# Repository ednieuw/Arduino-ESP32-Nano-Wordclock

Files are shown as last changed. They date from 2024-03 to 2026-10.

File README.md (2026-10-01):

# Arduino-ESP32-Nano-Word clock



Build your own word clock with WS2812 RGB or SK6812 RGBW LEDs, showing one or [four languages](https://github.com/ednieuw/FourLanguageClock), on an Arduino ESP32 Nano.<br>
The sketch also works on other ESP32 boards, with different pin numbering.<br>

[Compare other word clock software/hardware designs on the selector page.](https://github.com/ednieuw/WordclockSelector)<br>

The clock can be controlled with a:
- [BLE web page](https://github.com/ednieuw/HTML-BLEserial)
- [BLE terminal in a browser](https://arach.nl/BLESerial/BLE_UART_Terminal.html)
- [BLE serial terminal app](https://arach.nl/BLESerial/IOSappMain.html)
- Serial cable connected to your PC
- Rotary encoder
- IR-remote controller
- (Membrane) keypad
- MQTT, e.g. via Home Assistant
- [Time sender app (iOS) or web page (Windows/Android)](https://github.com/ednieuw/HTML-TimeSender) —> [open Time sender HTML](https://ednieuw.com/Woordklok/TimeSender/TimeSender.html)
<br>

## Architecture & related projects

Since V230, the word clock sketch has been combined with the [Fibonacci clock sketch](https://github.com/ednieuw/Fibonacci-Nano-ESP32-clock) to simplify maintenance. There is also a third option; NOCLOCK.

The three architectues are easy to split apart via `#define`'s in a few places, and the clock functions can be stripped out entirely with `#define NOCLOCK`. Functionality can be toggled on/off from the menu.

Coding for an [HC-12 timesender](https://github.com/ednieuw/ESP32-HC12) was also added — it sends NTP time over HC-12 to another MCU equiped with a HC-12 module to receive the transmission up to 1000 meters away. 

When no WiFi is available, time can instead be sent to the clock via a timesender iOS app or a timesender web page, using Bluetooth on your phone or tablet.

## Screens

<br>In several browsers the TAB can be split to see the menu and the Serial monitor response in one TAB. <br><br>

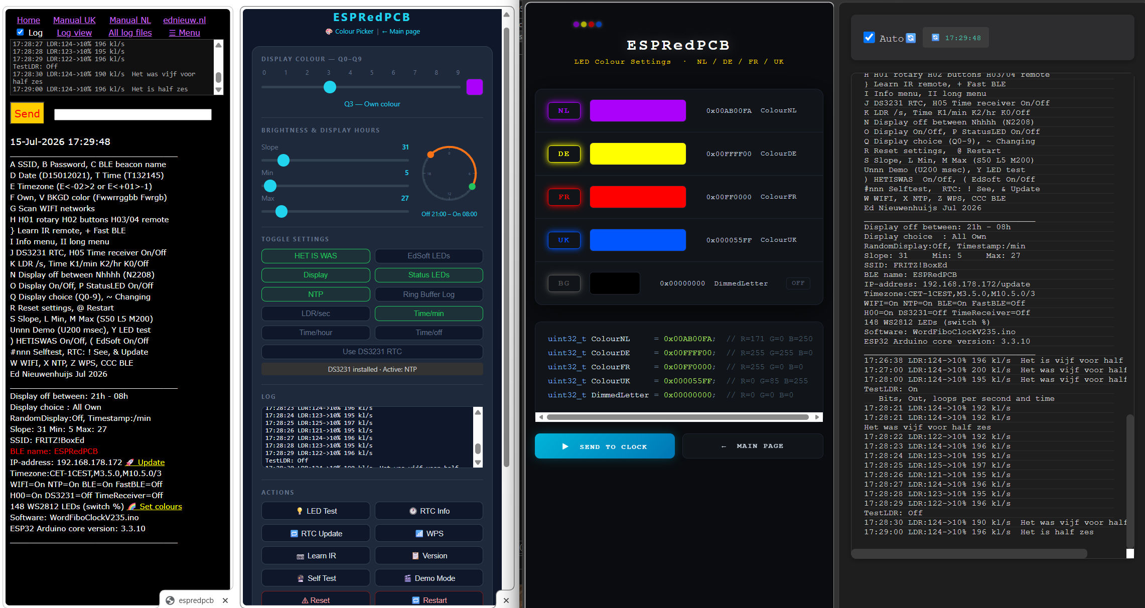
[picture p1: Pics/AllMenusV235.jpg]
<br>
All menus in a browser since version V235.

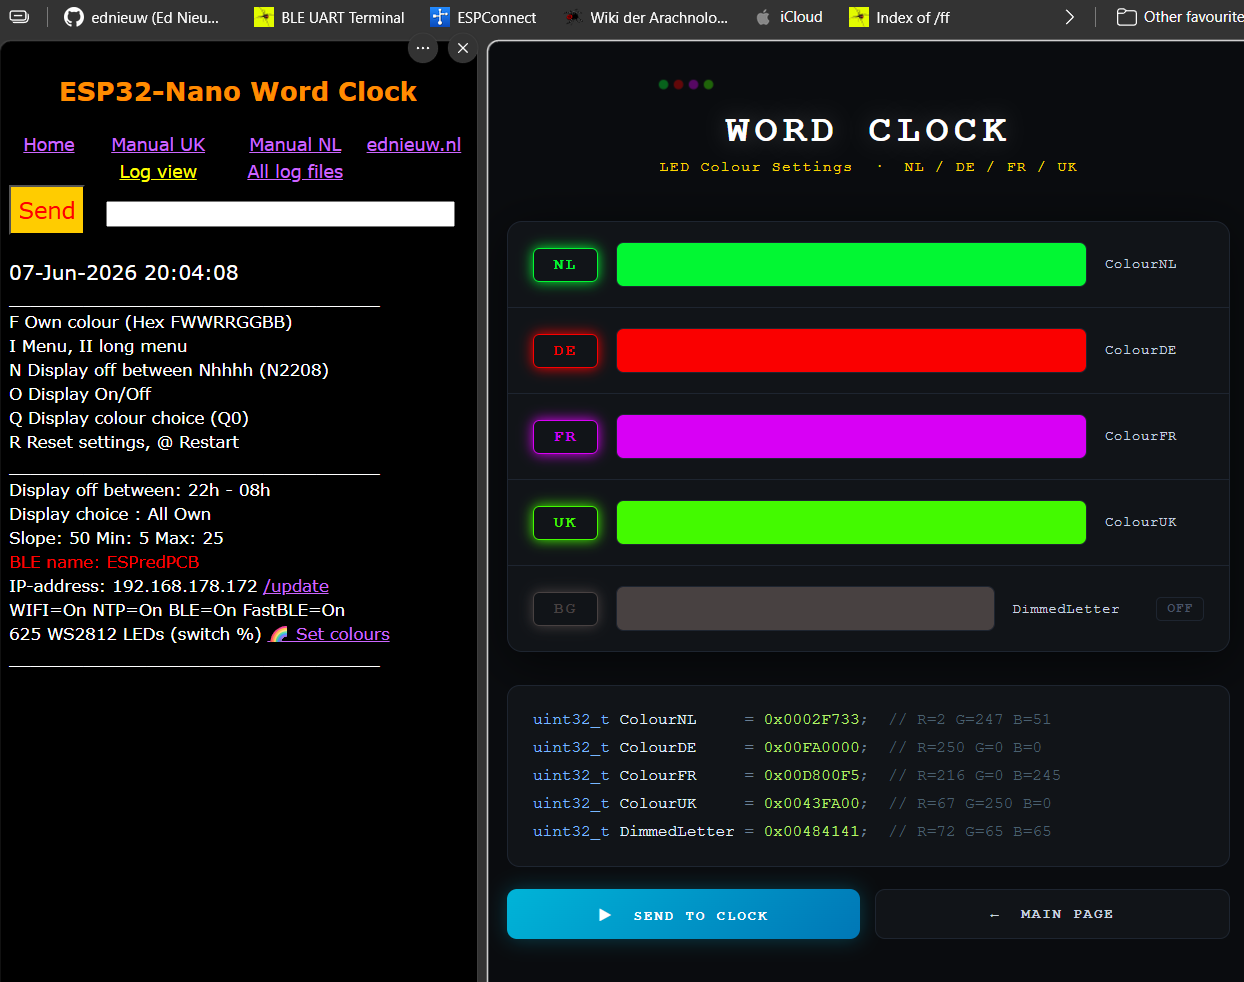
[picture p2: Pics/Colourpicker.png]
<br>

To connect the clock to WIFI the SSID and password of the router can be entered by the BLE serial terminal app or the WPS function can be used.<br>

Software updates can be uploaded with OTA (Over the Air).<br>

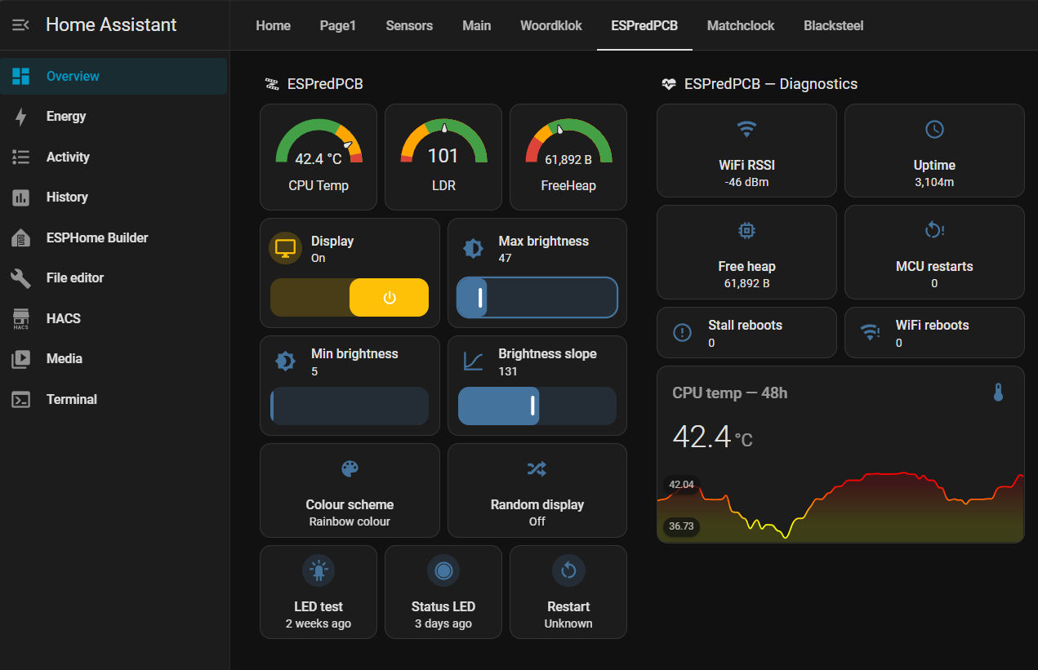
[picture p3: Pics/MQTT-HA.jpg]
<br>
With MQTT in Home Assistant.

| | |
|---|---|
| <br><strong>Full menu</strong> | The clock will keep its time correct within the second using the internet Network Time Protocol (NTP) with daylight-saving corrections when a timezone is entered.<br><br>If no internet is available a DS3231 RTC-module can be attached to the PCB to get an accurate time.<br>With a rotary, membrane pad, time sender app or almost any IR-remote controller time can be set.<br><br>An LDR (light-dependent resistor) is used to give the LEDs an optimal brightness.<br><br>The ESP32 has an Espressif BLE/WIFI module. Bluetooth LE does not use the TI CC2541 chip but a Nordic nRF52 chip.<br>That means you have to use a different BLE service for the serial communication — not characteristic FFE0 but 6e400001-b5a3-... etc. in your serial terminal app that communicates with the clock’s settings.<br><br>See here: <a href="https://github.com/ednieuw/nRF-ESP32">Use BLE on mobile to control the ESP32</a><br><br>An user manual in Dutch and English can be found in this repository: <a href="https://github.com/ednieuw/Arduino-ESP32-Nano-Wordclock/tree/main/Manual-Instructions">here</a> |<br><br><br><br>


Clock with Corten steel face

# Hardware
For my projects printed circuit boards (PCB) were designed with [Fritzing software](https://fritzing.org/).

This Fritzing program is easy to use and it can export Gerber files that can be send to companies that print PCB's. <br>
PCB's made in Europe can be ordered with the Fritzing app itself.<br>

[PCBWay](https://www.pcbway.com/) print 10 PCBs for $5. With +/-$25 shipping and custom charges this is very cheap. The PCBs were received within a week after ordering and the quality was excellent. Just upload the Gerber files in the ZIP-file and pay the charges.<br>  

The [PCB design .FZZ-file and Gerber files](PCB) can be found in the folder PCB in this repository or here:  [ESP32 PCB](https://github.com/ednieuw/NanoESP32PCB)

The PCB can connect a
- rotary encoder  
- three button membrane switch 
- DS3231 RTC module or other I2C device 
- DCF77-receiver module or other device that receives pulses and 
- LDR to measure light intensity to control the brightness of the LED-strip.
- IR-remote receiver
- reset button 

The SK6812 RGBW or WS2812 RGB LED-strip operates at 5V. But the data signal from the Nano ESP32 is 3.3V.<br> 

I tried to use optocouplers to amplify the data signal from 3.3V to 5V, but that failed. See here: 
https://ednieuw.com/ElecProj/OptoSK6812/OptocouplerSK6812.html<br>

For level switching the 74HCT125 level shifter IC is used. It has four ports. The design of the PCB can use the other three ports on the IC for other uses. <br>

A SK6812 RGBW strip, with 14 LEDs, also happily worked when the data line was connected directly to the 3.3V data line of the Nano ESP32 without using the 74HCT125 level shifter IC. I have not tested strips with more than 14 LEDs in the strip.<br>

The lesson of this story is that you can connect the SK6812 RGBW strip with a 470 ohm resistor in the data line and a 200 - 1000 uF capacitor over the 5V and GND directly to the strip without the use of a level shifter. <br>But success is not guaranteed.
 
Nano-ESP32-V04

An alternative universal PCB to drive RGB(W) LEDs and white 2835 LED strips using shift registers can be found here: [Nano  ESP32 RGBW BW PCB](https://github.com/ednieuw/NanoESP32-BW-RGBW-clock) <br>
This PCB, with one Arduino source code, will support the colour LED clocks and the white LED clocks to run with a Arduino Nano ESP32. 

V01SmallNanoESP32-3D
The design of a [minimum PCB for small spaces](/PCB-small) can also be found in the folder PCB-small in this repository.

Power for the LED-strip can be drawn from the VBUS-pin (5V USB) on the Nano if powered with a USB-C cable.  
VBUS provides 5V whenever powered via USB. 

It is possible to feed the LED-strip via this connection but keep in mind the power travels through the PCB and USB-C power supplies are able to supply over 20 A. This will probably melt the small copper lines on the PCB.

If powered via the VIN pin, VBUS is disabled. This means that while powering the board through the VIN pin, you can't get 5V power from the board. 

The PCB can use different power connection options.
A 5V, >1A power supply can be attached at the 5V power connection on the top left of the PCB.

If the red line shortcut (see picture below) is closed then the LED-strip is powered via the Power 6-21V (VIN) connection with 5V.<br> 
This will also power the Nano ESP32. You can connect the Vin on the ESP32 Nano with a 5V USB power supply although the minimum voltage is noted as 6V. The 1N5817 diode even lowers the voltage by 0.5V to 4.5V.

BUT KEEP IN MIND. This 5V connection is fed to the LED-strip directly. If a higher voltage power supply is connected the LEDs will be destroyed but Nano will turn on happily.<br>

If the Nano ESP32 is connected via the USB-C port then the yellow connection must be shortcut. The LEDs will be powered by this power source. This is fine with 20 LEDs but probably not for longer strips.

5VConnections

After connections are made the PCB and hardware looks like this:


NanoESP32-V04-3D



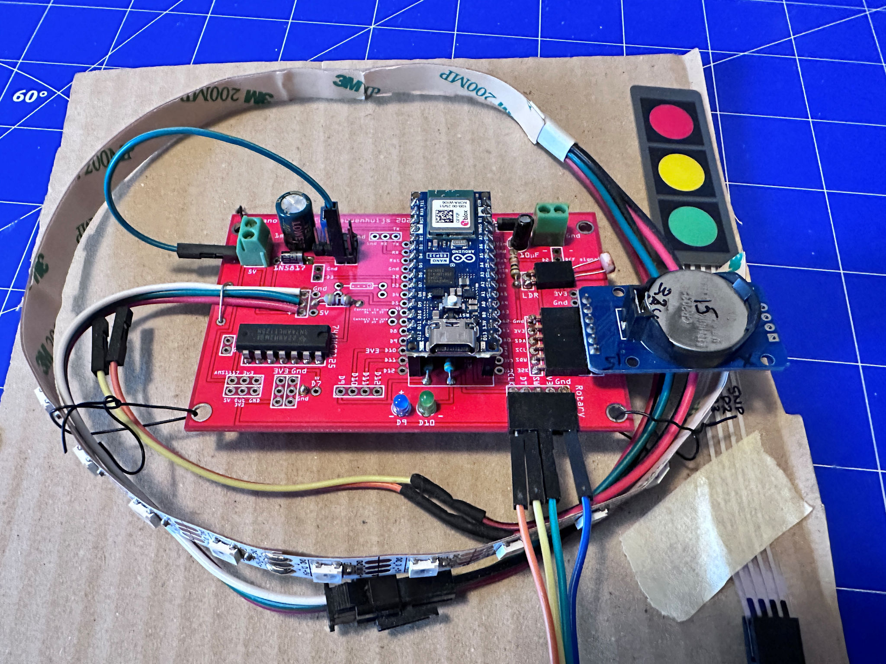
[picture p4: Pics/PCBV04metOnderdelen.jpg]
PCB V04
<br>
All parts on PCB V04 incliding Membrane keypad.

# PCB Connections

The large PCB has connections to: (from top right clock wise)
- 6-21V power input to Vin on Nano ESP32
- DCF to pin D2, 3V3 and GND
- LDR to pin A2 and 3V3
- RTC-clock to pin  GND, 3V3, A4 and A5
- Rotary encoder or 3-button switch to pin D8, D3, D4 3V3 and GND
- Reset button on D6 and GND (or D7)
- IR-remote D4 3V3 and GND
- LEDs to pin D10 and D9
- Connector to pin D12, D11, D10 and D9
- D7 with 5V via 3V3 -> 5V level switcher
- Connector with GND and 3V3
- Connector for AMS1117 5V -> 3V3 1A voltage regulator.
- D6 with 5V via 3V3 -> 5V level switcher
- Connector for LED-strip SK6812/WS2812 to 5V, D5 and GND
- D3 with 3V3 to D3 and GND
- 5V power input to 5V-USB or Vin on ESP32 and to LED-strip  
- 5V and GND connector and connector to Vin and 5V-USB on Arduino Nano ESP32
- Connector to GND, RX and TX 

The small PCB has connections to: (from top left clock wise)

- LDR to pin A2 and 3V3
- 5V power input to to 5V-USB on ESP32 and to LED-strip
- Connector for LED-strip SK6812/WS2812 to 5V, D5 and GND
- Rotary encoder or 3-button switch to pin D2, D3, D4 3V3 and GND
- Reset button on D6 and GND (or D7)
- IR-remote D4 3V3 and GND
- RTC-clock to pin  GND, 3V3, A4 and A5

 

# The LED ground plate



The distance between the LEDs on the strip is suitable for making a clock of 25 x 25 cm (60 LEDs/m) or 50 x 50 cm (30 LEDs/m).<br> 
You can choose to stick the 144 LEDs of the clock in 12 rows of 12 LEDs or only behind the letter that should light up.<br>
The advantage of the latter is that fewer LEDs are needed and that you have to drill fewer holes in the spacer plate.<br>
But there are many more soldering points, each of which can cause malfunctions.<br>  
My experience is that imperfect soldering on the strip may loosens over time, causing malfunctions. 

The software has a digital time display option you use 144 (12 x 12) LEDs.<br>

You can choose to cut out the words like IT, WAS, FIVE and so on in a 1 cm thick MDF board with a jigsaw.<br>
Be sure to paint the insides bright white, otherwise the white light will become dingy.<br> 
It is better to use foamed PVC white 10 MM RAL 9003. It cuts easily, is white and does not discolour. (Often white paint discolours)
 
Stick/glue the strips starting from left to right on the odd lines and from right to left on the even lines. <br>

### Follow the arrows on the strip.<br> 
(You have to turn the strip upside down every second row!)<br>
This avoids long data lines going from the right end of the strip to the left end on the next row of a LED strip.<br>
And the software does not have to be corrected for the new positions.



I find it useful to use tinned copper wire.<br> 
For example, you solder all 5V connections to the left side of the strip and all GND to the right side of the strip.
To do this, drill a small hole through the plate next to all 5V connections on the left side of the strip and to the GND on the right side

Bend a 90 degree angle, put the wire through the hole and solder the wire to the LED strip.





Place the spacer plate over the LEDs, then a sheet of white paper and finally the word plate.

# Software

The ESP32Arduino_WordClockVxxx.ino turns the Nano ESP32 and SK6812 or WS2812 LED strips into a Word clock with connection to a WIFI router and receives the time from a NTP server or a Timesender app.

An **user manual** in Dutch and English can be found in this repository [here](https://github.com/ednieuw/Arduino-ESP32-Nano-Wordclock/tree/main/Manual-Instructions)

The software can be controlled with Bluetooth on your PC, Android or iPhone/iPad/iMac using a BLE terminal app or with [this HTML BLE terminal web page](https://ednieuw.com/BLESerial/BLE_UART_Terminal.html).

Several designs can be selected before compiling.  (If you have a word clockface plate, of course.)<br>
Use a word clockface plate design [from this repository](WordPlateFrontCovers)  or use your own and adapt the position of the LEDs in the software.<br>

ClockDefines

Select one of the word clock designs
```
#define NL144CLOCK              // Dutch display for 12 x 12 Front
//#define FOURLANGUAGECLOCK       // Four-language clock with 625 LEDs 
//#define NL92CLOCK               // Dutch display for one LED behind every word
//#define UK144CLOCK              // English display for 12 x 12 Front.
//#define FR144CLOCK              // French display for 12 x 12 Front.
//#define DE144CLOCK              // German display for 12 x 12 Front.
...
```

- #define NL144CLOCK -> a 144 LED single language clock. Default language is Dutch. For French, German and English copy the coding from the four-language clock between the NL144CLOCK defines.<br>
 [Build instruction for the clock in Dutch and English](https://ednieuw.com/Woordklok/Bouwpakket/WoordklokSK6812.htm)
or [here in this repository](Manual-Instructions)

- #define NLM1M2M3M4L??? -> a ??? LED single language clock with 4 extra LEDs for the minutes and a slightly different design. Many lay-outs are defined.

- #define FOURLANGUAGECLOCK-> a 4-language clock with 625 LEDs in a 25 x 25 grid.<br>
[Build instruction of 4-language word clock with SK6812 LEDs in UK, NL, DE, FR with Nano Every.](https://github.com/ednieuw/FourLanguageClock). 

In the libraries.zip are the libraries to compile the software.<br>
Unpack them in your libraries folder.(libraries folder in the folder where your sketches are saved by default)<br>
Download the program folder and compile for Arduino Nano ESP32 using the Espressif core 3.<br>
Libraries update constantly, which may result in incompatibility with this source code over time. Therefore, these libraries are included.

An alternative is to compile the ArduinoOTA sketch that can be found in the Examples of the Arduino IDE.<br>
Upload the OTA-updater in the Nano ESP32 and note the IP-address that is printed in the Serial monitor of the Arduino IDE.
Type this IP-address URL in a browser and enter admin/admin as user and password.<br>
Then upload the .bin file made by the Arduino IDE with Sketch->Export compiled binary.<br>
<br>
Or use this one: [Uploads .bin files in the ESP32 by using wifimanager](https://github.com/ednieuw/OTA-webupdater).<br>
<br>
# How to compile: 
At the moment of writing (June 2026) the Espressif ESP32 board core V3.3.9 with the Arduino Nano ESP32 selected does compile to a working program when ESP32WordclockV220.ino of a higher version is used.
Select the Nano ESP32 board from Arduino in the Arduino IDE. 
The Arduino ESP32 board with core version 2.0.17/2.0.18, also compiles without errors when using the Adafuit Neopixel library.



There are two compiler pin numbering methods: One method uses the GPIO pin numbering of the ESP32-S3 and the other by Arduino pin numbering.<br>
This code works fine with GPIO pin numbering selected.<br>
The Neopixel library generates an error when this is not selected. 
The EdSoftLED library can use both pin numberings and only compiles with Espessif core 3.3.n because it used the RMT functionality to drive the LEDs.

Nano-ESP32 Pinout

Install Arduino Nano ESP32 board<br>
```
Board: Arduino Nano ESP32
Partition Scheme: With FAT
Pin Numbering: By GPIO number (legacy)  !! use this when using Neopixel 
```
<br>

SerialOutputs

# Before starting

The clock receives time from the internet when connected to a router.

When a DS3231 time module is attached to the circuit board an internet connection is not required. Select in the menu that the DS3231 is used instead of the NTP time. (J Toggle use DS3231 RTC module)
Be aware that DS3231 time is being used also when there is a internet connection. 

To connect to the internet the name of the WIFI station and its password must be entered in the clock software to be able to connect to a WIFI router or use the personal hotspot in you mobile.

### Connect to WIFI
The name of the WIFI-station and password has to be entered once. These credentials will be stored in memory of the microprocessor.

If the clock software is started without a SSID router name it will start a WIFI station you can connect to. 
- Open in your phone, tablet or PC the WIFI connections. In the list of WIFI stations there will be one named: StartWordClock. 
- Connect to it and enter the password: 12345678
- Enter the SSID and password of your WIFI router. You can find these credentials often at the bottom of your router.
- When Submit is pressed the clock will restart and connect to the internet.

### Connect via Bluetooth
To make life easy it is preferred to use a phone or tablet and a Bluetooth communication app to enter the WIFI credentials into the clock.<br>

With some browser you can also use [this web based BLE HTML from my site](https://ednieuw.com/BLESerial/BLE_UART_Terminal.html)

| | |
|:---:|:---:|
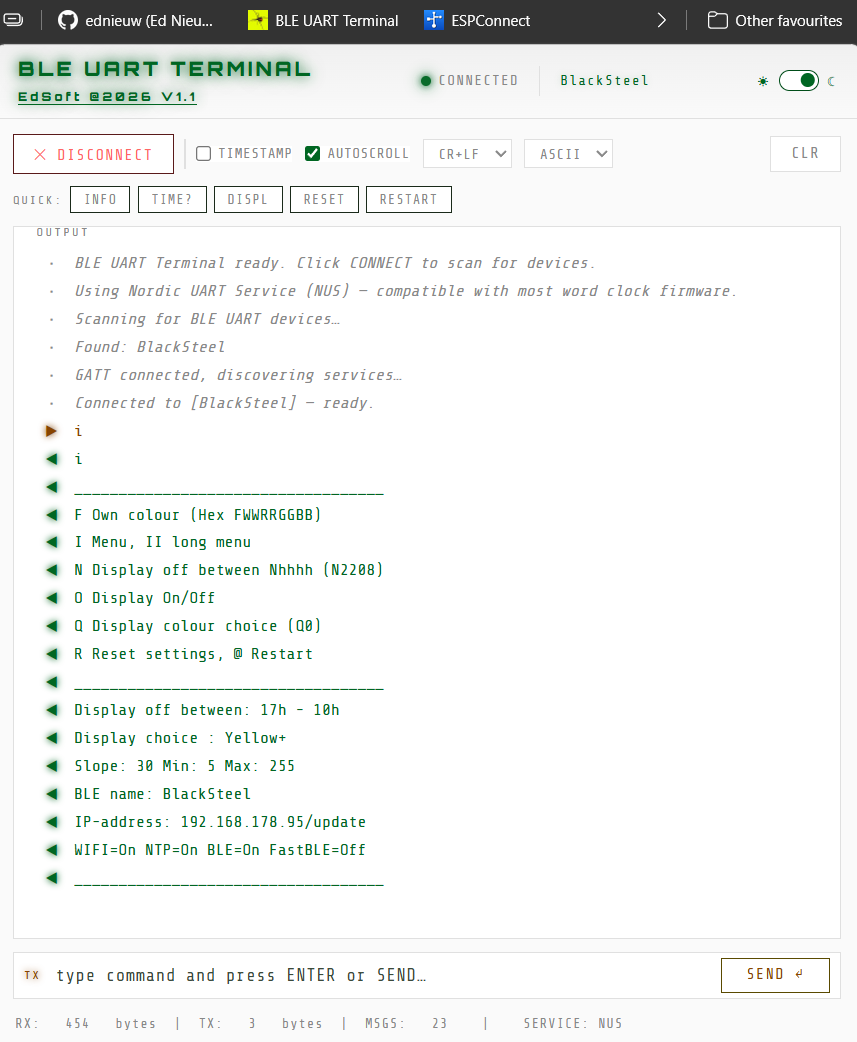
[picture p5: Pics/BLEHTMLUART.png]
BLE UART terminal
|  |  |
| [BLE UART HTML from my site](https://ednieuw.com/BLESerial/BLE_UART_Terminal.html) | Bluetooth UART serial terminal app | 

BLESerial nRF	BLE Serial Pro	Serial Bluetooth Terminal
- Download a Bluetooth UART serial terminal app on your phone, PC, or tablet.<br>

- For IOS iPhone or iPad (Buy this one to support me): [BLE Serial Pro](https://apps.apple.com/nl/app/ble-serial-pro/id1632245655?l=en). <br>
Or the free, less sophisticated app: [BLE serial nRF](https://apps.apple.com/nl/app/bleserial-nrf/id1632235163?l).<br>
Tip: Turn on Fast BLE with option + in the menu for a faster transmission.

- For Android use: [Serial Bluetooth terminal](https://play.google.com/store/apps/details?id=de.kai_morich.serial_bluetooth_terminal). <br>
Do not turn on Fast BLE in the menu. (Off = default)

Enter the SSID name and password of your router prefixed with A for the SSID and with an B for the password.
- aSSIDname and press Send
- bPassword and press send
Optionally
- cClockname and press send. 
Clockname is the name of the clock displayed in the WIFI-router in the list of bluetooth devices in the BLE serial terminal app

# Control of the clock
If the clock is connected to the internet it will seek contact with a time server. (NTP connection can be turned off in the menu).

The time zone is set to UTC+1 Amsterdam but can be changed in the menu. <br>
To connect to a WIFI network a SSID and password must be entered.

If equipped with a reset button, holding it for two seconds restores the clock to its factory settings. <br>
Bluetooth and WIFI will be turned on.
 
There are a few methods: <br>
1. Connect the MCU with a serial cable to a PC and use a serial terminal.

I use the Arduino IDE as serial terminal. 

Sending the character 'I' for information will display the menu followed with the actual settings of several preferences. 

<table style="width: 90%"><tr>
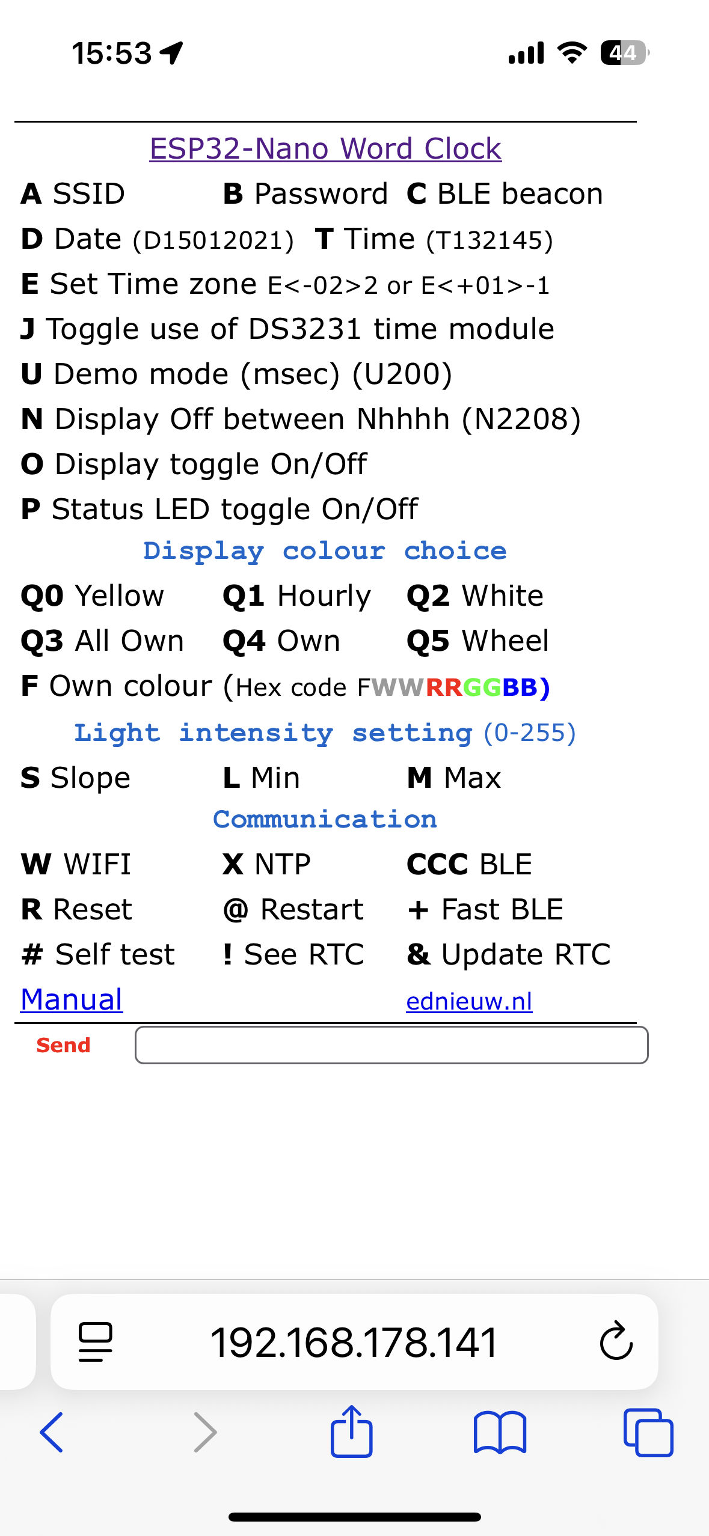
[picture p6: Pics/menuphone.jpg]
Menu on iPhone
<td style="width: 342px"></td>
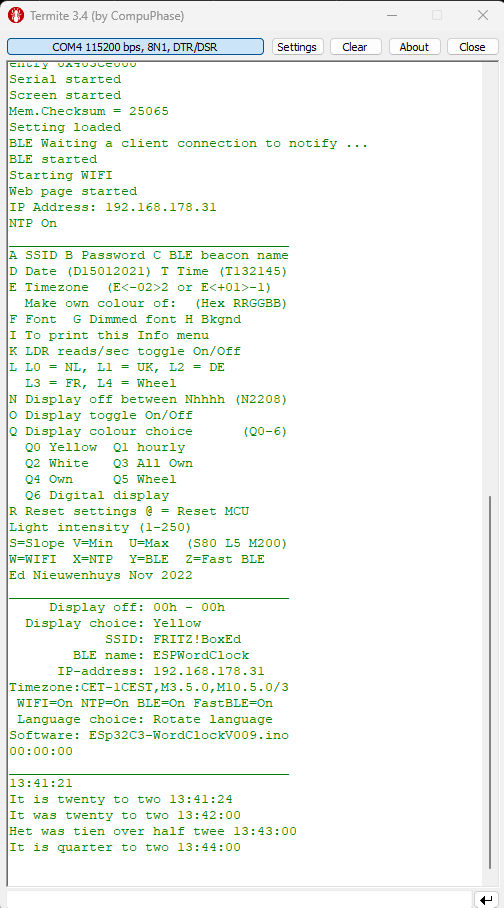
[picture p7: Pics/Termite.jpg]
Termite terminal
<td style="width: 415px"></td>
</tr>

<tr>
<td style="width: 342px">HTML page on iPhone.</td>
<td style="width: 415px">Termite terminal on a PC. </td>
</tr>
</table>
<br>

2. USE the BLE nRF connection with an UART serial terminal app to control it with your mobile phone or tablet. 

Use the IOS app for iPhone or iPad: <a href="https://apps.apple.com/nl/app/ble-serial-pro/id1632245655?l=en">BLE Serial Pro</a>. <br>
or the free app BLEserial nRF: https://apps.apple.com/nl/app/bleserial-nrf/id1632235163?l=en-GB
Turn on Fast BLE with option Z in the menu. 

For Android use:<a href="https://play.google.com/store/apps/details?id=de.kai_morich.serial_bluetooth_terminal">Serial Bluetooth terminal</a>. <br>
Turn off (default) Fast BLE in the menu. 

Start the app and find the MCU in the list of devices and connect to it. You can change it's beacon name in the menu with option C. 

In both cases send the character I of Information and the menu shows up.<br>
Enter the first character of the setting you want to change followed with a code. <br>
Some entries just toggle On and Off. Like the W to set WIFI Off or On. 
  
<p> To change the SSID and password: <br>
Amy-ssid and send this command. Eg AFRITZ!Box01 or aFRITZ!Box01. 
Starting with an upper or lower case character is an identical instruction in the command string <br>
Then Bmy-passwordand send the password.(for example: bSecret<br>
 
Cbroadcastname will change to name displayed in the Bluetooth connection list. <br>
If the length of the SSID and/or password is less then 5 characters the WIFI will be turned off automatically. This will speed up startup time if no internet connection is available <br>
Use a length of minimal 8 characters for the password and 3 characters for the SSID. <br>
Check in the menu (third row from the bottom) if WIFI and NTP are on. <br>
If WIFI is connected the LED on the MCU will pulse green. <br>
<br> Enter @ to reset the MCU. It will restart and connections will be made.<br>
<br>
To set a time zone, send the time zone string between the quotes prefixed with the character E or e. <br>
See the time zones at the bottom of this page. <br>
For example, if you live in Australia/Sydney send the string: eAEST-10AEDT,M10.1.0,M4.1.0/3 

<pre>
___________________________________
___________________________________
A SSID, B Password, C BLE beacon name
D Date (D15012021), T Time (T132145)
E Timezone (E<-02>2 or E<+01>-1)
F Own, V BKGD color (Fwwrrggbb Fwrgb)
G Scan WIFI networks
H H01 rotary H02 buttons H03/04 remote
} Learn IR remote, + Fast BLE
I Info menu, II long menu
J DS3231 RTC, H05 Time receiver On/Off
K LDR /s, Time K1/min K2/hr K0/Off
N Display off between Nhhhh (N2208)
O Display On/Off, P StatusLED On/Off
Q Display choice (Q0-9), ~ Changing
R Reset settings,  @ Restart
S Slope, L Min, M Max (S50 L5 M200)
Unnn Demo (U200 msec), Y LED test
) HETISWAS  On/Off, ( EdSoft On/Off
#nnn Selftest,  RTC: ! See, & Update
W WIFI, X NTP, Z WPS, CCC BLE
Ed Nieuwenhuijs Jun 2026
___________________________________
Display off between: 22h - 08h
Display choice  : All Own
RandomDisplay:Off, Timestamp: Off
Slope: 50     Min: 5     Max: 25 
SSID: FRITZ!BoxEd
BLE name: ESPredPCB
IP-address: 192.168.178.172/update
Timezone:CET-1CEST,M3.5.0,M10.5.0/3
WIFI=On NTP=On BLE=On FastBLE=On
H00=On DS3231=Off TimeReceiver=Off
625 WS2812 LEDs (switch %) 
Software: ESP32_WordClockV223.ino
ESP32 Arduino core version: 3.3.8
__________________________________
</pre>
#### Menu shown in serial output.

As mentioned before the clock can be controlled with the WIFI webpage or BLE UART terminal app. <br>
When the clock is connected to WIFI the IP-address is displayed in the menu<br>

Enter this IP-address numbers and dots (for example: 192.168.178.31) in the browser of your mobile or PC where you type 
your internet addresses (URL). 

If the name of your BLE beacon is wordclock (see in the wordclock menu -> BLE name: wordclock)

Enter 'wordclock.local' as URL in the browser. 
 if this does not work install host software:
  - For Linux, install Avahi (http://avahi.org/).
  - For Windows, install Bonjour (http://www.apple.com/support/bonjour/).
  - For Mac OSX and iOS support is built in through Bonjour already.

  - Point your browser to http://wordclock.local, you should see a response.

The menu, left in the picture below will appear. With these menus almost all functionality of the clock can be set, changed, and many more.

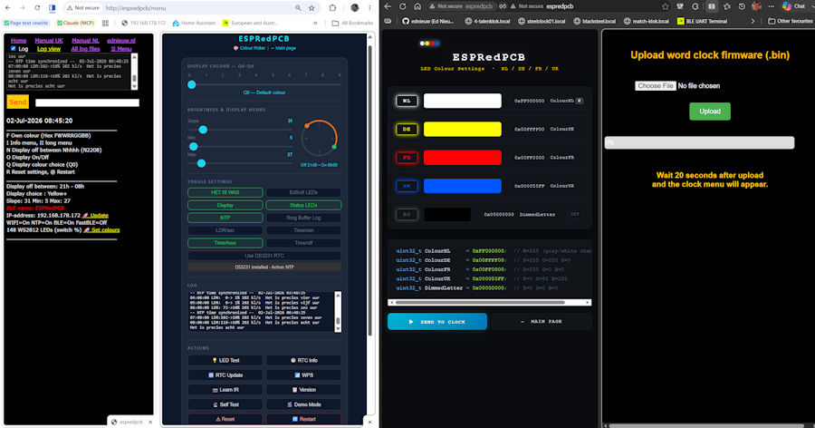
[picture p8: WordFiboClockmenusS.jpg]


Or open the BLE terminal app. (in some apps you have to press a CONNECT-button).<br>
Look for the WordClock to connect to and connect.

For Apple IOS devices BLE connection can be made with my app <a href="https://ednieuw.com/BLESerial/BLESerialPRO.html"> BLE Serial pro </a> in the <a href="https://apps.apple.com/nl/app/ble-serial-pro/id1632245655?l=en">app store</a> .<br>

For Android <a href="https://play.google.com/store/apps/details?id=com.nordicsemi.nrfUARTv2&amp;hl=en&amp;gl=US"> 
nRF UART terminal program </a>and <a href="https://play.google.com/store/apps/details?id=de.kai_morich.serial_bluetooth_terminal">
Serial Bluetooth terminal</a>. <br>
<br>
If you see a garbled menu and have FASTBLE turned on then send the character '+' to toggle the FASTBLE off the slower transmission mode. 
 
Settings are set by entering the first character of a command following by parameters if necessary.<br>
For example to set the colours of the characters in the display to white enter: Q2 <br>
<br>
 Set time by entering T130245. (130245 will also work) <br>
<br>
 Turn off WIFI by sending a W. 
<p >Reset the MCU with the character @.<br>
Reset to default setting by send R.<br><br>
 In the BLE connection the SSID and password will be shown.  <br>
	
<table cellspacing="6" style="width: auto">
<tr>
<td style="width: 280px">
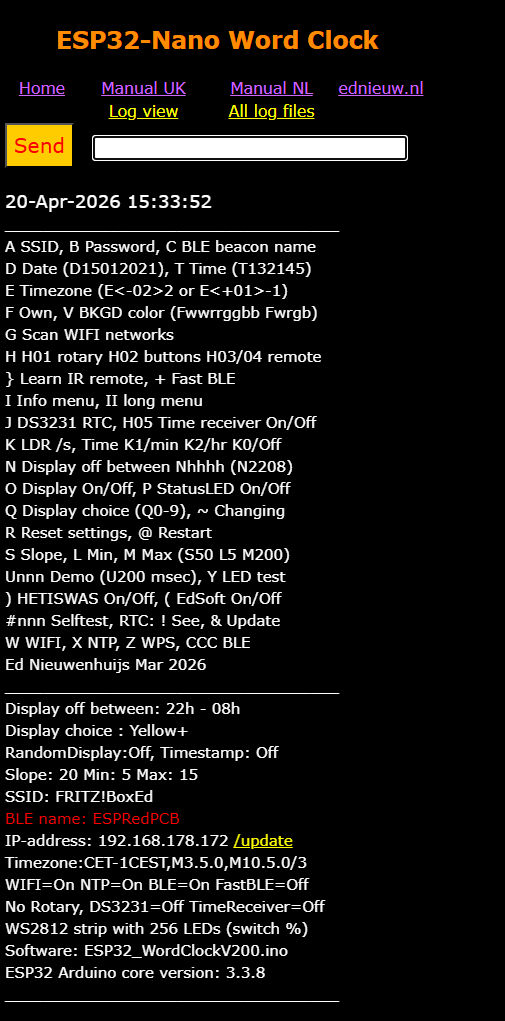
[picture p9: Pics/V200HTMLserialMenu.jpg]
Phone
</td>
<td>
WIFI-BLE</td>
</tr>
<tr>
<td style="width: 280px" >HTML page</td>
<td >BLEserial iPhone menu</td>
</tr>
</table>

## Detailed description

With the menu many preferences can be set. <br>
These preferences are permanently stored in the Arduino Nano ESP32 storage space. 

Enter the first character in the menu of the item to be changed followed with the parameter. <br>
For most entries upper and lower case are identical. 
With the HTML menu pages many of these entries can be selected with button, sliders or colour palettes.

### Update software<br>
Software can be updated with a .bin file. A bin files is made in the Arduino IDE from the menu Sketch -> Export compiled binary. In the folder where the sketch was saved several files are placed in the folder "build". The WordFiboBlockVxxx.ino.bin of approx. 1.5 Mb is the file to upload.  

### A SSID B Password C BLE beacon name<br>
Change the name of the SSID of the router to be connected to.<br>
aFRITZ!Box or AFRITZ!Box<br>
Then enter the password. For example: BSecret_pass <br>
and cMywordclock as a name of the BLE beacon that will be shown in your phone. (default after a reset:  wordclock )
Restart the MCU by sending @.

### CCC<br>
Entering CCC or ccc will toggle BLE on or off. Be careful turning it off. When BLE is off the clock can only be controlled with WIFI or the USB serial port.

### D Set Date and T Set Time <br>
If not connected to WIFI time and a RTC DS3231 is attached date must be set by hand.<br>
For example enter: D06112022 to set the date to 6 November 2022.  <br>
Enter for example T132145 (or 132145 , or t132145) to set time to 45 seconds and 21 minutes past one o'clock.

### E Set Timezone E&lt;-02&gt;2 or E&lt;+01&gt;-1<br>
At the bottom of this page you can find the time zones used in 2022. <br>
For Central Europe the string is: CET-1CEST,M3.5.0,M10.5.0/3  <br>
It is a rather complicated string and it is therefore wise to copy it. <br>
Let's pick one if you happen to live here: Antarctica/Troll,"&lt;+00&gt;0&lt;+02&gt;-2,M3.5.0/1,M10.5.0/3" <br>
Copy the string between the " " 's and send it starting with an 'E' or 'e' in front. <br>
E&lt;+00&gt;0&lt;+02&gt;-2,M3.5.0/1,M10.5.0/3 

Entering RRR will reset the timezone to Amsterdam CET. 
You will loose your credentials too with this reset! and have to reenter your SSID and password.

### Own colour (FWWRRGGBB or Fwrgb) <br>
With option Q3 and Q4 from the menu you can set your own colours for the clock to display.

Or press in the HTML menu page de link "🌈 Set colours".<br> Here the colour of the display can be selected with a colour palalette. When selected the display choice; "Q3 uses you own defined colours" automatically selected. 

The format to be entered is hexadecimal, 0123456789ABCDEF or decimal, 0123456789. <br>
The decimal range is made for users that are not familiar with hexadecimal arithmetic.<br>
The hexadecimal command is 2 characters for white followed with two characters for Red followed with two characters for Green and ending with two digits for Blue.<br>
The hexadecimal range is 00-FF, or 0-256 decimal and the decimal range is limited to 0-9.
To colour the characters intense red enter FF0000 prefixed with the character F. <br>
To set intense blue enter: F000000FF or FFF.<br>
To set the dimmed character to dark gray enter for example: F00191919. <br>
You get gray if red, green and blue have the same intensity.
With SK6812 LEDs the extra white LED can be used besides the three RGB LEDs in the same housing.
For example: F8800FF00 is 50% white with 100% green.

### G Scan WIFI networks
Scan available Wi‑Fi networks (prints SSIDs found).
This option does not work from the menu web page.

### H H01 rotary encoder, H02 buttons H03/04 remote, H05 Time sender app.
Turning on will also Turn off NTP and on use of DS3231. Check DS3231 and NTP setting when turning off (H00)
The options are:
H01 Rotary encoder<br>
H02 Keypad<br>
H03 Large IR-remote with nummeric UP DOWN LEFT RIGHT ON/OFF and POWER<br>
H04 Tiny IR-remote with six buttons<br>
H05 Turn On/Off the BLE time receiver. <br>
When enabled, the device listens for time sent by a BLE time sender app running on a nearby phone or PC and uses that to set its clock. <br>
Compatible senders:
- HTML BLE time sender (Chrome/Edge): [HTML-BLEserial](https://github.com/ednieuw/HTML-BLEserial)
- iOS BLE time sender app: [BLEtimeSender](https://ednieuw.com/BLESerial/BLEtimeSender.html)
The H05 option can be used when the clock has no WIFI. 

### } Learn IR remote
Start learning the keys of a new infrared remote.
  
### I short menu, II long menu
Print the menu. 
`i` prints the short info menu.
`ii` prints the extended menu (long help).

### J DS3231 RTC module On/Off
When DS3231 is enabled, NTP may be turned off. Use option `X` to toggle NTP if needed.<>r>
The flashing orange status LED on the board will turn off when the DS3231 time is used.

### K LDR reads/sec toggle On/Off<br>
Prints the LDR-readings and the calculated intensity output.
K1 Turn On and Off the display of time every minute.
K2 Turn On and Off the display of time every hour.
In the long menu the K1 or K2 status is shown. 
If time is printed every minute or hour the log buffer fills up very fast.
If time is not printed more revelant info remains in the logging.

### N Display off between Nhhhh (N2208)<br>
With N2208 the display will be turned off between 22:00 and 08:00. 

### O Display toggle On/Off<br>
Toggles the display off and on.

### P Display toggle On/Off<br>
Toggle status LEDs on the board On/Off.

###  Q Display choice (Q0-9)<br>
Q0 will show the time with yellow words., HETISWAS changing. <br>
HET will change from green to red via yellow in an hour and IS/WAS with change from green to red in a minute.<br>
Q1 will show every hour another colour. <br>
Q2 shows all the texts white. <br>
Q3 uses you own defined colours. 
Q4 uses you own defined colours with HETISWAS changing. <br>
Q5 will follow rainbow colours every hour. <br>
Q6 is the digital clock if you have used 12x12 = 144 LEDs in the clock. <br>
Q7= Hourly colour, HETISWAS changing.
Q8= Rainbow colour changing in a minute.
Send an 'I' to display the latest's settings in the menu. 

### R Reset settings <br>
R will set all preferences to default settings. The SSID and password, timezone, the LED-strip type and rotary/IR usage will be kept.<br>
RRR will clear SSID, password, set Time zone to Amsterdam (CET-1) and turn WIFI, NTP and BLE on.<br>
RRRRR is a total reset. A combination of R and RRR.<br> 
A total reset can also be achieved with a reset button connected to D6 or D7. If no rotary encoder is used, the rotary encoder pins D2, D3, and D4 can also serve this purpose.

### Unnn Demo (U200 msec)
Enter U followed with the duration of a second in milli seconds. 
M200 (200 millisecond) will speed up the clock 5*60 times.  
Sending an U will turn off the demo mode or if not in demo mode start demo mode with 800 ms/min.

### V Backgroung colour (VWWRRGGBB or Vwrgb) <br>

With this option you can set the colour and intensity of the LEDs that are normally not turned on.
This option is usefull when there is light leakage between the characters or to highlight the characters turned off.<br>
When this option is used the minimal light intensity is set to 50 bits to avoid that the background light with get off during the evening.<br>
50 bits is 20% of the max intensity. When you enter a background of say hexadecimal 10 (=16 decimal) the 20% of 16  = 3 bits and that is almost off.<br>
<br>
The format to be entered is hexadecimal, 0123456789ABCDEF or decimal, 0123456789. <br>
The decimal range is made for users that are not familiar with hexadecimal arithmetic.
The hexadecimal command is 2 characters for white followed with two characters for Red followed with two characters for Green and ending with two digits for Blue.<br>
The hexadecimal range is 00-FF, that is a decimal range of 0-255 and the decimal range is limited to 0-9.
To colour the characters weak red enter V00110000 or decimal V0100. <br>
To set weak blue enter: V00000011 or V0001 decimal.<br>
With the command V the background light is turned off and minimal light intensity to 10

### Y Play lights
To test the functionality of the LEDs.

### S Slope, L Min, M Max (S50 L5 M200)

<table style="width: 100%">
<tr>
<td> To control the light intensity three parameters can be set. <br>
The values ranges between 0 and 255. <br>
The minimal light intensity is to avoid that the display turns completely off when it is dark. <br>
It also prevents flickering when the input value is very low, like 2 and 3 bits. <br>
Values ranging between 5 and 20 are suggested. When no LDR is attached, the Min value can be set to 255.<br>
The maximum light intensity is 255 bits for 100% intensity.  <br>
The Slope (sensitivity) controls the speed at with the maximum value is reached. <br>
It multiplies the reading as a percentage. So, entering 100 is a multiplication by one. <br>
The placement and sensitivity of your LDR can be adjusted with this parameter Slope. </td>
<td> 
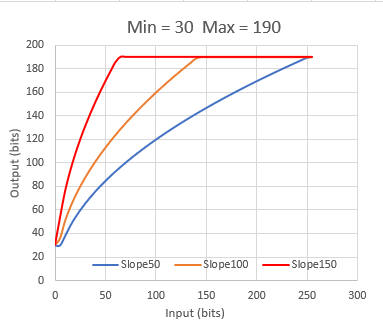
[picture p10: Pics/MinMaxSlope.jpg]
Min Max Slope
<br>
The effect of the value of the slope on the light intensity of the LEDs 
or display. </td>
</tr>
</table>

<table style="width: 100%">
<tr>
<td> 

<br>
### W=WIFI, X=NTP, Y=BLE<br>
Toggle WIFI, NTP and BLE on and off.<br>
Sending the character will toggle it on or off. <br>
At the bottom of the long menu (ii) the state is printed.<br>
 </td>
<td>
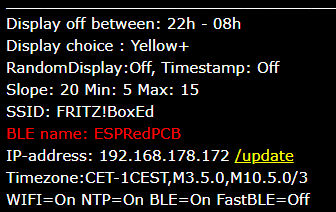
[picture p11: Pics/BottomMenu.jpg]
Bottom menu
</td>
</tr>
</table>

### + Fast BLE

The BLE UART protocol sends default packets of 20 bytes. Between every packet there is a delay of 50 msec.<br>
The IOS BLEserial app, and maybe others too, is able to receive packets of 80 bytes or more before characters are missed.<br>With most apps you will see these will truncate the long strings of the menu.<br>
Then turn off Fast BLE. <br>
Option Z toggles between the long and short packages. 

### ~ = change display mode per minute or hour
~ will start the changing display mode option. ~ or ~1 will change the dislay mode every minute and ~2 every hour. ~ or ~0 turns the option off. 
It is convenient for testing and demonstrations.

### ! = Show NTP, RTC and DS3231 time
!  will display the NTP, RTC and DS3231 time as they are stored in the clock  in the clock. The DS3231 time module must be installed and in use to show a realistic time.
Same as & option but this option will not update from the internet NTP server but only shows the time.

### #= Self test
Sending a # will start the clock self test. This is convenient to check if all the words in the display are functioning.<br> 
The time of a minute is reduced to 0.9 seconds (900 milli seconds).<br>
#nnnn were nnnn is the delay between minutes in milliseconds.

### % = Switch between SK6812 and WS2812 LED strip
With this option the used LED strip can be changed. The clock is equipped with on of these to types of LED strips. 
A Reset of all settings by sending a R in the menu will not change this LED strip selection.

### $ = Fire display
Shows a fire on the display in some clocks with a 12 x12 LED-matrix design installed

### ( = Turns additional optional LEDs On/Off
The clock can optionally be equipped with an extra logo text. 

### ) = Turns HET/IS/WAS On/Off
IT/IS/ WAS is always off

### @ = Restart MCU
@ will restart the MCU. This is handy when the SSID, et cetera are changed and the program must be restarted. Settings will not be deleted.

### & = Get and stores NTP time in RTC and DS3231 time
&  will get the NTP time immediately from the internet and stores it in the RTC clocks. This option is convenient to force the clock to get the proper NTP time. 
In other cases the program will check the time running in the clock and on the NTP server so now and then and update the RTC clocks.
The DS3231 time module must be installed and being used to show a realistic time.

### = = Display a permanent memory values in Mem
=  will print the values stored in the permanent memory of the Arduino.

### 123456 Set time in RTC module
Enter the time as 152300 hhmmss. Same as T152300
Changing date and time only works when a DS3231 RTC module is attached.

# Compilation and uploading

The settings of the Arduino Nano ESP32 board is as follows.<br>
Remember to install the ESP32 boards as explained above.<br>

Board settings
<p>

<p># Program explanation
 The program uses the following standard libraries.   
<br>
<pre>
//------------------------------------------------------------------------------              //
// ESP32 Includes defines and initialisations
//-------------------------------------------
                      #if ESP_ARDUINO_VERSION >= ESP_ARDUINO_VERSION_VAL (5, 2, 0)            // Use EdSoftLED with ESP32 compiler.
#define USEEDSOFTLED  // Use EdsoftLED >= V1.7.0 for SK6812. Saves 200-500 bytes compared with NeoPixel. NeoPixel is OK
                      #endif
                      #ifdef USEEDSOFTLED
#include <EdSoftLED.h>         // https://github.com/ednieuw/EdSoftLED for LED strip WS2812 or SK6812 
                      #else
#include <Adafruit_NeoPixel.h> // https://github.com/adafruit/Adafruit_NeoPixel  *** USE GPIO NUMBERING and compile By GPIO number (legacy) 
                      #endif
#include <Preferences.h>
#include <NimBLEDevice.h>      // For BLE communication. !!!Use NimBLE version 2.x.x  https://github.com/h2zero/NimBLE-Arduino
#include <WiFi.h>              // Used for web page 
#include <esp_sntp.h>          // for NTP
#include <esp_wps.h>           // For WPS
#include <ESPAsyncWebServer.h> // Used for webpage  https://github.com/ESP32Async 
#include <Update.h>            // For Over-the-Air (OTA)
#include <ESPmDNS.h>           // To show BLEname in router
#include <DNSServer.h>         // For the web page to enter SSID and password of the WIFI router 
#include <Wire.h>              //  
#include <RTClib.h>            // Used for connected DS3231 RTC // Reference https://adafruit.github.io/RTClib/html/class_r_t_c___d_s3231.html
#include <Encoder.h>           // For rotary encoder
#include <Keypad.h>            // For 3x1 membrane keypad instead of rotary encoder by Mark Stanley & Alexander Brevig 
#include <IRremote.hpp>        // IR remote control

</pre>

Webpage.h is included in the program as a TAB in the IDE. It contains the web page to display in the browser.<br>

I made the web page in the free 'Microsoft Expression Web 4'. It is not maintained anymore but has more than enough functionalities for our purposes.<br>
Notepad++ or an AI are also good alternatives<br>
<br>
To copy the code from the MS-Expression: <br>
At the bottom line of the window of MS-Expression click 'Split'.<br>
In the upper half the raw HTML Code is displayed and in the bottom half the 
Design window.<br>
Copy in the Code window all the HTML code <br>
Go to the Arduino IDE and paste it in the webpage.h TAB between: <br>
R"rawliteral(   ... and ...
 )rawliteral";<br>
<br>
  Or copy the the code from the webpage.h into 
MSexpression Code area and redesign the page as you like 

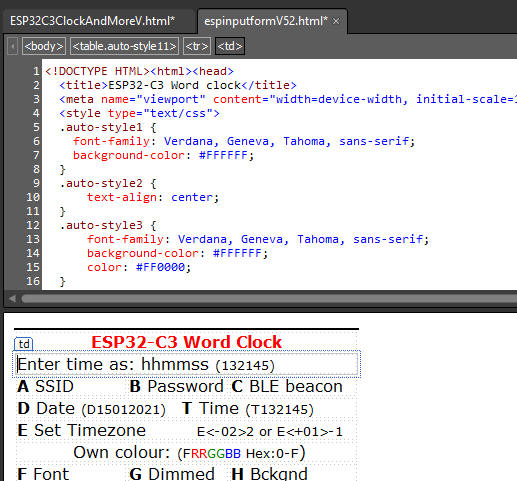
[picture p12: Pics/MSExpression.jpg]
MS expression
<br>

A long list if definitions and initialisations follows. <br>
I am not a fan of passing all the variables to and from functions and like to keep them global in one program list.<br>
If you write a program with other people, it is good practice not to use too many globals, but this program is in one large listing, for the same reason to keep it simple.<br>
I grouped all the variables per application to keep track where they are used.<br>
With a simple find it is easy in this one great listing to find the back.<br>
<br>
To print the time as text and colour with the proper LEDs or characters, the words and its position in a string of LEDs or text are defined. <br>
The defines executes the function ColorLeds with its proper parameters.<br>
Further in the program in the function void Dutch(void), void English(void) et cetera it becomes clear why these defines are so useful and handy.  
The definitions are placed in the TAB "ClockFaces.h"
<pre> ...   
#define PRECIES ColorLeds("precies", 16, 22, LetterColor);
#define MTIEN   ColorLeds("tien", 25, 28, LetterColor); 
#define KWART   ColorLeds("kwart", 32, 36, LetterColor); 
#define VOOR    ColorLeds("voor", 38, 41, LetterColor); 
... 
</pre>
This is the initialisation of the storage area to store the struct EEPROMstorage.<br>
The Struct with all its settings is saved in one command to permanent memory or SD <br>
Preferences FLASHSTOR; <br>
<br>
<pre> ...  
struct EEPROMstorage { // Data storage in EEPROM to maintain them after power loss 
byte DisplayChoice = 0; 
... <br>
char BLEbroadcastName[30]; // Name of the BLE beacon 
char Timezone[50];
int Checksum = 0;
} Mem;
... 
</pre>
<br>
The variables are addressed with a short name Mem.<br> 
For example Mem.DisplayChoice = 3; <br>
<br>
The Struct EEPROMstorage is stored with the function StoreStructInFlashMemory and retrieved with the function GetStructFromFlashMemory <br>
<br>

The menu displayed in the serial monitor and BLE app is defined here.<br>

```cpp
// Menu 
//0        1         2         3         4 
//1234567890123456789012345678901234567890  
const char *menu[] = { 
"A SSID B Password C BLE beacon name", 
"D Date (D15012021) T Time (T132145)", 
... 
"W=WIFI, X=NTP, Y=BLE, Z=Fast BLE",  
"Apr 2026" };
```
 The Setup happens here: 
```cpp
//-------------------------------------------- 
// ARDUINO Setup
//-------------------------------------------- 
void setup()  
{
Serial.begin(115200); Tekstprintln("Serial started"); // Setup the serial port to 115200 baud // 
...
... 
msTick = millis();  
}
```

The loop is kept almost empty and the program starts in Every SecondCheck.<br>
There is nothing in this program that should be executes every millisecond or less
 
```cpp
//-------------------------------------------- 
// ARDUINO Loop
//-------------------------------------------- 
void loop() 
{
 Loopcounter++;
 if (Demo)            Demomode();  
 else if(FireDisplay) FireMode(); 
 else                 EverySecondCheck();  
 CheckDevices();
}
```

The following routines check if something must happen every second, minute, hour and day.<br>
This flow handling of the program keeps the processor for 99% free for other uses.<br>
In this program that is almost nothing but for other purposes this can be needed.<br>
In the serial monitor the number of loops per second is printed. This can be handy to check if the program spends too much time elsewhere in the program. At the moment (V056) of writing it is around 200,000 l/s.
<br>

```cpp
//--------------------------------------------                //
// COMMON Check connected input devices
//--------------------------------------------
void CheckDevices(void)
{
 CheckBLE();
 SerialCheck();
 CheckWIFIcommand();
 if (Mem.TimeReceiver) CheckTimeReceiverClient();
 if (Mem.UseRotary==1) RotaryEncoderCheck();
 if (Mem.UseRotary==2) Keypad3x1Check();
 if (Mem.UseRotary==3 || Mem.UseRotary==4) IrReceiverDecode();
 if (ntpJustSynced) CheckandPrintNTPsynced();
                                  #ifdef ONEWIREKEYPAD3x4   
 OnewireKeypad3x4Check(); 
                                  #endif  //ONEWIREKEYPAD3x4
                                  #ifdef ONEWIREKEYPAD3x1   
 OnewireKeypad3x1Check(); 
                                  #endif  //ONEWIREKEYPAD3x1
}
//-------------------------------------------- 
// CLOCK Update routine done every second 
//-------------------------------------------- 
void EverySecondCheck(void) 
{
 static int Toggle = 0;
 uint32_t msLeap = millis() - msTick; 
 if (msLeap >999)                                              // Every second enter the loop
 {  
...  
if (timeinfo.tm_min != lastminute) EveryMinuteUpdate();        // Enter the every minute routine after one minute 
... 
}
//-------------------------------------------- 
// CLOCK Update routine done every minute 
//--------------------------------------------  
void EveryMinuteUpdate(void) 
{
... 
if(timeinfo.tm_hour != lasthour) EveryHourUpdate(); 
}
//-------------------------------------------- 
// CLOCK Update routine done every hour 
//-------------------------------------------- 
void EveryHourUpdate(void) 
{
... 
if (timeinfo.tm_mday != lastday) EveryDayUpdate();  
}

//-------------------------------------------- 
// CLOCK Update routine done every day 
//-------------------------------------------- 
void EveryDayUpdate(void) 
{
... 
}
```
<br>

```cpp
//--------------------------------------------                                                //
// COMMON Update routine for the status LEDs
//-------------------------------------------- 
void UpdateStatusLEDs(int Toggle)
{
 if(Mem.StatusLEDOn)   
   {
    SetStatusLED((Toggle && WiFi.localIP()[0]==0) * 20, 
                 (Toggle && WiFi.localIP()[0]!=0) * 20 , 
                 (Toggle &&      deviceConnected) * 20);
    SetPCBLED09( Toggle * 10);                                                                // Left LED
    SetPCBLED10((!Toggle) * 10);                                                             // Right LED
    SetNanoLED13((!Toggle) * (!Mem.UseDS3231 * 50));                                         // LED on ESP32 board. IF DS3231 in use then it is off
   }
   else
   {
    SetStatusLED(0, 0, 0); 
    SetPCBLED09(0);                                                                           //
    SetPCBLED10(0);                                                                           //
    SetNanoLED13(0);      
   }
}
```
Update the LEDs on the Nano ESP32 and the PCB. 
On the Nano analogWrite(LED_RED,   512); is OFF and analogWrite(LED_RED, 0); is ON<br>
When compiling with Espressif ESP32 core 3.x.x the resolution of the of the RMT channel is raised from 8 -> 10 bits. <br>
This prevents that the LED does not turn off completely when compiling with core 3. ( 8191 = 10^2)

```cpp
analogWrite(LED_RED,   Red   == 0 ? 8191 : (512 - Red)); 
```

```cpp
//--------------------------------------------
// COMMON Control the RGB LEDs on the Nano ESP32
//--------------------------------------------
void SetStatusLED(int Red, int Green, int Blue) 
{
 analogWrite(LED_RED,   Red   == 0 ? 8191 : (512 - Red));
 analogWrite(LED_GREEN, Green == 0 ? 8191 : (512 - Green));
 analogWrite(LED_BLUE,  Blue  == 0 ? 8191 : (512 - Blue));
}
```

```cpp
//--------------------------------------------
// COMMON Control orange LED D13 on the Arduino 
//--------------------------------------------
void SetNanoLED13(int intensity) {analogWrite(secondsPin, intensity);}
```

```cpp
//--------------------------------------------
// COMMON Control the RGB LED on the PCB
//--------------------------------------------
void SetPCBLED09(int intensity) {analogWrite(PCB_LED_D09, intensity);}
void SetPCBLED10(int intensity) {analogWrite(PCB_LED_D10, intensity);}

```
Control the color and intensity of the LED on the boards in one command <br>
```cpp
//
--------------------------------------------
// CLOCK Control the LEDs on the ESP32 
// 0 Low is LED off. Therefore the value is inversed with the ! Not 
//-------------------------------------------- 
void SetStatusLED(bool Red, bool Green, bool Blue) 
{
```

Check for serial input from the serial monitor and pass the command to ReworkInputString()&nbsp;  
```cpp
//-------------------------------------------- 
// Common check for serial input 
//-------------------------------------------- 
void SerialCheck(void) 
{
... 
ReworkInputString(SerialString); // Processes the inputstring in the menu 
... 
}
```

Restore all the default values. 
```cpp
//-------------------------------------
// Common Reset to default settings 
//--------------------------------------
void Reset(void)
{
 Mem.Checksum         = 25065;
 Mem.DisplayChoice    = DEFAULTCOLOUR; 
 Mem.OwnColour        = green; 
 Mem.DimmedLetter     = black;
 Mem.BackGround       = black; 
...
 StoreStructInFlashMemory();   
 GetTijd(false); 
 SWversion();
 Displaytime();Tekstprintln("");
}

 }
 ```

Common print routines.<br>

To keep all the print commands in one places it is easy to change these routines for other boards with a different 'slang'. <br>
```cpp
//-------------------------------------------- 
// Common common print routines 
//-------------------------------------------- 
void Tekstprint(char const *tekst)    { if(Serial) Serial.print(tekst); SendMessageTimeReceiver(tekst); SendMessageBLE(tekst); AddLog(tekst);}  
void Tekstprintln(char const *tekst)  { snprintf(sptext, sizeof(sptext),"%s\n",tekst); Tekstprint(sptext); }
void Tekstprintf(const char* fmt, ...) 
{ va_list args; va_start(args, fmt); vsnprintf(sptext, sizeof(sptext), fmt, args); va_end(args); Tekstprint(sptext);}

void Tekstprintlnf(const char* fmt, ...) 
{ va_list args; va_start(args, fmt); vsnprintf(sptext, sizeof(sptext), fmt, args); va_end(args);  Tekstprintln(sptext);}

```

The setup of storage space and control of the validity of the settings.<br>
In the checksum is invalid a reset() will restore the default settings 

```cpp
//-------------------------------------------- 
// Common Init and check contents of EEPROM 
//-------------------------------------------- 
void InitStorage(void) 
```

Store and retrieve the settings from SPIFFS or SD or EEPROM.
The several possibilities are stored here. EEPROM becomes outdated but still works. 

```cpp
-------------------------------------------- 
// COMMON Store mem.struct in FlashStorage or SD 
//-------------------------------------------- 
void StoreStructInFlashMemory(void) 
{
}
//-------------------------------------------- 
// COMMON Get data from FlashStorage Preferences.h 
//-------------------------------------------- 
void GetStructFromFlashMemory(void) 
{
}
```

SWversion() prints the menu and the settings of several preferences.<br>

PrintLine() prints the horizontal lines in the menu.<br>

```cpp
//-------------------------------------------- 
// COMMON Version info
//-------------------------------------------- 
void SWversion(void)  
{  
#define FILENAAM (strrchr(__FILE__, '\\') ? strrchr(__FILE__, '\\') + 1 : __FILE__) 
PrintLine(35); 
for (uint8_t i = 0; i &lt; sizeof(menu) / sizeof(menu[0]); Tekstprintln(menu[i++])); 
... 
PrintLine(35); 
}

void PrintLine(byte Lengte) 
{... } 
```

Get the commands from the strings entered in the serial monitor, Bluetooth or the webpage and perform the command in an action.<br>
The menu letters are almost used but it possible to distinguish between lower and uppercase when more commands are needed.<br>
(That is why there is no conversion to UpperCase or LowerCase). 

```cpp
/-------------------------------------------- 
//  COMMON Input from Bluetooth or Serial
//--------------------------------------------
void ReworkInputString(String InputString) 
{
....  
  int len = InputString.length();
  switch(toupper(InputString[0])) 
   {
    case 'A':
      if(len > 4 && len < 30)
.... 
```

Read the LDR and divide it with 16 to get the values from 0 - 4096 between 0 and 255.<br>
Not all boards has a 12 bit AD converter like.  

```cpp
//-------------------------------------------- 
// LDR reading are between 0 and 255.  
// ESP32 analogue read is between 0 - 4096 --   is: 4096 / 8 
//-------------------------------------------- 
int ReadLDR(void) {  return analogRead(PhotoCellPin)/16;} 
```

Here we print and colour the characters in the display or light up to proper LEDs in a String of RGB(W) LEDs.<br>
The #define executes this functions with the proper parameters for every language and prints the texts in the serial connections.<br>
#define QUARTER ColorLeds("quarter", 32, 38, LetterColor);

```cpp
//--------------------------------------------    / 
 / LED Set color for LED. 
//--------------------------------------------   
void ColorLeds(char const *Texkst, int FirstLed, int LastLed, uint32_t RGBColor)  
{  } 
```

Every display or strip uses other commands to regulate the brightness. Therefore for all LED/Display commands a function.
```cpp
//----------------------------------------------
// LED Set brightness of backlight 
//------------------------------------------------
void SetBrightnessLeds(byte Bright) 
{ 
 SetBackLight(Bright);                        // Set brightness of LEDs 
} 
```

A place to turn off all LEDs or clear the display<br>
```cpp
/-------------------------------------------- 
// LED Clear the character string 
//-------------------------------------------- 
void LedsOff(void)  
```

Here the colours are set for the characters.<br>
It is also used to change the colours of HET IS WAS used in some display choices

```cpp
//--------------------------------------------  <br>
// LED Set second color <br>
//-------------------------------------------- <br>
void SetSecondColour(void) <br>
{ 
...
 MINColor = FuncCRGBW(15 + timeinfo.tm_min * 4, 255 - timeinfo.tm_min * 4, 0, 0); 
 SECColor = FuncCRGBW(15 + timeinfo.tm_sec * 4, 255 - timeinfo.tm_sec * 4, 0, 0 );   
                                                                                              // Light up  IS or WAS with the proper colour  
switch (Mem.DisplayChoice) 
  {
    case DEFAULTCOLOUR: LetterColor = C_YELLOW;  
<br>
... 
```

Subroutine for the Self test of the clock. Default there is a 900 ms delay.
```cpp
//------------------------------------
// CLOCK Self test sequence
//--------------------------------------
void Selftest(void){Selftest(900);}
void Selftest(int Delayms)
{ 
 GetTijd(true);                                                                                  // Prints time in Serial monitor
 LedsOff(); 
...
}
```

Displaytime() prints the time to the serial monitor as text and control which language is printed.<br>
It also sends the appropriate sequence of colour and intensities to a RGB(W) LED strip. 
```cpp
//--------------------------------------------  
// CLOCK Say the time and load the LEDs 
// with the proper colour and intensity
//--------------------------------------------
void Displaytime(void) 
{  
LedsOff();   
 if( Mem.DisplayChoice == DIGITAL ) { TimePlaceDigit(timeinfo.tm_hour,timeinfo.tm_min); }
 else
   {
                     #ifdef NL144CLOCK
    Dutch();  
                     #endif  //NL144CLOCK
...
                     #ifdef FOURLANGUAGECLOCK
    SetColours();                                                                            // Set the colours for the chosen palette   
    Dutch();
    English();
    German();
    French();
                     #endif  //FOURLANGUAGECLOCK       
   }  
 ShowLeds();                                                                                  // And turn on the LEDs
}
```

DimLeds() reads the analog port and calculates an output intensity to a display or LED-strip.<br>
The readings are squared to get a hyperbolic curve that resembles you eye correction for dark and light better than a linear range.<br>
It works wonderfully well.<br>

```cpp
//--------------------------------------------  
// LED Dim the LEDs measured by the LDR and print values  
// LDR reading are between 0 and 255. The Brightness send to the LEDs is between 0 and 255  
//--------------------------------------------  
void DimLeds(bool print) { ... } 
```

A list of subroutine follows used for several LED operations follows including the initialisations of the WS2812 or SK6812 LED-strip
The SK6812 LED-strip also has a white LED whicht intensity is controlled with the highest bytes (WW) in the 32-bit integer (0XWWRRGGBB)

```cpp
//--------------------------------------------                                                //
//  LED Start LEDs
//--------------------------------------------
void StartLeds(void) 
{
 switch (Mem.LEDstrip)
    {
      case 0: LEDstrip = LED6812strip; 
              white  = 0xFF000000; 
              lgray  = 0x66000000;  
              gray   = 0x33000000; 
              dgray  = 0x22000000;
              wgray  = 0xAA000000; 

      break;
      case 1: LEDstrip = LED2812strip; 
              white  = 0xFFFFFF;
              lgray  = 0x666666; // R, G and B on together gives white light
...
}

```

A series of functions to get and store time.<br>
The NTP time server puts the retrieved time in the standard C time structures.<br>

```cpp
/--------------------------- Time functions -------------------------- 

void GetTijd(byte printit) 
void Print_RTC_tijd(void) 
void PrintNTP_tijd(void) 
void PrintUTCtijd(void) 
void Print_tijd(void) 
void SetRTCTime(void) 

```

Convert a HEX string to a unsigned 32-bits integer<br>

```cpp
//--------------------------------------------
// CLOCK Convert Hex to uint32 
//-------------------------------------------- 
uint32_t HexToDec(String hexString) 
```

<h2>Functions to let the clocks speak the time in four languages</h2>
There is also a lot of slang in languages. <br>
'Half nine' sometimes means 8:30 but can also be 9:30. (-:<br>
<br>

These definitions are in clockfaces.h 
```cpp
//--------------------------------------------
//  CLOCK Dutch clock display
//--------------------------------------------
                      #if defined(NL) || defined(NL144CLOCK)  
void Dutch(void)
{
HET;                                                                                          // HET  is always on
 if (timeinfo.tm_hour == 12 && timeinfo.tm_min == 0 && random(2)==0) { IS; NOEN; return; }
 if (timeinfo.tm_hour == 00 && timeinfo.tm_min == 0 && random(2)==0) { IS; MIDDER; NACHT; return; } 
switch (timeinfo.tm_min)
 {
  case  0: IS;  PRECIES; break;
  case  1: IS;  break;
  case  2: 
  case  3: WAS; break;
  case  4: 
  case  5: 
  case  6: IS;  MVIJF; OVER; break;
  case  7: 
  case  8: WAS; MVIJF; OVER; break;
  case  9: 
  case 10: 
  case 11: IS;  MTIEN; OVER; break;
  case 12: 
  case 13: WAS; MTIEN; OVER; break;
  case 14: 
  case 15: 
...

```

<br>

The Bluetooth Low Energy Nordic nRF.. functions.<br>
They are different from the Texas instrument CC2540/CC2541 that is used in other 
chipsets like the HM-10, HM16, JDY-08 et cetera.<br>
<a href="https://www.instructables.com/Communicate-Using-CC254x-or-NRF-BLE-With-Arduino-a/">More here on Instructables</a><br>
<br>

```cpp
/----------------------------- 
// BLE SendMessage by BLE Slow in packets of 20 chars 
//------------------------------ 
void SendMessageBLE(std::string Message) 

/----------------------------- 
// BLE Start BLE Classes 
//------------------------------ 
class MyServerCallbacks: public BLEServerCallbacks  

/----------------------------- 
// BLE Start BLE Service 
//------------------------------ 
void StartBLEService(void) 

/----------------------------- 
// BLE CheckBLE 
//------------------------------ 
void CheckBLE(void) 
```

<br>
Functions to start a WIFI connection and use the webpage<br>
<br>

```cpp
/-------------------------------------------- 
// WIFI WEBPAGE  
//-------------------------------------------- 
void StartWIFI_NTP(void) 

/-------------------------------------------- 
// WIFI WEBPAGE  
//-------------------------------------------- 
void WebPage(void)  

/-------------------------------------------- 
// WIFI WEBPAGE Not found message 
//-------------------------------------------- 
void notFound(AsyncWebServerRequest *request) 
```
<br>

#Time zones
 
<br>
 Copy the text between the quotes and paste them after the character E 

<pre> 
 Africa/Abidjan,"GMT0" 
 Africa/Accra,"GMT0" 
 Africa/Addis_Ababa,"EAT-3" 
 Africa/Algiers,"CET-1" 
 Africa/Asmara,"EAT-3" 
 Africa/Bamako,"GMT0" 
 Africa/Bangui,"WAT-1" 
 Africa/Banjul,"GMT0" 
 Africa/Bissau,"GMT0" 
 Africa/Blantyre,"CAT-2" 
 Africa/Brazzaville,"WAT-1" 
 Africa/Bujumbura,"CAT-2" 
 Africa/Cairo,"EET-2" 
 Africa/Casablanca,"&lt;+01&gt;-1" 
 Africa/Ceuta,"CET-1CEST,M3.5.0,M10.5.0/3" 
 Africa/Conakry,"GMT0" 
 Africa/Dakar,"GMT0" 
 Africa/Dar_es_Salaam,"EAT-3" 
 Africa/Djibouti,"EAT-3" 
 Africa/Douala,"WAT-1" 
 Africa/El_Aaiun,"&lt;+01&gt;-1" 
 Africa/Freetown,"GMT0" 
 Africa/Gaborone,"CAT-2" 
 Africa/Harare,"CAT-2" 
 Africa/Johannesburg,"SAST-2" 
 Africa/Juba,"CAT-2" 
 Africa/Kampala,"EAT-3" 
 Africa/Khartoum,"CAT-2" 
 Africa/Kigali,"CAT-2" 
 Africa/Kinshasa,"WAT-1" 
 Africa/Lagos,"WAT-1" 
 Africa/Libreville,"WAT-1" 
 Africa/Lome,"GMT0" 
 Africa/Luanda,"WAT-1" 
 Africa/Lubumbashi,"CAT-2" 
 Africa/Lusaka,"CAT-2" 
 Africa/Malabo,"WAT-1" 
 Africa/Maputo,"CAT-2" 
 Africa/Maseru,"SAST-2" 
 Africa/Mbabane,"SAST-2" 
 Africa/Mogadishu,"EAT-3" 
 Africa/Monrovia,"GMT0" 
 Africa/Nairobi,"EAT-3" 
 Africa/Ndjamena,"WAT-1" 
 Africa/Niamey,"WAT-1" 
 Africa/Nouakchott,"GMT0" 
 Africa/Ouagadougou,"GMT0" 
 Africa/Porto-Novo,"WAT-1" 
 Africa/Sao_Tome,"GMT0" 
 Africa/Tripoli,"EET-2" 
 Africa/Tunis,"CET-1" 
 Africa/Windhoek,"CAT-2" 
 America/Adak,"HST10HDT,M3.2.0,M11.1.0" 
 America/Anchorage,"AKST9AKDT,M3.2.0,M11.1.0" 
 America/Anguilla,"AST4" 
 America/Antigua,"AST4" 
 America/Araguaina,"&lt;-03&gt;3" 
 America/Argentina/Buenos_Aires,"&lt;-03&gt;3" 
 America/Argentina/Catamarca,"&lt;-03&gt;3" 
 America/Argentina/Cordoba,"&lt;-03&gt;3" 
 America/Argentina/Jujuy,"&lt;-03&gt;3" 
 America/Argentina/La_Rioja,"&lt;-03&gt;3" 
 America/Argentina/Mendoza,"&lt;-03&gt;3" 
 America/Argentina/Rio_Gallegos,"&lt;-03&gt;3" 
 America/Argentina/Salta,"&lt;-03&gt;3" 
 America/Argentina/San_Juan,"&lt;-03&gt;3" 
 America/Argentina/San_Luis,"&lt;-03&gt;3" 
 America/Argentina/Tucuman,"&lt;-03&gt;3" 
 America/Argentina/Ushuaia,"&lt;-03&gt;3" 
 America/Aruba,"AST4" 
 America/Asuncion,"&lt;-04&gt;4&lt;-03&gt;,M10.1.0/0,M3.4.0/0" 
 America/Atikokan,"EST5" 
 America/Bahia,"&lt;-03&gt;3" 
 America/Bahia_Banderas,"CST6CDT,M4.1.0,M10.5.0" 
 America/Barbados,"AST4" 
 America/Belem,"&lt;-03&gt;3" 
 America/Belize,"CST6" 
 America/Blanc-Sablon,"AST4" 
 America/Boa_Vista,"&lt;-04&gt;4" 
 America/Bogota,"&lt;-05&gt;5" 
 America/Boise,"MST7MDT,M3.2.0,M11.1.0" 
 America/Cambridge_Bay,"MST7MDT,M3.2.0,M11.1.0" 
 America/Campo_Grande,"&lt;-04&gt;4" 
 America/Cancun,"EST5" 
 America/Caracas,"&lt;-04&gt;4" 
 America/Cayenne,"&lt;-03&gt;3" 
 America/Cayman,"EST5" 
 America/Chicago,"CST6CDT,M3.2.0,M11.1.0" 
 America/Chihuahua,"MST7MDT,M4.1.0,M10.5.0" 
 America/Costa_Rica,"CST6" 
 America/Creston,"MST7" 
 America/Cuiaba,"&lt;-04&gt;4" 
 America/Curacao,"AST4" 
 America/Danmarkshavn,"GMT0" 
 America/Dawson,"MST7" 
 America/Dawson_Creek,"MST7" 
 America/Denver,"MST7MDT,M3.2.0,M11.1.0" 
 America/Detroit,"EST5EDT,M3.2.0,M11.1.0" 
 America/Dominica,"AST4" 
 America/Edmonton,"MST7MDT,M3.2.0,M11.1.0" 
 America/Eirunepe,"&lt;-05&gt;5" 
 America/El_Salvador,"CST6" 
 America/Fortaleza,"&lt;-03&gt;3" 
 America/Fort_Nelson,"MST7" 
 America/Glace_Bay,"AST4ADT,M3.2.0,M11.1.0" 
 America/Godthab,"&lt;-03&gt;3&lt;-02&gt;,M3.5.0/-2,M10.5.0/-1" 
 America/Goose_Bay,"AST4ADT,M3.2.0,M11.1.0" 
 America/Grand_Turk,"EST5EDT,M3.2.0,M11.1.0" 
 America/Grenada,"AST4" 
 America/Guadeloupe,"AST4" 
 America/Guatemala,"CST6" 
 America/Guayaquil,"&lt;-05&gt;5" 
 America/Guyana,"&lt;-04&gt;4" 
 America/Halifax,"AST4ADT,M3.2.0,M11.1.0" 
 America/Havana,"CST5CDT,M3.2.0/0,M11.1.0/1" 
 America/Hermosillo,"MST7" 
 America/Indiana/Indianapolis,"EST5EDT,M3.2.0,M11.1.0" 
 America/Indiana/Knox,"CST6CDT,M3.2.0,M11.1.0" 
 America/Indiana/Marengo,"EST5EDT,M3.2.0,M11.1.0" 
 America/Indiana/Petersburg,"EST5EDT,M3.2.0,M11.1.0" 
 America/Indiana/Tell_City,"CST6CDT,M3.2.0,M11.1.0" 
 America/Indiana/Vevay,"EST5EDT,M3.2.0,M11.1.0" 
 America/Indiana/Vincennes,"EST5EDT,M3.2.0,M11.1.0" 
 America/Indiana/Winamac,"EST5EDT,M3.2.0,M11.1.0" 
 America/Inuvik,"MST7MDT,M3.2.0,M11.1.0" 
 America/Iqaluit,"EST5EDT,M3.2.0,M11.1.0" 
 America/Jamaica,"EST5" 
 America/Juneau,"AKST9AKDT,M3.2.0,M11.1.0" 
 America/Kentucky/Louisville,"EST5EDT,M3.2.0,M11.1.0" 
 America/Kentucky/Monticello,"EST5EDT,M3.2.0,M11.1.0" 
 America/Kralendijk,"AST4" 
 America/La_Paz,"&lt;-04&gt;4" 
 America/Lima,"&lt;-05&gt;5" 
 America/Los_Angeles,"PST8PDT,M3.2.0,M11.1.0" 
 America/Lower_Princes,"AST4" 
 America/Maceio,"&lt;-03&gt;3" 
 America/Managua,"CST6" 
 America/Manaus,"&lt;-04&gt;4" 
 America/Marigot,"AST4" 
 America/Martinique,"AST4" 
 America/Matamoros,"CST6CDT,M3.2.0,M11.1.0" 
 America/Mazatlan,"MST7MDT,M4.1.0,M10.5.0" 
 America/Menominee,"CST6CDT,M3.2.0,M11.1.0" 
 America/Merida,"CST6CDT,M4.1.0,M10.5.0" 
 America/Metlakatla,"AKST9AKDT,M3.2.0,M11.1.0" 
 America/Mexico_City,"CST6CDT,M4.1.0,M10.5.0" 
 America/Miquelon,"&lt;-03&gt;3&lt;-02&gt;,M3.2.0,M11.1.0" 
 America/Moncton,"AST4ADT,M3.2.0,M11.1.0" 
 America/Monterrey,"CST6CDT,M4.1.0,M10.5.0" 
 America/Montevideo,"&lt;-03&gt;3" 
 America/Montreal,"EST5EDT,M3.2.0,M11.1.0" 
 America/Montserrat,"AST4" 
 America/Nassau,"EST5EDT,M3.2.0,M11.1.0" 
 America/New_York,"EST5EDT,M3.2.0,M11.1.0" 
 America/Nipigon,"EST5EDT,M3.2.0,M11.1.0" 
 America/Nome,"AKST9AKDT,M3.2.0,M11.1.0" 
 America/Noronha,"&lt;-02&gt;2" 
 America/North_Dakota/Beulah,"CST6CDT,M3.2.0,M11.1.0" 
 America/North_Dakota/Center,"CST6CDT,M3.2.0,M11.1.0" 
 America/North_Dakota/New_Salem,"CST6CDT,M3.2.0,M11.1.0" 
 America/Nuuk,"&lt;-03&gt;3&lt;-02&gt;,M3.5.0/-2,M10.5.0/-1" 
 America/Ojinaga,"MST7MDT,M3.2.0,M11.1.0" 
 America/Panama,"EST5" 
 America/Pangnirtung,"EST5EDT,M3.2.0,M11.1.0" 
 America/Paramaribo,"&lt;-03&gt;3" 
 America/Phoenix,"MST7" 
 America/Port-au-Prince,"EST5EDT,M3.2.0,M11.1.0" 
 America/Port_of_Spain,"AST4" 
 America/Porto_Velho,"&lt;-04&gt;4" 
 America/Puerto_Rico,"AST4" 
 America/Punta_Arenas,"&lt;-03&gt;3" 
 America/Rainy_River,"CST6CDT,M3.2.0,M11.1.0" 
 America/Rankin_Inlet,"CST6CDT,M3.2.0,M11.1.0" 
 America/Recife,"&lt;-03&gt;3" 
 America/Regina,"CST6" 
 America/Resolute,"CST6CDT,M3.2.0,M11.1.0" 
 America/Rio_Branco,"&lt;-05&gt;5" 
 America/Santarem,"&lt;-03&gt;3" 
 America/Santiago,"&lt;-04&gt;4&lt;-03&gt;,M9.1.6/24,M4.1.6/24" 
 America/Santo_Domingo,"AST4" 
 America/Sao_Paulo,"&lt;-03&gt;3" 
 America/Scoresbysund,"&lt;-01&gt;1&lt;+00&gt;,M3.5.0/0,M10.5.0/1" 
 America/Sitka,"AKST9AKDT,M3.2.0,M11.1.0" 
 America/St_Barthelemy,"AST4" 
 America/St_Johns,"NST3:30NDT,M3.2.0,M11.1.0" 
 America/St_Kitts,"AST4" 
 America/St_Lucia,"AST4" 
 America/St_Thomas,"AST4" 
 America/St_Vincent,"AST4" 
 America/Swift_Current,"CST6" 
 America/Tegucigalpa,"CST6" 
 America/Thule,"AST4ADT,M3.2.0,M11.1.0" 
 America/Thunder_Bay,"EST5EDT,M3.2.0,M11.1.0" 
 America/Tijuana,"PST8PDT,M3.2.0,M11.1.0" 
 America/Toronto,"EST5EDT,M3.2.0,M11.1.0" 
 America/Tortola,"AST4" 
 America/Vancouver,"PST8PDT,M3.2.0,M11.1.0" 
 America/Whitehorse,"MST7" 
 America/Winnipeg,"CST6CDT,M3.2.0,M11.1.0" 
 America/Yakutat,"AKST9AKDT,M3.2.0,M11.1.0" 
 America/Yellowknife,"MST7MDT,M3.2.0,M11.1.0" 
 Antarctica/Casey,"&lt;+11&gt;-11" 
 Antarctica/Davis,"&lt;+07&gt;-7" 
 Antarctica/DumontDUrville,"&lt;+10&gt;-10" 
 Antarctica/Macquarie,"AEST-10AEDT,M10.1.0,M4.1.0/3" 
 Antarctica/Mawson,"&lt;+05&gt;-5" 
 Antarctica/McMurdo,"NZST-12NZDT,M9.5.0,M4.1.0/3" 
 Antarctica/Palmer,"&lt;-03&gt;3" 
 Antarctica/Rothera,"&lt;-03&gt;3" 
 Antarctica/Syowa,"&lt;+03&gt;-3" 
 Antarctica/Troll,"&lt;+00&gt;0&lt;+02&gt;-2,M3.5.0/1,M10.5.0/3" 
 Antarctica/Vostok,"&lt;+06&gt;-6" 
 Arctic/Longyearbyen,"CET-1CEST,M3.5.0,M10.5.0/3" 
 Asia/Aden,"&lt;+03&gt;-3" 
 Asia/Almaty,"&lt;+06&gt;-6" 
 Asia/Amman,"EET-2EEST,M2.5.4/24,M10.5.5/1" 
 Asia/Anadyr,"&lt;+12&gt;-12" 
 Asia/Aqtau,"&lt;+05&gt;-5" 
 Asia/Aqtobe,"&lt;+05&gt;-5" 
 Asia/Ashgabat,"&lt;+05&gt;-5" 
 Asia/Atyrau,"&lt;+05&gt;-5" 
 Asia/Baghdad,"&lt;+03&gt;-3" 
 Asia/Bahrain,"&lt;+03&gt;-3" 
 Asia/Baku,"&lt;+04&gt;-4" 
 Asia/Bangkok,"&lt;+07&gt;-7" 
 Asia/Barnaul,"&lt;+07&gt;-7" 
 Asia/Beirut,"EET-2EEST,M3.5.0/0,M10.5.0/0" 
 Asia/Bishkek,"&lt;+06&gt;-6" 
 Asia/Brunei,"&lt;+08&gt;-8" 
 Asia/Chita,"&lt;+09&gt;-9" 
 Asia/Choibalsan,"&lt;+08&gt;-8" 
 Asia/Colombo,"&lt;+0530&gt;-5:30" 
 Asia/Damascus,"EET-2EEST,M3.5.5/0,M10.5.5/0" 
 Asia/Dhaka,"&lt;+06&gt;-6" 
 Asia/Dili,"&lt;+09&gt;-9" 
 Asia/Dubai,"&lt;+04&gt;-4" 
 Asia/Dushanbe,"&lt;+05&gt;-5" 
 Asia/Famagusta,"EET-2EEST,M3.5.0/3,M10.5.0/4" 
 Asia/Gaza,"EET-2EEST,M3.4.4/48,M10.5.5/1" 
 Asia/Hebron,"EET-2EEST,M3.4.4/48,M10.5.5/1" 
 Asia/Ho_Chi_Minh,"&lt;+07&gt;-7" 
 Asia/Hong_Kong,"HKT-8" 
 Asia/Hovd,"&lt;+07&gt;-7" 
 Asia/Irkutsk,"&lt;+08&gt;-8" 
 Asia/Jakarta,"WIB-7" 
 Asia/Jayapura,"WIT-9" 
 Asia/Jerusalem,"IST-2IDT,M3.4.4/26,M10.5.0" 
 Asia/Kabul,"&lt;+0430&gt;-4:30" 
 Asia/Kamchatka,"&lt;+12&gt;-12" 
 Asia/Karachi,"PKT-5" 
 Asia/Kathmandu,"&lt;+0545&gt;-5:45" 
 Asia/Khandyga,"&lt;+09&gt;-9" 
 Asia/Kolkata,"IST-5:30" 
 Asia/Krasnoyarsk,"&lt;+07&gt;-7" 
 Asia/Kuala_Lumpur,"&lt;+08&gt;-8" 
 Asia/Kuching,"&lt;+08&gt;-8" 
 Asia/Kuwait,"&lt;+03&gt;-3" 
 Asia/Macau,"CST-8" 
 Asia/Magadan,"&lt;+11&gt;-11" 
 Asia/Makassar,"WITA-8" 
 Asia/Manila,"PST-8" 
 Asia/Muscat,"&lt;+04&gt;-4" 
 Asia/Nicosia,"EET-2EEST,M3.5.0/3,M10.5.0/4" 
 Asia/Novokuznetsk,"&lt;+07&gt;-7" 
 Asia/Novosibirsk,"&lt;+07&gt;-7" 
 Asia/Omsk,"&lt;+06&gt;-6" 
 Asia/Oral,"&lt;+05&gt;-5" 
 Asia/Phnom_Penh,"&lt;+07&gt;-7" 
 Asia/Pontianak,"WIB-7" 
 Asia/Pyongyang,"KST-9" 
 Asia/Qatar,"&lt;+03&gt;-3" 
 Asia/Qyzylorda,"&lt;+05&gt;-5" 
 Asia/Riyadh,"&lt;+03&gt;-3" 
 Asia/Sakhalin,"&lt;+11&gt;-11" 
 Asia/Samarkand,"&lt;+05&gt;-5" 
 Asia/Seoul,"KST-9" 
 Asia/Shanghai,"CST-8" 
 Asia/Singapore,"&lt;+08&gt;-8" 
 Asia/Srednekolymsk,"&lt;+11&gt;-11" 
 Asia/Taipei,"CST-8" 
 Asia/Tashkent,"&lt;+05&gt;-5" 
 Asia/Tbilisi,"&lt;+04&gt;-4" 
 Asia/Tehran,"&lt;+0330&gt;-3:30&lt;+0430&gt;,J79/24,J263/24" 
 Asia/Thimphu,"&lt;+06&gt;-6" 
 Asia/Tokyo,"JST-9" 
 Asia/Tomsk,"&lt;+07&gt;-7" 
 Asia/Ulaanbaatar,"&lt;+08&gt;-8" 
 Asia/Urumqi,"&lt;+06&gt;-6" 
 Asia/Ust-Nera,"&lt;+10&gt;-10" 
 Asia/Vientiane,"&lt;+07&gt;-7" 
 Asia/Vladivostok,"&lt;+10&gt;-10" 
 Asia/Yakutsk,"&lt;+09&gt;-9" 
 Asia/Yangon,"&lt;+0630&gt;-6:30" 
 Asia/Yekaterinburg,"&lt;+05&gt;-5" 
 Asia/Yerevan,"&lt;+04&gt;-4" 
 Atlantic/Azores,"&lt;-01&gt;1&lt;+00&gt;,M3.5.0/0,M10.5.0/1" 
 Atlantic/Bermuda,"AST4ADT,M3.2.0,M11.1.0" 
 Atlantic/Canary,"WET0WEST,M3.5.0/1,M10.5.0" 
 Atlantic/Cape_Verde,"&lt;-01&gt;1" 
 Atlantic/Faroe,"WET0WEST,M3.5.0/1,M10.5.0" 
 Atlantic/Madeira,"WET0WEST,M3.5.0/1,M10.5.0" 
 Atlantic/Reykjavik,"GMT0" 
 Atlantic/South_Georgia,"&lt;-02&gt;2" 
 Atlantic/Stanley,"&lt;-03&gt;3" 
 Atlantic/St_Helena,"GMT0" 
 Australia/Adelaide,"ACST-9:30ACDT,M10.1.0,M4.1.0/3" 
 Australia/Brisbane,"AEST-10" 
 Australia/Broken_Hill,"ACST-9:30ACDT,M10.1.0,M4.1.0/3" 
 Australia/Currie,"AEST-10AEDT,M10.1.0,M4.1.0/3" 
 Australia/Darwin,"ACST-9:30" 
 Australia/Eucla,"&lt;+0845&gt;-8:45" 
 Australia/Hobart,"AEST-10AEDT,M10.1.0,M4.1.0/3" 
 Australia/Lindeman,"AEST-10" 
 Australia/Lord_Howe,"&lt;+1030&gt;-10:30&lt;+11&gt;-11,M10.1.0,M4.1.0" 
 Australia/Melbourne,"AEST-10AEDT,M10.1.0,M4.1.0/3" 
 Australia/Perth,"AWST-8" 
 Australia/Sydney,"AEST-10AEDT,M10.1.0,M4.1.0/3" 
 Europe/Amsterdam,"CET-1CEST,M3.5.0,M10.5.0/3" 
 Europe/Andorra,"CET-1CEST,M3.5.0,M10.5.0/3" 
 Europe/Astrakhan,"&lt;+04&gt;-4" 
 Europe/Athens,"EET-2EEST,M3.5.0/3,M10.5.0/4" 
 Europe/Belgrade,"CET-1CEST,M3.5.0,M10.5.0/3" 
 Europe/Berlin,"CET-1CEST,M3.5.0,M10.5.0/3" 
 Europe/Bratislava,"CET-1CEST,M3.5.0,M10.5.0/3" 
 Europe/Brussels,"CET-1CEST,M3.5.0,M10.5.0/3" 
 Europe/Bucharest,"EET-2EEST,M3.5.0/3,M10.5.0/4" 
 Europe/Budapest,"CET-1CEST,M3.5.0,M10.5.0/3" 
 Europe/Busingen,"CET-1CEST,M3.5.0,M10.5.0/3" 
 Europe/Chisinau,"EET-2EEST,M3.5.0,M10.5.0/3" 
 Europe/Copenhagen,"CET-1CEST,M3.5.0,M10.5.0/3" 
 Europe/Dublin,"IST-1GMT0,M10.5.0,M3.5.0/1" 
 Europe/Gibraltar,"CET-1CEST,M3.5.0,M10.5.0/3" 
 Europe/Guernsey,"GMT0BST,M3.5.0/1,M10.5.0" 
 Europe/Helsinki,"EET-2EEST,M3.5.0/3,M10.5.0/4" 
 Europe/Isle_of_Man,"GMT0BST,M3.5.0/1,M10.5.0" 
 Europe/Istanbul,"&lt;+03&gt;-3" 
 Europe/Jersey,"GMT0BST,M3.5.0/1,M10.5.0" 
 Europe/Kaliningrad,"EET-2" 
 Europe/Kiev,"EET-2EEST,M3.5.0/3,M10.5.0/4" 
 Europe/Kirov,"&lt;+03&gt;-3" 
 Europe/Lisbon,"WET0WEST,M3.5.0/1,M10.5.0" 
 Europe/Ljubljana,"CET-1CEST,M3.5.0,M10.5.0/3" 
 Europe/London,"GMT0BST,M3.5.0/1,M10.5.0" 
 Europe/Luxembourg,"CET-1CEST,M3.5.0,M10.5.0/3" 
 Europe/Madrid,"CET-1CEST,M3.5.0,M10.5.0/3" 
 Europe/Malta,"CET-1CEST,M3.5.0,M10.5.0/3" 
 Europe/Mariehamn,"EET-2EEST,M3.5.0/3,M10.5.0/4" 
 Europe/Minsk,"&lt;+03&gt;-3" 
 Europe/Monaco,"CET-1CEST,M3.5.0,M10.5.0/3" 
 Europe/Moscow,"MSK-3" 
 Europe/Oslo,"CET-1CEST,M3.5.0,M10.5.0/3" 
 Europe/Paris,"CET-1CEST,M3.5.0,M10.5.0/3" 
 Europe/Podgorica,"CET-1CEST,M3.5.0,M10.5.0/3" 
 Europe/Prague,"CET-1CEST,M3.5.0,M10.5.0/3" 
 Europe/Riga,"EET-2EEST,M3.5.0/3,M10.5.0/4" 
 Europe/Rome,"CET-1CEST,M3.5.0,M10.5.0/3" 
 Europe/Samara,"&lt;+04&gt;-4" 
 Europe/San_Marino,"CET-1CEST,M3.5.0,M10.5.0/3" 
 Europe/Sarajevo,"CET-1CEST,M3.5.0,M10.5.0/3" 
 Europe/Saratov,"&lt;+04&gt;-4" 
 Europe/Simferopol,"MSK-3" 
 Europe/Skopje,"CET-1CEST,M3.5.0,M10.5.0/3" 
 Europe/Sofia,"EET-2EEST,M3.5.0/3,M10.5.0/4" 
 Europe/Stockholm,"CET-1CEST,M3.5.0,M10.5.0/3" 
 Europe/Tallinn,"EET-2EEST,M3.5.0/3,M10.5.0/4" 
 Europe/Tirane,"CET-1CEST,M3.5.0,M10.5.0/3" 
 Europe/Ulyanovsk,"&lt;+04&gt;-4" 
 Europe/Uzhgorod,"EET-2EEST,M3.5.0/3,M10.5.0/4" 
 Europe/Vaduz,"CET-1CEST,M3.5.0,M10.5.0/3" 
 Europe/Vatican,"CET-1CEST,M3.5.0,M10.5.0/3" 
 Europe/Vienna,"CET-1CEST,M3.5.0,M10.5.0/3" 
 Europe/Vilnius,"EET-2EEST,M3.5.0/3,M10.5.0/4" 
 Europe/Volgograd,"&lt;+03&gt;-3" 
 Europe/Warsaw,"CET-1CEST,M3.5.0,M10.5.0/3" 
 Europe/Zagreb,"CET-1CEST,M3.5.0,M10.5.0/3" 
 Europe/Zaporozhye,"EET-2EEST,M3.5.0/3,M10.5.0/4" 
 Europe/Zurich,"CET-1CEST,M3.5.0,M10.5.0/3" 
 Indian/Antananarivo,"EAT-3" 
 Indian/Chagos,"&lt;+06&gt;-6" 
 Indian/Christmas,"&lt;+07&gt;-7" 
 Indian/Cocos,"&lt;+0630&gt;-6:30" 
 Indian/Comoro,"EAT-3" 
 Indian/Kerguelen,"&lt;+05&gt;-5" 
 Indian/Mahe,"&lt;+04&gt;-4" 
 Indian/Maldives,"&lt;+05&gt;-5" 
 Indian/Mauritius,"&lt;+04&gt;-4" 
 Indian/Mayotte,"EAT-3" 
 Indian/Reunion,"&lt;+04&gt;-4" 
 Pacific/Apia,"&lt;+13&gt;-13" 
 Pacific/Auckland,"NZST-12NZDT,M9.5.0,M4.1.0/3" 
 Pacific/Bougainville,"&lt;+11&gt;-11" 
 Pacific/Chatham,"&lt;+1245&gt;-12:45&lt;+1345&gt;,M9.5.0/2:45,M4.1.0/3:45" 
 Pacific/Chuuk,"&lt;+10&gt;-10" 
 Pacific/Easter,"&lt;-06&gt;6&lt;-05&gt;,M9.1.6/22,M4.1.6/22" 
 Pacific/Efate,"&lt;+11&gt;-11" 
 Pacific/Enderbury,"&lt;+13&gt;-13" 
 Pacific/Fakaofo,"&lt;+13&gt;-13" 
 Pacific/Fiji,"&lt;+12&gt;-12&lt;+13&gt;,M11.2.0,M1.2.3/99" 
 Pacific/Funafuti,"&lt;+12&gt;-12" 
 Pacific/Galapagos,"&lt;-06&gt;6" 
 Pacific/Gambier,"&lt;-09&gt;9" 
 Pacific/Guadalcanal,"&lt;+11&gt;-11" 
 Pacific/Guam,"ChST-10" 
 Pacific/Honolulu,"HST10" 
 Pacific/Kiritimati,"&lt;+14&gt;-14" 
 Pacific/Kosrae,"&lt;+11&gt;-11" 
 Pacific/Kwajalein,"&lt;+12&gt;-12" 
 Pacific/Majuro,"&lt;+12&gt;-12" 
 Pacific/Marquesas,"&lt;-0930&gt;9:30" 
 Pacific/Midway,"SST11" 
 Pacific/Nauru,"&lt;+12&gt;-12" 
 Pacific/Niue,"&lt;-11&gt;11" 
 Pacific/Norfolk,"&lt;+11&gt;-11&lt;+12&gt;,M10.1.0,M4.1.0/3" 
 Pacific/Noumea,"&lt;+11&gt;-11" 
 Pacific/Pago_Pago,"SST11" 
 Pacific/Palau,"&lt;+09&gt;-9" 
 Pacific/Pitcairn,"&lt;-08&gt;8" 
 Pacific/Pohnpei,"&lt;+11&gt;-11" 
 Pacific/Port_Moresby,"&lt;+10&gt;-10" 
 Pacific/Rarotonga,"&lt;-10&gt;10" 
 Pacific/Saipan,"ChST-10" 
 Pacific/Tahiti,"&lt;-10&gt;10" 
 Pacific/Tarawa,"&lt;+12&gt;-12" 
 Pacific/Tongatapu,"&lt;+13&gt;-13" 
 Pacific/Wake,"&lt;+12&gt;-12" 
 Pacific/Wallis,"&lt;+12&gt;-12" 
 Etc/GMT,"GMT0" 
 Etc/GMT-0,"GMT0" 
 Etc/GMT-1,"&lt;+01&gt;-1" 
 Etc/GMT-2,"&lt;+02&gt;-2" 
 Etc/GMT-3,"&lt;+03&gt;-3" 
 Etc/GMT-4,"&lt;+04&gt;-4" 
 Etc/GMT-5,"&lt;+05&gt;-5" 
 Etc/GMT-6,"&lt;+06&gt;-6" 
 Etc/GMT-7,"&lt;+07&gt;-7" 
 Etc/GMT-8,"&lt;+08&gt;-8" 
 Etc/GMT-9,"&lt;+09&gt;-9" 
 Etc/GMT-10,"&lt;+10&gt;-10" 
 Etc/GMT-11,"&lt;+11&gt;-11" 
 Etc/GMT-12,"&lt;+12&gt;-12" 
 Etc/GMT-13,"&lt;+13&gt;-13" 
 Etc/GMT-14,"&lt;+14&gt;-14" 
 Etc/GMT0,"GMT0" 
 Etc/GMT+0,"GMT0" 
 Etc/GMT+1,"&lt;-01&gt;1" 
 Etc/GMT+2,"&lt;-02&gt;2" 
 Etc/GMT+3,"&lt;-03&gt;3" 
 Etc/GMT+4,"&lt;-04&gt;4" 
 Etc/GMT+5,"&lt;-05&gt;5" 
 Etc/GMT+6,"&lt;-06&gt;6" 
 Etc/GMT+7,"&lt;-07&gt;7" 
 Etc/GMT+8,"&lt;-08&gt;8" 
 Etc/GMT+9,"&lt;-09&gt;9" 
 Etc/GMT+10,"&lt;-10&gt;10" 
 Etc/GMT+11,"&lt;-11&gt;11" 
 Etc/GMT+12,"&lt;-12&gt;12" 
 Etc/UCT,"UTC0" 
 Etc/UTC,"UTC0" 
 Etc/Greenwich,"GMT0" 
 Etc/Universal,"UTC0" 
 Etc/Zulu,"UTC0" </pre>

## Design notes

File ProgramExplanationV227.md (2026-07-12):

# Program explanation

The program uses the following standard libraries.

```cpp
//------------------------------------------------------------------------------              //
// ESP32 Includes defines and initialisations
//-------------------------------------------
                      #if ESP_ARDUINO_VERSION >= ESP_ARDUINO_VERSION_VAL (5, 2, 0)
#define USEEDSOFTLED  // EdsoftLED >= V1.7.0 for SK6812. Saves 200-500 bytes vs NeoPixel
                      #endif
                      #ifdef USEEDSOFTLED
#include <EdSoftLED.h>         // https://github.com/ednieuw/EdSoftLED for WS2812 or SK6812
                      #else
#include <Adafruit_NeoPixel.h> // https://github.com/adafruit/Adafruit_NeoPixel (legacy, GPIO numbering)
                      #endif
#include <Preferences.h>       // Permanent storage of the Mem struct
#include <NimBLEDevice.h>      // BLE communication. Use NimBLE 2.x.x  https://github.com/h2zero/NimBLE-Arduino
#include <WiFi.h>              // Web page
#include <esp_sntp.h>          // NTP
#include <esp_wps.h>           // WPS
#include <ESPAsyncWebServer.h> // Web page  https://github.com/ESP32Async
#include <Update.h>            // Over-the-Air (OTA)
#include <ESPmDNS.h>           // Show BLE name in router
#include <DNSServer.h>         // Captive portal for entering SSID/password
#include <Wire.h>              // I2C
#include <RTClib.h>            // DS3231 RTC  https://adafruit.github.io/RTClib/html/class_r_t_c___d_s3231.html
#include <Encoder.h>           // Rotary encoder
#include <Keypad.h>            // 3x1 membrane keypad (Mark Stanley & Alexander Brevig)
#include <IRremote.hpp>        // IR remote control
```

The HTML pages and clock logic are split over separate TABs in the IDE and included as headers:

```cpp
#include "Webpage.h"    // Main clock web page (with live log window + menu link)
#include "SoftAP.h"     // Access-Point page to enter SSID and password
#include "OTAhtml.h"    // OTA firmware update page (/update)
#include "LogViewer.h"  // Full log viewer page (/log)
#include "ColourPick.h" // Colour picker page (/colourpick)
#include "MenuPage.h"   // Touch-friendly menu page (/menu)
#include "ClockLogic.h" // Clock display logic and language functions
```

`Webpage.h`, `MenuPage.h` etc. are included as TABs in the IDE. They contain the web pages shown in the browser. I made the original page in the free *Microsoft Expression Web 4* — no longer maintained but more than enough for this purpose; Notepad++ or an AI assistant are good alternatives. To copy code out of MS-Expression: click **Split** at the bottom of the window — the upper half shows the raw HTML, the lower half the design view. Copy the HTML and paste it in the relevant `.h` TAB between `R"rawliteral(` … `)rawliteral";`.

A long list of definitions and initialisations follows. I am not a fan of passing all variables to and from functions and prefer to keep them global in one program listing. When writing with other people it is good practice to avoid too many globals, but this program is one large listing, kept simple on purpose. I grouped the variables per application so a simple *find* locates them quickly. To print the time as coloured text/LEDs, each word and its position in the LED string is defined as a macro that calls `ColorLeds` with the right parameters. The functions `Dutch()`, `English()` etc. show why these macros are so handy. They live in the TAB **`ClockFaces.h`**.

```cpp
#define PRECIES ColorLeds("precies", 16, 22, LetterColor);
#define MTIEN   ColorLeds("tien", 25, 28, LetterColor);
#define KWART   ColorLeds("kwart", 32, 36, LetterColor);
#define VOOR    ColorLeds("voor", 38, 41, LetterColor);
```

This is the storage area for the `EEPROMstorage` struct. The whole struct is saved in one command to permanent memory via `Preferences FLASHSTOR;`

```cpp
struct EEPROMstorage {           // Kept after power loss
  byte DisplayChoice = 0;
  ...
  char BLEbroadcastName[30];     // Name of the BLE beacon
  char Timezone[50];
  int  Checksum = 0;
} Mem;
```

Variables are addressed with the short name `Mem`, e.g. `Mem.DisplayChoice = 3;`. The struct is stored with `StoreStructInFlashMemory()` and retrieved with `GetStructFromFlashMemory()`.

The menu shown in the serial monitor, BLE app and web page is defined here. On the web page the line with **II long menu** also carries a hyperlink to `/menu`.

```cpp
// Menu
//0        1         2         3         4
//1234567890123456789012345678901234567890
const char *menu[] = {
 "A SSID, B Password, C BLE beacon name",
 "D Date (D15012021), T Time (T132145)",
 ...
 "I Info menu, II long menu <a href=/menu>&#9776; Menu page</a>",
 ...
 "Ed Nieuwenhuijs Jun 2026" };
```

The Setup happens here:

```cpp
//--------------------------------------------
// ARDUINO Setup
//--------------------------------------------
void setup()
{
 Serial.begin(115200); Tekstprintln("Serial started");
 ...
 InitLogBuffer();   // Allocate the circular log buffer (PSRAM if available)
 ...
 msTick = millis();
}
```

The loop is kept almost empty; the program runs from `EverySecondCheck`. Nothing here needs to run every millisecond.

```cpp
//--------------------------------------------
// ARDUINO Loop
//--------------------------------------------
void loop()
{
 Loopcounter++;
 if (Demo)            Demomode();
 else if(FireDisplay) FireMode();
 else                 EverySecondCheck();   // Let the second LED tick and run the clock
 CheckDevices();
}
```

The following routines check what must happen every second, minute, hour and day. This keeps the processor ~99% free. The loops-per-second figure is printed in the serial monitor (with `TestLDR` on) and is handy to spot if the program is spending too much time somewhere — currently around 200,000 l/s.

```cpp
//--------------------------------------------                                                //
// COMMON Check connected input devices
//--------------------------------------------
void CheckDevices(void)
{
 CheckBLE();                                  // BLE input?
 SerialCheck();                               // Serial input?
 CheckWIFIcommand();                          // Command from the web page?
 if (Mem.TimeInput==1) RotaryEncoderCheck();
 if (Mem.TimeInput==2) Keypad3x1Check();
 if (Mem.TimeInput==3 || Mem.TimeInput==4) IrReceiverDecode();
 if (ntpJustSynced) CheckandPrintNTPsynced();
                                  #ifdef ONEWIREKEYPAD3x4
 OnewireKeypad3x4Check();
                                  #endif
                                  #ifdef ONEWIREKEYPAD3x1
 OnewireKeypad3x1Check();
                                  #endif
}
```

`EverySecondCheck()` also services the Time Receiver client, the LDR dimming and the OTA reboot, and calls `EveryMinuteUpdate()` → `EveryHourUpdate()` → `EveryDayUpdate()` in cascade.

```cpp
void EverySecondCheck(void)
{
 static bool Toggle = 0;
 uint32_t msLeap = millis() - msTick;
 if (msLeap > 999)                                       // Every second
  {
   ...
   if (Mem.TimeReceiver) CheckTimeReceiverClient();
   DimLeds(TestLDR);
   if (shouldReboot) { delay(2000); ESP.restart(); }     // After OTA update
   if (timeinfo.tm_min != lastminute) EveryMinuteUpdate();
   Loopcounter=0;
  }
}
```

## Status LEDs

```cpp
//--------------------------------------------                                                //
// COMMON Update routine for the status LEDs
//--------------------------------------------
void UpdateStatusLEDs(bool Toggle)
{
 if(Mem.StatusLEDOn)
   {
    SetStatusLED((Toggle && WiFi.localIP()[0]==0) * 20,
                 (Toggle && WiFi.localIP()[0]!=0) * 20,
                 (Toggle &&      deviceConnected) * 20);
    SetPCBLED09( Toggle * 10);                    // Left LED
    SetPCBLED10((!Toggle) * 10);                  // Right LED
    SetNanoLED13((!Toggle) * (!Mem.UseDS3231 * 50));
   }
 else { SetStatusLED(0,0,0); SetPCBLED09(0); SetPCBLED10(0); SetNanoLED13(0); }
}
```

On the Nano ESP32 `analogWrite(LED_RED, 512)` is OFF and `analogWrite(LED_RED, 0)` is ON. With Espressif ESP32 core 3.x the RMT resolution rose from 8→10 bits, so the off value is `8191` to make sure the LED turns off completely:

```cpp
analogWrite(LED_RED, Red == 0 ? 8191 : (512 - Red));
```

## Common print routines

All output passes through one place, so it is easy to retarget for other boards. Note that `Tekstprint` now also feeds the **ring-buffer log** via `AddLog`:

```cpp
void Tekstprint(char const *tekst)   { if(Serial) Serial.print(tekst); SendMessageTimeReceiver(tekst); SendMessageBLE(tekst); AddLog(tekst); }
void Tekstprintln(char const *tekst) { snprintf(sptext, sizeof(sptext),"%s\n",tekst); Tekstprint(sptext); }
void Tekstprintf(const char* fmt, ...)   { va_list a; va_start(a,fmt); vsnprintf(sptext,sizeof(sptext),fmt,a); va_end(a); Tekstprint(sptext); }
void Tekstprintlnf(const char* fmt, ...) { va_list a; va_start(a,fmt); vsnprintf(sptext,sizeof(sptext),fmt,a); va_end(a); Tekstprintln(sptext); }
```

For the web page there is a parallel set, `WTekstprint` / `WTekstprintln`, that builds the HTML info block. They take an optional prefix/suffix so a line can carry web-only HTML (e.g. the `/update` link) without cluttering the serial/BLE output.

## Serial input

Check for serial input from the serial monitor and pass the command to `ReworkInputString()`.

```cpp
//--------------------------------------------
// COMMON Check for serial input
//--------------------------------------------
void SerialCheck(void)
{
 ...
 ReworkInputString(SerialString);   // Process the input string in the menu
 ...
}
```

## Reset to defaults

Restore all default values. Triggered by the `R` command or when the stored checksum is invalid.

```cpp
//--------------------------------------------
// COMMON Reset to default settings
//--------------------------------------------
void Reset(void)
{
 Mem.Checksum      = 25065;
 Mem.DisplayChoice = DEFAULTCOLOUR;
 Mem.OwnColour     = green;
 Mem.DimmedLetter  = black;
 Mem.BackGround    = black;
 ...
 StoreStructInFlashMemory();
 GetTijd(false);
 SWversion();
 Displaytime(); Tekstprintln("");
}
```

## Storage

`InitStorage()` sets up the storage space and checks the validity of the settings; an invalid checksum triggers a `Reset()` to the defaults. The whole `Mem` struct is then saved or loaded in one command via `Preferences`.

```cpp
//--------------------------------------------
// COMMON Init and check contents of storage
//--------------------------------------------
void InitStorage(void) { ... }

//--------------------------------------------
// COMMON Store Mem struct in flash storage
//--------------------------------------------
void StoreStructInFlashMemory(void) { ... }

//--------------------------------------------
// COMMON Get data from flash storage (Preferences.h)
//--------------------------------------------
void GetStructFromFlashMemory(void) { ... }
```

## Version info and menu

`SWversion()` prints the menu and the current settings; `PrintLine()` draws the horizontal divider lines. `SWversion(bool Small)` selects the short or long menu, and the print loop adds the web-only `/menu` hyperlink to the matching line.

```cpp
//--------------------------------------------
// COMMON Version info
//--------------------------------------------
void SWversion(void)        { SWversion(false); }   // Long menu by default
void SWversion(bool Small)
{
 #define FILENAAM (strrchr(__FILE__, '\\') ? strrchr(__FILE__, '\\') + 1 : __FILE__)
 PrintLine(35);
 if(Small) for (uint8_t i = 0; i < sizeof(menusmall)/sizeof(menusmall[0]); i++) ...
 else      for (uint8_t i = 0; i < sizeof(menu)/sizeof(menu[0]); i++) ...
 ...
 PrintLine(35);
}

void PrintLine(byte Lengte) { ... }
```

## Ring-buffer logging and the log viewer  *(new in V227)*

All text sent through `Tekstprint` is also appended to a **circular log buffer** in PSRAM (falling back to internal RAM). This lets the clock keep a rolling history that survives reconnects and can be viewed in the browser.

```cpp
void InitLogBuffer(void)                 // Allocate the buffer at startup
void AddLog(const char* msg)             // Append to the circular buffer (wraps at the end)
void HandleTekstPrint(...)               // Serve the last ~500 lines  -> /tekstprint
void HandleTekstDownload(...)            // Stream the full buffer      -> /tekstdownload
```

## Get the commands

Input from serial, BLE or the web page is processed in `ReworkInputString()`. The menu letters are case-insensitive (upper/lower conversion) so upper- and lowercase can carry the same commands.

```cpp
//--------------------------------------------
// COMMON Input from Bluetooth, Serial or web
//--------------------------------------------
void ReworkInputString(String InputString)
{
  int len = InputString.length();
  switch(toupper(InputString[0]))
   {
    case 'A':
      if(len > 4 && len < 30) ...
```

## LDR reading

The LDR (analog 0–4096 on the ESP32) is scaled to 0–255:

```cpp
int ReadLDR(void) { return analogRead(PhotoCellPin)/16; }
```

`DimLeds()` reads the LDR and **squares** the value to get a hyperbolic curve that matches the eye's response to dark/light far better than a linear range — it works wonderfully well.

## LED helpers and the interruptible LED test 

A series of LED helpers (`ColorLeds`, `ColorLed`, `LedsOff`, `ShowLeds`, `SetBrightnessLeds`, `Stripfill`, `StartLeds`, …) wrap every strip-specific command so the rest of the code stays generic. The SK6812 strip also has a white LED, controlled by the highest byte of the 32-bit colour value (`0xWWRRGGBB`).

```cpp
//--------------------------------------------
// LED Set color for a range of LEDs and print label
//--------------------------------------------
void ColorLeds(char const *Tekst, int FirstLed, int LastLed, uint32_t RGBWColor) { ... }
```

Every display/strip uses different commands to set brightness, so each LED operation has its own wrapper function:

```cpp
//--------------------------------------------
// LED Set brightness of LED strip
//--------------------------------------------
void SetBrightnessLeds(byte Bright) { LEDstrip.setBrightness(Bright); ShowLeds(); }
```

A place to turn off all LEDs or clear the display:

```cpp
//--------------------------------------------
// LED Clear the LED display
//--------------------------------------------
void LedsOff(void) { LedsOff(false); }
void LedsOff(bool ClearOff) { ... }
```

## Colours of the words

`SetSecondColour()` sets the colours of the characters and is also used to recolour `HET IS WAS` in some display choices (`ClockLogic.h`).

```cpp
//--------------------------------------------
// LED Set second color
//--------------------------------------------
void SetSecondColour(void)
{
 ...
 MINColor = FuncCRGBW(15 + timeinfo.tm_min * 4, 255 - timeinfo.tm_min * 4, 0, 0);
 SECColor = FuncCRGBW(15 + timeinfo.tm_sec * 4, 255 - timeinfo.tm_sec * 4, 0, 0);
 switch (Mem.DisplayChoice)
   {
    case DEFAULTCOLOUR: LetterColor = C_YELLOW;
    ...
   }
}
```

## Self test

Self-test sequence of the clock; default delay is 900 ms per word (`ClockLogic.h`).

```cpp
//--------------------------------------------
// CLOCK Self test sequence
//--------------------------------------------
void Selftest(void) { Selftest(900); }
void Selftest(int Delayms)
{
 GetTijd(true);     // Print time in the serial monitor
 LedsOff();
 ...
}
```

## Display the time

`Displaytime()` prints the time as text to the serial monitor, selects which language is shown, and sends the right colour/intensity sequence to the RGB(W) LED strip (`ClockLogic.h`).

```cpp
//--------------------------------------------
// CLOCK Say the time and load the LEDs
//--------------------------------------------
void Displaytime(void)
{
 LedsOff();
 if( Mem.DisplayChoice == DIGITAL ) { TimePlaceDigit(timeinfo.tm_hour,timeinfo.tm_min); }
 else
   {
                     #ifdef NL144CLOCK
    Dutch();
                     #endif
                     ...
                     #ifdef FOURLANGUAGECLOCK
    SetColours();          // Set the colours for the chosen palette
    Dutch(); English(); German(); French();
                     #endif
   }
 ShowLeds();               // Turn on the LEDs
}
```

## LED strip start-up

A list of LED helper functions follows, including initialisation of the WS2812 or SK6812 strip. The SK6812 also has a white LED whose intensity sits in the highest byte (`WW`) of the 32-bit value `0xWWRRGGBB`.

```cpp
//--------------------------------------------                                                //
// LED Start LEDs
//--------------------------------------------
void StartLeds(void)
{
 switch (Mem.LEDstrip)
   {
    case 0: LEDstrip = LED6812strip;          // SK6812 with white
            white = 0xFF000000; lgray = 0x66000000; gray = 0x33000000; ...
            break;
    case 1: LEDstrip = LED2812strip;          // WS2812 RGB
            white = 0xFFFFFF;   lgray = 0x666666; ...
            break;
   }
}
```

## Time functions

A series of functions get and store time. The NTP server places the retrieved time in the standard C time structures.

```cpp
//--------------------------- Time functions --------------------------
time_t      GetTijd(bool printit)         // Get time from the best available source
DateTime    GetLocalDateTime(void)        // Local time as an RTClib DateTime
bool        GetNTPtime(bool printit)      // Fetch NTP time for the configured timezone
const char* PrintRTCTime(void)            // Time string dd-mmm-yy hh:mm:ss
void        PrintTimeHMS(void)            // Print hh:mm:ss with linefeed
void        SetRTCTime(void)              // Set internal RTC from timeinfo
void        PrintAllClockTimes(void)      // Print all available time sources
void        InitTimeSystem(void)          // Initialise time system (DS3231 + NTP + internal RTC).
void SetSystemTimeToCompileTime(void)     // Set system time to compile time.
bool        IsDS3231I2Cconnected(void)    // DS3231 Check for I2C connection.
float       GetDS3231Temp(void)           // DS3231 Read temperature from DS3231.
void        SetDS3231Time(void)           // DS3231 Write ESP32 time to DS3231.
void        GetDS3231Time(bool printit)   // DS3231 Read time from DS3231 module.
void        SetSystemTime(time_t t)       // RTC Set RTC using Unix timestamp.
void        PrintAllClockTimes(void)      // Print all the clock times available 
```

Convert a HEX string to an unsigned 32-bit integer:

```cpp
//--------------------------------------------
// COMMON Convert Hex to uint32
//--------------------------------------------
uint32_t HexToDec(const String& hexString) { ... }
```

## Speaking the time in four languages

Functions let the clocks speak the time in four languages. Languages also carry a lot of slang — *"half nine"* can mean 8:30 or 9:30. These definitions live in `ClockFaces.h` / `ClockLogic.h`.

```cpp
//--------------------------------------------
// CLOCK Dutch clock display
//--------------------------------------------
                      #if defined(NL) || defined(NL144CLOCK)
void Dutch(void)
{
 HET;                                                     // HET is always on
 if (timeinfo.tm_hour == 12 && timeinfo.tm_min == 0 && random(2)==0) { IS; NOEN; return; }
 if (timeinfo.tm_hour == 00 && timeinfo.tm_min == 0 && random(2)==0) { IS; MIDDER; NACHT; return; }
 switch (timeinfo.tm_min)
   {
    case  0: IS;  PRECIES; break;
    case  1: IS;  break;
    case  2:
    case  3: WAS; break;
    case  4:
    case  5:
    case  6: IS;  MVIJF; OVER; break;
    ...
   }
}
```

## Bluetooth Low Energy

The BLE functions use the Nordic nRF (NimBLE) stack, which differs from the Texas Instruments CC2540/CC2541 used in chipsets like the HM-10, HM-16, JDY-08 etc. ([More on Instructables](https://www.instructables.com/Communicate-Using-CC254x-or-NRF-BLE-With-Arduino-a/))

```cpp
void SendMessageBLE(std::string Message)   // BLE Send message in packets of 20 chars
class MyServerCallbacks : public NimBLEServerCallbacks   // BLE connect/disconnect callbacks
void StartBLEService(void)                 // BLE Start the UART service
void DisconnectBLE(void)                   // BLE Disconnect BLE Service
void CheckBLE(void)                        // BLE Check input and process the string
```
```cpp
//--------------------------- BLE TimeReceiver functions --------------------------
void        TimeReceiverNotifyCB(...)              // Notify callback: copies incoming BLE data into a buffer and passes it to ReworkInputString(); resets the connection-alive timestamp
void        SendMessageTimeReceiver(const char*)   // Writes a message to the remote RX characteristic (no-op if not connected)
void        StartTimeReceiverScan(void)            // Starts a continuous BLE scan using the static scan callback; guards against double-starts and resets stale flags
void        StopTimeReceiver(void)                 // Stops the scan, disconnects and deletes the NimBLE client, and resets all TR state flags
static void Connect_TimeReceiver(void)             // Attempts up to 3 times to connect to the found address, discover the service/characteristics, and subscribe to TX notifications; falls back to a fresh scan on total failure
void        ReconnectTimeReceiver(void)            // Tears down any existing client, reuses the previously found address, and immediately calls Connect_TimeReceiver()
void        CheckTimeReceiverClient(void)          // Main loop-context driver: processes deferred disconnect cleanup, honours scan-callback connect requests, times out stalled connection attempts, and triggers periodic rescans when idle
```
These functions start a connection to a time sender that will set time in this sketch  when the BLE connection is succesfull.
Several time senders are available; from IOS app to web pages or ESP32 sketches.
Just open the application, wait a minute or so and you will see the clock sets time correctly.

- [iPhone BLE TimeSender app (search for Timesender in the Apple app store)](https://ednieuw.nl/BLESerial/BLEtimeSender.html)
- [Arduino Nano ESP32 sketch that Auto connects to BLE-UARTtime BLE client and sends time and date](https://github.com/ednieuw/BLE-time-Sender)
- [HTML page that connects to a BLE UART client and send time and date to it](https://github.com/ednieuw/HTML-TimeSender)
- [web page Windows/IOS/Android.](https://github.com/ednieuw/HTML-BLEserial)
- [BLE serial monitor app on your phone or with a web page Windows/Android](https://github.com/ednieuw/HTML-BLEserial)

## WIFI and the web page

Functions to start a WIFI connection and serve the web pages.

 `WebPage()` registers all the routes listed in the table below.

| Route | Page |
|---|---|
| `/` | Main clock page (Webpage.h) |
| `/menu` | Touch menu page (MenuPage.h) |
| `/log` | Full log viewer (LogViewer.h) |
| `/tekstprint` | Last ~500 log lines (used by the live log windows) |
| `/tekstdownload`| Full log buffer download |
| `/colourpick` | Colour picker (ColourPick.h) |
| `/update` | OTA firmware update (OTAhtml.h) |

The main page and the menu page each embed a small **live log window** — a read-only text area that fetches `/tekstprint` every second, shows the last 50 lines and auto-scrolls to the bottom *only* when you are already at the bottom (so you can scroll up to read history without being yanked back). A checkbox on the main page toggles the window on/off.

```cpp

void WiFiEvent(WiFiEvent_t event)              // WIFI Handle WIFI events.
bool CheckforWIFINetwork(void)                 // WIFI Scan for configured WIFI network (print=true).
bool CheckforWIFINetwork(bool PrintIt)         // WIFI Scan for configured WIFI network, optionally silent.
void ScanWIFI(void)                            // WIFI Scan and print list of available WIFI networks.
void ConnectWIFI(void)                         // WIFI Connect to WIFI router using stored SSID and password.
void CheckRestoreWIFIconnectivity(void)        // WIFI Check WIFI connection and restore if lost.
bool StartWIFI_NTP(void)                       // WIFI Start WIFI connection and NTP service.
void NTPnotify(struct timeval* tv)             // NTP Callback: set ntpJustSynced flag on NTP sync.
void CheckandPrintNTPsynced(void)              // NTP Check and print NTP sync confirmation.
void setTimezone(void)                         // NTP Apply stored timezone to system.
void initSNTP(void)                            // NTP Initialise SNTP client.
bool wait4SNTP(void)                           // NTP Wait up to 2.5 s for SNTP synchronisation.
void CheckWIFIcommand(void)                    // WIFI Process pending command received from web page.
void WebPage(void)                             // WIFI Register all web server routes and start server.
void notFound(AsyncWebServerRequest *request)  // WIFI Handle unknown web page requests.
void StartAPMode(void)                         // WIFI Start Access Point for entering WIFI credentials.
void wpsInitConfig(void)                       // WIFI Initialise WPS configuration.
void wpsStart(void)                            // WIFI Start WPS push-button connection.
void wpsStop(void)                             // WIFI Stop WPS.
String wpspin2string(uint8_t a[])              // WIFI Convert WPS PIN byte array to string.

```

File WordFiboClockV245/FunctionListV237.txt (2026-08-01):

// ============================================================
// WordFiboClockV237 - Function List
// Unified WordClock + Fibonacci + NoClock sketch (variant selected by #define).
// ============================================================

// WordFiboClockV237.ino
void setup()                                                                                // ARDUINO Setup.
void loop()                                                                                 // ARDUINO Loop.
void CheckDevices(void)                                                                     // COMMON Check connected input devices.
void EverySecondCheck(void)                                                                 // COMMON Update routine performed every second.
void EveryMinuteUpdate(void)                                                                // COMMON Update routine performed every minute.
void EveryHourUpdate(void)                                                                  // COMMON Update routine performed every hour.
void EveryDayUpdate(void)                                                                   // COMMON Update routine performed every day.
void InitStatusLEDs(void)                                                                   // COMMON Pin analogWrite resolution/frequency for the RGB status LEDs and set initial colour.
void UpdateStatusLEDs(bool Toggle)                                                          // COMMON Update the status LEDs on the PCB.
void SetStatusLED(int Red, int Green, int Blue)                                             // COMMON Control the RGB status LEDs on the Nano ESP32.
void SetNanoLED13(int intensity)                                                            // LED Control orange LED D13 on the Arduino via analogWrite.
void SetPCBLED09(int intensity)                                                             // LED Control PCB LED D09 via analogWrite.
void SetPCBLED10(int intensity)                                                             // LED Control PCB LED D10 via analogWrite.
void SerialCheck(void)                                                                      // COMMON Check for serial input.
void InitResetpin(void)                                                                     // COMMON Initialise reset pin when installed.
void CheckResetPin(void)                                                                    // COMMON Check reset button on RST_PIN.
void Reset(void)                                                                            // COMMON Reset to default settings. BLE On, WIFI NTP Off.
void ResetCredentials(void)                                                                 // COMMON Reset WIFI/NTP/BLE credentials to empty.
void Tekstprint(char const *tekst)                                                          // COMMON Print to Serial, Time Receiver and BLE, and log it.
void Tekstprintln(char const *tekst)                                                        // COMMON Tekstprint with a trailing newline.
void TekstSprint(char const *tekst)                                                         // COMMON Print to Serial monitor only (debugging).
void TekstSprintln(char const *tekst)                                                       // COMMON TekstSprint with a trailing newline.
void Tekstprintf(const char* fmt, ...)                                                      // COMMON Formatted print.
void Tekstprintlnf(const char* fmt, ...)                                                    // COMMON Formatted print with newline.
void WTekstappend(char const *tekst, char const *prefix, char const *suffix, bool newline)  // COMMON Append text to HTML info buffer.
void WTekstprintln(char const *tekst)                                                       // COMMON Append text with prefix/suffix to HTML info buffer.
void WTekstprintln(char const *tekst, char const *prefix, char const *suffix)               // COMMON Append text with prefix/suffix to HTML info buffer.
void WTekstprint(char const *tekst)                                                         // COMMON Append text with prefix/suffix without newline.
void WTekstprint(char const *tekst, char const *prefix, char const *suffix)                 // COMMON Append text with prefix/suffix without newline.
int SConstrainInt(String s,byte first,byte last,int low,int up)                             // COMMON Parse substring[first,last) as int, clamp to [low,up].
int SConstrainInt(String s,byte first, int low,int up)                                      // COMMON Parse substring[first..] as int, clamp to [low,up].
void InitStorage(void)                                                                      // COMMON Init and check contents of flash storage.
void StoreStructInFlashMemory(void)                                                         // COMMON Store Mem struct in flash storage.
void StoreIRRemoteInFlashMemory(void)                                                       // COMMON Save IR remote settings to flash.
void GetStructFromFlashMemory(void)                                                         // COMMON Load Mem struct from flash storage.
void GetIRRemoteFromFlashMemory(void)                                                       // COMMON Load IR remote settings from flash.
const char* SoftwareName(void)                                                              // COMMON Return software version string.
void SWversion(void)                                                                        // COMMON Print version info, Small=true for short menu.
void SWversion(bool Small)                                                                  // COMMON Print version info, Small=true for short menu.
void PrintLine(byte Lengte)                                                                 // COMMON Print a divider line of n underscores.
void CheckMCURestartCounter(void)                                                           // COMMON Check and reset MCU restart counter after stable run.
void ReworkInputString(String InputString)                                                  // COMMON Process input from Serial, BLE, the web page, or MQTT.
bool parseColourInput(const String& InputString, int len, uint32_t& Color)                  // COMMON Parse hex colour input string.
void PrintTimeInputMethod(byte Im)                                                          // COMMON Print current time input method.
void PrintMem(void)                                                                         // COMMON Print all Mem struct values.
void StoredStartHeaps()                                                                     // COMMON Print or store heap usage.
void StoredStartHeaps(bool Store)                                                           // COMMON Print or store heap usage.
void PrintHeaps(void)                                                                       // COMMON Print current heap memory usage.
int ReadLDR(void)                                                                           // COMMON LDR reading scaled to 0–255.
void ReadAndAverageLDR(void)                                                                // CLOCK Read and average LDR; clean=true resets accumulators.
void ReadAndAverageLDR(bool clean)                                                          // CLOCK Read and average LDR; clean=true resets accumulators.
void DimLeds(bool print)                                                                    // CLOCK Update LED brightness from LDR reading.
void Dlay(uint32_t ms)                                                                      // LED Interruptible delay used during LEDtest; polls CheckDevices and aborts on StopTest.
void LEDtest()                                                                              // CLOCK LED test — light up all LEDs; interruptible by a second Y command.
void ColorLeds(char const *Tekst, int FirstLed, int LastLed, uint32_t RGBWColor)            // LED Set colour for a range of LEDs and print label.
void ColorLed(int Lednr, uint32_t RGBWColor)                                                // LED Set colour for a single LED.
void LedsOff(void)                                                                          // LED Clear LED display; ClearOff=true also clears background.
void LedsOff(bool ClearOff)                                                                 // LED Clear LED display; ClearOff=true also clears background.
void ShowLeds(void)                                                                         // LED Push the LED strip buffer to the hardware.
void SetBrightnessLeds(byte Bright)                                                         // LED Set brightness of LED strip.
void Stripfill(uint32_t RGBWColor, int FirstLed, int NoofLEDs)                              // LED Fill a range of LEDs with one colour.
uint32_t StripGetPixelColor(uint32_t Lednr)                                                 // LED Get the colour of one LED.
void LEDstartup(uint32_t LEDColour)                                                         // LED Show startup colour on LEDs and sync status LED.
void FixDimmedLetterForStrip(uint32_t &colour)                                              // LED Adjust dimmed letter colour for LED strip type.
uint32_t HSVToRGB(double H, double S, double V)                                             // LED Convert HSV to RGB (H 0–360, S/V 0–1).
uint32_t FuncCRGBW( uint32_t Red, uint32_t Green, uint32_t Blue, uint32_t White)            // LED function to make RGBW colour.
void ClearScreen(void)                                                                      // DISPLAY Clear the LED display.
uint32_t Wheel(byte WheelPos)                                                               // DISPLAY Colour wheel: r→g→b→r transition.
void StartLeds(void)                                                                        // DISPLAY Initialise LED strip for WS2812 or SK6812.
void ClearTestStrip(void)                                                                   // LED Blank a 256-LED test strip, then shrink buffer back to NUM_LEDS.
void ChangeRandomDisplay(void)                                                              // DISPLAY Change to next random display choice.
void RainbowCycle(uint8_t wait)                                                             // DISPLAY Rainbow cycle animation (interruptible via Dlay).
void WhiteOverRainbow(uint32_t wait, uint8_t whiteSpeed, uint32_t whiteLength )             // DISPLAY White over rainbow animation (interruptible via Dlay).
void WriteLightReducer(int amount)                                                          // CLOCK Increase or decrease brightness slope value.
void InitTimeSystem(void)                                                                   // TIME Initialise time system (DS3231 + NTP + internal RTC).
void SetSystemTimeToCompileTime(void)                                                       // TIME Set system time to compile time.
time_t GetTijd(bool printit)                                                                // TIME Get current time from best available source.
DateTime GetLocalDateTime()                                                                 // TIME Return current local time as a DateTime object.
bool GetNTPtime(bool printit)                                                               // NTP Get and print NTP time for configured timezone.
const char* PrintNTPtime(void)                                                              // NTP Return NTP time as a formatted string.
const char* PrintUTCtime(void)                                                              // NTP Return UTC time as a formatted string.
bool IsDS3231I2Cconnected(void)                                                             // DS3231 Check for I2C connection.
float GetDS3231Temp(void)                                                                   // DS3231 Read temperature from DS3231.
void SetDS3231Time(void)                                                                    // DS3231 Write ESP32 time to DS3231.
void GetDS3231Time(bool printit)                                                            // DS3231 Read time from DS3231 module.
const char* PrintDS3231Time(void)                                                           // RTC Return DS3231 RTC time as a formatted string.
const char* PrintRTCTime()                                                                  // RTC Return time string as dd-mmm-yy hh:mm:ss.
void PrintTimeHMS()                                                                         // RTC Print time in specified format.
void PrintTimeHMS(byte format)                                                              // RTC Print time in specified format.
void SetRTCTime(void)                                                                       // RTC Set ESP32 internal RTC from global timeinfo struct.
void SetSystemTime(time_t t)                                                                // RTC Set RTC using Unix timestamp.
void PrintAllClockTimes(void)                                                               // CLOCK Print all available time sources.
uint32_t HexToDec(const String& hexString)                                                  // COMMON Convert hex string to uint32.
void SendMessageBLE(std::string Message)                                                    // BLE Send message via BLE in packets of 20 chars.
void StartBLEService(void)                                                                  // BLE Start BLE UART service.
void DisconnectBLE(void)                                                                    // BLE Disconnect BLE client.
void CheckBLE(void)                                                                         // BLE Check BLE input and process string.
void onConnect(NimBLEServer* pServer, NimBLEConnInfo& connInfo) override                    // BLE Server callback for TimeSender client connect/disconnect.
void BLETimeSenderStart(void)                                                               // TIMESENDER Time Sender Start.
void BLETimeSenderStop(void)                                                                // TIMESENDER Time Sender Stop.
void CheckTimeSender(void)                                                                  // TIMESENDER Time Sender Send Time and Date.
void InitHC12(void)                                                                         // HC12 Initialise HC-12 433MHz serial connection.
void SendHC12TimeString(void)                                                               // HC12 Send time string via HC-12 433MHz transmitter.
static void TimeReceiverNotifyCB(NimBLERemoteCharacteristic*, uint8_t* data, size_t len, bool notify)  // BLE Notification callback: handle incoming Time Receiver data.
void SendMessageTimeReceiver(const char* msg)                                               // BLE Send message to Time Receiver client.
void StartTimeReceiverScan(void)                                                            // BLE Start scanning for Time Receiver device.
void StopTimeReceiver(void)                                                                 // BLE Stop Time Receiver and clean up.
static void Connect_TimeReceiver(void)                                                      // BLE Connect to the Time Receiver BLE server.
void ReconnectTimeReceiver(void)                                                            // BLE Reconnect to Time Receiver device.
void CheckTimeReceiverClient(void)                                                          // BLE Check Time Receiver client connection and data.
void WiFiEvent(WiFiEvent_t event)                                                           // WIFI Handle WIFI events.
void ScanWIFI(void)                                                                         // WIFI Scan and print list of available WIFI networks.
void ConnectWIFI(void)                                                                      // WIFI Connect to WIFI router using stored SSID and password.
void CheckRestoreWIFIconnectivity(void)                                                     // WIFI Check WIFI connection and restore if lost.
bool StartWIFI_NTP(void)                                                                    // WIFI Start WIFI connection and NTP service.
void CheckMQTT(void)                                                                        // MQTT Maintain broker connection (non-blocking, throttled ~50x/sec); reconnect, subscribe to cmnd topic, publish discovery on connect.
String MQTTDeviceId(void)                                                                   // MQTT Sanitise Mem.BLEbroadcastName into a topic-safe device id.
void publishMQTTDiscovery(void)                                                             // MQTT Publish all Home Assistant discovery configs once per fresh connection.
void publishDiscoverySensor(String deviceId, String sensorKey, String friendlyName, String stateTopic, String unit, String deviceClass)   // MQTT Publish one HA sensor discovery config.
void publishDiscoveryButton(String deviceId, String buttonKey, String friendlyName, String commandTopic, String payloadPress)             // MQTT Publish one HA button discovery config.
void publishDiscoverySelect(String deviceId, String selectKey, String friendlyName, String commandTopic, String stateTopic)               // MQTT Publish one HA select discovery config (options from QchoiceNames[]).
void PublishCPUTemperature(void)                                                            // MQTT TEST: publish ESP32 internal temperature (called every minute).
void PublishLDRreading(void)                                                                // MQTT TEST: publish the LDR reading (called every minute).
void PublishDisplayChoiceState(void)                                                        // MQTT Publish current Display Colour Scheme so the HA select stays in sync.
void MQTTCallback(char* topic, byte* payload, unsigned int length)                          // MQTT Incoming command callback — forwards payload into ReworkInputString().
void NTPnotify(struct timeval* tv)                                                          // NTP Callback: set ntpJustSynced flag on NTP sync.
void CheckandPrintNTPsynced(void)                                                           // NTP Check and print NTP sync confirmation.
void setTimezone(void)                                                                      // TIME Apply Mem.Timezone to the system TZ environment.
void initSNTP(void)                                                                         // NTP Initialise SNTP client.
bool wait4SNTP(void)                                                                        // NTP Wait up to 2.5 s for SNTP synchronisation.
void BuildHTMLPage(bool Log)                                                                // WIFI Build HTML info page from current clock state.
void CheckWIFIcommand(void)                                                                 // WIFI Process pending command received from web page.
void WebPage(void)                                                                          // WIFI Register all web server routes and start server.
void notFound(AsyncWebServerRequest *request)                                               // WIFI Handle unknown web page requests.
void StartAPMode(void)                                                                      // WIFI Start Access Point for entering WIFI credentials.
void wpsInitConfig(void)                                                                    // WIFI Initialise WPS configuration.
void wpsStart(void)                                                                         // WIFI Start WPS push-button connection.
void wpsStop(void)                                                                          // WIFI Stop WPS.
String wpspin2string(uint8_t a[])                                                           // WIFI Convert WPS PIN byte array to string.
void OnewireKeypad3x4Check(void)                                                            // KEYPAD Check for one-wire 3x4 keypad input.
void OnewireKeypad3x1Check(void)                                                            // KEYPAD Check for one-wire 3x1 keypad input.
void Keypad3x1Check(void)                                                                   // KEYPAD Read 3x1 keypad and process key press.
void RotaryEncoderCheck(void)                                                               // ROTARY Check if rotary encoder is moving or pressed.
void ProcessKeyPressTurn(int encoderPos)                                                    // CLOCK Process rotary or membrane keypad input.
void Start_IRreceiver(void)                                                                 // IR Start large or tiny IR receiver.
void Init_IRreceiver(String* ButtonTempNames, byte numButtons)                              // IR Initialise IR receiver with button name mapping.
uint16_t IrReceiverDecode(void)                                                             // IR Decode received IR signal.
void ProcessLearningMode(decode_type_t protocol, uint16_t command, uint16_t address)        // IR Process signal in learning mode.
void ProcessRecognitionMode(decode_type_t protocol, uint16_t command, uint16_t address)     // IR Process signal in recognition mode.
void StartIRLearning(void)                                                                  // IR Initialise IR learning mode.
void PrintAllMappings(void)                                                                 // IR Print all learned IR button mappings.
void ResetAllIRremoteSettings(void)                                                         // IR Reset all learned IR remote settings.
int RecognizeButton(decode_type_t protocol, uint16_t command, uint16_t address)             // IR Identify which button was pressed.
void ReworkIRremoteValue(int ButtonNamesNr)                                                 // IR Process IR remote button action.
void AdjustTime(int DeltaHours, int DeltaMinutes, int DeltaSeconds)                         // IR Adjust current time by delta hours/minutes/seconds.
void ToggleIRpower(void)                                                                    // IR Toggle IR remote power state on/off.
void InitLogBuffer()                                                                        // LOGBUFFER Initialize circular logging buffer.
void AddLog(const char* msg)                                                                // LOGBUFFER Append message to circular log buffer.
void HandleTekstPrint(AsyncWebServerRequest* request)                                       // LOGBUFFER Serve last 500 log lines to web client.
void HandleTekstDownload(AsyncWebServerRequest *request)                                    // LOGBUFFER Stream full circular log buffer to web client.

// WordClock.h  (compiled only for WORDCLOCK builds)
void PrintDisplayChoice(bool PrintIt)                                                       // COMMON Print display choice from WordClock.h's own QchoiceNames[].
void PrintDisplayChoice()                                                                   // COMMON Print display choice (default: print it).
void Zet_Pixel(byte Cijfer,byte Pos_X, byte Pos_Y)                                          // DISPLAY Place digit 0–9 in matrix display.
void TimePlaceDigit(byte uur, byte minuut)                                                  // DISPLAY Show time as four digits in display.
void SetSecondColour(void)                                                                  // CLOCK Set IS/WAS colour each second (single-language clocks).
void SetColours(void)                                                                       // CLOCK Set colours each second (four-language clock).
void SelftestFlash(int Delaymsec)                                                           // CLOCK Show LEDs, wait (if selftest active), then clear.
void Selftest(int Delayms)                                                                  // CLOCK Run self-test sequence with given delay per word.
void Selftest(void)                                                                         // CLOCK Run self-test sequence with given delay per word.
void Displaytime(void)                                                                      // CLOCK Display current time on LED matrix.
void BlinkUUR(int NoofBlinks, int Delayms)                                                  // CLOCK Blink UUR / O'CLOCK (NL/UK/DE/FR).
void BlinkHETISWAS (int NoofBlinks, int Delayms)                                            // CLOCK Blink HET IS WAS / ES IST WAR.
void BlinkTWAALF(int NoofBlinks, int Delayms)                                               // CLOCK Blink TWAALF / TWELVE / ZWOLF.
void RotPressOne(void)                                                                      // CLOCK Rotary press 1: acknowledge hour-change mode (blinks UUR).
void RotPressTwo(void)                                                                      // CLOCK Rotary press 2: acknowledge hour-change mode (blinks HET IS WAS).
void RotPressThree(void)                                                                    // CLOCK Rotary press 3: acknowledge brightness mode (blinks TWAALF).
void Demomode(void)                                                                         // CLOCK Demo mode — step through minutes at speed.
void FireMode(void)                                                                         // CLOCK Fire animation on LED matrix.
uint8_t clamp_sub(uint8_t val, uint8_t sub)                                                 // FIRE Subtract with clamp to zero.
uint8_t clamp_add(uint8_t val, uint8_t add)                                                 // FIRE Add with clamp to 255.
void HeatColor(uint8_t temperature, uint8_t &r, uint8_t &g, uint8_t &b)                     // FIRE Map heat value to RGB colour.
uint16_t XY(uint8_t x, uint8_t y)                                                           // FIRE Map 2D matrix coordinates to LED strip index.
void Fire2023_2D()                                                                          // FIRE 2D fire simulation logic.
void Dutch(void)                                                                            // CLOCK Dutch display — NL144 / NL92 clock.
void Dutch(void)                                                                            // CLOCK Dutch display — NL144 / NL92 clock.
void English(void)                                                                          // CLOCK English display — FOURLANGUAGECLOCK.
void German(void)                                                                           // CLOCK German display — FOURLANGUAGECLOCK / DE144.
void French(void)                                                                           // CLOCK French display — FOURLANGUAGECLOCK.
void DitLeHeure(void)                                                                       // CLOCK French helper — determine "heure/heures".
void Dutch(void)                                                                            // CLOCK Dutch display — NL144 / NL92 clock.
void English(void)                                                                          // CLOCK English display — FOURLANGUAGECLOCK.
void German(void)                                                                           // CLOCK German display — FOURLANGUAGECLOCK / DE144.
void French(void)                                                                           // CLOCK French display — FOURLANGUAGECLOCK.
void DitLeHeure(void)                                                                       // CLOCK French helper — determine "heure/heures".

// Fibonacci.h  (compiled only for FIBONACCI builds)
void PrintDisplayChoice(bool PrintIt)                                                       // COMMON Print display choice from Fibonacci.h's own QchoiceNames[] (Mondriaan1, RGB, Pastel, ...).
void PrintDisplayChoice()                                                                   // COMMON Print display choice (default: print it).
void RefreshOwnColours(void)                                                                // FIBONACCI Load the Q3 'Own' palette from Mem colours.
void Displaytime(void)                                                                      // CLOCK Say the time and load the LEDs.
void LEDsetTime(byte hours, byte minutes)                                                   // FIBONACCI Light the cells for the given time.
void MakeFibonacciList(byte Value)                                                          // FIBONACCI Build the list of Fibonacci cells representing a value (0-12).
void MakeChronoList(byte Hours, byte Minutes,byte Seconds)                                  // FIBONACCI Build the chrono (digit) display list.
void setPixel(byte pixel, uint32_t kleur)                                                   // FIBONACCI Set a Fibonacci cell (group of LEDs) to a colour.
void SetSecondColour(void)                                                                  // CLOCK Set IS/WAS colour each second (single-language clocks). (no-op stub)
void Demomode(void)                                                                         // CLOCK Demo mode — step through minutes at speed. (no-op stub)
void FireMode(void)                                                                         // CLOCK Fire animation on LED matrix. (no-op stub)
void Selftest(int Delayms)                                                                  // CLOCK Run self-test sequence with given delay per word. (no-op stub)
void Selftest(void)                                                                         // CLOCK Run self-test with default 900 ms delay. (no-op stub)
void RotPressOne(void)                                                                      // CLOCK Rotary press 1 feedback. (no-op stub)
void RotPressTwo(void)                                                                      // CLOCK Rotary press 2 feedback. (no-op stub)
void RotPressThree(void)                                                                    // CLOCK Rotary press 3 feedback. (no-op stub)

// NoClock.h  (compiled only for NOCLOCK builds)
void Displaytime(void)                                                                      // CLOCK Say the time and load the LEDs.
void SetSecondColour(void)                                                                  // CLOCK Set IS/WAS colour each second (single-language clocks). (no-op stub)
void Demomode(void)                                                                         // CLOCK Demo mode — step through minutes at speed. (no-op stub)
void FireMode(void)                                                                         // CLOCK Fire animation on LED matrix. (no-op stub)
void Selftest(int Delayms)                                                                  // CLOCK Run self-test sequence with given delay per word. (no-op stub)
void Selftest(void)                                                                         // CLOCK Run self-test with default 900 ms delay. (no-op stub)
void RotPressOne(void)                                                                      // CLOCK Rotary press 1 feedback. (no-op stub)
void RotPressTwo(void)                                                                      // CLOCK Rotary press 2 feedback. (no-op stub)
void RotPressThree(void)                                                                    // CLOCK Rotary press 3 feedback. (no-op stub)
void PrintDisplayChoice(bool PrintIt)                                                       // COMMON Print display choice. (no-op stub, always "None")
void PrintDisplayChoice()                                                                   // COMMON Print display choice (default: print it). (no-op stub)

// ClockFaces.h

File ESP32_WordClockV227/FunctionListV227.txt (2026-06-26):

// ============================================================
// ESP32_WordClockV227 — Function List
// ============================================================

// ESP32_WordClockV227.ino
void setup()                                                                                // ARDUINO Setup.
void loop()                                                                                 // ARDUINO Loop.
void CheckDevices(void)                                                                     // COMMON Check connected input devices.
void EverySecondCheck(void)                                                                 // COMMON Update routine performed every second.
void EveryMinuteUpdate(void)                                                                // COMMON Update routine performed every minute.
void EveryHourUpdate(void)                                                                  // COMMON Update routine performed every hour.
void EveryDayUpdate(void)                                                                   // COMMON Update routine performed every day.
void UpdateStatusLEDs(bool Toggle)                                                          // COMMON Update the status LEDs on the PCB.
void SetStatusLED(int Red, int Green, int Blue)                                             // COMMON Control the RGB status LEDs on the Nano ESP32.
void SetNanoLED13(int intensity)                                                            // COMMON Control orange LED D13 on the Arduino.
void SetPCBLED09(int intensity)                                                             // COMMON Control LED D09 on the PCB.
void SetPCBLED10(int intensity)                                                             // COMMON Control LED D10 on the PCB.
void SerialCheck(void)                                                                      // COMMON Check for serial input.
void InitResetpin(void)                                                                     // COMMON Initialise reset pin when installed.
void CheckResetPin(void)                                                                    // COMMON Check reset button on RST_PIN.
void Reset(void)                                                                            // COMMON Reset to default settings. BLE On, WIFI NTP Off.
void ResetCredentials(void)                                                                 // COMMON Reset WIFI/NTP/BLE credentials to empty.
void Tekstprint(char const *tekst)                                                          // COMMON Print to Serial, BLE and log.
void Tekstprintln(char const *tekst)                                                        // COMMON Print with newline to Serial, BLE and log.
void TekstSprint(char const *tekst)                                                         // COMMON Print for debugging in serial monitor.
void TekstSprintln(char const *tekst)                                                       // COMMON Print with newline for debugging.
void Tekstprintf(const char* fmt, ...)                                                      // COMMON Formatted print.
void Tekstprintlnf(const char* fmt, ...)                                                    // COMMON Formatted print with newline.
void WTekstappend(char const *tekst, char const *prefix, char const *suffix, bool newline)  // COMMON Append text to HTML info buffer.
void WTekstprintln(char const *tekst)                                                       // COMMON Append text with newline to HTML info buffer.
void WTekstprintln(char const *tekst, char const *prefix, char const *suffix)               // COMMON Append text with prefix/suffix to HTML info buffer.
void WTekstprint(char const *tekst)                                                         // COMMON Append text without newline to HTML info buffer.
void WTekstprint(char const *tekst, char const *prefix, char const *suffix)                 // COMMON Append text with prefix/suffix without newline.
int SConstrainInt(String s,byte first,byte last,int low,int up)                             // COMMON Constrain substring integer to range.
int SConstrainInt(String s,byte first,int low,int up)                                       // COMMON Constrain substring-to-end integer to range.
void InitStorage(void)                                                                      // COMMON Init and check contents of flash storage.
void StoreStructInFlashMemory(void)                                                         // COMMON Store Mem struct in flash storage.
void StoreIRRemoteInFlashMemory(void)                                                       // COMMON Save IR remote settings to flash.
void GetStructFromFlashMemory(void)                                                         // COMMON Load Mem struct from flash storage.
void GetIRRemoteFromFlashMemory(void)                                                       // COMMON Load IR remote settings from flash.
const char* SoftwareName(void)                                                              // COMMON Return software version string.
void SWversion(void)                                                                        // COMMON Print version info (short menu default).
void SWversion(bool Small)                                                                  // COMMON Print version info, Small=true for short menu.
void PrintLine(byte Lengte)                                                                 // COMMON Print a divider line of n underscores.
void CheckMCURestartCounter(void)                                                           // COMMON Check and reset MCU restart counter after stable run.
void ReworkInputString(String InputString)                                                  // COMMON Process input from Serial, BLE or web page.
bool parseColourInput(const String& InputString, int len, uint32_t& Color)                  // COMMON Parse hex colour input string.
void PrintDisplayChoice(void)                                                               // COMMON Print current display choice.
void PrintDisplayChoice(bool PrintIt)                                                       // COMMON Print display choice, optionally suppress output.
void PrintTimeInputMethod(byte Im)                                                          // COMMON Print current time input method.
void PrintMem(void)                                                                         // COMMON Print all Mem struct values.
void StoredStartHeaps(void)                                                                 // COMMON Print heap usage (non-storing call).
void StoredStartHeaps(bool Store)                                                           // COMMON Print or store heap usage.
void PrintHeaps(void)                                                                       // COMMON Print current heap memory usage.
int ReadLDR(void)                                                                           // COMMON LDR reading scaled to 0–255.
void ReadAndAverageLDR(void)                                                                // CLOCK Read and average LDR brightness (clean=false).
void ReadAndAverageLDR(bool clean)                                                          // CLOCK Read and average LDR; clean=true resets accumulators.
void DimLeds(bool print)                                                                    // CLOCK Update LED brightness from LDR reading.
void Dlay(uint32_t ms)                                                                      // LED Interruptible delay used during LEDtest; polls CheckDevices and aborts on StopTest.
void LEDtest(void)                                                                          // CLOCK LED test — light up all LEDs; interruptible by a second Y command.
void ColorLeds(char const *Tekst, int FirstLed, int LastLed, uint32_t RGBWColor)            // LED Set colour for a range of LEDs and print label.
void ColorLed(int Lednr, uint32_t RGBWColor)                                                // LED Set colour for a single LED.
void LedsOff(void)                                                                          // LED Clear all LEDs (ClearOff=false).
void LedsOff(bool ClearOff)                                                                 // LED Clear LED display; ClearOff=true also clears background.
void ShowLeds(void)                                                                         // LED Push LED data to strip.
void SetBrightnessLeds(byte Bright)                                                         // LED Set brightness of LED strip.
void Stripfill(uint32_t RGBWColor, int FirstLed, int NoofLEDs)                              // LED Fill a range of LEDs with one colour.
uint32_t StripGetPixelColor(int Lednr)                                                      // LED Get the colour of one LED.
void LEDstartup(uint32_t LEDColour)                                                         // LED Show startup colour on LEDs and sync status LED.
void FixDimmedLetterForStrip(uint32_t &colour)                                              // LED Adjust dimmed letter colour for LED strip type.
uint32_t HSVToRGB(double H, double S, double V)                                             // LED Convert HSV to RGB (H 0–360, S/V 0–1).
uint32_t FuncCRGBW(uint32_t Red, uint32_t Green, uint32_t Blue, uint32_t White)             // LED Compose RGBW colour value.
void ClearScreen(void)                                                                      // DISPLAY Clear the LED display.
uint32_t Wheel(byte WheelPos)                                                               // DISPLAY Colour wheel: r→g→b→r transition.
void StartLeds(void)                                                                        // DISPLAY Initialise LED strip for WS2812 or SK6812.
void ChangeRandomDisplay(void)                                                              // DISPLAY Change to next random display choice.
void RainbowCycle(uint8_t wait)                                                             // DISPLAY Rainbow cycle animation (interruptible via Dlay).
void WhiteOverRainbow(uint32_t wait, uint8_t whiteSpeed, uint32_t whiteLength)              // DISPLAY White over rainbow animation (interruptible via Dlay).
void Zet_Pixel(byte Cijfer, byte Pos_X, byte Pos_Y)                                         // DISPLAY Place digit 0–9 in matrix display.
void TimePlaceDigit(byte uur, byte minuut)                                                  // DISPLAY Show time as four digits in display.
void WriteLightReducer(int amount)                                                          // CLOCK Increase or decrease brightness slope value.
void InitTimeSystem(void)                                                                   // TIME Initialise time system (DS3231 + NTP + internal RTC).
void SetSystemTimeToCompileTime(void)                                                       // TIME Set system time to compile time.
time_t GetTijd(bool printit)                                                                // TIME Get current time from best available source.
DateTime GetLocalDateTime(void)                                                             // TIME Return local time as RTClib DateTime.
bool GetNTPtime(bool printit)                                                               // NTP Get and print NTP time for configured timezone.
bool IsDS3231I2Cconnected(void)                                                             // DS3231 Check for I2C connection.
float GetDS3231Temp(void)                                                                   // DS3231 Read temperature from DS3231.
void SetDS3231Time(void)                                                                    // DS3231 Write ESP32 time to DS3231.
void GetDS3231Time(bool printit)                                                            // DS3231 Read time from DS3231 module.
const char* PrintRTCTime(void)                                                              // RTC Return time string as dd-mmm-yy hh:mm:ss.
void PrintTimeHMS(void)                                                                     // RTC Print time hh:mm:ss with linefeed.
void PrintTimeHMS(byte format)                                                              // RTC Print time in specified format.
void SetRTCTime(void)                                                                       // RTC Set ESP32 internal RTC from global timeinfo struct.
void SetSystemTime(time_t t)                                                                // RTC Set RTC using Unix timestamp.
void PrintAllClockTimes(void)                                                               // CLOCK Print all available time sources.
uint32_t HexToDec(const String& hexString)                                                  // COMMON Convert hex string to uint32.
void SendMessageBLE(std::string Message)                                                    // BLE Send message via BLE in packets of 20 chars.
void StartBLEService(void)                                                                  // BLE Start BLE UART service.
void DisconnectBLE(void)                                                                    // BLE Disconnect BLE client.
void CheckBLE(void)                                                                         // BLE Check BLE input and process string.
void SendMessageTimeReceiver(const char* msg)                                               // BLE Send message to Time Receiver client.
void ReconnectTimeReceiver(void)                                                            // BLE Reconnect to Time Receiver device.
void StartTimeReceiverScan(void)                                                            // BLE Start scanning for Time Receiver device.
void StopTimeReceiver(void)                                                                 // BLE Stop Time Receiver and clean up.
void CheckTimeReceiverClient(void)                                                          // BLE Check Time Receiver client connection and data.
void WiFiEvent(WiFiEvent_t event)                                                           // WIFI Handle WIFI events.
bool CheckforWIFINetwork(void)                                                              // WIFI Scan for configured WIFI network (print=true).
bool CheckforWIFINetwork(bool PrintIt)                                                      // WIFI Scan for configured WIFI network, optionally silent.
void ScanWIFI(void)                                                                         // WIFI Scan and print list of available WIFI networks.
void ConnectWIFI(void)                                                                      // WIFI Connect to WIFI router using stored SSID and password.
void CheckRestoreWIFIconnectivity(void)                                                     // WIFI Check WIFI connection and restore if lost.
bool StartWIFI_NTP(void)                                                                    // WIFI Start WIFI connection and NTP service.
void NTPnotify(struct timeval* tv)                                                          // NTP Callback: set ntpJustSynced flag on NTP sync.
void CheckandPrintNTPsynced(void)                                                           // NTP Check and print NTP sync confirmation.
void setTimezone(void)                                                                      // NTP Apply stored timezone to system.
void initSNTP(void)                                                                         // NTP Initialise SNTP client.
bool wait4SNTP(void)                                                                        // NTP Wait up to 2.5 s for SNTP synchronisation.
void CheckWIFIcommand(void)                                                                 // WIFI Process pending command received from web page.
void WebPage(void)                                                                          // WIFI Register all web server routes and start server.
void notFound(AsyncWebServerRequest *request)                                               // WIFI Handle unknown web page requests.
void StartAPMode(void)                                                                      // WIFI Start Access Point for entering WIFI credentials.
void wpsInitConfig(void)                                                                    // WIFI Initialise WPS configuration.
void wpsStart(void)                                                                         // WIFI Start WPS push-button connection.
void wpsStop(void)                                                                          // WIFI Stop WPS.
String wpspin2string(uint8_t a[])                                                           // WIFI Convert WPS PIN byte array to string.
void OnewireKeypad3x4Check(void)                                                            // KEYPAD Check for one-wire 3x4 keypad input.
void OnewireKeypad3x1Check(void)                                                            // KEYPAD Check for one-wire 3x1 keypad input.
void InitKeypad3x1(void)                                                                    // KEYPAD Initialise 3x1 membrane keypad.
void Keypad3x1Check(void)                                                                   // KEYPAD Read 3x1 keypad and process key press.
void InitRotaryMod(void)                                                                    // ROTARY Initialise rotary encoder.
void RotaryEncoderCheck(void)                                                               // ROTARY Check if rotary encoder is moving or pressed.
void ProcessKeyPressTurn(int encoderPos)                                                    // CLOCK Process rotary or membrane keypad input.
void Start_IRreceiver(void)                                                                 // IR Start large or tiny IR receiver.
void Init_IRreceiver(String* ButtonTempNames, byte numButtons)                              // IR Initialise IR receiver with button name mapping.
uint16_t IrReceiverDecode(void)                                                             // IR Decode received IR signal.
void ProcessLearningMode(decode_type_t protocol, uint16_t command, uint16_t address)        // IR Process signal in learning mode.
void ProcessRecognitionMode(decode_type_t protocol, uint16_t command, uint16_t address)     // IR Process signal in recognition mode.
void StartIRLearning(void)                                                                  // IR Initialise IR learning mode.
void PrintAllMappings(void)                                                                 // IR Print all learned IR button mappings.
void ResetAllIRremoteSettings(void)                                                         // IR Reset all learned IR remote settings.
int RecognizeButton(decode_type_t protocol, uint16_t command, uint16_t address)             // IR Identify which button was pressed.
void ReworkIRremoteValue(int ButtonNamesNr)                                                 // IR Process IR remote button action.
void AdjustTime(int DeltaHours, int DeltaMinutes, int DeltaSeconds)                         // IR Adjust current time by delta hours/minutes/seconds.
void ToggleIRpower(void)                                                                    // IR Toggle IR remote power state on/off.
void InitLogBuffer(void)                                                                    // LOGBUFFER Initialise circular log buffer.
void AddLog(const char* msg)                                                                // LOGBUFFER Append message to circular log buffer.
void HandleTekstPrint(AsyncWebServerRequest* request)                                       // LOGBUFFER Serve last 500 log lines to web client.
void HandleTekstDownload(AsyncWebServerRequest *request)                                    // LOGBUFFER Stream full circular log buffer to web client.
void BuildHTMLPage(bool Log)                                                                // WIFI Build HTML info page from current clock state.

// ClockLogic.h
void SetSecondColour(void)                                                                  // CLOCK Set IS/WAS colour each second (single-language clocks).
void SetColours(void)                                                                       // CLOCK Set colours each second (four-language clock).
void SelftestFlash(int Delaymsec)                                                           // CLOCK Show LEDs, wait (if selftest active), then clear.
void Selftest(int Delayms)                                                                  // CLOCK Run self-test sequence with given delay per word.
void Selftest(void)                                                                         // CLOCK Run self-test with default 900 ms delay.
void Displaytime(void)                                                                      // CLOCK Display current time on LED matrix.
void BlinkUUR(int NoofBlinks, int Delayms)                                                  // CLOCK Blink UUR / O'CLOCK (NL/UK/DE/FR).
void BlinkHETISWAS(int NoofBlinks, int Delayms)                                             // CLOCK Blink HET IS WAS / ES IST WAR.
void BlinkTWAALF(int NoofBlinks, int Delayms)                                               // CLOCK Blink TWAALF / TWELVE / ZWOLF.
void Demomode(void)                                                                         // CLOCK Demo mode — step through minutes at speed.
void FireMode(void)                                                                         // CLOCK Fire animation on LED matrix.
uint8_t clamp_sub(uint8_t val, uint8_t sub)                                                 // FIRE Subtract with clamp to zero.
uint8_t clamp_add(uint8_t val, uint8_t add)                                                 // FIRE Add with clamp to 255.
void HeatColor(uint8_t temperature, uint8_t &r, uint8_t &g, uint8_t &b)                     // FIRE Map heat value to RGB colour.
uint16_t XY(uint8_t x, uint8_t y)                                                           // FIRE Map 2D matrix coordinates to LED strip index.
void Fire2023_2D(void)                                                                      // FIRE 2D fire simulation logic.
void Dutch(void)                                                                            // CLOCK Dutch display — NL144 / NL92 clock.
void Dutch(void)                                                                            // CLOCK Dutch display — NLM1M2M3M4 minute-LED clock.
void Dutch(void)                                                                            // CLOCK Dutch display — Viertalenklok (Ulrich).
void English(void)                                                                          // CLOCK English display — FOURLANGUAGECLOCK.
void English(void)                                                                          // CLOCK English display — Viertalenklok.
void German(void)                                                                           // CLOCK German display — FOURLANGUAGECLOCK / DE144.
void German(void)                                                                           // CLOCK German display — Viertalenklok.
void French(void)                                                                           // CLOCK French display — FOURLANGUAGECLOCK.
void French(void)                                                                           // CLOCK French display — Viertalenklok.
void DitLeHeure(void)                                                                       // CLOCK French helper — determine "heure/heures".
void DitLeHeure(void)                                                                       // CLOCK French helper — Viertalenklok variant.

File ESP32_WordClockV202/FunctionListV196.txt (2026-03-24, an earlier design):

void setup()                                                                                // ARDUINO Setup.
void loop()                                                                                 // ARDUINO Loop.
void CheckDevices(void)                                                                     // COMMON Check connected input devices.
void EverySecondCheck(void)                                                                 // COMMON Update routine.
void Every100mSecCheck(void)                                                                // COMMON Update routine.
void EveryMinuteUpdate(void)                                                                // COMMON Update routine done every minute.
void EveryHourUpdate(void)                                                                  // COMMON Update routine done every hour.
void EveryDayUpdate(void)                                                                   // COMMON Update routine done every day.
void UpdateStatusLEDs(bool Toggle)                                                          // COMMON Update routine for the status LEDs.
void SetStatusLED(int Red, int Green, int Blue)                                             // COMMON Control the RGB LEDs on the Nano ESP32.
void SetNanoLED13(int intensity)                                                            // COMMON Control orange LED D13 on the Arduino.
void SetPCBLED09(int intensity)                                                             // COMMON Control the RGB LED on the PCB.
void SetPCBLED10(int intensity)                                                             // COMMON Control the RGB LED on the PCB.
void SerialCheck(void)                                                                      // COMMON check for serial input.
void Reset(void)                                                                            // COMMON Reset to default settings. BLE On, WIFI NTP Off.
void ResetCredentials(void)                                                                 // COMMON Reset to empty credential settings WIFI, NTP, BLE ON.
void Tekstprint(char const *tekst)                                                          // COMMON common print routines.
void Tekstprintln(char const *tekst)                                                        // COMMON common print routines.
void TekstSprint(char const *tekst)                                                         // COMMON common print routines.
void TekstSprintln(char const *tekst)                                                       // COMMON common print routines.
void Tekstprintf(const char* fmt, ...)                                                      // COMMON Formatted Tekst print.
void Tekstprintlnf(const char* fmt, ...)                                                    // COMMON Formatted Tekstprintln.
void WTekstappend(char const *tekst, char const *prefix, char const *suffix, bool newline)  // COMMON Print web menu page and BLE menu.
void WTekstprintln(char const *tekst)                                                       // COMMON Print web menu page and BLE menu.
void WTekstprintln(char const *tekst, char const *prefix, char const *suffix)               // COMMON Print web menu page and BLE menu.
void WTekstprint(char const *tekst)                                                         // COMMON Print web menu page and BLE menu.
void WTekstprint(char const *tekst, char const *prefix, char const *suffix)                 // COMMON Print web menu page and BLE menu.
int SConstrainInt(String s,byte first,byte last,int low,int up)                             // COMMON Constrain a string with integers.
int SConstrainInt(String s,byte first,          int low,int up)                             // COMMON Constrain a string with integers.
void InitStorage(void)                                                                      // COMMON Init and check contents of EEPROM.
void StoreStructInFlashMemory(void)                                                         // COMMON Store mem.struct in FlashStorage or SD.
void StoreIRRemoteInFlashMemory(void)                                                       // COMMON Save IR remote settings.
void GetStructFromFlashMemory(void)                                                         // COMMON Get data from FlashStorage.
void GetIRRemoteFromFlashMemory(void)                                                       // COMMON Load IR remote settings from FlashStorage.
void SWversion(void)                                                                        // COMMON Version info.
void SWversion(bool Small)                                                                  // COMMON Version info.
void PrintLine(byte Lengte)                                                                 // COMMON Print a _ line of n length.
void ReworkInputString(String InputString)                                                  // COMMON Input from Bluetooth, Serial or HTML page.
void PrintDisplayChoice()                                                                   // COMMON Print Display choice.
void PrintDisplayChoice(bool PrintIt)                                                       // COMMON Print Display choice.
void PrintTimeInputMethod(byte Im)                                                          // COMMON Print time input method.
void PrintMem(void)                                                                         // COMMON Print permanent Mem memory.
void StoredStartHeaps()                                                                     // COMMON Print memory space.
void StoredStartHeaps(bool Store)                                                           // COMMON Print memory space.
void PrintHeaps(void)                                                                       // COMMON Print memory space.
int ReadLDR(void)                                                                           // COMMON LDR reading are between 0 and 255.
void SetSecondColour(void)                                                                  // CLOCK Set second colour.
void SetColours(void)                                                                       // CLOCK Set second for 4 language clock.
void Selftest(void)                                                                         // CLOCK Set second for 4 language clock.
void Selftest(int Delayms)                                                                  // CLOCK Set second for 4 language clock.
void Displaytime(void)                                                                      // CLOCK Say the time and load the LEDs.
void DimLeds(bool print)                                                                    // CLOCK Dim the leds measured by the LDR and print values.
void Play_Lights()                                                                          // CLOCK Turn On en Off the LED's.
void BlinkUUR(int NoofBlinks, int Delayms)                                                  // CLOCK Turn On en Off the LED's.
void BlinkHETISWAS (int NoofBlinks, int Delayms)                                            // CLOCK Blink ES IST WAR.
void BlinkTWAALF(int NoofBlinks, int Delayms)                                               // CLOCK Blink ZWOLF.
void BlinkUUR(int NoofBlinks, int Delayms)                                                  // CLOCK Blink UUR.
void BlinkHETISWAS (int NoofBlinks, int Delayms)                                            // CLOCK Blink HET IS WAS.
void BlinkTWAALF(int NoofBlinks, int Delayms)                                               // CLOCK Blink TWAALF.
void ColorLeds(char const *Tekst, int FirstLed, int LastLed, uint32_t RGBWColor)            // LED Set color for LEDs in strip and print tekst.
void ColorLed(int Lednr, uint32_t RGBWColor)                                                // LED Set color for LEDs in strip and print tekst.
void LedsOff(void)                                                                          // LED Clear display settings of the LEDs.
void Laatzien(int Delaymsec)                                                                // LED Turn On and the LEDs off after Delaymsec milliseconds.
void ShowLeds(void)                                                                         // LED Push data in LED strip to commit the changes.
void SetBrightnessLeds(byte Bright)                                                         // LED Set brighness of LEDs.
void Stripfill(uint32_t RGBWColor, int FirstLed, int NoofLEDs)                              // LED Set brighness of LEDs.
uint32_t StripGetPixelColor(int Lednr)                                                      // LED Set brighness of LEDs.
void LEDstartup(uint32_t LEDColour)                                                         // LED Synchronize the colour of the LEDstrip with the Status LED.
uint32_t HSVToRGB(double H, double S, double V)                                             // LED convert HSV to RGB  h is from 0-360, s,v values are 0-1.
uint32_t FuncCRGBW( uint32_t Red, uint32_t Green, uint32_t Blue, uint32_t White)            // LED function to make RGBW colour.
void ClearScreen(void)                                                                      // DISPLAY Clear the display.
uint32_t Wheel(byte WheelPos)                                                               // DISPLAY Wheel The colours are a transition r - g - b - back to r.
void StartLeds(void)                                                                        // DISPLAY Initialyse the LEDstrip for WS2812 or SK6812 LEDs.
void ChangeRandomDisplay(void)                                                              // DISPLAY change display choice.
void RainbowCycle(uint8_t wait)                                                             // DISPLAY RainbowCycle.
void WhiteOverRainbow(uint32_t wait, uint8_t whiteSpeed, uint32_t whiteLength )             // DISPLAY WhiteOverRainbow.
void Zet_Pixel(byte Cijfer,byte Pos_X, byte Pos_Y)                                          // DISPLAY Place digits 0 - 9 in Matrix display.
void TimePlaceDigit(byte uur, byte minuut)                                                  // DISPLAY Time in four digits in display.
void WriteLightReducer(int amount)                                                          // CLOCK In- or decrease light intensity value i.e. Slope.
void InitTimeSystem(void)                                                                   // TIME Initialize time system (DS3231 + NTP + internal RTC).
void SetSystemTimeToCompileTime(void)                                                       // TIME Set system time to compile time using basic functions.
time_t GetTijd(bool printit)                                                                // TIME Get current time from best available source.
DateTime GetLocalDateTime()                                                                 // NTP Return local time as RTClib DateTime.
bool GetNTPtime(bool printit)                                                               // NTP print the NTP time for the timezone set.
bool IsDS3231I2Cconnected(void)                                                             // DS3231 check for I2C connection.
float GetDS3231Temp(void)                                                                   // DS3231 temperature.
void SetDS3231Time(void)                                                                    // DS3231 RTC ESP32 -> DS3231.
void GetDS3231Time(bool printit)                                                            // DS3231 reads time in module DS3231.
void PrintTimeHMS()                                                                         // RTC Fill sptext with time.
void PrintTimeHMS(byte format)                                                              // RTC Fill sptext with time.
void SetRTCTime(void)                                                                       // RTC Set time in ESP32 using global timeinfo struct.
void SetSystemTime(time_t t)                                                                // RTC Set RTC time using Unix timestamp.
void PrintAllClockTimes(void)                                                               // CLOCK Print all the times available.
uint32_t HexToDec(const String& hexString)                                                  // CLOCK Convert Hex to uint32.
void Demomode(void)                                                                         // CLOCK Demo mode.
void FireMode(void)                                                                         // CLOCK Fire display on MATRIX_HEIGHT MATRIX_WIDTH.
uint8_t clamp_sub(uint8_t val, uint8_t sub)                                                 // FIRE Utils.
uint8_t clamp_add(uint8_t val, uint8_t add)                                                 // FIRE Utils.
void HeatColor(uint8_t temperature, uint8_t &r, uint8_t &g, uint8_t &b)                     // FIRE Utils.
uint16_t XY(uint8_t x, uint8_t y)                                                           // FIRE Utils.
void Fire2023_2D()                                                                          // FIRE ==== Fire Logic ====.
void Dutch(void)                                                                            // CLOCK Dutch clock display for NL144 & NL92 clock.
void Dutch(void)                                                                            // CLOCK Dutch clock display for NLM1M2M3M4 clock.
void English(void)                                                                          // CLOCK English clock display.
void German(void)                                                                           // CLOCK German clock display.
void French(void)                                                                           // CLOCK French clock display.
void DitLeHeure(void)                                                                       // CLOCK French clock display.
void SendMessageBLE(std::string Message)                                                    // BLE SendMessage by BLE Slow in packets of 20 chars.
void StartBLEService(void)                                                                  // BLE Start BLE Service.
void DisconnectBLE(void)                                                                    // BLE Disconnect BLE Service.
void CheckBLE(void)                                                                         // BLE CheckBLE input and rework string.
void SendMessageTimeReceiver(const char* msg)                                               // BLE TimeReceiver client.
void ReconnectTimeReceiver()                                                                // BLE TimeReceiver Reconnect time receiver.
void StartTimeReceiverScan(void)                                                            // BLE TimeReceiver Start Time Receiver scan.
void StopTimeReceiver()                                                                     // BLE TimeReceiver Stop Time Receiver.
void CheckTimeReceiverClient(void)                                                          // BLE TimeReceiver Check TimeReceiver Client.
void WiFiEvent(WiFiEvent_t event)                                                           // WIFI WIFIEvents.
void ScanWIFI(void)                                                                         // WIFI Scan for WIFI stations and print a list of networks found.
void ConnectWIFI(void)                                                                      // WIFI Check for WIFI router SSID and password.
void CheckRestoreWIFIconnectivity(void)                                                     // WIFI Check if WIFI is still connected and if not restore it.
bool StartWIFI_NTP(void)                                                                    // WIFI Start WIFI connection and NTP service.
void NTPnotify(struct timeval* tv)                                                          // NTP functions.
void CheckandPrintNTPsynced(void)                                                           // NTP functions.
void setTimezone()                                                                          // NTP functions.
void initSNTP()                                                                             // NTP functions.
bool wait4SNTP()                                                                            // NTP Get a NTP time and wait max 2.5 sec.
void CheckWIFIcommand(void)                                                                 // WIFI Check for a Pending command received from the web page.
void WebPage(void)                                                                          // WIFI WEBPAGE.
void notFound(AsyncWebServerRequest *request)                                               // WIFI WEBPAGE.
void StartAPMode(void)                                                                      // WIFI WEBPAGE Login credentials Access Point page with 192.168.4.1.
void wpsInitConfig()                                                                        // WIFI WPS functions.
void wpsStart()                                                                             // WIFI WPS functions.
void wpsStop()                                                                              // WIFI WPS functions.
String wpspin2string(uint8_t a[])                                                           // WIFI WPS functions.
void OnewireKeypad3x4Check(void)                                                            // KEYPAD check for Onewire Keypad input.
void OnewireKeypad3x1Check(void)                                                            // KEYPAD check for Onewire Keypad input with 5V and 1.1, 4.7, 4.7, 4.7 kOhm resistors.
void Keypad3x1Check(void)                                                                   // KEYPAD 3x1 Init.
void RotaryEncoderCheck(void)                                                               // KY-040 ROTARY check if the rotary is moving.
void ProcessKeyPressTurn(int encoderPos)                                                    // CLOCK KY-040 Rotary or Membrane 3x1 processing input.
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

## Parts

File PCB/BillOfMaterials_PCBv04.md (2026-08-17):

# Bill of Materials — Nano ESP32 Wordclock PCB (V04)

| Qty | Component | Value / Spec | Designators |
|---|---|---|---|
| 1 | Arduino Nano ESP32 | — | main board |
| 3 | Resistor | 470 Ω, ±5% | Before RGB(W) LED-strip and LED 3mmm |
| 3 | Resistor | 10 kΩ, ±5% | LDR, 2 optional for I2C|
| 1 | Electrolytic capacitor | 1000 µF (1 mF), 16 V | 1mF |
| 1 | Electrolytic capacitor | 10 µF | 10uF |
| 1 | LDR | GL5516 | LDR |
| 1 | Rotary Encoder or Membrane keyboard | KY-034 | Rotary |
| 1 | RTC-module | DS3231 | RTC-clock |
| 1 | RGB(W) LED-strip | ES2812 or SK6812 | LED-strip |
| 2 | Diode | 1N5817 (label) | 1N5817 |
| 1 | LED, 3 mm | Red (633 nm) | D9 |
| 1 | LED, 3 mm | Yellow (592 nm) | D10 |
| 1 | IC | 74AHCT125 | Level shifter |
| 2 | Screw terminal, 2-pin, 3.5 mm pitch | POWER | J1, J2 |
| 2 | Female pin header, 15-pin, 0.1" | Connector for Arduino Nano ESP32 | Nano ESP32 |
| 1 | Female pin header, 6-pin, 0.1" | DS3231 RTC module (GND, 5V, SDA, SCL wired to Arduino I2C) | RTC-clock |
| 1 | Female pin header, 5-pin, 0.1" | Rotary encoder connector | Rotary |
| 1 | Female pin header, 3-pin, 0.1" | DCF77 receiver connector | DCF |
| 1 | Female pin header, 3-pin, 0.1" | optional 3.3 V regulator (GND, 5V, input-GND) | AMS1117 3v3 |
| 1 | Male pin header, 4-pin, 0.1" | For connector 5V to Vin or USB|  |
| 1 | Male pin header, 3-pin, 0.1" | All 3 pins tied to 5V | RTCclock12 |
| 1 | Male pin header, 3-pin, 0.1" | All 3 pins tied to GND | RTCclock13 |
| 1 | Female pin header, 3-pin, 0.1" | GND, GND, and one leg of R5 | RTCclock6 |
| 1 | Female pin header, 2-pin, 0.1" | LDR (light sensor) connector | LDR |
| 1 | Female pin jumper, 2-pin, 0.1" | Select 5V to Vin or to USB 5V | Power shunt|
| 1 | Male pin header, 3-pin, 0.1" | Arduino TX/RX + GND | TX-RX |

## Notes 

- **Diodes** are labeled "1N5817" on the board, but the underlying Fritzing generic part's "part number" metadata field says "1N4001". These are different diode types (1N5817 is a Schottky, 1N4001 is a standard rectifier) 
— "1N4001" has a voltage drop op 0.7V, "1N5817" of 0.45V. The "1N5817" is preferred

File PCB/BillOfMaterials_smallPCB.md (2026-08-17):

# Bill of Materials — Nano ESP32 Wordclock small PCB (V03)

| Qty | Component | Value / Spec | Designators |
|---|---|---|---|
| 1 | Arduino Nano ESP32 | — | main board |
| 1 | LDR | GL5516 | LDR |
| 1 | Rotary Encoder or Membrane keyboard | KY-034 | Rotary |
| 1 | RTC-module | DS3231 | RTC-clok |
| 1 | RGB(W) LED-strip | ES2812 or SK6812 | LED-strip |
| 1 | Resistor | 470 Ω, ±5% | RGB(W) LED-strip |
| 1 | Resistor | 10 kΩ, ±5% | LDR |
| 1 | Electrolytic capacitor | 1000 µF (1 mF), 16 V | Near Power |
| 1 | Diode | 1N5817 | near Power |
| 1 | IC | 74AHCT125 | Level shifter |
| 1 | Screw terminal, 2-pin, 3.5 mm pitch | — | Power |
| 2 | Female pin header, 15-pin, 0.1" | Connector for Arduino Nano ESP32 | Nano ESP32 |
| 1 | Female pin header, 6-pin, 0.1" | DS3231 RTC module (GND, 5V, SDA, SCL wired to Arduino I2C) | RTC-clock |
| 1 | Female pin header, 5-pin, 0.1" | Rotary encoder connector | Rotary |
| 1 | Female pin header, 2-pin, 0.1" | LDR (light sensor) connector | LDR |

## Notes 

- **Diodes** are labeled "1N5817" on the board, but the underlying Fritzing generic part's "part number" metadata field says "1N4001". These are different diode types (1N5817 is a Schottky, 1N4001 is a standard rectifier) 
— "1N4001" has a voltage drop op 0.7V, "1N5817" of 0.45V. The "1N5817" is preferred

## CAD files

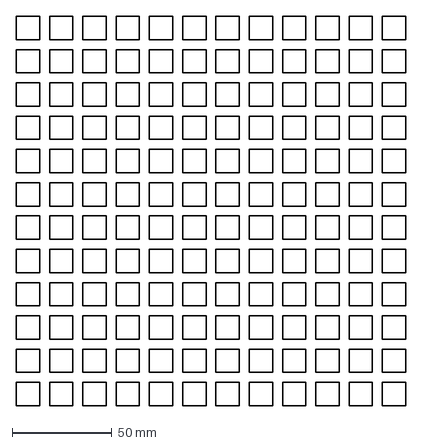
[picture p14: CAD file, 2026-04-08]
DXFwordplates/Klok.25cm.12x12.gat.patroon.dxf
195.0 x 195.0 mm

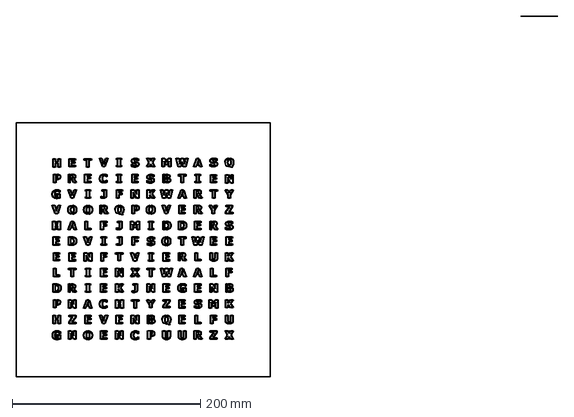
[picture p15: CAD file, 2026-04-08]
DXFwordplates/KLok25cm.tekst.dxf
576.1 x 383.1 mm

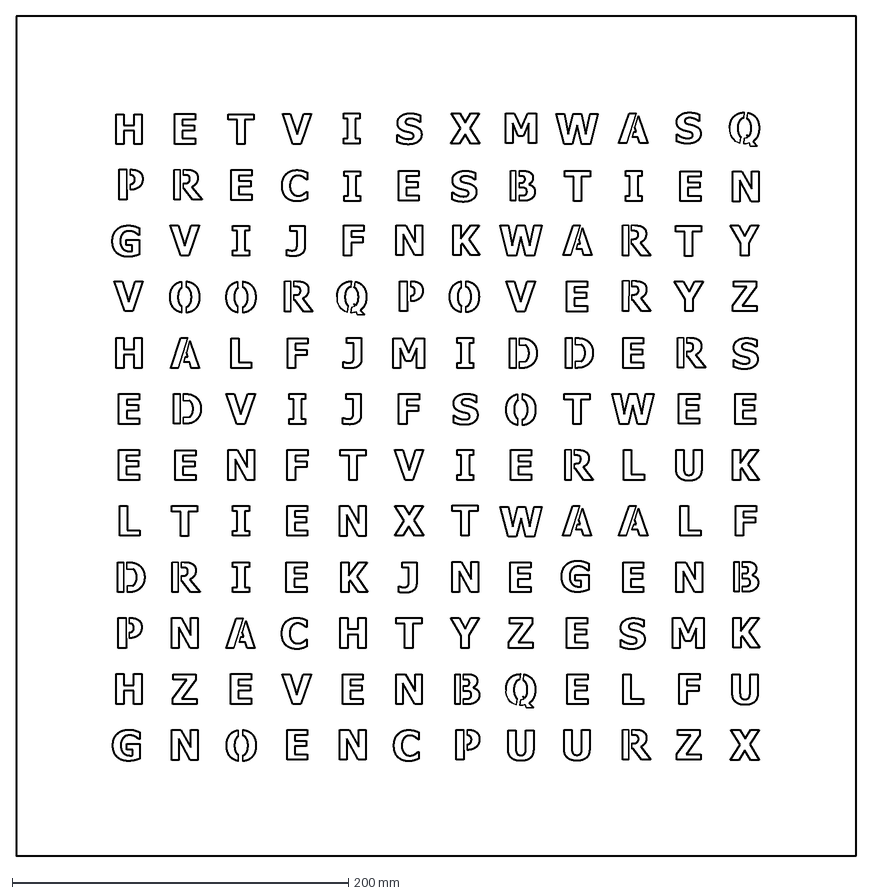
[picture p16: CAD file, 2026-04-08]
DXFwordplates/Klok50cm.tekst.dxf
500.0 x 500.0 mm

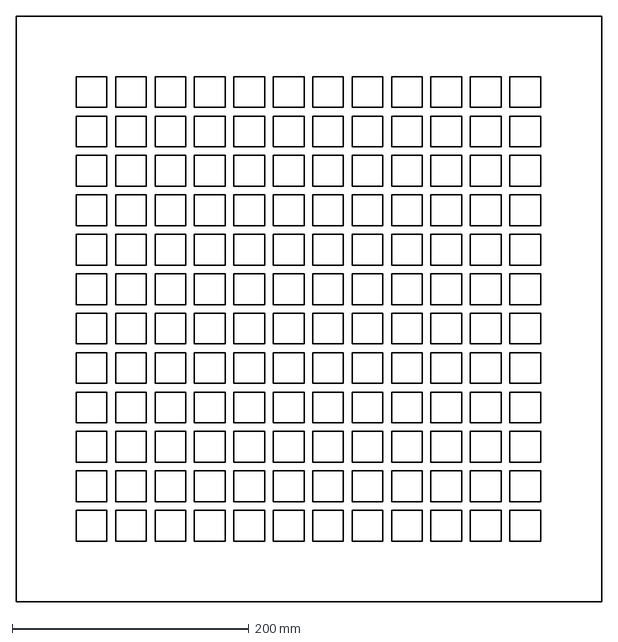
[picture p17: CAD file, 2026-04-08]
DXFwordplates/Klok50cm.12x12.gat.patroon.dxf
495.0 x 495.0 mm

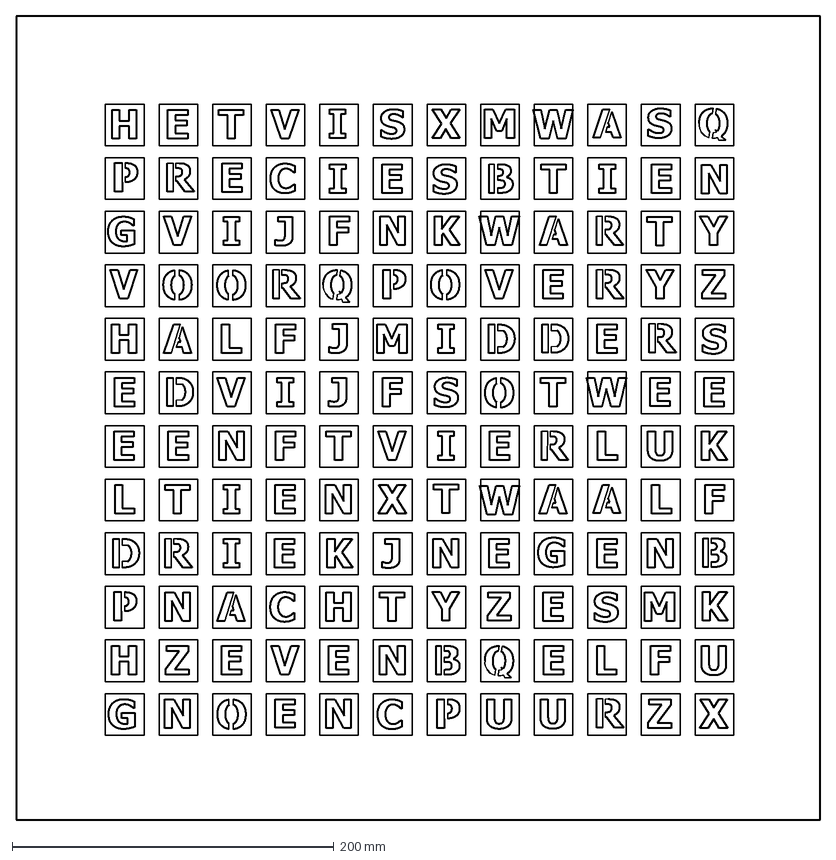
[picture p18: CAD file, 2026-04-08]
DXFwordplates/KLok50cm.gaten+tekst.dxf
500.0 x 500.0 mm

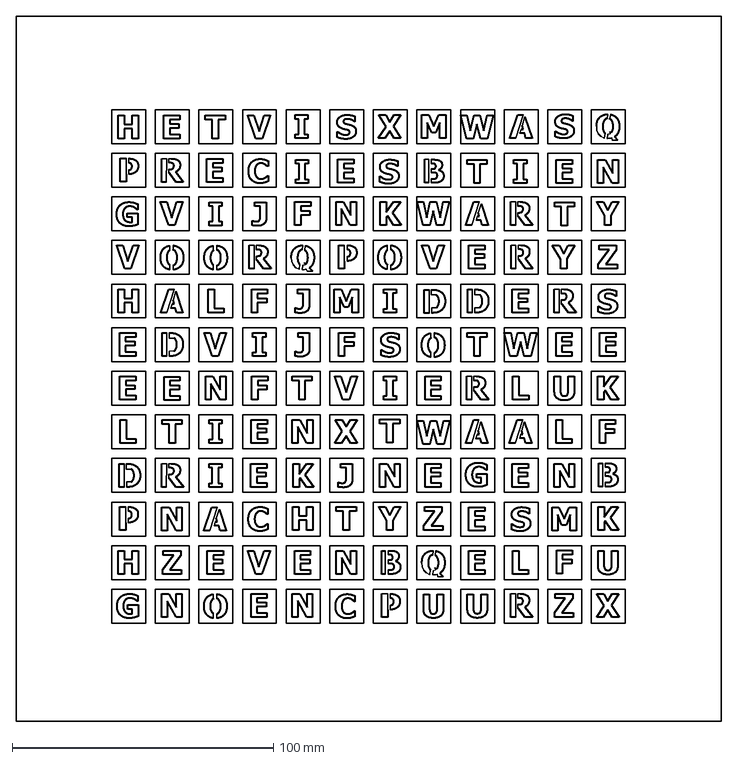
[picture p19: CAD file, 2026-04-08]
DXFwordplates/Klok25cm. gaten+tekst.dxf
270.0 x 270.0 mm

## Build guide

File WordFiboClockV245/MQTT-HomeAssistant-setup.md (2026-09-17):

# Connecting the clock to Home Assistant with MQTT

The clock appears in Home Assistant via MQTT with:

- **Controls:** a Display on/off switch, a Max Brightness slider, a Display Colour Scheme selector, a Random Display selector (off / per minute / per hour) and buttons for LED test, StatusLED on/off and Restart.
- **Sensors:** CPU temperature, LDR light reading, LED brightness (OutPhotocell) and, when a DS3231 module is installed, its temperature.
- **Diagnostics:** WiFi signal strength, uptime, free memory and the three reboot counters. The whole device shows *unavailable* in Home Assistant as soon as the clock goes offline. The clock connects to `homeassistant.local`, port 1883, and logs in with username **mqtt_user** and, as password, **the same password as your WiFi router password** (the one entered in the clock with menu option **B**).

## Setup in Home Assistant

1. Install the Mosquitto broker: **Settings → Add-ons → Add-on Store → Mosquitto broker → Install**, then **Start** (enable *Start on boot*).
2. Add the MQTT integration if it is not added automatically: **Settings → Devices & Services → Add Integration → MQTT**.
3. Create the user the clock logs in with: **Settings → People → Users → Add user**.
   - Username: `mqtt_user`
   - Password: *your WiFi router password* (identical to the password entered in the clock)
   - Tick *Can only log in from the local network*.
4. On the clock, turn MQTT on with menu option **_** and restart the clock with **@**.

The clock now appears in Home Assistant under **Settings → Devices & Services → MQTT** as device *WordClock*, with its buttons, sensors and the colour scheme selector.

## If your MQTT broker uses a different username or password

The clock's MQTT settings are not in the menu; they are set in the sketch. Find these lines near the top of the sketch and change them to match your broker:

```cpp
const char* MQTT_SERVER   = "homeassistant.local";   // or the IP address of your broker, e.g. "192.168.1.10"
const uint16_t MQTT_PORT  = 1883;
const char* MQTT_USER     = "mqtt_user";             // your MQTT username
const char* MQTT_PASSWORD = Mem.Password;            // uses the WiFi password. Replace with your own, e.g. "MySecret123"
```

To use a password that differs from the WiFi password, replace `Mem.Password` with your password between double quotes:

```cpp
const char* MQTT_PASSWORD = "MySecret123";
```

Then compile and upload the sketch again.

> **Note:** as long as `MQTT_PASSWORD = Mem.Password` is used, changing the WiFi password in the clock (menu option **B**) also changes the password the clock uses for MQTT. Keep the `mqtt_user` password in Home Assistant identical to the WiFi password, or set a fixed password as shown above.

## How the MQTT discovery works

Home Assistant does not need any configuration for the clock because the clock announces its own entities. This is called **MQTT Discovery**: for every entity the clock publishes one JSON message to a special config topic

```
homeassistant/<type>/<deviceId>/<key>/config
```

where `<type>` is `sensor`, `button`, `switch`, `number` or `select`, and `<deviceId>` is the BLE name of the clock in lower case (spaces replaced by `_`), for example `wordclock`. Home Assistant listens to `homeassistant/#`, reads the JSON and creates the entity. The JSON never contains measurements — it only tells Home Assistant *where* the data will appear and *how* to send commands. The examples below assume the device id `wordclock`.

### Sensor

Published to `homeassistant/sensor/wordclock/rssi/config`:

```json
{
  "name": "WiFi Signal",
  "state_topic": "wordclock/rssi",
  "unit_of_measurement": "dBm",
  "device_class": "signal_strength",
  "entity_category": "diagnostic",
  "availability_topic": "wordclock/status",
  "state_class": "measurement",
  "unique_id": "wordclock_rssi",
  "device": { "identifiers": ["wordclock"], "name": "WordClock",
              "manufacturer": "EdNieuw", "model": "WordClock" }
}
```

- **state_topic** — Home Assistant subscribes here; whatever the clock publishes there (e.g. `-67`) becomes the sensor value.
- **unit_of_measurement / device_class** — Home Assistant picks the right icon and formatting. `device_class` must come from Home Assistant's fixed list (`temperature`, `signal_strength`, `duration`, `data_size`, …).
- **state_class: measurement** — keeps min/mean/max history in Home Assistant's long-term statistics.
- **entity_category: diagnostic** — moves the entity to the *Diagnostic* box on the device page. Used for WiFi signal, uptime, free heap and the reboot counters.
- **availability_topic** — Home Assistant also watches `wordclock/status`. The clock publishes `online` there after connecting and the broker publishes `offline` (the *Last Will*) when the clock drops off — all entities then show *unavailable* instead of stale values.
- **unique_id** — Home Assistant's bookkeeping key. As long as it stays the same, a republished config updates the *same* entity instead of creating a duplicate. Removing an entity is done by publishing an **empty** retained message to its config topic.
- **device** — all entities with the same `identifiers` are grouped under one device in Home Assistant.

### Button

The simplest entity. Instead of a `state_topic` it has:

```json
"command_topic": "wordclock/cmnd",
"payload_press": "@"
```

Pressing the button in Home Assistant publishes `@` to `wordclock/cmnd`. The clock feeds this into the same command parser used by the serial monitor, BLE and the web page — identical to typing `@`. Fire-and-forget, no state.

### Switch

A button with memory:

```json
"command_topic": "wordclock/cmnd",
"payload_on":  "O1",
"payload_off": "O0",
"state_topic": "wordclock/display",
"state_on":  "ON",
"state_off": "OFF"
```

Two directions: Home Assistant sends `O1`/`O0` as command; the clock reports the real state by publishing `ON`/`OFF` to `wordclock/display`. Because the state is reported and not assumed, the toggle in Home Assistant stays correct even when the display is switched off via the menu or the IR remote.

### Number (slider)

```json
"command_topic": "wordclock/cmnd",
"command_template": "M{{ value }}",
"state_topic": "wordclock/maxbrightness",
"min": 1, "max": 255, "step": 1
```

`{{ value }}` is a template that *Home Assistant* fills in before publishing. Sliding to 200 sends the literal string `M200` — already a valid menu command, so the clock needs no new parsing. The state topic feeds the slider position back.

### Select (dropdown)

```json
"command_topic": "wordclock/cmnd",
"state_topic": "wordclock/randomdisplay",
"options": ["Off", "Per minute", "Per hour"]
```

Home Assistant sends the chosen option back *as text*, e.g. `Per minute`. The clock translates the text to the matching menu command (`~1`, or `Qn` for the colour schemes) before executing it. The state topic must echo the exact option text back, so the clock publishes the option name, not the number.

### Two details that apply to everything

All config messages are published with **retain = true**: the broker stores them, so Home Assistant re-learns all entities immediately after a restart without the clock doing anything. And every entity shares the same `availability_topic` and `device` block, which makes the whole set behave as one device that collectively goes *unavailable* the moment the clock disappears from the network.

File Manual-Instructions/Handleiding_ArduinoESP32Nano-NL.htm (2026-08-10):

# Arduino ESP32-Nano woordklok

Een klok die de tijd in woorden weergeeft in de talen Nederlands, Engels, Frans en Duits in een grote 4-talenklok of als een ééntalige klok.

Een Arduino ESP32 Nano computer in de klok wordt gebruikt om de tijd in de klok aan te sturen en verbinding met WIFI en Bluetooth op te zetten.
De tijd wordt gesynchroniseerd met het Network Time Protocol (NTP) van het internet via een WIFI-verbinding. Daarnaast bestaat de optie om de tijd zonder WIFI of Bluetooth met draai/drukknop gelijk te zetten.
Instellingen kunnen worden beheerd met een webpagina, een PC of een Bluetooth Low Energy (BLE) seriële terminal-app die is geïnstalleerd op een telefoon, pc of tablet.

 | 
4-talenklok | Nederlandse taalklok

Cortenstaalklok

Snelle start

Zoek één van de volgende apps in de app store. De app wordt gebruikt om commando’s naar de klok te sturen.

Mocht de app niet te downloaden zijn lees dan verder hoe de WIFI aan te sluiten.

IOS iPhone/iPad/Mac | IOS iPhone/iPad/Mac | Android
 |  | 
BLE Serial Pro (https://apps.apple.com/nl/app/ble-serial-pro/id1632245655) | BLESerial nRF (https://apps.apple.com/nl/app/ble-serial-tiny/id1607862132) | Serial Bluetooth Terminal (https://play.google.com/store/apps/details?id=de.kai_morich.serial_bluetooth_terminal) (Zet timestamp uit in het menu)

 De klok is ingesteld om met WIFI de tijd te ontvangen. Als de naam van de WIFI-router en wachtwoord niet zijn ingevoerd wordt een webpagina gestart om de routergegevens in te voeren.

- Open in een telefoon of tablet bij de WIFI-instellingen het station “StartWordclock”.

- Tik als wachtwoord in: wordclock

- Open daarna de browser op het mobiel en tik in de URL: 162.168.4.1 en druk enter.

- Voer de naam en het wachtwoord van de WIFI-router die in huis gebruikt wordt.
Tip: Je kan ook de hotspot van je mobiel voor een WIFI-verbinding gebruiken.

Bluetooth app

Instellen is makkelijker met de Bluetooth app op de telefoon of tablet.

-  Open de Bluetooth app.

De IOS app toont een lijst met Bluetooth stations.
Als het te lang duurt. Druk wieltje linksboven (nRF52 is geselecteerd) en druk Done.
Bij Android druk Scan en Connect met de woordklok.

- Stuur het commando: i om het menu te zien

Tik in de letter a gevolgd door de naam van de router en druk Send. (bijv: aNAAMrouter Stuur geen extra punten of spaties.)

- Tik in de letter b gevolgd door het wachtwoord van de router en druk Send. (bijv: bGeHeim1234)

- Stuur @ om de klok te herstarten.

Of start WPS (Een knop op de router met WPS. Lees dit na in de handleiding)

- Druk de WPS-knop en stuur daarna het commando: z in de Bluetooth serial app.

- Als geen WIFI mogelijk is
Stuur de letter J in het menu met de Bluetooth app.

- Er verschijnt dan: Use DS3231 is ON. WIFI ON, NTP OFF.

- Stuur een Letter W om WIFI uit te zetten. Stuur @ om de klok te herstarten.

- Stuur de juiste tijd en datum via het menu.
(bijv stuur: T143000 voor ‘half drie’ en bijv als datum: D090625)

- 

Klein PCB-ontwerp met Rotary en DS3231 RTC bevestigd

Voor het starten
De klok ontvangt de tijd van het internet als er een WIFI-verbinding is.

Wanneer een DS3231-tijdmodule op de printplaat is bevestigd, is een internetverbinding niet vereist.

Als een draai- of drukknopknop geïnstalleerd is kan deze worden gebruikt om de tijd in te stellen.

Ook kan een infrarood afstandsbediening geïnstalleerd zijn om de tijd in te stellen.

Om verbinding te maken met het internet moet de naam van het WIFI-station en het wachtwoord in de klok-software worden ingevoerd om verbinding te kunnen maken met een WIFI-router.
De naam van het WIFI-station en het wachtwoord moeten eenmalig worden ingevoerd.
De inloggegevens worden opgeslagen in het geheugen van de microprocessor.

Een seriële terminal app op een telefoon, tablet of PC maakt bediening mogelijk zonder de klok met een USB kabel aan een PC te verbinden om de WIFI inlog-gegevens in te voeren.

De klok kan ook via een browser worden aangestuurd als er verbinding is gemaakt met WIFI.

 |  | 
BLESerial nRF | BLE Serial Pro | Serial Bluetooth-terminal

- Download een Bluetooth UART seriële terminal app op een telefoon, PC of tablet.
Voor IOS: BLE Serial Pro of BLESerial nRF.
Voor Android: Serial Bluetooth-terminal.
Voor een PC: installeer de Arduino IDE op een PC en verbind de klok via een USB-C kabel met de PC.


Arduino ESP32 Nano op de printplaat in de klok.

Eerste bediening

- Sluit de voeding van de klok aan.

Als er geen internetverbinding of Bluetooth-verbinding is, kan de klok worden bediend met de draaiknop, met drie drukknoppen, of een afstandsbediening, of met een tijdzender app op de telefoon, mits deze geïnstalleerd en geactiveerd is. Activeren gebeurd in het menu met optie H01 (draaiknop, H02 drukknoppen, H03 en H04 een IR-afstandsbediening of H05 start tijdonvanger).

Soms zit de knop in de kast gemonteerd.

- Druk op de draaiknop of de middelste knop van de drie drukknoppen.
UUR licht 3 keer op en de uren kunnen worden ingesteld door de knop te draaien of op de omhoog- of omlaag-knop te drukken op de drieknopmembraan.

- Een tweede keer drukken op de knop of de middelste knop laat
HETISWAS knipperen en de minuten kunnen worden gewijzigd.
Seconden worden ingesteld op 0. Dus om precies te zijn, zet de laatste minuut precies op 0 seconden.

- Met een derde keer drukken knippert TWAALF drie keer en kan de lichtintensiteit van de LED's worden ingesteld.

- Met een vierde keer drukken knipperen de tekens NTP en RTC drie keer. Men kan overschakelen van RTC- naar NTP-tijd.

- Negen keer drukken reset de klok naar de fabrieksinstellingen.

Met de IR-afstandsbediening kan de klok bedient worden als deze geleerd is met de klok. Met de { optie in het menu vraagt de klok om knoppen te druken die overeenkomen met de getallen 0-9 en een paar bedieningsknopen zoals POWER.

De tijdontvanger zet de klok binnen twee minuten op tijd als de iPhone app op een telefoon of iPad wordt gestart.

Via WIFI-verbinding

Als de klok voor de eerste keer gestart wordt zal een WIFI-verbinding moeten worden gemaakt.

Als er nog oude verbindingsgegevens in de klok staan voer dan 5 maal hoofdletter R in het menu (RRRRR) in om deze te wissen.

De klokinstellingen staan dan op:

SSID en password zijn leeg

Timezone:CET-1CEST,M3.5.0,M10.5.0/3

WIFI=On NTP=On BLE=On

WPS

WPS is een methode om het wachtwoord en de naam van het WIFI-station, de SSID, uit de router te krijgen..

Start WPS in de klok door Z in het menu in te voeren en start WPS op de WIFI-router. Als alles goed gaat herstart de klok en zal de tijd gelijk staan.

Accespunt in de telefoon

Bij de WIFI-verbindingen in de telefoon (tablet op PC) zal bij de router waarmee je verbonden bent een “StartWordclock” station staan.

- Verbind met het “StartWordclock” station. Gebruik als wachtwoord: wordclock

- Open een browser en tik in: 192.168.4.1 en druk enter.



- Tik in dit scherm de SSID en het password van de WIFI router in en druk Submit

Deze gegevens staan vaak onderop de router.



De klok zal herstarten en de juiste tijd weergeven.

Wanneer de Bluetooth-app op de telefoon of tablet is geïnstalleerd

Met de ‘Bluetooth serial terminal’ app kan de klok via bluetooth worden bedient met je telefoon, tablet of MacOS PC.

- Start de Bluetooth-terminal-app op de telefoon of tablet

- Klik op de verbinding met de naam 'wordclock' in de seriële terminal-app.

- Zoek de inloggegevens van uw WIFI-router.
Zoek de SSID van de router WIFI en het wachtwoord. Deze staan normaal gesproken aan de onderkant van de WIFI-router

Typ in:

- aSSID en druk op Verzenden.
SSID is de naam van de SSID die u bijvoorbeeld op uw telefoon kunt vinden. Het is de naam waarmee WIFI is verbonden.

- bPASSWORD en druk op verzenden.
PASSWORD is het wachtwoord dat u onderop de WIFI-router kunt vinden.

- cBLENAME (optioneel, anders heeft de klok de naam ‘Wordclock’)
De BLENAME is de naam van de klok in de BLE seriële terminal-app en in de verbonden WIFI-router.

Als de Routernaam (SSID) of het wachtwoord niet juist is zal de klok na enkele herstarts weer de Accesspunt pagina (192.168.4.1 ) in de telefoon starten.

Via deze accespuntpagina, Bluetooth of met de USB kabel kan de juiste gegevens worden ingevoerd.

Zie voor uitgebreide uitleg hoofdstuk: Bediening en instellingen van de klok.

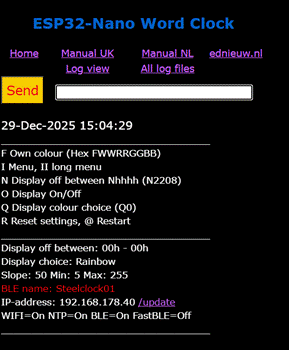
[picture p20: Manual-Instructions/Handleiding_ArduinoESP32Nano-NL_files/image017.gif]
 In de FRITZBox WIFI router is als voorbeeld de klok met de naam “SteelClock-01” met WIFI verbonden. Je kan de webpagina van de klok in een browser starten door te tikken: http://SteelClock-01 or SteelClock-01.local. De standaardnaam is: wordclock en dan wordt de url om de menupagina te starten: wordclock.local. | 

Met de optie I in het menu wordt gekozen voor een kort menu voor alledaags gebruik of voor een lang menu met optie ii (2x i) voor een uitgebreid menu met alle opties.



Door ‘Log view’ boven in de web pagina te klikken wordt de Logviewer gestart. Deze toon de laatste 500 regels die naar de seriële poort of de bluetooth app zijn geprint.
In Chrome kan (december 2025) de TAB gesplitst worden (klik met rechtermuisknop op de TAB en kies ‘split TAB’ o.i.d.) en kan zowel de webpagina als de logviewer getoond worden.
‘All log files’ toont de laatste vele duizenden regels.

Wanneer de draaiknop/rotary encoder of een drieknop membraanknop of een IR-afstandsbediening is geïnstalleerd

Een draai- , drukknoppen of afstandsbediening en de zeer nauwkeurig lopende klok DS3231 RTC zijn optioneel en niet persé nodig. De tijd wordt dan namelijk met het internet gesynchroniseerd.
Deze componenten zijn wel nodig als een klok geen WIFI kan ontvangen.

In het klokmenu kan de rotary encoder (of drie drukknoppen) aan of uit worden gezet.
Zet de rotary met de optie H00 in het menu uit als er geen draai- , drukknoppen of afstandsbediening is geïnstalleerd. (Open het langere instelmenu door ii te sturen).
Zet het gebruik van de DS3231 RTC (menuoptie J) ook uit zodat de tijd van internet wordt gebruikt.

Wanneer draaiknop/rotary encoder is geïnstalleerd

De draaiknop is 60 seconden actief na het drukken op de knop.

- Druk op de draaiknop of de middelste knop van de drie drukknoppen.
UUR licht 3 keer op en de uren kunnen worden ingesteld door de knop te draaien of op de omhoog- of omlaag-knop te drukken op de drieknopmembraan.

- Een tweede keer drukken op de knop of de middelste knop laat
HETISWAS knipperen en de minuten kunnen worden gewijzigd.
Seconden worden ingesteld op 0. Dus om precies te zijn, zet de laatste minuut precies op 0 seconden.

- Met een derde keer drukken knippert TWAALF drie keer en kan de lichtintensiteit van de LED's worden ingesteld.

- Met een vierde keer drukken knipperen de tekens NTP en RTC drie keer.
Men kan overschakelen van RTC- naar NTP-tijd.

- Negen keer drukken reset de klok naar de fabrieksinstellingen.

Wanneer drukknoppen zijn geïnstalleerd

De drukknopen zijn 60 seconden geactiveerd na het drukken van een *

Tik daarna de tijd in met 6 getallen als uummss.

Bijvoorbeeld 134500 voor kwart voor twee.

Na invoer van het 6de getal wordt de tijd vanzelf ingevoerd.

Wanneer een IR-afstandsbediening is geïnstalleerd

Zet de ontvangst met de klok aan met POWER.
Verzend met de grote afstandsbediening (H03 geactiveerd in het menu) de juiste tijd met cijfers als uummss. Dus kwart voor drie als 144500 in de middag of als 024500 in de ochtend.
Of gebruik met een kleine afstandsbediening (H04 geactiveerd in het menu) de knoppen Up en Down en CH+ en CH- om de minuten en of uren te veranderen.

Met ONOFF kan de verlichting van de klok worden uit- of aangezet.

De klokkast maken

De bouw van de klokkast met verlichting is hier te vinden:

https://ednieuw.com/Woordklok/Bouwpakket/WoordklokSK6812.htm

of hier: https://github.com/ednieuw/Arduino-ESP32-Nano-Wordclock

Bouwinstructie van een 4-talige woordklok met SK6812 LEDs in het UK, NL, DE, FR met Nano. https://github.com/ednieuw/FourLanguageClock

Compilatie en uploaden

De software draait op een Arduino Nano ESP32.

Deze software wordt met de Arduino IDE gecompileerd en naar de Nano ESP32 geüpload.

Voor elk board dat met de Arduino IDE geprogrammeerd kan worden is een compiler beschikbaar. Deze kan geselecteerd worden in het boards manager menu

Er zijn twee versies beschikbaar voor de Arduino Nano ESP32.

Eén versie, van Arduino zelf, die gebruik maakt van core versie 2. Deze versie is probleemloos in gebruik.



- Laad het bestand ESP32Arduino_WordClockV0xx.INO in de IDE

Selecteer in de sketch , ergens rond regel 50, een van de drie woordklokken door de twee schuine strepen // weg te halen.

//#define FOURLANGUAGECLOCK

#define NL144CLOCK

//#define NLM1M2M3M4L114 // NL clock with four extra LEDs for the minutes to light up

#define NL144CLOCK -> een 144 LED enkeltalige klok. Standaardtaal is Nederlands. Voor Frans, Duits en Engels kopieer de codering van de viertalige klok tussen de NL144CLOCK-definities.

#define NLM1M2M3M4L114 -> een 110 LED enkeltalige klok met 4 extra LEDs voor de minuten en een iets ander ontwerp

#define FOURLANGUAGECLOCK-> een 4-talenklok met 625 LEDs in een raster van 25 x 25 LEDs.

In de libraries.zip staan de bibliotheken om de software te compileren.
Unzip ze in de libraries-map. Deze folder staat meestal tussen folder met de sketches.

Board: Arduino Nano ESP32

Partitieschema: met FAT

Pinnummering: By GPIO-nummer (legacy)

Problemen

Als de LEDs niet gaan branden, is de kans groot dat de pinnummeringinstelling
(By GPIO-number (legacy) op By Arduino pin (default) staat.

Er is meer dan één klok geselecteerd bij de defines rond regel 50

Bluetooth werkt niet

Na versie ESP32Arduino_WordClockV060 moet NimBLE versie 2.0 worden gebruikt.

Voor versie ESP32Arduino_WordClockV060 werkt alleen NimBLE versie 1.4.3

 

Lukt het niet probeer dan de methode ‘Alternatieve softwareinstallatie’.

Alternatieve softwareinstallatie



Zoals verderop is beschreven kan software ook ‘Over the Air’ op de Nano ESP32 worden gezet.

Voordeel is dat je niet de libraries hoeft te installeren en over een paar jaar problemen hebt met niet meer compatibele libraries.

Het compileren is dan al gedaan en het bestand dat naar de Nano ESP32 geüpload wordt is dan als .bin bestand opgeslagen. Op GitHub kunnen diverse .bin-file versies worden gevonden.

https://github.com/ednieuw/Arduino-ESP32-Nano-Wordclock

- Selecteer als board de Nano ESP32 (Tools->Board-ArduinoESPboards->Arduino Nano ESP32)

- Zoek in Examples naar ArduinoOTA -> en open het programma OTAWebUpdater

- Kies Sketch->Upload of druk de upload knop links boven

- Open de seriële monitor en kijk welk IP-adres geprint wordt.
(Druk op de witte resetknop op de Nano ESP32 als er niets geprint wordt)

- Tik dit IP-adres in de URL van een browser (bijv: 192.168.0.123)

- Login met admin en met password admin

- Zoek het .bin bestand en druk update
(Bijvoorbeeld ‘ESP32Arduino_WordClockV057.inoNL114.bin’ Dit is versie V057 met instellingen voor de NL114 klok)

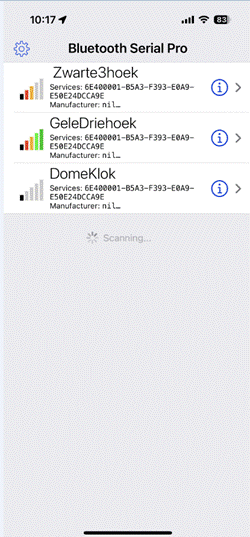
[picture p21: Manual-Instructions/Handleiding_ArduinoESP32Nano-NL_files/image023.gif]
 Bediening van de klok

Om verbinding te maken met een WIFI-netwerk moet een SSID (WIFI-naam) en wachtwoord worden ingevoerd.
Er zijn een paar methoden:
Sluit de MCU in de klok met een micro-USB- seriële kabel aan op een pc en gebruik een seriële terminal.
Gebruik een BLE- seriële terminal-app op een telefoon of tablet voor verbinding.

Voor een PC is de Serial monitor in de Arduino IDE aan te raden.
Voor IOS gebruik : BLE Serial Pro of BLESerial nRF.
Voor Android gebruik: Serial Bluetooth terminal.

Bluetooth Low Energy (BLE) kan twee soorten protocol gebruiken CC25nn of nRF52nn waarbij nn een specifiek nummer is. Deze klok gebruikt nRF52.
- Start de app en start een verbinding met de klok.

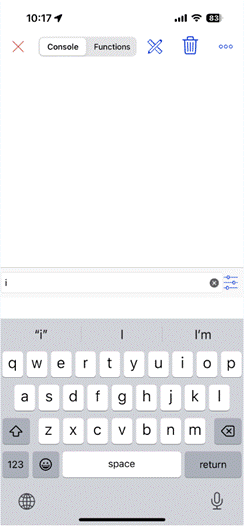
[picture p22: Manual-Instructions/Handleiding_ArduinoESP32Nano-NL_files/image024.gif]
 Sommige apps starten automatisch met een verbindingsvenster, maar voor sommige moet een verbindingssymbool worden ingedrukt. Er is waarschijnlijk één station, de woordklok, om uit te selecteren.
- Selecteer de klok in de lijst.
De app toont een venster en een regel waar opdrachten kunnen worden ingevoerd en naar de klok kunnen worden verzonden.
- Door de letter I of i voor informatie te verzenden, wordt het menu weergegeven, gevolgd door de werkelijke instellingen van verschillende voorkeuren.
Met één i wordt het korte menu getoond. Met dubbel i (ii) verschijnt een langer menu met vele instelmogelijkheden van de klok.

 In de klok zit een LED die een rode stip heeft die oplicht als het programma draait.
Een groene stip gaat branden als er een WIFI-verbinding is. Als er een Bluetooth-verbinding is, gaat er een blauwe stip in de LED branden.

In beide gevallen stuur de letter i van Informatie en het korte menu verschijnt .
Het lange menu verschijnt met ii

Voer de eerste letter in van de instelling die je wilt wijzigen, gevolgd door een code.
Sommige items schakelen alleen Aan en Uit. Zoals de W om WIFI Uit of Aan te zetten.

Om de SSID en het wachtwoord te wijzigen:
Verstuur de letter A of a gevolgd door de naam van het wifi -station en B of b gevolgd door het wachtwoord.

Amy-SSID en verstuur deze opdracht. Bijvoorbeeld AFRITZ!Box01 of aFRITZ!Box01. Hoofdletter of kleine letter maakt niet uit.

Daarna volgt de letter B met het wachtwoord.
Bmypassword en verstuur het wachtwoord.

Cbroadcastname verandert in de naam die wordt weergegeven in de Bluetooth-verbindingslijst.
Bijvoorbeeld iets als: cWoordklok

Als de lengte van de SSID en/of het wachtwoord minder dan 5 tekens is, wordt de WIFI automatisch uitgeschakeld.

Gebruik een lengte van minimaal 8 tekens voor de SSID en het wachtwoord.
Controleer in het menu (derde regel van onderen) of WIFI en NTP aan staan.

Voer @ in om de Nano ESP32 opnieuw te starten.

Deze wordt opnieuw opgestart en er wordt verbindingen gemaakt.
Soms moet de klok een tweede of derde keer worden gereset voordat hij verbinding kan maken met WIFI.
Als verbinding nog steeds niet tot stand komt controleer het ingevoerde wachtwoord.

Als WIFI is verbonden, zal de LED op de Nano ESP32 groen knipperen.

____________________________________

F Own colour (Hex FWWRRGGBB)

I Menu, II long menu

N Display off between Nhhhh (N2208)

O Display On/Off

Q Display colour choice (Q0)

R Reset settings, @ Restart

___________________________________

Display off between: 22h - 08h

Display choice: Rainbow

RandomDisplay is OFF

Slope: 30 Min: 20 Max: 255

BLE name: ESP32Test

IP-address: 192.168.178.172/update

WIFI=On NTP=On BLE=On FastBLE=Off

15/10/2025 09:08:18

___________________________________

__________________________________

A SSID B Password C BLE beacon name

D Date (D15012021) T Time (T132145)

E Timezone (E<-02>2 or E<+01>-1)

F Own colour (Hex FWWRRGGBB)

G Scan WIFI networks

H H001 rotary, H002 membrane (H000)

I Info menu, II long menu

J DS3231 RTC module On/Off

K LDR reads/sec On/Off

N Display off between Nhhhh (N2208)

O Display On/Off

P Status LED On/Off

Q Display choice (Q0) ~ Changing

R Reset settings, @ Restart

U Demo (msec) (U200) Y LED test

S Slope, L Min, M Max (S50 L5 M200)

W WIFI X NTP& Z WPS CCC BLE + Fast BLE

#nnn Selftest, RTC: ! See, & Update

) HETISWAS On/Off, ( EdSoft On/Off

Ed Nieuwenhuys Oct 2025

___________________________________

Display off between: 22h - 08h

Display choice: Rainbow

RandomDisplay is OFF

Slope: 30 Min: 20 Max: 255

SSID: FRITZ!BoxEd

BLE name: ESP32Test

IP-address: 192.168.178.172/update

Timezone:CET-1CEST,M3.5.0,M10.5.0/3

WIFI=On NTP=On BLE=On FastBLE=Off

Rotary=Off Membrane=Off DS3231=Off

WS2812 strip with 148 LEDs (switch %)

Software: ESP32_WordClockV116.ino
| Korte (i) en lange (ii) menuweergave

Standaard staat de tijdzone ingesteld op Amsterdamse tijd.
Een reset met optie R in het menu zal de tijdzone weer terugzetten naar Amsterdam.
Om een andere tijdzone in te stellen, stuurt je de tijdzone-string, voorafgegaan door het teken E of e.
Onderaan deze handleiding zijn veel tijdzones afgedrukt.
Bijvoorbeeld: als u in Australië/Sydney woont, stuurt u de string,

eAEST-10AEDT,M10.1.0,M4.1.0/3.

De klok gebruikt de zomertijd (DST) wanneer deze is verbonden met een NTP-server, maar niet wanneer de DS3231-tijdmodule wordt gebruikt

 | 
HTML-pagina | “Serial monitor”-scherm vanaf een pc

Afstandsbediening gebruiken

De klok kan zijn uitgevoerd met een infrarood (IR) ontvanger. Met een geschikte afstandsbediening kan daarmee de tijd van de klok ingesteld worden en een van de vele kleurschema’s die de klok kan tonen geselecteerd worden .

- Zet in het menu met de PC of BLE app de IR-afstandsbediening aan met H03 of H04 voor een kleine IR-afstandsbediening. Deze heeft minder codes
MIN-1, MIN+1, UUR-1, UUR+1, POWER, ONOFF

- Herstart de klok met @.

- Zend { om de klok de toetscodes van de afstandsbediening te leren.

Niet alle afstandsbedieningen zullen werken.

- De software zal vragen om de volgende toetsen te drukken.

"0", "1", "2", "3", "4", "5", "6", "7", "8", "9", "UP", "DOWN", "LEFT", "RIGHT", "POWER", "OK","ONOFF"

Zit een bepaalde toets niet op je toetsenbord kies er dan een die er op lijkt.
Kies bijvoorbeeld de knop Source als ONOFF wordt gevraagd.

Gebruikt niet dezelfde toets voor verschillende codes.

=== Starting Learning Mode ===

Please press button: 0

Learning IR started

Het is vijf over half een LDR:110= 3% 173860 l/s 12:36:40

=== Starting Learning Mode ===

Please press button: 0

Learning IR started

Het is vijf over half een LDR:110= 3% 173860 l/s 12:36:40

Remote identified - Protocol: NEC, Address: 0xBD00

✓ Learned '0' - Protocol: NEC, Command: 0x0041, Address: 0xBD00

Please press button: 1

✓ Learned '1' - Protocol: NEC, Command: 0x0015, Address: 0xBD00

Please press button: 2

✓ Learned '2' - Protocol: NEC, Command: 0x0016, Address: 0xBD00

Please press button: 3

✓ Learned '3' - Protocol: NEC, Command: 0x0017, Address: 0xBD00

Please press button: ONOFF

✓ Learned 'ONOFF' - Protocol: NEC, Command: 0x0008, Address: 0xBD00

=== Learning Complete & Saved! ===

Stored Button Mappings:

___________________________________

IR-Remote Address: 0xBD00

IR-Remote Protocol: NEC

___________________________________

0 -> Cmd: 0x0041

5 -> Cmd: 0x001A

6 -> Cmd: 0x001B

7 -> Cmd: 0x001D

8 -> Cmd: 0x001E

9 -> Cmd: 0x001F

UP -> Cmd: 0x000B

DOWN -> Cmd: 0x000F

LEFT -> Cmd: 0x0049

RIGHT -> Cmd: 0x004A

POWER -> Cmd: 0x0001

OK -> Cmd: 0x000D

ONOFF -> Cmd: 0x0008

___________________________________

=== Now in Recognition Mode ===

Only responding to remote with Address: 0xBD00

Press any learned button to test....

Press POWER to process the key presses to a time. POWER ON

Press POWER again to stop time entry. POWER OFF
With POWER OFF the digits will change the Display choice

- Druk POWERON om de tijd in te stellen.

- Toets 6 nummers in als uummss.
Bijvoorbeeld Kwart voor vier in de middag: 154500

- of gebruik UP en DOWN om een UUR hoger of lager te zetten en LEFT en RIGHT om de minuten lager of hoger te zetten.

- Druk weer op POWER om de tijdinvoer te stoppen.
Na 5 minuten gaat de POWER automatisch uit.

- Met de grote afstandsbediening kunnen de cijfertoetsen gebruikt worden om kleurscherma’s van de klok (optie Q in het menu) te veranderen.
Met de grote en kleine afstandsbediening kan met ONOFF de display worden aan- of uitgezet

Instellingen van de klok

 Instellingen van de klok kunnen bediend worden met de WIFI webpagina of Bluetooth BLE terminal app.
Wanneer de klok is verbonden met WIFI heeft deze een IP -adres ontvangen van de router waarmee deze is verbonden.
Het IP-adres staat afgedrukt in het menu.

Om het menu als een webpagina te starten moet het IP-adres van de klok in een webbrowser worden ingevoerd (bijvoorbeeld: 192.168.178.77)

of gebruik in plaats daarvan de BLE-stationsnaam gevolgd door .local als URL in de browser. (Standaard na een reset: wordclock.local)

Of gebruik een Bluetooth-verbinding:
- Open de BLE-terminal-app.
- Zoek in de app naar de klok om verbinding mee te maken en maak verbinding.

Elke app heeft zijn eigen manier om het Bluetooth-apparaat weer te geven waarmee verbinding moet worden gemaakt.

De iPhone / iPad / iMac BLE-seriële apps zijn door mij gemaakt en werken met hun standaardinstellingen.
Bij andere apps moeten de instellingen voor het verzenden en ontvangen van gegevens mogelijk worden gewijzigd. Speel met de lettergrootte en de CR- en LF-instelling totdat u
op een iPhone, iPad of iMac met de BLE-seriële app de transmissiesnelheid kunt versnellen door de optie '+ Fast BLE' te selecteren in het menu

Helaas kunnen sommige apps geen strings lezen die langer zijn dan 20 tekens en ziet u de strings afgekapt of vervormd .
Als er regels onvolledig worden geprint stuur dan '+' in om een langzamere transmissiemodus te selecteren.
Als de transmissie te vervormd is en het onmogelijk is om het teken + te verzenden, probeer dan de webpagina van de klok en verstuur een + teken.

Als alles mislukt, moet u de Arduino Nano ESP32 in de klok met een USB-C-kabel aansluiten op een pc en met de Arduino IDE een + te verzenden of stuur de letter R om de klok naar de standaardinstellingen te resetten.

De lichtintensiteit van het display aanpassen



In het menu kan de lichtintensiteit van het display met drie parameters worden geregeld:

--Instellingen voor lichtintensiteit (1-250)--

S=Helling L=Min M=Max (S80 L5 M200)

LDR Standaardwaarden worden tussen () weergegeven.

S Regelt hoe snel de lichtsterkte van de LEDs de maximale helderheid bereikt.

L Hoe helder het scherm blijft in volledige duisternis.

M de maximale helderheid van het scherm .

In de onderste helft van het menu worden de opgeslagen waarden weergegeven

Helling: 80 Min: 5 Max: 255

De klok reageert op licht met zijn LDR (lichtafhankelijke weerstand).

Wanneer het donker wordt schakelt de display niet helemaal uit maar blijft gedimd op een minimale waarde.
Met de parameter L kan de minimale helderheid worden geregeld. Met een waarde tussen 0 en 255 kan deze helderheid worden ingesteld.
L5 is de standaardwaarde.

De maximale helderheid van het display wordt geregeld met de parameter M. Ook een waarde tussen 0 en 255. Standaard staat deze maximaal op 255.
Met parameter S kan de helling worden geregeld hoe snel de maximale helderheid wordt bereikt.

 Ook deze waarden variëren tussen de 0 en 255. Standaard staat deze op 80.

Instellingen worden ingesteld door het eerste teken van een opdracht in te voeren, gevolgd door parameters indien nodig.

Bijvoorbeeld:
Om de kleur van de woorden in de klok op wit in te stellen, voer in: Q2

Om de klok tussen 22 uur en 8 uur uit te schakelen stuur: n2208

Schakel WIFI uit door een W te sturen.

Start de klok opnieuw door de letter @ te verzenden.

Reset naar standaardinstelling door R te sturen.

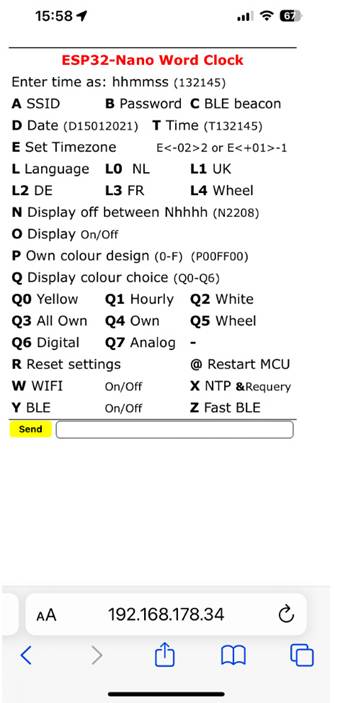
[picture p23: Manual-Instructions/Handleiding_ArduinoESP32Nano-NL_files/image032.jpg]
 | 
HTML-pagina | BLE-menu

De software updaten

De software kan 'Over The Air' worden bijgewerkt wanneer de klok is verbonden met WIFI. Het IP-adres staat in het menu.

Voer het IP-adres van de klok in, direct, zonder spatie, gevolgd door /update.

 Zoiets als dit: 192.168.178.141/update.

Of gebruik: http://BLEbroadcastname.local/update

in plaats van het IP-adres.

In dit geval: redpcbv01.local/update.
(Soms kan http:// weggelaten worden)



'Kies bestand' in het menu en selecteer het bin-bestand dat u wilt bijwerken.

Iets als: ESP32Arduino_WordClockV100.ino.bin

waarbij V100 het versienummer van de software is.

 

Gedetailleerde menubeschrijving

Met het menu kunnen veel voorkeuren worden ingesteld. Deze voorkeuren worden opgeslagen in de ESP32-opslagruimte en blijven bewaard bij stroomuitval.

Voer het eerste teken in het menu van het item in dat moet worden gewijzigd, gevolgd door de parameter.
Bijvoorbeeld N2208 om de klokverlichting tussen 22:00 en 8:00 uit te zetten.
Er is geen verschil tussen hoofdletters of kleine letters. Beide zijn OK.

Als de klok gestart wordt en verbonden is met een USC-C seriële kabel aan een PC dan wordt in de ‘serial terminal’ van de Arduino IDE de opstart loggegevens geprint.

Serial started

Rotary NOT used

Rotary available

Found I2C address: 0X57

Found I2C address: 0X68

External RTC module IS found

DS3231 RTC software started

Mem.Checksum = 25065

Stored settings loaded

LED strip is SK6812

LED strip started

BLE started

10: networks found

1: FRITZ!BoxEd -47 * -- Will connect to

2: NETGEAR_EXT -69

3: FRITZ!BoxEd -71 * -- Will connect to

4: H369A209CE1 -75 *

5: H3baas -81 *

6: H369A209CE1 -81 *

7: FRITZ!Box -82 *

8: H369A209CE1 -83 *

9: FRITZ!Box 5490 IS -83 *

10: FRITZ!Box 5490 XL -84 *

[WiFi-event] event: 0 : WiFi interface ready

[WiFi-event] event: 2 : WiFi client started

[WiFi-event] event: 4 : Connected to access point

[WiFi-event] event: 7 : Obtained IP address: 192.168.178.199

IP Address: 192.168.178.199

Web page started

WIFI started

01/01/2000 00:06:42

___________________________________

___________________________________

A SSID B Password C BLE beacon name

D Date (D15012021) T Time (T132145)

E Timezone (E<-02>2 or E<+01>-1)

F Own colour (Hex FWWRRGGBB)

G Scan WIFI networks

H H001 rotary, H002 membrane (H000)

I Info menu, II long menu

J Toggle use DS3231 RTC module

K LDR reads/sec toggle On/Off

N Display off between Nhhhh (N2208)

O Display toggle On/Off

P Status LED toggle On/Off

Q Display colour choice (Q0)

R Reset settings, @ = Reset MCU

U Demo (msec) (U200) Y LED test

--Light intensity settings (1-250)--

S Slope, L Min, M Max (S50 L5 M200)

W WIFI X NTP& Z WPS CCC BLE + Fast BLE

#nnn Selftest, RTC: ! See, & Update

Ed Nieuwenhuys April 2025

___________________________________

A SSID B Wachtwoord C BLE beacon naam
Voer de naam van de SSID en wachtwoord van de router in waarmee de klok verbonden moet worden.
De Bluetooth broadcast-naam die weergegeven wordt in de Bluetooth seriële terminal app kan gewijzigd worden.
Bijvoorbeeld: aFRITZ!Box of AFRITZ!Box .
Voer vervolgens het wachtwoord in. Bijvoorbeeld: Bwachtwoord.

Voer eventueel cBluetoothNaam in (standaard na een reset: wordclock )
Start de klok opnieuw door @ te verzenden .

CCC Door CCC of ccc in te voeren, schakelt u BLE in of uit.

Wees voorzichtig bij het uitschakelen. Als BLE uit staat, kan de klok alleen worden bediend met WIFI of de USB-seriële poort.

D Datum instellen en T Tijd instellen
Als er geen verbinding is met WIFI-tijd en er een RTC DS3231 is aangesloten, moet de datum handmatig worden ingesteld.
Voer bijvoorbeeld in: D06112022 om de datum in te stellen op 6 november 2022.

Voer bijvoorbeeld T132145 (of 132145, of t132145) in om de tijd in te stellen op 45 seconden en 21 minuten na één uur.
Datum en tijd wijzigen werkt alleen als WIFI en NTP uitgeschakeld zijn.

E Stel tijdzone E<-02>2 of E<+01>-1
Onderaan deze pagina staan de tijdzones die in 2022 worden gebruikt.
Het is een vrij ingewikkelde string en het is daarom verstandig om deze te kopiëren.
Laten we er een kiezen als u hier woont: Antarctica/Troll,"<+00>0<+02>-2,M3.5.0/1,M10.5.0/3"
Kopieer de string tussen de " "'s en verstuur deze beginnend met een 'E' of 'e' ervoor.
E<+00>0<+02>-2,M3.5.0/1,M10.5.0/3

F Eigen kleur (Hex WWRRGGBB of Fwrgb)

(Tik in een browser 0xff00ff in om op een dan te kiezen website kleuren hexadecimaal te maken)

Of als je niet met hexadecimaal kan omgaan tik na de F een decimaal getal tussen 0 en 9 voor respectievelijk Wit, Rood, Groen en Blauw.
0 is uit en 9 is 100% aan. F0900 is rood en F0009 is blauw en oranjerood F0920

Met de hexadecimale kleuren is er keuze uit 255 gradaties ipv de 10 nu.

De kleur van de woorden die in de klok worden weergegeven kunnen aangepast worden en zijn te selecteren met optie Q3 of Q4 in het menu.

Het in te voeren formaat is hexadecimaal. 0123456789ABCDEF zijn de tekens die kunnen worden gebruikt.

Het commando bestaat uit 2 cijfers voor wit gevolgd 2 cijfers voor Rood gevolgd door 2 voor Groen en eindigend met 2 cijfers voor Blauw.

Om de letters intens Groen te kleuren, voer F0000FF00 in, voorafgegaan door de letter F. Om de letters intens Rood te kleuren, voer FF0000 in, voorafgegaan door het karakter F.

F000000FF

Om intens blauw in te stellen, voer je F000000FF in.

Bijvoorbeeld: F8800FF00 is 50% wit en 100% groen.

In het kort: 00 is LED uit, 44 is 25%, 88 is 50%, BB is 75% en FF is 100%.



WS2812 LED-strips hebben geen witte LED en het commando om de wit aan te sturen geen effect.

Bij SK6812 LEDs heeft een extra witte LED (geel vlakje) naast de drie RGB LEDs.

Welke LEDs in de klok zijn gemonteerd staat onderin het lange menu (ii)
WS2812 strip with 148 LEDs (switch %)

G Scannen naar WIFI netwerken in de buurt
Door 'G' te versturen worden de beschikbare netwerken in de buurt in de Bluetooth BLE-terminal afgedrukt.

H H01 rotary H02 buttons H03/04 remote
Door 'Hnn' te verzenden wordt gekozen of een optionele draaiknop (H01), een (membraan) drukknop (H02) of een afstandsbediening wordt gebruikt om de tijd en datum in te kunnen stellen.
De interne, dan verplichte, DS3231 RTC wordt dan automatisch aangezet en de NTP tijd uit.

H03 is een grote afstandsbediening met cijfers en H04 is voor een kleine uitvoering zonder cijfers.

De software controleert dan of er een invoer plaatsvindt. Zet daarom de optie met H00 uit als de invoer niet gebruikt wordt om onbedoelde invoer te voorkomen.

Na een Reset naar fabrieksinstelling wordt het gebruik van deze instelling ongewijzigd gelaten.

H05 Time receiver On/Off

Als een special tijdzender wordt gestart kan de klok daarmee op tijd worden gezet. Met het commando H05 kan de tijdontvanger aan of uit worden gezet.
In maart 2026 zijn als tijdzender beschikbaar:

- De time sender app “BLE UART time” uit de Apple app store

- De Arduino ESP32 sketch “ESP32 Arduino communications” van mijn Github site https://github.com/ednieuw/ESP32Communications

} Learn IR remote

Om een afstandsbediening te kunnen gebruiken moet de klok eerst leren wat de infrarood-code is die een knop verzendt.
Niet alle afstandsbedieningen zullen te programmeren zijn.

Bij optie H03, de grote afstandsbediening, worden de volgende toetsen geprogrammeerd:

“0", "1", "2", "3", "4", "5", "6", "7", "8", "9, "UP", "DOWN", "LEFT", "RIGHT", "POWER", "OK","ONOFF".

Als de POWER knop niet gedrukt wordt dan selecteren de toetsen; “0", "1", "2", "3", "4", "5", "6", "7", "8", "9 de display modes. De Q codes in het menu. Q2 is bijvoorbeeld wit.

Met de "ONOFF" toets gaat de verlichting van de klok uit of aan

Als de POWER knop wordt gedrukt dan kan met de cijfertoetsen vijf minuten lang de tijd worden ingevoerd. Na vijf minuten gaat de POWER vanzelf uit om te voorkomen dat ongewenst de tijd veranderd wordt.

Voer zes getallen in + "OK".

Druk 153612 + "OK" voor 15 uur, 36 minuten en 12 seconden

Of eenvoudiger:

Met "UP", "DOWN" worden de uren verlaagd of verhoogd en

Met "LEFT", "RIGHT" worden minuten verlaagd of verhoogd.

Bij een kleine afstandsbediening (H04) werkt als volgt :

Met de "ONOFF" toets gaat de verlichting van de klok uit of aan

Druk "POWER" en daarna de toetsen MIN-1", "MIN+1", "UUR-1", "UUR+1” om de tijd aan te passen.

I of ii om het infomenu te tonen,
Print het menu.

Met de optie I (i) in het menu wordt gekozen voor een kort menu voor alledaags gebruik of voor een lang menu met optie II (2x i) voor een uitgebreid menu met alle opties.

J Schakelen om de tijd uit de DS3231-module te gebruiken
Door 'J' te verzenden, wordt het gebruik van de optionele DS3231-tijdmodule AAN of UIT gezet.
Als de tijd van de DS3231 RTC-module wordt gebruikt zal de gele LED bij de USB-stekker op de Nano ESP32 niet meer knipperen.
Als de klok geen internetverbinding heeft, zal de tijd snel verlopen.
Door gebruik van de DS3231-tijdmodule wordt de afwijking teruggebracht tot een paar seconden per jaar.

De tijd kan in de DS3231-tijdmodule worden ingevoerd met optie T (time) en D (date) in het menu.

Mocht de tijd niet zichtbaar worden stuur dan het commando ! om de interne kloktijden te zien.

K Reads/sec aan/uit zetten

Door een K in te voeren kan het afdrukken van de LDR-uitlezing van de gemeten lichtintensiteit per seconde gevolgd worden
Het toont ook hoe vaak de processor per seconde (l/s) door het programma loopt en zijn taken controleert om de klok te laten lopen.

TestLDR: On

LDR reading, %Out, loops per second and time

LDR: 1= 1% 205413 l/s 16:06:08

LDR: 1= 1% 215535 l/s 16:06:09

LDR: 1= 1% 215451 l/s 16:06:10

LDR: 1= 1% 215350 l/s 16:06:11

TestLDR: Off

K0, K1, K2 Logging uit, per min, per uur

De tijd wordt standaard elke minuut in de logs geprint. Met de webpagina kunnen duizenden logregels getoond worden. Met K1 kan de log per minuut, en met K2 per uur, worden aan of uitgezet gezet.
In het lange menu (ii) staat dan Timestamp/min, Timestamp/hour of Timestamp off.

N Display uit tussen Nhhhh (N2208)
Met N2208 wordt het display uitgeschakeld tussen 22:00 en 8:00.

O Display aan/uit schakelen
O Schakelt het display uit en aan.

P Status-LED’s uit- en aanschakelen
P Schakelt de status-LED's op de Arduino Nano uit en aan.

Q Keuze van de weergavekleur (Q0-9)
Q0 geeft de tijd weer met gele woorden

en zal HET (of IT) binnen een uur van groen via geel naar rood veranderen.

en zal IS of WAS van groen naar rood via geel veranderen in een minuut.
Q1 zal elk uur een andere kleur tonen.
Q2 toont alle teksten wit.
Q3 gebruikt eigen gedefinieerde kleuren.

(Met optie F in het menu zijn de kleuren in te stellen)

Q4 gebruikt eigen gedefinieerde kleuren. (HET IS/WAS verkleurt van groen naar rood)

Q5 zal in een uur de regenboogkleuren doorlopen.
Q6 is een digitale display

Q7 zal elk uur een andere kleur tonen. (HET IS/WAS verkleurt van groen naar rood)

Q8 zal in 4 minuten de regenboogkleuren doorlopen.

Q9 zal in 15 seconden de regenboogkleuren doorlopen.

R Instellingen resetten
R zet alle voorkeuren terug naar de standaardinstellingen.

De SSID, het wachtwoord, de BLE-naam en de tijdzone worden niet gewist.
RRR wist deze laatste vier wel. WIFI, NTP en BLE worden aangezet

RRRRR is de combinatie van de optie R en RRR.
Het type LED-strip en het gebruik van een rotary of membraanknop worden ongewijzigd gelaten.

Voer een reset met RRRRR uit , een totale reset, wanneer de sketch voor de eerste keer wordt geüpload naar de Arduino Nano ESP32.

S=Slope L=Min M=Max (S50 L5 M200)
S Hoe snel de helderheid de maximale helderheid bereikt.
L Hoe helder het display is in volledige duisternis.
M de maximale helderheid van het display.
Waarden tussen 0 en 250'

U Demo-modus (msec) (U200)

Voer U in, gevolgd door de duur van een seconde in milliseconden.

U200 (200 milliseconde) versnelt de klok 5 keer.

Met alleen versturen van een U wordt de demomodus uitgeschakeld.

W=WIFI, X=NTP & , CCC=BLE
Schakel WIFI, NTP in en uit.
Voer het teken in om de optie in of uit te schakelen.
Onderaan het menu staat het aangegeven.
Bottom menu

Door een & te verzenden wordt de NTP-tijd in de interne Nano ESP32 RTC- en DS3231-tijdmodule gezet.

Y LED-test

Alle LEDs gaan een regenboog doorlopen. Deze testoptie laat alle LEDs branden op 5% van de maximale intensiteit.

Z WPS

WPS is een methode om het wachtwoord en de naam van het WIFI-station, de SSID, uit de router te krijgen.
Als er een WPS-knop op de WIFI-router aanwezig is kan de klok zonder de naam en het wachtwoord van de router in te hoeven vullen verbonden worden met het internet.

Start WPS in de klok door Z in het menu in te voeren en start WPS op de WIFI-router. Als alles goed gaat herstart de klok en zal de tijd gelijk staan.

Soms moet je de WPS-knop op de router een paar seconden ingedrukt houden.

Hoe je WPS moet starten verschilt per router.

+ = Fast BLE
Het BLE UART-protocol verzendt standaardpakketten van 20 bytes lang. Tussen elk pakket zit een vertraging van 50 msec .
De IOS BLEserial- app, en misschien ook andere, kan pakketten van 80 bytes of meer ontvangen voordat tekens worden gemist . Hierdoor wordt het menu sneller afgedrukt.
Optie + schakelt tussen de lange en korte pakketten.

~ = Verander display mode per minuut of uur

~ start de optie voor het wijzigen van de weergavemodus en wisselt per minuut.
~1 verandert de display mode elke minuut

~2 wisselt de display mode elk uur.

~0 of ~ schakelt de wisseloptie uit.

In het lange menu (ii) staat dan RandomDisplay: On/min, On/hour of Off

! = Toon NTP, RTC en DS3231 tijd
! zal de NTP, RTC en DS3231 tijd weergeven zoals ze zijn opgeslagen in de klok in de klok . De DS3231-tijdmodule moet geïnstalleerd zijn om een realistische tijd voor de module te tonen.
Hetzelfde als de & optie maar deze optie zal niet worden bijgewerkt vanaf de internet NTP server maar toont alleen de tijd.

#nnn = Selftest
Door een # te sturen start de klokzelftest. Dit is handig om te controleren of alle woorden in de klok functioneren.

Vanaf V062 is #nnnn is ook mogelijk. Nnnn zijn de milliseconden vertraging tussen elk woord.

De zelftest stopt vanzelf na een cyclus.

% = Wisselen tussen SK6812 en WS2812 LED strip
Met deze optie kan de gebruikte LED strip worden gewisseld. De klok is uitgerust met een van deze twee typen LED strips.

Een reset van alle instellingen door een R in het menu te sturen, verandert de selectie van de LED-strip niet.

$ = Haardvuur
Toont een haardvuur op en 144 LED-klok. Op andere type klokken zal het resultaat minder mooi zijn.

( = Schakelt extra optionele LEDs Aan/Uit

De klok kan optioneel uitgerust zijn met een extra logo tekst.

) = Schakelt HET/IS/WAS Aan/Uit

HET IS WAS blijven altijd uit

= = Toont de permanente instelling
Met de optie = worden alle instellingen geprint

@ = Herstart de klok
@ start de klok opnieuw op. Dit is handig als de SSID, et cetera worden gewijzigd en het programma opnieuw moet worden opgestart.
Instellingen blijven behouden.

& = Update met NTP
Synchroniseert de RTC-module met de NTP tijd
De RTC-tijdmodule in de klok kan de tijd in de klok aansturen. Met de menu-opties T en D kan de tijd en datum handmatig worden ingevoerd.
Met deze optie wordt de NTP-tijd naar de RTC-module gekopieerd.

De computer die in de klok zit heeft een eigen interne klok. Deze verloopt seconden per dag en wordt regelmatig met of de NTP-tijd om de DS3231 RTC-tijdmodule bijgewerkt. Als NTP en de DS3231 RTC-tijdmodule zijn uitgeschakeld zal de klok wel een tijd weergeven maar deze zal na een paar dagen uit de pas met de juiste tijd gaan lopen.

123456 Tijd instellen in DS3231 RTC-tijdmodule

Voer de tijd in als 152300 hhmmss. Hetzelfde als T152300.
Datum en tijd wijzigen werkt alleen als NTP uitgeschakeld is.

Tijdzones

Kopieer de tekst tussen de aanhalingstekens en plak deze na het teken E (of e) en stuur deze naar de klok.

Voor Nederland en België zend: eCET-1CEST,M3.5.0,M10.5.0/3

Africa/Abidjan,'GMT0'

Africa/Accra,'GMT0'

Africa/Addis_Ababa,'EAT-3'

Africa/Algiers,'CET-1'

Africa/Asmara, "EAT-3"

Africa/Bamako,'GMT0'

Africa/Bangui,"WAT-1"

Africa/Banjul,'GMT0'

Africa/Bissau,'GMT0'

Africa/Blantyre,"CAT-2"

Africa/Brazzaville,"WAT-1"

Africa/Bujumbura,'CAT-2'

Africa/Cairo, "EET-2"

Africa/Casablanca,"<+01>-1"

Africa/Ceuta,"CET-1CEST,M3.5.0,M10.5.0/3"

Africa/Conakry,"GMT0"

Africa/Dakar,'GMT0'

Africa/Dar_es_Salaam,"EAT-3"

Africa/Djibouti,"EAT-3"

Africa/Douala,"WHAT-1"

Africa/El_Aaiun,"<+01>-1"

Africa/Freetown,'GMT0'

Africa/Gaborone,"CAT-2"

Africa/Harare, "CAT-2"

Africa/Johannesburg,'SAST-2'

Africa/Juba,"CAT-2"

Africa/Kampala, "EAT-3"

Africa/Khartoum,"CAT-2"

Africa/Kigali,"CAT-2"

Africa/Kinshasa,'WHAT-1'

Africa/Lagos,"WAT-1"

Africa/Libreville,"WHAT-1"

Africa/Lome,'GMT0'

Africa/Luanda, "WHAT-1"

Africa/Lubumbashi,"CAT-2"

Africa/Lusaka,'CAT-2'

Africa/Malabo, "WHAT-1"

Africa/Maputo,"CAT-2"

Africa/Maseru,"SAST-2"

Africa/Mbabane,'SAST-2'

Africa/Mogadishu,'EAT-3'

Africa/Monrovia,'GMT0'

Africa/Nairobi,'EAT-3'

Africa/Ndjamena,"WAT-1"

Africa/Niamey,"WAT-1"

Africa/Nouakchott,'GMT0'

Africa/Ouagadougou,'GMT0'

Africa/Porto-Novo, "WAT-1"

Africa/Sao_Tome,'GMT0'

Africa/Tripoli, "EET-2"

Africa/Tunis, 'CET-1'

Africa/Windhoek,"CAT-2"

America/Adak,"HST10HDT,M3.2.0,M11.1.0"

America/Anchorage,"AKST9AKDT,M3.2.0,M11.1.0"

America/Anguilla, "AST4"

America/Antigua, "AST4"

America/Araguaina,"<-03>3"

America/Argentina/Buenos_Aires,"<-03>3"

America/Argentina/Catamarca,'<-03>3'

America/Argentina/Cordoba,"<-03>3"

America/Argentina/Jujuy,"<-03>3"

America/Argentina/La_Rioja,"<-03>3"

America/Argentina/Mendoza,"<-03>3"

America/Argentina/Rio_Gallegos,"<-03>3"

America/Argentina/Salta,"<-03>3"

America/Argentina/San_Juan,"<-03>3"

America/Argentina/San_Luis,"<-03>3"

America/Argentina/Tucuman,"<-03>3"

America/Argentina/Ushuaia,"<-03>3"

America/Aruba, "AST4"

America/Asuncion,"<-04>4<-03>,M10.1.0/0,M3.4.0/0"

America/Atikokan,"EST5"

America/Bahia,"<-03>3"

America/Bahia_Banderas,"CST6CDT,M4.1.0,M10.5.0"

America/Barbados, "AST4"

America/Belem,"<-03>3"

America/Belize, "CST6"

America/Blanc-Sablon, "AST4"

America/Boa_Vista,"<-04>4"

America/Bogota,"<-05>5"

America/Boise,"MST7MDT,M3.2.0,M11.1.0"

America/Cambridge_Bay,"MST7MDT,M3.2.0,M11.1.0"

America/Campo_Grande,"<-04>4"

America/Cancun, "EST5"

America/Caracas,"<-04>4"

America/Cayenne,"<-03>3"

America/Cayman,"EST5"

America/Chicago,"CST6CDT,M3.2.0,M11.1.0"

America/Chihuahua,"MST7MDT,M4.1.0,M10.5.0"

America/Costa_Rica,"CST6"

America/Creston,"MST7"

America/Cuiaba,"<-04>4"

America/Curacao, "AST4"

America/Danmarkshavn,'GMT0'

America/Dawson,"MST7"

America/Dawson_Creek,"MST7"

America/Denver,"MST7MDT,M3.2.0,M11.1.0"

America/Detroit,"EST5EDT,M3.2.0,M11.1.0"

America/Dominica, "AST4"

America/Edmonton,"MST7MDT,M3.2.0,M11.1.0"

America/Eirunepe,"<-05>5"

America/El_Salvador,"CST6"

America/Fortaleza,"<-03>3"

America/Fort_Nelson,"MST7"

America/Glace_Bay,"AST4ADT,M3.2.0,M11.1.0"

America/Godthab,"<-03>3<-02>,M3.5.0/-2,M10.5.0/-1"

America/Goose_Bay,"AST4ADT,M3.2.0,M11.1.0"

America/Grand_Turk,"EST5EDT,M3.2.0,M11.1.0"

America/Grenada, "AST4"

America/Guadeloupe, "AST4"

America/Guatemala, "CST6"

America/Guayaquil,"<-05>5"

America/Guyana,"<-04>4"

America/Halifax,"AST4ADT,M3.2.0,M11.1.0"

America/Havana,"CST5CDT,M3.2.0/0,M11.1.0/1"

America/Hermosillo, "MST7"

America/Indiana/Indianapolis,"EST5EDT,M3.2.0,M11.1.0"

America/Indiana/Knox,"CST6CDT,M3.2.0,M11.1.0"

America/Indiana/Marengo,"EST5EDT,M3.2.0,M11.1.0"

America/Indiana/Petersburg,"EST5EDT,M3.2.0,M11.1.0"

America/Indiana/Tell_City,"CST6CDT,M3.2.0,M11.1.0"

America/Indiana/Vevay,"EST5EDT,M3.2.0,M11.1.0"

America/Indiana/Vincennes,"EST5EDT,M3.2.0,M11.1.0"

America/Indiana/Winamac,"EST5EDT,M3.2.0,M11.1.0"

America/Inuvik,"MST7MDT,M3.2.0,M11.1.0"

America/Iqaluit,"EST5EDT,M3.2.0,M11.1.0"

America/Jamaica,"EST5"

America/Juneau,"AKST9AKDT,M3.2.0,M11.1.0"

America/Kentucky/Louisville,"EST5EDT,M3.2.0,M11.1.0"

America/Kentucky/Monticello,"EST5EDT,M3.2.0,M11.1.0"

America/Kralendijk, "AST4"

America/La_Paz,"<-04>4"

America/Lima,"<-05>5"

America/Los_Angeles,"PST8PDT,M3.2.0,M11.1.0"

America/Lower_Princes,"AST4"

America/Maceio,"<-03>3"

America/Managua, "CST6"

America/Manaus,"<-04>4"

America/Marigot, "AST4"

America/Martinique, "AST4"

America/Matamoros,"CST6CDT,M3.2.0,M11.1.0"

America/Mazatlan,"MST7MDT,M4.1.0,M10.5.0"

America/Menominee,"CST6CDT,M3.2.0,M11.1.0"

America/Merida,"CST6CDT,M4.1.0,M10.5.0"

America/Metlakatla,"AKST9AKDT,M3.2.0,M11.1.0"

America/Mexico_City,"CST6CDT,M4.1.0,M10.5.0"

America/Miquelon,"<-03>3<-02>,M3.2.0,M11.1.0"

America/Moncton,"AST4ADT,M3.2.0,M11.1.0"

America/Monterrey,"CST6CDT,M4.1.0,M10.5.0"

America/Montevideo,"<-03>3"

America/Montreal,"EST5EDT,M3.2.0,M11.1.0"

America/Montserrat,"AST4"

America/Nassau,"EST5EDT,M3.2.0,M11.1.0"

America/New_York,"EST5EDT,M3.2.0,M11.1.0"

America/Nipigon,"EST5EDT,M3.2.0,M11.1.0"

America/Nome,"AKST9AKDT,M3.2.0,M11.1.0"

America/Noronha,"<-02>2"

America/North_Dakota/Beulah,"CST6CDT,M3.2.0,M11.1.0"

America/North_Dakota/Center,"CST6CDT,M3.2.0,M11.1.0"

America/North_Dakota/New_Salem,"CST6CDT,M3.2.0,M11.1.0"

America/Nuuk,"<-03>3<-02>,M3.5.0/-2,M10.5.0/-1"

America/Ojinaga,"MST7MDT,M3.2.0,M11.1.0"

America/Panama, "EST5"

America/Pangnirtung,"EST5EDT,M3.2.0,M11.1.0"

America/Paramaribo,"<-03>3"

America/Phoenix, "MST7"

America/Port-au-Prince,"EST5EDT,M3.2.0,M11.1.0"

America/Port_of_Spain,"AST4"

America/Porto_Velho,"<-04>4"

America/Puerto_Rico,"AST4"

America/Punta_Arenas,"<-03>3"

America/Rainy_River,"CST6CDT,M3.2.0,M11.1.0"

America/Rankin_Inlet,"CST6CDT,M3.2.0,M11.1.0"

America/Recife,"<-03>3"

America/Regina, "CST6"

America/Resolute,"CST6CDT,M3.2.0,M11.1.0"

America/Rio_Branco,"<-05>5"

America/Santarem,"<-03>3"

America/Santiago,"<-04>4<-03>,M9.1.6/24,M4.1.6/24"

America/Santo_Domingo,"AST4"

America/Sao_Paulo,"<-03>3"

America/Scoresbysund,"<-01>1<+00>,M3.5.0/0,M10.5.0/1"

America/Sitka,"AKST9AKDT,M3.2.0,M11.1.0"

America/St_Barthelemy,"AST4"

America/St_Johns,"NST3:30NDT,M3.2.0,M11.1.0"

America/St_Kitts,"AST4"

America/St_Lucia,"AST4"

America/St_Thomas,"AST4"

America/St_Vincent,"AST4"

America/Swift_Current,"CST6"

America/Tegucigalpa, "CST6"

America/Thule,"AST4ADT,M3.2.0,M11.1.0" America/Thunder_Bay,"EST5EDT,M3.2.0,M11.1.0"

America/Tijuana,"PST8PDT,M3.2.0,M11.1.0"

America/Toronto,"EST5EDT,M3.2.0,M11.1.0"

America/Tortola, "AST4"

America/Vancouver,"PST8PDT,M3.2.0,M11.1.0"

America/Whitehorse,"MST7"

America/Winnipeg,"CST6CDT,M3.2.0,M11.1.0"

America/Yakutat,"AKST9AKDT,M3.2.0,M11.1.0"

America/Yellowknife,"MST7MDT,M3.2.0,M11.1.0"

Antarctica/Casey,"<+11>-11"

Antarctica/Davis,"<+07>-7"

Antarctica/DumontDUrville,"<+10>-10"

Antarctica/Macquarie,"AEST-10AEDT,M10.1.0,M4.1.0/3"

Antarctica/Mawson,"<+05>-5"

Antarctica/McMurdo,"NZST-12NZDT,M9.5.0,M4.1.0/3"

Antarctica/Palmer,"<-03>3"

Antarctica/Rothera,"<-03>3"

Antarctica/Syowa,"<+03>-3"

Antarctica/Troll,"<+00>0<+02>-2,M3.5.0/1,M10.5.0/3"

Antarctica/Vostok,"<+06>-6"

Arctic/Longyearbyen,"CET-1CEST,M3.5.0,M10.5.0/3"

Asia/Aden,"<+03>-3"

Asia/Almaty,"<+06>-6"

Asia/Amman,"EET-2EEST,M2.5.4/24,M10.5.5/1"

Asia/Anadyr,"<+12>-12"

Asia/Aqtau,"<+05>-5"

Asia/Aqtobe,"<+05>-5"

Asia/Ashgabat,"<+05>-5"

Asia/Atyrau,"<+05>-5"

Asia/Baghdad,"<+03>-3"

Asia/Bahrain,"<+03>-3"

Asia/Baku,"<+04>-4"

Asia/Bangkok,"<+07>-7"

Asia/Barnaul,"<+07>-7"

Asia/Beirut,"EET-2EEST,M3.5.0/0,M10.5.0/0"

Asia/Bishkek,"<+06>-6"

Asia/Brunei,"<+08>-8"

Asia/Chita,"<+09>-9"

Asia/Choibalsan,"<+08>-8"

Asia/Colombo,"<+0530>-5:30"

Asia/Damascus,"EET-2EEST,M3.5.5/0,M10.5.5/0"

Asia/Dhaka,"<+06>-6"

Asia/Dili,"<+09>-9"

Asia/Dubai,"<+04>-4"

Asia/Dushanbe,"<+05>-5"

Asia/Famagusta,"EET-2EEST,M3.5.0/3,M10.5.0/4"

Asia/Gaza,'EET-2EEST,M3.4.4/48,M10.5.5/1'

Asia/Hebron,"EET-2EEST,M3.4.4/48,M10.5.5/1"

Asia/Ho_Chi_Minh,"<+07>-7"

Asia/Hong_Kong,"HKT-8"

Asia/Hovd,"<+07>-7"

Asia/Irkutsk,"<+08>-8"

Asia/Jakarta,"WIB-7"

Asia/Jayapura,"WHITE-9"

Asia/Jerusalem,"IST-2IDT,M3.4.4/26,M10.5.0"

Asia/Kabul,"<+0430>-4:30"

Asia/Kamchatka,"<+12>-12"

Asia/Karachi, "PKT-5"

Asia/Kathmandu,"<+0545>-5:45"

Asia/Khandyga,"<+09>-9"

Asia/Kolkata,"IST-5:30"

Asia/Krasnoyarsk,"<+07>-7"

Asia/Kuala_Lumpur,"<+08>-8"

Asia/Kuching,"<+08>-8"

Asia/Kuwait,"<+03>-3"

Asia/Macau, "CST-8"

Asia/Magadan,"<+11>-11"

Asia/Makassar,"WITA-8"

Asia/Manila, "PST-8"

Asia/Muscat,"<+04>-4"

Asia/Nicosia,"EET-2EEST,M3.5.0/3,M10.5.0/4"

Asia/Novokuznetsk,"<+07>-7"

Asia/Novosibirsk,"<+07>-7"

Asia/Omsk,"<+06>-6"

Asia/Oral,"<+05>-5"

Asia/Phnom_Penh,"<+07>-7"

Asia/Pontianak, "WIB-7"

Asia/Pyongyang,"KST-9"

Asia/Qatar,"<+03>-3"

Asia/Qyzylorda,"<+05>-5"

Asia/Riyadh,"<+03>-3"

Asia/Sakhalin,"<+11>-11"

Asia/Samarkand,"<+05>-5"

Asia/Seoul,"KST-9"

Asia/Shanghai, "CST-8"

Asia/Singapore,"<+08>-8"

Asia/Srednekolymsk,"<+11>-11"

Asia/Taipei,"CST-8"

Asia/Tashkent,"<+05>-5"

Asia/Tbilisi,"<+04>-4"

Asia/Tehran,"<+0330>-3:30<+0430>,J79/24,J263/24"

Asia/Thimphu,"<+06>-6"

Asia/Tokyo,"JST-9"

Asia/Tomsk,"<+07>-7"

Asia/Ulaanbaatar,"<+08>-8"

Asia/Urumqi,"<+06>-6"

Asia/Ust-Nera,"<+10>-10"

Asia/Vientiane,"<+07>-7"

Asia/Vladivostok,"<+10>-10"

Asia/Yakutsk,"<+09>-9"

Asia/Yangon,"<+0630>-6:30"

Asia/Yekaterinburg,"<+05>-5"

Asia/Yerevan,"<+04>-4"

Atlantic/Azores,"<-01>1<+00>,M3.5.0/0,M10.5.0/1"

Atlantic/Bermuda,"AST4ADT,M3.2.0,M11.1.0"

Atlantic/Canary,"WET0WEST,M3.5.0/1,M10.5.0"

Atlantic/Cape_Verde,"<-01>1"

Atlantic/Faroe,"WET0WEST,M3.5.0/1,M10.5.0"

Atlantic/Madeira,"WET0WEST,M3.5.0/1,M10.5.0"

Atlantic/Reykjavik,'GMT0'

Atlantic/South_Georgia,"<-02>2"

Atlantic/Stanley,"<-03>3"

Atlantic/St_Helena,'GMT0'

Australia/Adelaide,"ACST-9:30ACDT,M10.1.0,M4.1.0/3"

Australia/Brisbane,'AEST-10'

Australia/Broken_Hill,"ACST-9:30ACDT,M10.1.0,M4.1.0/3"

Australia/Currie,"AEST-10AEDT,M10.1.0,M4.1.0/3"

Australia/Darwin,"ACST-9:30"

Australia/Eucla,"<+0845>-8:45"

Australia/Hobart,"AEST-10AEDT,M10.1.0,M4.1.0/3"

Australia/Lindeman,"AEST-10"

Australia/Lord_Howe,"<+1030>-10:30<+11>-11,M10.1.0,M4.1.0"

Australia/Melbourne,"AEST-10AEDT,M10.1.0,M4.1.0/3"

Australia/Perth, "AWST-8"

Australia/Sydney,"AEST-10AEDT,M10.1.0,M4.1.0/3"

Europe/Amsterdam,"CET-1CEST,M3.5.0,M10.5.0/3"

Europe/Andorra,"CET-1CEST,M3.5.0,M10.5.0/3"

Europe/Astrakhan,"<+04>-4"

Europe/Athens,"EET-2EEST,M3.5.0/3,M10.5.0/4"

Europe/Belgrade,"CET-1CEST,M3.5.0,M10.5.0/3"

Europe/Berlin,"CET-1CEST,M3.5.0,M10.5.0/3"

Europe/Bratislava,"CET-1CEST,M3.5.0,M10.5.0/3"

Europe/Brussels,"CET-1CEST,M3.5.0,M10.5.0/3"

Europe/Bucharest,"EET-2EEST,M3.5.0/3,M10.5.0/4"

Europe/Budapest,"CET-1CEST,M3.5.0,M10.5.0/3"

Europe/Busingen,"CET-1CEST,M3.5.0,M10.5.0/3"

Europe/Chisinau,"EET-2EEST,M3.5.0,M10.5.0/3"

Europe/Copenhagen,"CET-1CEST,M3.5.0,M10.5.0/3"

Europe/Dublin,"IST-1GMT0,M10.5.0,M3.5.0/1"

Europe/Gibraltar,"CET-1CEST,M3.5.0,M10.5.0/3"

Europe/Guernsey,"GMT0BST,M3.5.0/1,M10.5.0"

Europe/Helsinki,"EET-2EEST,M3.5.0/3,M10.5.0/4"

Europe/Isle_of_Man,"GMT0BST,M3.5.0/1,M10.5.0"

Europe/Istanbul,"<+03>-3"

Europe/Jersey,"GMT0BST,M3.5.0/1,M10.5.0"

Europe/Kaliningrad, 'EET-2'

Europe/Kiev,"EET-2EEST,M3.5.0/3,M10.5.0/4"

Europe/Kirov,'<+03>-3'

Europe/Lisbon,"WET0WEST,M3.5.0/1,M10.5.0"

Europe/Ljubljana,"CET-1CEST,M3.5.0,M10.5.0/3"

Europe/London,"GMT0BST,M3.5.0/1,M10.5.0"

Europe/Luxembourg,"CET-1CEST,M3.5.0,M10.5.0/3"

Europe/Madrid,"CET-1CEST,M3.5.0,M10.5.0/3"

Europe/Malta,"CET-1CEST,M3.5.0,M10.5.0/3"

Europe/Mariehamn,"EET-2EEST,M3.5.0/3,M10.5.0/4"

Europe/Minsk,'<+03>-3'

Europe/Monaco,"CET-1CEST,M3.5.0,M10.5.0/3"

Europe/Moscow,"MSK-3"

Europe/Oslo,"CET-1CEST,M3.5.0,M10.5.0/3"

Europe/Paris,"CET-1CEST,M3.5.0,M10.5.0/3"

Europe/Podgorica,"CET-1CEST,M3.5.0,M10.5.0/3"

Europe/Prague,"CET-1CEST,M3.5.0,M10.5.0/3"

Europe/Riga,'EET-2EEST,M3.5.0/3,M10.5.0/4'

Europe/Rome,"CET-1CEST,M3.5.0,M10.5.0/3"

Europe/Samara,"<+04>-4"

Europe/San_Marino,"CET-1CEST,M3.5.0,M10.5.0/3"

Europe/Sarajevo,"CET-1CEST,M3.5.0,M10.5.0/3"

Europe/Saratov,"<+04>-4"

Europe/Simferopol,'MSK-3'

Europe/Skopje,"CET-1CEST,M3.5.0,M10.5.0/3"

Europe/Sofia,"EET-2EEST,M3.5.0/3,M10.5.0/4"

Europe/Stockholm,"CET-1CEST,M3.5.0,M10.5.0/3"

Europe/Tallinn,"EET-2EEST,M3.5.0/3,M10.5.0/4"

Europe/Tirane,"CET-1CEST,M3.5.0,M10.5.0/3"

Europe/Ulyanovsk,"<+04>-4"

Europe/Uzhgorod,"EET-2EEST,M3.5.0/3,M10.5.0/4"

Europe/Vaduz,"CET-1CEST,M3.5.0,M10.5.0/3"

Europe/Vatican,"CET-1CEST,M3.5.0,M10.5.0/3"

Europe/Vienna,"CET-1CEST,M3.5.0,M10.5.0/3"

Europe/Vilnius,"EET-2EEST,M3.5.0/3,M10.5.0/4"

Europe/Volgograd,"<+03>-3"

Europe/Warsaw,"CET-1CEST,M3.5.0,M10.5.0/3"

Europe/Zagreb,"CET-1CEST,M3.5.0,M10.5.0/3"

Europe/Zaporozhye,"EET-2EEST,M3.5.0/3,M10.5.0/4"

Europe/Zurich,"CET-1CEST,M3.5.0,M10.5.0/3"

Indian/Antananarivo, "EAT-3"

Indian/Chagos,"<+06>-6"

Indian/Christmas,"<+07>-7"

Indian/Cocos,"<+0630>-6:30"

Indian/Comoro, "EAT-3"

Indian/Kerguelen,"<+05>-5"

Indian/Mahe,"<+04>-4"

Indian/Maldives,"<+05>-5"

Indian/Mauritius,"<+04>-4"

Indian/Mayotte,"EAT-3"

Indian/Reunion,"<+04>-4"

Pacific/Apia,"<+13>-13"

Pacific/Auckland,"NZST-12NZDT,M9.5.0,M4.1.0/3"

Pacific/Bougainvillea,"<+11>-11"

Pacific/Chatham,"<+1245>-12:45<+1345>,M9.5.0/2:45,M4.1.0/3:45"

Pacific/Chuuk,"<+10>-10"

Pacific/Easter,"<-06>6<-05>,M9.1.6/22,M4.1.6/22"

Pacific/Efate,"<+11>-11"

Pacific/Enderbury,"<+13>-13"

Pacific/Fakaofo,"<+13>-13"

Pacific/Fiji,"<+12>-12<+13>,M11.2.0,M1.2.3/99"

Pacific/Funafuti,"<+12>-12"

Pacific/Galapagos,"<-06>6"

Pacific/Gambier,"<-09>9"

Pacific/Guadalcanal,"<+11>-11"

Pacific/Guam,"ChST-10"

Pacific/Honolulu, "HST10"

Pacific/Kiritimati,"<+14>-14"

Pacific/Kosrae,"<+11>-11"

Pacific/Kwajalein,"<+12>-12"

Pacific/Majuro,"<+12>-12"

Pacific/Marquesas,"<-0930>9:30"

Pacific/Midway, "SST11"

Pacific/Nauru,"<+12>-12"

Pacific/Niue,"<-11>11"

Pacific/Norfolk,"<+11>-11<+12>,M10.1.0,M4.1.0/3"

Pacific/Noumea,"<+11>-11"

Pacific/Pago_Pago,"SST11"

Pacific/Palau,"<+09>-9"

Pacific/Pitcairn,"<-08>8"

Pacific/Pohnpei,"<+11>-11"

Pacific/Port_Moresby,"<+10>-10"

Pacific/Rarotonga,"<-10>10"

Pacific/Saipan,"ChST-10"

Pacific/Tahiti,"<-10>10"

Pacific/Tarawa,"<+12>-12"

Pacific/Tongatapu,"<+13>-13"

Pacific/Wake,"<+12>-12"

Pacific/Valais,"<+12>-12"

Etc/GMT,"GMT0"

Etc/GMT-0,"GMT0"

Etc/GMT-1,"<+01>-1"

Etc/GMT-2,"<+02>-2"

Etc/GMT-3,"<+03>-3"

Etc/GMT-4,"<+04>-4"

Etc/GMT-5,"<+05>-5"

Etc/GMT-6,"<+06>-6"

Etc/GMT-7,"<+07>-7"

Etc/GMT-8,"<+08>-8"

Etc/GMT-9,"<+09>-9"

Etc/GMT-10,"<+10>-10"

Etc/GMT-11,"<+11>-11"

Etc/GMT-12,"<+12>-12"

Etc/GMT-13,"<+13>-13"

Etc/GMT-14,"<+14>-14"

Etc/GMT0,"GMT0"

Etc/GMT+0,"GMT0"

Etc/GMT+1,"<-01>1"

Etc/GMT+2,"<-02>2"

Etc/GMT+3,"<-03>3"

Etc/GMT+4,"<-04>4"

Etc/GMT+5,"<-05>5"

Etc/GMT+6,"<-06>6"

Etc/GMT+7,"<-07>7"

Etc/GMT+8,"<-08>8"

Etc/GMT+9,"<-09>9"

Etc/GMT+10,"<-10>10"

Etc/GMT+11,"<-11>11"

Etc/GMT+12,"<-12>12"

Etc/UCT,"UTC0"

Etc/UTC,"UTC0"

Etc/Greenwich,'GMT0'

Etc/Universal,"UTC0"

Etc/Zulu,"UTC0"

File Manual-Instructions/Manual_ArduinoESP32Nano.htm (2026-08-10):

# Arduino ESP32-Nano word clock

A clock that displays the time in words in Dutch, English, French and German in a large 4-language clock or as a single-language clock.

An Arduino ESP32 Nano computer integrated into the clock is used to control the clock's time and establish Wi-Fi and Bluetooth connections.
The time is synchronized with the internet's Network Time Protocol (NTP) via Wi-Fi. It's also possible to set the time without Wi-Fi or Bluetooth using a rotary knob/pushbutton.
Settings can be managed via a web page, a PC, or a Bluetooth Low Energy (BLE) serial terminal app installed on a phone, PC, or tablet.

 | 
4-language clock | Dutch language clock

Corten steel clock

Translated with ‘Google Translate’ from Dutch

Quick start

Find one of the following apps in the App Store. This app is used to send commands to the clock.

If the app cannot be downloaded, please read on to find out how to connect to Wi-Fi.

iOS iPhone/iPad/Mac | iOS iPhone/iPad/Mac | Android
 |  | 
BLE (https://apps.apple.com/nl/app/ble-serial-pro/id1632245655) (https://apps.apple.com/nl/app/ble-serial-pro/id1632245655)Serial (https://apps.apple.com/nl/app/ble-serial-pro/id1632245655) (https://apps.apple.com/nl/app/ble-serial-pro/id1632245655)Pro (https://apps.apple.com/nl/app/ble-serial-pro/id1632245655) | (https://apps.apple.com/nl/app/ble-serial-tiny/id1607862132)BLESerial (https://apps.apple.com/nl/app/ble-serial-tiny/id1607862132) (https://apps.apple.com/nl/app/ble-serial-tiny/id1607862132) (https://apps.apple.com/nl/app/ble-serial-tiny/id1607862132) (https://apps.apple.com/nl/app/ble-serial-tiny/id1607862132)nRF (https://apps.apple.com/nl/app/ble-serial-tiny/id1607862132) (https://apps.apple.com/nl/app/ble-serial-tiny/id1607862132) | (https://play.google.com/store/apps/details?id=de.kai_morich.serial_bluetooth_terminal)Serial (https://play.google.com/store/apps/details?id=de.kai_morich.serial_bluetooth_terminal) (https://play.google.com/store/apps/details?id=de.kai_morich.serial_bluetooth_terminal)Bluetooth Terminal (https://play.google.com/store/apps/details?id=de.kai_morich.serial_bluetooth_terminal) (Turn off timestamp in the menu)

 The clock is set to receive the time via Wi-Fi. If the Wi-Fi router name and password are not entered, a web page will open asking you to enter the router credentials.

- StartWordclock ” station in the WIFI settings .

- Enter the password: wordclock

- Then open the browser on your mobile and type in the URL: 162.168.4.1 and press enter.

- Enter the name and password of the Wi-Fi router used at home.
Tip : You can also use your mobile hotspot for Wi-Fi.

Bluetooth app

Setup is easier with the Bluetooth app on your phone or tablet.

-  Open the Bluetooth app.

The iOS app displays a list of Bluetooth stations.
If it's taking too long, tap the wheel in the top left corner (nRF52 is selected) and tap Done .
On Android, tap Scan and Connect with the word clock.

- Send the command: i to see the menu

Type the letter a followed by the name of the router and press Send . ( eg : aNAMErouter Do not send extra periods or spaces.)

- Type the letter b followed by the router password and press Send . ( e.g .: bGeHeim1234)

- Send @ to restart the clock.

Or start WPS (A button on the router with WPS. Read this in the manual)

- Press the WPS button and then send the command: z in the Bluetooth serial app.

- If WIFI is not possible,
send the letter J in the menu with the Bluetooth app.

- Then it appears: Use DS3231 is ON. WIFI ON, NTP OFF.

- Send a W to turn off Wi-Fi. Send @ to restart the clock.

- Send the correct time and date via the menu.
( For example, send: T143000 for 'half past two' and, for example, send : D090625 for the date .)

- 

Small PCB design with Rotary and DS3231 RTC attached

Before starting
The clock receives the time from the internet if there is a WIFI connection.

When a DS3231 time module is mounted on the PCB, an Internet connection is not required.

If a rotary or push button knob is installed it can be used to set the time.

An infrared remote control can also be installed to set the time.

To connect to the internet, the Wi-Fi station name and password must be entered into the clock software to connect to a Wi-Fi router.
The Wi-Fi station name and password must be entered only once. The login information is stored in the microprocessor's memory.

A serial terminal app on a phone, tablet, or PC allows operation without connecting the clock to a PC with a USB cable to enter Wi-Fi credentials.

The clock can also be controlled via a browser when connected to WIFI.

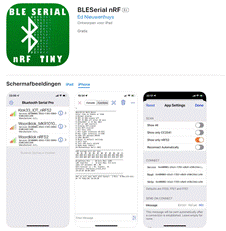
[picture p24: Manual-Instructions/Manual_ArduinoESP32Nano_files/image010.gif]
 |  | 
BLESerial nRF | BLE Serial Pro | Serial Bluetooth terminal

Download a Bluetooth UART serial terminal app on a phone, PC, or tablet.
For iOS: BLE Serial Pro or BLESerial nRF .
For Android: Serial Bluetooth terminal.
For a PC: Install the Arduino IDE on a PC and connect the clock to the PC using a USB-C cable.


Arduino ESP32 Nano on the printed circuit board in the clock.

First service

- Connect the clock power.

If there's no internet or Bluetooth connection , the clock can be controlled with the rotary knob, three push buttons, or a remote control, provided it's installed and activated. Activation is done in the menu with option H01 (rotary knob), H02 push buttons, or H03 and H04 (IR remote control).
Sometimes the knob is mounted inside the cabinet.

- Press the dial or the center button of the three push buttons.
The "HOUR" indicator will flash three times, and the hours can be set by turning the dial or pressing the up or down buttons on the three-button membrane.

- A second press of the button or the middle button will make
HETISWAS flash and the minutes can be changed. Seconds are set to 0. So to be precise, set the last minute to exactly 0 seconds.

- Pressing a third time will cause TWELVE to flash three times and the LED light intensity can be adjusted.

- Pressing the button a fourth time will cause the NTP and RTC signs to flash three times. You can switch between RTC and NTP time.

- Pressing nine times will reset the clock to factory settings.

The IR remote control can be used to operate the clock once it has been learned. The { option in the menu prompts the clock to press buttons corresponding to the numbers 0-9 and a few control buttons, such as POWER.

Via WIFI connection

When the clock is started for the first time, a WIFI connection will need to be established.

If there are still old connection data in the clock, enter the capital letter R 5 times in the menu (RRRRR) to delete it.

The clock settings are then set to:

SSID and password are empty

Timezone:CET-1CEST,M3.5.0,M10.5.0/3

WIFI=On NTP=On BLE=On

WPS

WPS is a method to obtain the password and the name of the WIFI station, the SSID, from the router.

Start WPS on the clock by entering Z in the menu, and then start WPS on the Wi-Fi router. If all goes well, the clock will restart and the time will be correct.

Access point in the phone

In the WIFI connections on the phone (tablet on PC) there will be a “ StartWordclock ” station next to the router you are connected to.

- Connect to the " StartWordclock " station. Use the password: wordclock

- Open a browser and type: 192.168.4.1 and press enter.



- In this screen, enter the SSID and password of the WIFI router and press Submit

This information is often found on the bottom of the router.



The clock will restart and display the correct time.

When the Bluetooth app is installed on the phone or tablet

With the 'Bluetooth serial terminal' app, the clock can be controlled via Bluetooth with your phone, tablet or macOS PC.

- Launch the Bluetooth terminal app on your phone or tablet

- Click on the connection named ' wordclock ' in the serial terminal app.

- Find your Wi-Fi router's login information.
Find the Wi-Fi router's SSID and password. These are typically located on the bottom of the Wi-Fi router.

Type in:

- aSSID and press Send.
SSID is the name of the SSID you can find on your phone, for example. It's the name to which Wi-Fi is connected.

bPASSWORD and press send.
PASSWORD is the password you can find on the bottom of your Wi-Fi router.

- cBLENAME (optional, otherwise the clock will be named ' Wordclock ')
The BLENAME is the name of the clock in the BLE serial terminal app and in the connected WIFI router.

If the Router Name (SSID) or Password is incorrect, the clock will restart the Access Point page ( 192.168.4.1 ) in the phone after a few restarts .

The correct data can be entered via this access point page, Bluetooth or with the USB cable.

For a detailed explanation, see the chapter: Clock operation and settings.

 In the FRITZBox WIFI router, for example, the clock named “SteelClock-01” is connected to WIFI. You can launch the clock's webpage in a browser by tapping: http://SteelClock-01 or SteelClock-01.local. The default name is: wordclock and then the url to start the menu page becomes: wordclock.local . | 

Option I in the menu selects a short menu for everyday use or a long menu with option ii (2x i) for an extensive menu with all options.



Clicking 'Log view' at the top of the web page launches the Log Viewer. This displays the last 500 lines printed to the serial port or the Bluetooth app.
In Chrome (December 2025), the tab can be split ( right-click the tab and choose 'split tab' or something similar) to display both the web page and the log viewer.
' All log files' displays the last many thousands of lines.

When the rotary encoder or a three-button membrane button or an IR remote control is installed

A rotary control, push-button control, or remote control, along with the highly accurate DS3231 RTC clock, are optional and not required. The time is then synchronized with the internet.
These components are necessary if a clock cannot receive Wi-Fi.

In the clock menu, the rotary encoder (or three pushbuttons) can be switched on or off. If no rotary encoders, pushbuttons, or remote control are installed,
disable the rotary encoder using the H00 option in the menu. (Open the longer settings menu by pressing ii). Also disable
the use of the DS3231 RTC (menu option J) so that the internet time is used.

When rotary encoder is installed

The rotary knob is active for 60 seconds after pressing the button.

- Press the dial or the center button of the three push buttons.
The "HOUR" indicator will flash three times, and the hours can be set by turning the dial or pressing the up or down buttons on the three-button membrane.

- A second press of the button or the middle button will make
HETISWAS flash and the minutes can be changed. Seconds are set to 0. So to be precise, set the last minute to exactly 0 seconds.

- Pressing a third time will cause TWELVE to flash three times and the LED light intensity can be adjusted.

- Pressing the button a fourth time will cause the NTP and RTC signs to flash three times.
You can switch between RTC and NTP time.

- Pressing nine times will reset the clock to factory settings.

When push buttons are installed

The push buttons are activated for 60 seconds after pressing a *

Then enter the time with 6 digits as hhmmss .

For example, 134500 for a quarter to two.

After entering the 6th number the time is entered automatically.

When an IR remote control is installed

Turn on clock reception with POWER.
Use the large remote control (H03 enabled in the menu) to send the correct time using digits such as hhmmss . For example, a quarter to three would be 144500 in the afternoon or 024500 in the morning.
Or use the small remote control (H04 enabled in the menu) with the Up and Down buttons and CH+ and CH- to change the minutes and/or hours.

With ONOFF the clock illumination can be switched off or on.

Making the clock case

The construction of the clock case with lighting can be found here:

(https://ednieuw.com/Woordklok/Bouwpakket/WoordklokSK6812.htm)https://ednieuw.com/Woordklok/Bouwpakket/WoordklokSK6812.htm

or here: https://github.com/ednieuw/Arduino-ESP32-Nano-Wordclock

Instructions for a four-language word clock with SK6812 LEDs in UK, NL, DE, and FR with Nano . https://github.com/ednieuw/FourLanguageClock

Compilation and uploading

The software runs on an Arduino Nano ESP32.

This software is compiled using the Arduino IDE and uploaded to the Nano ESP32.

A compiler is available for each board that can be programmed with the Arduino IDE. This can be selected in the board manager menu.

There are two versions available for the Arduino Nano ESP32.

One version, from Arduino itself, that uses core version 2. This version works without any problems.



- Load the file ESP32Arduino_WordClockV0xx.INO into the IDE

In the sketch, somewhere around line 50, select one of the three word clocks by removing the two forward slashes //.

//#define FOURLANGUAGECLOCK

#define NL144CLOCK

//#define NLM1M2M3M4L114 // NL clock with four extra LEDs for the minutes to light up

#define NL144CLOCK -> a 144 LED single-language clock. The default language is Dutch. For French, German, and English, copy the four-language clock code between the NL144CLOCK definitions.

#define NLM1M2M3M4L114 -> a 110 LED single language clock with 4 extra LEDs for the minutes and a slightly different design

#define FOURLANGUAGECLOCK-> a 4-language clock with 625 LEDs in a 25 x 25 LED grid.

The libraries.zip file contains the libraries needed to compile the software.
Unzip them into the libraries folder. This folder is usually located between the folder containing the sketches.

Board: Arduino Nano ESP32

Partition scheme: with FAT

Pin numbering : By GPIO number ( legacy )

Problems

If the LEDs do not light up, there is a good chance that the pin numbering setting
( By GPIO number ( legacy )) is set to By Arduino pin (default).

More than one clock has been selected in the defines around line 50

Bluetooth not working

After version ESP32Arduino_WordClockV060, NimBLE version 2.0 must be used.

For version ESP32Arduino_WordClockV060 only NimBLE version 1.4.3 works

 

If this does not work, try the ' Alternative software installation' method .

Alternative software installation



As described further on, software can also be installed 'Over the Air' on the Nano ESP32.

The advantage is that you don't have to install the libraries and in a few years you won't have problems with incompatible libraries .

Compiling is then complete, and the file uploaded to the Nano ESP32 is saved as a .bin file. Various .bin file versions can be found on GitHub.

https://github.com/ednieuw/Arduino-ESP32-Nano-Wordclock

- Select the Nano ESP32 as the board (Tools->Board- ArduinoESPboards ->Arduino Nano ESP32)

- Examples , search for ArduinoOTA -> and open the OTAWebUpdater program

- Choose Sketch->Upload or press the upload button at the top left

- Open the serial monitor and see which IP address is printed.
(If nothing prints, press the white reset button on the Nano ESP32.)

- Enter this IP address into the URL of a browser ( eg : 192.168.0.123)

- Login with admin and with password admin

- Find the .bin file and press update
(For example 'ESP32Arduino_WordClockV057.inoNL114.bin' This is version V057 with settings for the NL114 clock)

 Operating the clock

To connect to a Wi-Fi network, you must enter an SSID (Wi-Fi name) and password.
There are a few methods:
Connect the MCU in the clock to a PC with a micro-USB-serial cable and use a serial terminal.
Use a BLE serial terminal app on a phone or tablet to connect.

For a PC, the Serial monitor in the Arduino IDE is recommended.
For iOS use: BLE Serial Pro or BLESerial nRF .
For Android use: Serial Bluetooth terminal .

Bluetooth Low Energy (BLE) can use two protocols: CC25nn or nRF52nn, where nn is a specific number. This clock uses nRF52.
- Launch the app and initiate a connection with the clock.

 Some apps automatically launch with a connection window, but others require pressing a connection icon. There will likely be one station, the word clock, to select from.
- Select the clock from the list.
The app will display a window and a line where you can enter and send commands to the clock.
- Pressing the letter I or i for information displays the menu, followed by the actual settings for various preferences. A single "i" displays the short menu. Double "i" (ii) displays a longer menu with many clock settings.

 The clock has an LED with a red dot that lights up when the program is running.
A green dot lights up when a Wi-Fi connection is established. When a Bluetooth connection is established, a blue dot lights up in the LED.

In both cases, press the letter i for Information and the short menu will appear .
The long menu will appear with ii

Enter the first letter of the setting you want to change, followed by a code.
Some items only toggle between On and Off. For example, enter W to turn Wi-Fi On or Off.

To change the SSID and password:
Enter A or a followed by the Wi-Fi station's name and B or b followed by the password.

Amy-SSID and send this command. For example, AFRITZ!Box01 or aFRITZ!Box01. It doesn't matter whether it's uppercase or lowercase.

Then follows the letter B with the password.
Bmypassword and send the password.

Cbroadcastname changes to the name that appears in the Bluetooth connection list.
For example, something like: cWordClock

If the length of the SSID and/or password is less than 5 characters, the WIFI will be automatically turned off.

Use a minimum of 8 characters for the SSID and password.
Check in the menu (third line from the bottom) that Wi-Fi and NTP are enabled.

Enter @ to restart the Nano ESP32.

It will restart and connect.
Sometimes the clock needs to be reset a second or third time before it can connect to Wi-Fi. If the connection still isn't established, check the password you entered.

When WIFI is connected , the LED on the Nano ESP32 will flash green.

____________________________________

F Own colour (Hex FWWRRGGBB)

I Menu, II long menu

N Display off between Nhhhh (N2208)

O Display On/Off

Q Display color choice (Q0)

R Reset settings, @ Restart

___________________________________

Display off between: 10pm - 8am

Display choice: Rainbow

RandomDisplay is OFF

Slope: 30 Min: 20 Max: 255

BLE name: ESP32Test

IP address: 192.168.178.172/update

WIFI=On NTP=On BLE=On FastBLE =Off

15/10/2025 09:08:18

___________________________________

__________________________________

A SSID B Password C BLE beacon name

D Date (D15012021) T Time (T132145)

E Timezone (E<-02>2 or E<+01>-1)

F Own colour (Hex FWWRRGGBB)

G Scan WIFI networks

H H001 rotary, H002 membrane (H000)

I Info menu , II long menu

J DS3231 RTC module On/Off

K LDR reads/sec On/Off

N Display off between Nhhhh (N2208)

O Display On/Off

P Status LED On/Off

Q Display choice (Q0) ~ Changing

R Reset settings, @ Restart

U Demo ( msec ) (U200) Y LED test

S Slope , L Min, M Max (S50 L5 M200)

W WIFI X NTP& Z WPS CCC BLE + Fast BLE

#nnn Selftest , RTC: ! See, & Update

) HETISWAS On/Off, ( EdSoft On/Off

Ed Nieuwenhuys Oct 2025

___________________________________

Display off between: 10pm - 8am

Display choice: Rainbow

RandomDisplay is OFF

Slope: 30 Min: 20 Max: 255

SSID: FRITZ!BoxEd

BLE name: ESP32Test

IP address: 192.168.178.172/update

Timezone:CET-1CEST,M3.5.0,M10.5.0/3

WIFI=On NTP=On BLE=On FastBLE =Off

Rotary=Off Membrane=Off DS3231=Off

WS2812 strip with 148 LEDs (switch %)

Software: ESP32_WordClockV116.ino
| Short (i) and long (ii) menu display

By default, the time zone is set to Amsterdam time.
A reset using the R option in the menu will return the time zone to Amsterdam. To set a different time zone, send the timezone string, preceded by the character E or e.
Many time zones are printed at the bottom of this manual.
For example, if you live in Australia/Sydney, send the string,

eAEST-10AEDT,M10.1.0,M4.1.0/3.

The clock uses Daylight Savings Time (DST) when connected to an NTP server, but not when the DS3231 time module is used

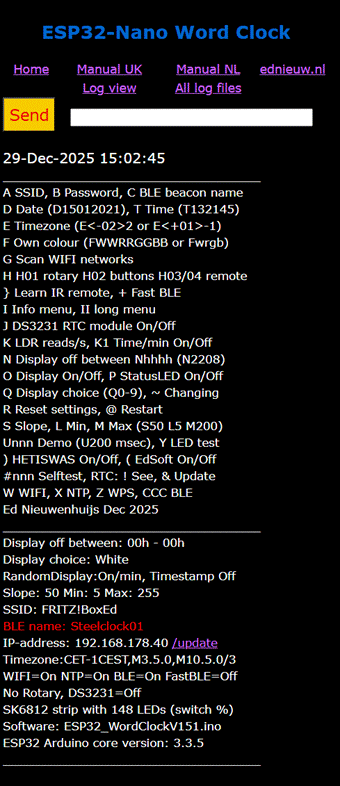
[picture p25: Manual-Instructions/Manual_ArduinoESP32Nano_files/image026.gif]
 | 
HTML page | “ Serial monitor” screen from a PC

Using the remote control

The clock can be equipped with an infrared (IR) receiver. Using a suitable remote control, you can set the time and select one of the many color schemes the clock can display.

- In the menu on the PC or BLE app, turn on the IR remote control using H03 or H04 for a smaller IR remote control. This has fewer codes:
MIN-1, MIN+1, HOUR-1, HOUR+1, POWER, ONOFF.

- Restart the clock with @.

- Send { to teach the clock the remote control key codes.

Not all remotes will work.

- The software will ask you to press the following keys.

"0", "1", "2", "3", "4", "5", "6", "7", "8", "9", "UP", "DOWN", "LEFT", "RIGHT", "POWER", "OK","ONOFF"

If a specific key isn't on your keyboard, choose a similar one.
For example, choose the Source button when prompted to press ONOFF.

Do not use the same key for different codes.

=== Starting Learning Mode ===

Please press button: 0

Learning IR started

It is five past half past twelve LDR:110= 3% 173860 l/s 12:36:40

=== Starting Learning Mode ===

Please press button: 0

Learning IR started

It is five past half past twelve LDR:110= 3% 173860 l/s 12:36:40

Remote identified - Protocol: NEC, Address: 0xBD00

✓ Learned '0' - Protocol: NEC, Command: 0x0041, Address: 0xBD00

Please press button: 1

✓ Learned '1' - Protocol: NEC, Command: 0x0015, Address: 0xBD00

Please press button: 2

✓ Learned '2' - Protocol: NEC, Command: 0x0016, Address: 0xBD00

Please press button: 3

✓ Learned '3' - Protocol: NEC, Command: 0x0017, Address: 0xBD00

Please press button: ONOFF

✓ Learned 'ONOFF' - Protocol: NEC, Command: 0x0008, Address: 0xBD00

===Learning Complete & Saved! ===

Stored Button Mappings:

___________________________________

IR Remote Address : 0xBD00

IR Remote Protocol : NEC

___________________________________

0 -> Cmd : 0x0041

5 -> Cmd : 0x001A

6 -> Cmd : 0x001B

7 -> Cmd : 0x001D

8 -> Cmd : 0x001E

9 -> Cmd : 0x001F

UP -> Cmd : 0x000B

DOWN -> Cmd : 0x000F

LEFT -> Cmd : 0x0049

RIGHT -> Cmd : 0x004A

POWER -> Cmd : 0x0001

OK -> Cmd : 0x000D

ONOFF -> Cmd : 0x0008

___________________________________

=== Now in Recognition Mode ===

Only responding to remote with Address: 0xBD00

Press any learned button to test....

Press POWER to process the key presses at a time. POWER ON

Press POWER again to stop time entry. POWER OFF
With POWER OFF the digits will change the Display choice

- Press POWERON to set the time.

- Enter six numbers as hhmmss .
For example, a quarter to four in the afternoon: 154500

- or use UP and DOWN to adjust the HOUR up or down and LEFT and RIGHT to adjust the minutes up or down.

- Press POWER again to stop time entry.
After 5 minutes, the POWER will automatically turn off.

- With the large remote control, the number keys can be used to change the clock's
color display (option Q in the menu). With both the large and small remote controls, the ONOFF key turns the display on or off.

Clock settings

 The clock's settings can be controlled via the Wi-Fi webpage or the Bluetooth BLE terminal app.
When the clock is connected to Wi-Fi, it receives an IP address from the router it's connected to.
The IP address is printed in the menu.

To start the menu as a web page, the IP address of the clock must be entered into a web browser (for example: 192.168.178.77)

local instead as a URL in the browser. (Default after a reset: wordclock.local )

Or use a Bluetooth connection:
- Open the BLE Terminal app. - In the app, find the clock to connect to and connect.

Each app has its own way of displaying the Bluetooth device to connect to.

The iPhone/iPad/iMac BLE serial apps are my own and work with their default settings. Other apps may need to change the settings for sending and receiving data. Play around with the font size and the CR and LF settings until you
can speed up the transfer speed on an iPhone, iPad, or iMac with the BLE serial app by selecting the "+ Fast BLE" option. in the menu

Unfortunately, some apps can't read strings longer than 20 characters, and you'll see them truncated or garbled.
If lines are printed incompletely, enter a "+" to select a slower transmission mode.
If the transmission is too garbled and it's impossible to send the + sign, try the clock's webpage and send a + sign.

If all else fails, you should connect the Arduino Nano ESP32 in the clock to a PC with a USB-C cable and use the Arduino IDE to send a + or send the letter R to reset the clock to its default settings.

Adjust the display light intensity



In the menu the light intensity of the display can be adjusted with three parameters:

--Light intensity settings (1-250)--

S=Slope L=Min M=Max (S80 L5 M200)

LDR Default values are shown in ().

S Controls how quickly the light output of the LEDs reaches maximum brightness.

L How bright the screen remains in complete darkness.

M the maximum brightness of the screen .

The lower half of the menu displays the saved values

Slope: 80 Min: 5 Max: 255

The clock responds to light with its LDR (light dependent resistor).

When it gets dark, the display doesn't turn off completely but remains dimmed at a minimum value. The
L parameter controls the minimum brightness. This brightness can be set between 0 and 255.
L5 is the default value.

The maximum display brightness is controlled by the M parameter . It also has a value between 0 and 255. By default, it is set to a maximum of 255.
Parameter S controls the slope of how quickly the display reaches maximum brightness.

 These values also vary between 0 and 255. By default, it is set to 80.

Settings are set by entering the first character of a command, followed by parameters if necessary.

For example:
To set the color of the words on the clock to white, enter: Q2

To turn the clock off between 10pm and 8am send: n2208

Turn off WIFI by sending a W.

Restart the clock by sending the letter @.

Reset to default setting by sending R.

 | 
HTML page | BLE menu

Update the software

The software can be updated over the air when the clock is connected to Wi-Fi. The IP address is listed in the menu.

Enter the IP address of the clock directly, without a space, followed by /update.

 Something like this: 192.168.178.141/update.

Or use: http://BLEbroadcastname.local/update

instead of the IP address.

In this case: redpcbv01.local/update.
(Sometimes http:// can be omitted.)



From the menu, select 'Choose File' and select the bin file you want to update.

Something like: ESP32Arduino_WordClockV100.ino.bin

where V100 is the software version number.

 

Detailed menu description:

The menu allows you to set many preferences. These preferences are stored in the ESP32 storage and are retained during power failures.

Enter the first character in the menu for the item to be modified, followed by the parameter.
For example, N2208 to turn off the clock light between 10:00 PM and 8:00 AM.
Uppercase and lowercase letters are not distinguished; both are acceptable.

When the clock is started and connected to a PC using a USC-C serial cable, the startup log data is printed in the Arduino IDE's serial terminal.

Serial started

Rotary NOT used

Rotary available

Found I2C address: 0X57

Found I2C address: 0X68

External RTC module IS found

DS3231 RTC software started

Mem.Checksum = 25065

Stored settings loaded

LED strip is SK6812

LED strip started

BLE started

10: networks found

1: FRITZ!BoxEd -47 * -- Will connect to

2: NETGEAR_EXT -69

3: FRITZ!BoxEd -71 * -- Will connect to

4: H369A209CE1 -75 *

5: H3baas -81 *

6: H369A209CE1 -81 *

7: FRITZ!Box -82 *

8: H369A209CE1 -83 *

9: FRITZ!Box 5490 IS -83 *

10: FRITZ!Box 5490 XL -84 *

[ WiFi -event] event: 0 : WiFi interface ready

[ WiFi -event] event: 2 : WiFi client started

[ WiFi -event] event: 4 : Connected to access point

[ WiFi -event] event: 7 : Obtained IP address: 192.168.178.199

IP Address: 192.168.178.199

Web page started

WIFI started

01/01/2000 00:06:42

___________________________________

___________________________________

A SSID B Password C BLE beacon name

D Date (D15012021) T Time (T132145)

E Timezone (E<-02>2 or E<+01>-1)

F Own colour (Hex FWWRRGGBB)

G Scan WIFI networks

H H001 rotary, H002 membrane (H000)

I Info menu , II long menu

J Toggle use DS3231 RTC module

K LDR reads/sec toggle On/Off

N Display off between Nhhhh (N2208)

O Display toggle On/Off

P Status LED toggle On/Off

Q Display color choice (Q0)

R Reset settings, @ = Reset MCU

U Demo (msec) (U200) Y LED test

--Light intensity settings (1-250)--

S Slope , L Min, M Max (S50 L5 M200)

W WIFI X NTP& Z WPS CCC BLE + Fast BLE

#nnn Selftest , RTC: ! See, & Update

Ed Nieuwenhuys April 2025

___________________________________

A SSID B Password C BLE beacon name
Enter the SSID and password of the router the clock should connect to.
The Bluetooth broadcast name displayed in the Bluetooth Serial Terminal app can be changed.
For example: a FRITZ!Box or A FRITZ!Box .
Then enter the password. For example: B password .

If necessary, enter c Bluetooth Name (default after a reset: wordclock )
Restart the clock by sending @ .

CCC Entering CCC or ccc enables or disables BLE.

Be careful when turning it off. If BLE is disabled, the clock can only be controlled via Wi-Fi or the USB-serial port.

D Set Date and T Set Time
If there's no Wi-Fi time connection and an RTC DS3231 is connected, the date must be set manually.
For example, enter: D06112022 to set the date to November 6, 2022.

For example, enter T132145 (or 132145, or t132145) to set the time to 45 seconds and 21 minutes past one.
Changing the date and time only works if Wi-Fi and NTP are disabled.

E Set time zone E<-02>2 or E<+01>-1
At the bottom of this page are the time zones in use in 2022.
It's a pretty complicated string, so it's wise to copy it.
Let's choose one if you live here: Antarctica/ Troll ,"<+00>0<+02>-2,M3.5.0/1,M10.5.0/3"
Copy the string between the " "'s and send it starting with an 'E' or 'e' in front of it.
E<+00>0<+02>-2,M3.5.0/1,M10.5.0/3

F Own color ( Hex WWRRGGBB or Fwrgb )

(Type 0xff00ff in a browser to make colors hexadecimal on a website of your choice)

Or, if you can't handle hexadecimal, enter a decimal number between 0 and 9 after the F for White, Red, Green, and Blue, respectively.
0 is off and 9 is 100% on. F0900 is red, F0009 is blue, and F0920 is orange-red.

With the hexadecimal colors there is a choice of 255 gradations instead of the current 10.

The color of the words displayed in the clock can be customized and can be selected using option Q3 or Q4 in the menu.

The format to be entered is hexadecimal. 0123456789ABCDEF are the characters that can be used.

The command consists of 2 numbers for white followed by 2 numbers for Red followed by 2 for Green and ending with 2 numbers for Blue.

color the letters intense green, enter F 00 00 FF 00 , preceded by the letter F. To color the letters intense red, enter FF0000, preceded by the character F.

F 00 00 00 FF

To set intense blue, enter F000000FF.

For example: F8800FF00 is 50% white and 100% green.

In short: 00 is LED off, 44 is 25%, 88 is 50%, BB is 75%, and FF is 100%.



WS2812 LED strips do not have a white LED and the command to control the white has no effect.

The SK6812 LEDs have an extra white LED (yellow area) next to the three RGB LEDs.

Which LEDs are mounted in the clock is shown at the bottom of the long menu (ii)
WS2812 strip with 148 LEDs (switch %)

G Scan for nearby WIFI networks
Sending 'G' will print the available nearby networks in the Bluetooth BLE terminal.

H H01 rotary H02 buttons H03/04 remote
By sending ' Hnn ' you can select whether an optional rotary knob ( H01 ), a (membrane) push button ( H02 ), or a remote control will be used to set the time and date.
The internal, then mandatory, DS3231 RTC will then be automatically switched on and the NTP time will be switched off.

H03 is a large remote control with numbers and H04 is for a small version without numbers.

H00 option if the input is not being used to prevent accidental input.

After a Factory Reset, the usage of this setting is left unchanged.

Learn IR remote

To use a remote control, the clock must first learn the infrared code a button sends.
Not all remote controls can be programmed.

With option H03 , the large remote control, the following keys are programmed:

“0”, “1”, “2”, “3”, “4”, “5”, “6”, “7”, “8”, “9”, “UP”, “DOWN”, “LEFT”, “RIGHT”, “POWER”, “OK”, “ONOFF”.

When the POWER button is not pressed, the keys "0", "1", "2", "3", "4", "5", "6", "7", "8", and "9" select the display modes. The Q codes in the menu. For example, Q2 is white.

The "ONOFF" key switches the clock light on or off.

When the POWER button is pressed, the time can be entered using the number keys for five minutes. After five minutes, the POWER button automatically turns off to prevent accidental changes to the time.

Enter six numbers + "OK".

Press 153612 + "OK" for 15 hours, 36 minutes and 12 seconds

Or simpler:

Press "UP", "DOWN" to decrease or increase the hours and

Press "LEFT", "RIGHT" to decrease or increase minutes.

With a small remote control ( H04 ) it works as follows:

The "ONOFF" key switches the clock light on or off.

Press "POWER" and then the MIN-1, "MIN+1", "HOUR-1", and "HOUR+1" keys to adjust the time.

1 or 2 to display the information menu
. Print the menu.

Option I (i) in the menu selects a short menu for everyday use or option II (2x i) for a long menu with all options.

J Switch to use the time from the DS3231 module
Sending 'Y' toggles the use of the optional DS3231 time module ON or OFF.
When the time from the DS3231 RTC module is used, the yellow LED near the USB connector on the Nano ESP32 will stop flashing. If the clock is not connected to the internet, the time will expire quickly.
Using the DS3231 time module reduces the deviation to a few seconds per year.

The time can be entered into the DS3231 time module using option T (time) and D (date) in the menu.

If the time isn't visible, send the ! command to see the internal clock times.

Toggle K Reads/sec
By entering a K the LDR reading of the measured light intensity per second can be monitored.
It also shows how many times per second (l/s) the processor is running through the program and checking its tasks to keep the clock running.

TestLDR : On

LDR reading, %Out, loops per second and time

LDR: 1= 1% 205413 l/s 16:06:08

LDR: 1= 1% 215535 l/s 16:06:09

LDR: 1= 1% 215451 l/s 16:06:10

LDR: 1= 1% 215350 l/s 16:06:11

TestLDR : Off

By default, the time is printed in the logs every minute. The web page can display thousands of log lines. Logging per minute can be switched on or off with K1, and per hour with K2.
The long menu (ii) will then display Timestamp/min, Timestamp/ hour , or Timestamp off.

N Display off between Nhhhh (N2208)
N2208 turns off the display between 22:00 and 08:00.

O Switch display on/off
O Switches the display off and on.

Turn
status LEDs on and off P Turns the status LEDs on the Arduino Nano on and off.

Q Display color selection (Q0-9)
Q0 displays the time with yellow words

and IT (or THE) will change from green to yellow to red within an hour.

and will change IS or WAS from green to red to yellow within a minute.
Q1 will display a different color every hour.
Q2 displays all text in white.
Q3 uses custom-defined colors.

(The colors can be set with option F in the menu)

Q4 uses its own defined colors. (IT IS/WAS changes color from green to red.)

Q5 will cycle through the rainbow colors in an hour.
Q6 is a digital display

Q7 will display a different color every hour. (IT IS/WAS changes color from green to red.)

Q8 will go through the rainbow colors in 4 minutes.

Q9 will cycle through the rainbow colors in 15 seconds.

R Reset Settings
R resets all preferences to their default settings.

The SSID, password, BLE name, and time zone are not cleared.
RRR does clear the last four. Wi-Fi, NTP, and BLE are enabled.

RRRRR is a combination of the R and RRR options.
The LED strip type and the use of a rotary or membrane button remain unchanged.

Perform a reset with RRRRR, a total reset, when the sketch is first uploaded to the Arduino Nano ESP32.

S = Slope L = Min M = Max (S50 L5 M200)
S How quickly the brightness reaches maximum brightness.
L How bright the display is in complete darkness. M The maximum brightness of the display.
Values between 0 and 250

U Demo Mode ( msec ) (U200)

Enter U followed by the duration of a second in milliseconds.

U200 (200 milliseconds) speeds up the clock 5 times.

Sending only a U will disable demo mode.

W=WIFI, X=NTP & , CCC=BLE
Turn WIFI and NTP on and off.
Enter the character to enable or disable the option.
It is indicated at the bottom of the menu.
Bottom menu

Sending an & will set the NTP time into the internal Nano ESP32 RTC and DS3231 time module.

Y LED test

All LEDs will go through a rainbow.

Z WPS

WPS is a method for obtaining the password and the Wi-Fi access point's name (SSID) from the router.
If the Wi-Fi router has a WPS button, the clock can be connected to the internet without having to enter the router's name and password.

Start WPS on the clock by entering Z in the menu, and then start WPS on the Wi-Fi router. If all goes well, the clock will restart and the time will be correct.

Sometimes you need to hold the WPS button on the router for a few seconds.

How to start WPS differs per router.

+ = Fast BLE
The BLE UART protocol sends Standard packets are 20 bytes long. There is a 50 msec delay between each packet .
The iOS BLEserial app, and perhaps others, can receive packets of 80 bytes or more before missing any characters. This allows the menu to print faster.
Option + toggles between long and short packets.

~ = Change display mode per minute or hour

~ Starts the display mode change option and changes every minute.
~1 changes the display mode every minute.

~2 changes the display mode every hour.

~0 or ~ disables the toggle option.

In the long menu (ii) you will then see RandomDisplay : On/min, On/ hour or Off

! = Show NTP, RTC, and DS3231 time
! will display the NTP, RTC, and DS3231 time as stored in the clock. The DS3231 time module must be installed for the module to display a realistic time.
The same as the & option, but this option will not be updated from the internet NTP server; it only displays the time.

#nnn = Selftest
Sending a # will start the clock self-test. This is useful for checking that all words in the clock are functioning.

Starting in V062, #nnnn is also possible. Nnnn is the millisecond delay between each word.

The self-test will stop automatically after one cycle.

% = Switch between SK6812 and WS2812 LED strips
. This option allows you to switch the LED strip in use. The clock is equipped with one of these two types of LED strips.

Resetting all settings by sending an R in the menu does not change the LED strip selection.

$ = Fireplace
Displays a fireplace on a 144 LED clock . The result will be less attractive on other types of clocks.

( = Turns additional optional LEDs On/Off

The clock can optionally be equipped with an additional logo text.

) = Turns IT/IS/WAS On/Off

IT WAS always remains out

= = Shows the permanent setting.
The = option prints all settings.

@ = Restart the clock
@ restarts the clock. This is useful if the SSID, etc., changes and the program needs to be restarted.
Settings are preserved.

& = Update with NTP
Synchronizes the RTC module with the NTP time
The RTC time module in the clock can control the time. The T and D menu options allow you to manually enter the time and date.
This option copies the NTP time to the RTC module.

The computer inside the clock has its own internal clock. This clock moves forward seconds per day and is regularly updated with the NTP time or the DS3231 RTC time module. If NTP and the DS3231 RTC time module are disabled, the clock will still display the time, but after a few days, it will become out of sync with the correct time.

123456 Setting the time in the DS3231 RTC time module

Enter the time as 152300 hhmmss . Same as T152300.
Changing the date and time only works if NTP is disabled.

Time zones

Copy the text between the quotes and paste it after the E (or e) character and send it to the clock.

For the Netherlands and Belgium send: eCET-1CEST, M3.5.0, M10.5.0/3

Africa /Abidjan,'GMT0'

Africa /Accra,'GMT0'

Africa /Addis_Ababa,'EAT-3'

Africa /Algiers,'CET-1'

Africa /Asmara, "EAT-3"

Africa/Bamako,'GMT0'

Africa/Bangui,"WAT-1"

Africa/Banjul,'GMT0'

Africa/Bissau,'GMT0'

Africa/Blantyre,"CAT-2"

Africa/Brazzaville,"WAT-1"

Africa/Bujumbura,'CAT-2'

Africa/Cairo, "EET-2"

Africa/Casablanca,"<+01>-1"

Africa/Ceuta,"CET-1CEST,M3.5.0,M10.5.0/3"

Africa/Conakry,"GMT0"

Africa/Dakar, 'GMT0'

Africa/Dar_es_Salaam,"EAT-3"

Africa/Djibouti,"EAT-3"

Africa/Douala,"WHAT-1"

Africa/ El_Aaiun ,"<+01>-1"

Africa/Freetown, 'GMT0'

Africa/Gaborone,"CAT-2"

Africa/Harare, "CAT-2"

Africa/Johannesburg,'SAST-2'

Africa/Juba,"CAT-2"

Africa/Kampala, "EAT-3"

Africa/Khartoum,"CAT-2"

Africa/Kigali,"CAT-2"

Africa/Kinshasa,'WHAT-1'

Africa/Lagos,"WAT-1"

Africa/Libreville,"WHAT-1"

Africa/Lome,'GMT0'

Africa/Luanda, "WHAT-1"

Africa/Lubumbashi,"CAT-2"

Africa/Lusaka,'CAT-2'

Africa/Malabo, "WHAT-1"

Africa/Maputo,"CAT-2"

Africa/Maseru,"SAST-2"

Africa/Mbabane,'SAST-2'

Africa/Mogadishu, 'EAT-3'

Africa/Monrovia,'GMT0'

Africa/Nairobi, 'EAT-3'

Africa/Ndjamena,"WAT-1"

Africa/Niamey,"WAT-1"

Africa/Nouakchott,'GMT0'

Africa/Ouagadougou,'GMT0'

Africa/Porto-Novo, "WAT-1"

Africa/Sao_Tome,'GMT0'

Africa/Tripoli, "EET-2"

Africa/Tunis, 'CET-1'

Africa/Windhoek,"CAT-2"

America/Adak,"HST10HDT,M3.2.0,M11.1.0"

America/Anchorage,"AKST9AKDT,M3.2.0,M11.1.0"

America/Anguilla, "AST4"

America / Antigua , "AST4"

America / Araguaina ,"<-03>3"

America /Argentina/ Buenos_Aires ,"<-03>3"

America /Argentina/Catamarca,'<-03>3'

America /Argentina/ Cordoba ,"<-03>3"

America /Argentina/Jujuy,"<-03>3"

America /Argentina/ La_Rioja ,"<-03>3"

America /Argentina/Mendoza,"<-03>3"

America /Argentina/ Rio_Gallegos ,"<-03>3"

America /Argentina/Salta,"<-03>3"

America /Argentina/ San_Juan ,"<-03>3"

America /Argentina/ San_Luis ,"<-03>3"

America /Argentina/ Tucuman ,"<-03>3"

America /Argentina/Ushuaia,"<-03>3"

America /Aruba, "AST4"

America / Asuncion ,"<-04>4<-03>,M10.1.0/0,M3.4.0/0"

America /Atikokan,"EST5"

America / Bahia ,"<-03>3"

America /Bahia_Banderas,"CST6CDT,M4.1.0,M10.5.0"

America /Barbados, "AST4"

America /Belem,"<-03>3"

America / Belize , "CST6"

America /Blanc- Sablon , "AST4"

America / Boa_Vista ,"<-04>4"

America / Bogota ,"<-05>5"

America/Boise,"MST7MDT,M3.2.0,M11.1.0"

America/Cambridge_Bay,"MST7MDT,M3.2.0,M11.1.0"

America/ Campo_Grande ,"<-04>4"

America/Cancun, "EST5"

America/Caracas,"<-04>4"

America/Cayenne,"<-03>3"

America/Cayman,"EST5"

America/Chicago,"CST6CDT,M3.2.0,M11.1.0"

America/Chihuahua,"MST7MDT,M4.1.0,M10.5.0"

America/Costa_Rica,"CST6"

America/Creston,"MST7"

America/ Cuiaba ,"<-04>4"

America/Curacao, "AST4"

America/Danmarkshavn,'GMT0'

America/Dawson,"MST7"

America/Dawson_Creek,"MST7"

America/Denver,"MST7MDT,M3.2.0,M11.1.0"

America/Detroit,"EST5EDT,M3.2.0,M11.1.0"

America /Dominica, "AST4"

America /Edmonton,"MST7MDT,M3.2.0,M11.1.0"

America / Eirunepe ,"<-05>5"

America /El_Salvador,"CST6"

America /Fortaleza,"<-03>3"

America /Fort_Nelson,"MST7"

America /Glace_Bay,"AST4ADT,M3.2.0,M11.1.0"

America / Godthab ,"<-03>3<-02>,M3.5.0/-2,M10.5.0/-1"

America/Goose_Bay,"AST4ADT,M3.2.0,M11.1.0"

America/Grand_Turk,"EST5EDT,M3.2.0,M11.1.0"

America/Grenada, "AST4"

America/Guadeloupe, "AST4"

America/Guatemala, "CST6"

America/Guayaquil,"<-05>5"

America/Guyana,"<-04>4"

America /Halifax,"AST4ADT,M3.2.0,M11.1.0"

America /Havana,"CST5CDT,M3.2.0/0,M11.1.0/1"

America /Hermosillo, "MST7"

America/Indiana/Indianapolis,"EST5EDT,M3.2.0,M11.1.0"

America/Indiana/Knox,"CST6CDT,M3.2.0,M11.1.0"

America/Indiana/Marengo,"EST5EDT,M3.2.0,M11.1.0"

America/Indiana/Petersburg,"EST5EDT,M3.2.0,M11.1.0"

America/Indiana/Tell_City,"CST6CDT,M3.2.0,M11.1.0"

America/Indiana/Vevay,"EST5EDT,M3.2.0,M11.1.0"

America/Indiana/Vincennes,"EST5EDT,M3.2.0,M11.1.0"

America/Indiana/Winamac,"EST5EDT,M3.2.0,M11.1.0"

America/Inuvik,"MST7MDT,M3.2.0,M11.1.0"

America/Iqaluit,"EST5EDT,M3.2.0,M11.1.0"

America/Jamaica,"EST5"

America/Juneau,"AKST9AKDT,M3.2.0,M11.1.0"

America/Kentucky/Louisville,"EST5EDT,M3.2.0,M11.1.0"

America/Kentucky/Monticello,"EST5EDT,M3.2.0,M11.1.0"

America / Kralendijk , "AST4"

America / La_Paz ,"<-04>4"

America /Lima,"<-05>5"

America /Los_Angeles,"PST8PDT,M3.2.0,M11.1.0"

America /Lower_Princes,"AST4"

America / Maceio ,"<-03>3"

America /Managua, "CST6"

America / Manaus ,"<-04>4"

America / Marigot , "AST4"

America / Martinique , "AST4"

America /Matamoros,"CST6CDT,M3.2.0,M11.1.0"

America/Mazatlan,"MST7MDT,M4.1.0,M10.5.0"

America/Menominee,"CST6CDT,M3.2.0,M11.1.0"

America/Merida,"CST6CDT,M4.1.0,M10.5.0"

America/Metlakatla,"AKST9AKDT,M3.2.0,M11.1.0"

America /Mexico_City,"CST6CDT,M4.1.0,M10.5.0"

America / Miquelon ,"<-03>3<-02>,M3.2.0,M11.1.0"

America /Moncton,"AST4ADT,M3.2.0,M11.1.0"

America /Monterrey,"CST6CDT,M4.1.0,M10.5.0"

America /Montevideo,"<-03>3"

America /Montreal,"EST5EDT,M3.2.0,M11.1.0"

America /Montserrat,"AST4"

America /Nassau,"EST5EDT,M3.2.0,M11.1.0"

America /New_York,"EST5EDT,M3.2.0,M11.1.0"

America /Nipigon,"EST5EDT,M3.2.0,M11.1.0"

America/Nome,"AKST9AKDT,M3.2.0,M11.1.0"

America/Noronha,"<-02>2"

America/ North_Dakota /Beulah,"CST6CDT,M3.2.0,M11.1.0"

America/ North_Dakota /Center,"CST6CDT,M3.2.0,M11.1.0"

America/ North_Dakota /New_Salem,"CST6CDT,M3.2.0,M11.1.0"

America/Nuuk,"<-03>3<-02>,M3.5.0/-2,M10.5.0/-1"

America/Ojinaga,"MST7MDT,M3.2.0,M11.1.0"

America/Panama, "EST5"

America/Pangnirtung,"EST5EDT,M3.2.0,M11.1.0"

America/Paramaribo,"<-03>3"

America/Phoenix, "MST7"

America/Port-au-Prince,"EST5EDT,M3.2.0,M11.1.0"

America/Port_of_Spain,"AST4"

America/ Porto_Velho ,"<-04>4"

America/Puerto_Rico,"AST4"

America/ Punta_Arenas ,"<-03>3"

America/Rainy_River,"CST6CDT,M3.2.0,M11.1.0"

America/Rankin_Inlet,"CST6CDT,M3.2.0,M11.1.0"

America/Recife,"<-03>3"

America/Regina, "CST6"

America/Resolute,"CST6CDT,M3.2.0,M11.1.0"

America/ Rio_Branco ,"<-05>5"

America/Santarem,"<-03>3"

America/Santiago,"<-04>4<-03>,M9.1.6/24,M4.1.6/24"

America/Santo_Domingo,"AST4"

America/ Sao_Paulo ,"<-03>3"

America/ Scoresbysund ,"<-01>1<+00>,M3.5.0/0,M10.5.0/1"

America/Sitka,"AKST9AKDT,M3.2.0,M11.1.0"

America/St_Barthelemy,"AST4"

America/St_Johns,"NST3:30NDT,M3.2.0,M11.1.0"

America/St_Kitts,"AST4"

America/St. Lucia,"AST4"

America/St_Thomas,"AST4"

America/St_Vincent,"AST4"

America/Swift_Current,"CST6"

America/Tegucigalpa, "CST6"

America/Thule,"AST4ADT,M3.2.0,M11.1.0" America/Thunder_Bay,"EST5EDT,M3.2.0,M11.1.0"

America /Tijuana,"PST8PDT,M3.2.0,M11.1.0"

America/Toronto,"EST5EDT,M3.2.0,M11.1.0"

America/Tortola, "AST4"

America/Vancouver,"PST8PDT,M3.2.0,M11.1.0"

America/Whitehorse,"MST7"

America/Winnipeg,"CST6CDT,M3.2.0,M11.1.0"

America/Yakutat,"AKST9AKDT,M3.2.0,M11.1.0"

America/Yellowknife,"MST7MDT,M3.2.0,M11.1.0"

Antarctica/Casey,"<+11>-11"

Antarctica/Davis,"<+07>-7"

Antarctica/ DumontDUrville ,"<+10>-10"

Antarctica/Macquarie,"AEST-10AEDT,M10.1.0,M4.1.0/3"

Antarctica/ Mawson ,"<+05>-5"

Antarctica/McMurdo,"NZST-12NZDT,M9.5.0,M4.1.0/3"

Antarctica /Palmer,"<-03>3"

Antarctica / Rothera ,"<-03>3"

Antarctica / Syowa ,"<+03>-3"

Antarctica / Troll ,"<+00>0<+02>-2,M3.5.0/1,M10.5.0/3"

Antarctica / Vostok ,"<+06>-6"

Arctic /Longyearbyen,"CET-1CEST,M3.5.0,M10.5.0/3"

Asia/Aden,"<+03>-3"

Asia/Almaty,"<+06>-6"

Asia/Amman,"EET-2EEST,M2.5.4/24,M10.5.5/1"

Asia/Anadyr,"<+12>-12"

Asia/ Aqtau ,"<+05>-5"

Asia/ Aqtobe ,"<+05>-5"

Asia/ Ashgabat ,"<+05>-5"

Asia/Atyrau,"<+05>-5"

Asia/Baghdad,"<+03>-3"

Asia/Bahrain,"<+03>-3"

Asia/Baku,"<+04>-4"

Asia/Bangkok,"<+07>-7"

Asia/Barnaul,"<+07>-7"

Asia/Beirut,"EET-2EEST,M3.5.0/0,M10.5.0/0"

Asia/Bishkek,"<+06>-6"

Asia/Brunei,"<+08>-8"

Asia/ Chita ,"<+09>-9"

Asia/Choibalsan,"<+08>-8"

Asia/Colombo,"<+0530>-5:30"

Asia/Damascus,"EET-2EEST,M3.5.5/0,M10.5.5/0"

Asia/Dhaka,"<+06>-6"

Asia/Dili,"<+09>-9"

Asia/Dubai,"<+04>-4"

Asia/ Dushanbe ,"<+05>-5"

Asia/Famagusta,"EET-2EEST,M3.5.0/3,M10.5.0/4"

Asia /Gaza,'EET-2EEST,M3.4.4/48,M10.5.5/1'

Asia/Hebron,"EET-2EEST,M3.4.4/48,M10.5.5/1"

Asia/ Ho_Chi_Minh ,"<+07>-7"

Asia/Hong_Kong,"HKT-8"

Asia/ Hovd ,"<+07>-7"

Asia/Irkutsk,"<+08>-8"

Asia/Jakarta,"WIB-7"

Asia/Jayapura,"WHITE-9"

Asia/Jerusalem,"IST-2IDT,M3.4.4/26,M10.5.0"

Asia/Kabul,"<+0430>-4:30"

Asia/ Kamchatka ,"<+12>-12"

Asia/Karachi, "PKT-5"

Asia/Kathmandu,"<+0545>-5:45"

Asia/ Khandyga ,"<+09>-9"

Asia/Kolkata,"IST-5:30"

Asia/ Krasnoyarsk ,"<+07>-7"

Asia/ Kuala_Lumpur ,"<+08>-8"

Asia/ Kuching ,"<+08>-8"

Asia/Kuwait,"<+03>-3"

Asia/ Macau , "CST-8"

Asia/ Magadan ,"<+11>-11"

Asia/Makassar,"WITA-8"

Asia/Manila, "PST-8"

Asia/ Muscat ,"<+04>-4"

Asia/Nicosia,"EET-2EEST,M3.5.0/3,M10.5.0/4"

Asia/Novokuznetsk,"<+07>-7"

Asia/Novosibirsk,"<+07>-7"

Asia/Omsk,"<+06>-6"

Asia/Oral,"<+05>-5"

Asia/ Phnom_Penh ,"<+07>-7"

Asia/ Pontianak , "WIB-7"

Asia/Pyongyang,"KST-9"

Asia/Qatar,"<+03>-3"

Asia/ Qyzylorda ,"<+05>-5"

Asia/ Riyadh ,"<+03>-3"

Asia/ Sakhalin ,"<+11>-11"

Asia/Samarkand,"<+05>-5"

Asia/Seoul,"KST-9"

Asia/Shanghai, "CST-8"

Asia/Singapore,"<+08>-8"

Asia/ Srednekolymsk ,"<+11>-11"

Asia/Taipei,"CST-8"

Asia/ Tashkent ,"<+05>-5"

Asia/Tbilisi,"<+04>-4"

Asia/ Tehran ,"<+0330>-3:30<+0430>,J79/24,J263/24"

Asia /Thimphu,"<+06>-6"

Asia/Tokyo,"JST-9"

Asia/ Tomsk ,"<+07>-7"

Asia/Ulaanbaatar,"<+08>-8"

Asia/ Urumqi ,"<+06>-6"

Asia/ Ust-Nera ,"<+10>-10"

Asia/Vientiane,"<+07>-7"

Asia/Vladivostok,"<+10>-10"

Asia/ Yakutsk ,"<+09>-9"

Asia/Yangon,"<+0630>-6:30"

Asia/ Yekaterinburg ,"<+05>-5"

Asia/ Yerevan ,"<+04>-4"

Atlantic/Azores,"<-01>1<+00>,M3.5.0/0,M10.5.0/1"

Atlantic/Bermuda,"AST4ADT,M3.2.0,M11.1.0"

Atlantic/Canary,"WET0WEST,M3.5.0/1,M10.5.0"

Atlantic/ Cape_Verde ,"<-01>1"

Atlantic/Faroe,"WET0WEST,M3.5.0/1,M10.5.0"

Atlantic/Madeira,"WET0WEST,M3.5.0/1,M10.5.0"

Atlantic/Reykjavik, 'GMT0'

Atlantic/ South_Georgia ,"<-02>2"

Atlantic/Stanley,"<-03>3"

Atlantic/St Helena, 'GMT0'

Australia/Adelaide,"ACST-9:30ACDT,M10.1.0,M4.1.0/3"

Australia/Brisbane, 'AEST-10'

Australia/Broken_Hill,"ACST-9:30ACDT,M10.1.0,M4.1.0/3"

Australia/Currie,"AEST-10AEDT,M10.1.0,M4.1.0/3"

Australia/Darwin,"ACST-9:30"

Australia/ Eucla ,"<+0845>-8:45"

Australia/Hobart,"AEST-10AEDT,M10.1.0,M4.1.0/3"

Australia/Lindeman,"AEST-10"

Australia/ Lord_Howe ,"<+1030>-10:30<+11>-11,M10.1.0,M4.1.0"

Australia/Melbourne,"AEST-10AEDT,M10.1.0,M4.1.0/3"

Australia/Perth, "AWST-8"

Australia/Sydney,"AEST-10AEDT,M10.1.0,M4.1.0/3"

Europe/Amsterdam,"CET-1CEST,M3.5.0,M10.5.0/3"

Europe/Andorra,"CET-1CEST,M3.5.0,M10.5.0/3"

Europe/Astrakhan,"<+04>-4"

Europe/Athens,"EET-2EEST,M3.5.0/3,M10.5.0/4"

Europe/Belgrade,"CET-1CEST,M3.5.0,M10.5.0/3"

Europe/Berlin,"CET-1CEST,M3.5.0,M10.5.0/3"

Europe/Bratislava,"CET-1CEST,M3.5.0,M10.5.0/3"

Europe/Brussels,"CET-1CEST,M3.5.0,M10.5.0/3"

Europe/Bucharest,"EET-2EEST,M3.5.0/3,M10.5.0/4"

Europe/Budapest,"CET-1CEST,M3.5.0,M10.5.0/3"

Europe/Busingen,"CET-1CEST,M3.5.0,M10.5.0/3"

Europe/Chisinau,"EET-2EEST,M3.5.0,M10.5.0/3"

Europe/Copenhagen,"CET-1CEST,M3.5.0,M10.5.0/3"

Europe/Dublin,"IST-1GMT0,M10.5.0,M3.5.0/1"

Europe/Gibraltar,"CET-1CEST,M3.5.0,M10.5.0/3"

Europe/Guernsey,"GMT0BST,M3.5.0/1,M10.5.0"

Europe/Helsinki,"EET-2EEST,M3.5.0/3,M10.5.0/4"

Europe/Isle_of_Man,"GMT0BST,M3.5.0/1,M10.5.0"

Europe/Istanbul,"<+03>-3"

Europe/Jersey,"GMT0BST,M3.5.0/1,M10.5.0"

Europe/Kaliningrad, 'EET-2'

Europe/Kiev,"EET-2EEST,M3.5.0/3,M10.5.0/4"

Europe/Kirov,'<+03>-3'

Europe/Lisbon,"WET0WEST,M3.5.0/1,M10.5.0"

Europe/Ljubljana,"CET-1CEST,M3.5.0,M10.5.0/3"

Europe/London,"GMT0BST,M3.5.0/1,M10.5.0"

Europe/Luxembourg,"CET-1CEST,M3.5.0,M10.5.0/3"

Europe/Madrid,"CET-1CEST,M3.5.0,M10.5.0/3"

Europe/Malta,"CET-1CEST,M3.5.0,M10.5.0/3"

Europe /Mariehamn,"EET-2EEST,M3.5.0/3,M10.5.0/4"

Europe /Minsk,'<+03>-3'

Europe/Monaco,"CET-1CEST,M3.5.0,M10.5.0/3"

Europe/Moscow,"MSK-3"

Europe/Oslo,"CET-1CEST,M3.5.0,M10.5.0/3"

Europe/Paris,"CET-1CEST,M3.5.0,M10.5.0/3"

Europe/Podgorica,"CET-1CEST,M3.5.0,M10.5.0/3"

Europe/Prague,"CET-1CEST,M3.5.0,M10.5.0/3"

Europe/Riga,'EET-2EEST,M3.5.0/3,M10.5.0/4'

Europe/Rome,"CET-1CEST,M3.5.0,M10.5.0/3"

Europe/Samara,"<+04>-4"

Europe/San_Marino,"CET-1CEST,M3.5.0,M10.5.0/3"

Europe/Sarajevo,"CET-1CEST,M3.5.0,M10.5.0/3"

Europe/Saratov,"<+04>-4"

Europe/Simferopol,'MSK-3'

Europe/Skopje,"CET-1CEST,M3.5.0,M10.5.0/3"

Europe/Sofia,"EET-2EEST,M3.5.0/3,M10.5.0/4"

Europe/Stockholm,"CET-1CEST,M3.5.0,M10.5.0/3"

Europe/Tallinn,"EET-2EEST,M3.5.0/3,M10.5.0/4"

Europe/Tirane,"CET-1CEST,M3.5.0,M10.5.0/3"

Europe/ Ulyanovsk ,"<+04>-4"

Europe/Uzhgorod,"EET-2EEST,M3.5.0/3,M10.5.0/4"

Europe/Vaduz,"CET-1CEST,M3.5.0,M10.5.0/3"

Europe/Vatican,"CET-1CEST,M3.5.0,M10.5.0/3"

Europe/Vienna,"CET-1CEST,M3.5.0,M10.5.0/3"

Europe/Vilnius,"EET-2EEST,M3.5.0/3,M10.5.0/4"

Europe/Volgograd,"<+03>-3"

Europe/Warsaw,"CET-1CEST,M3.5.0,M10.5.0/3"

Europe/Zagreb,"CET-1CEST,M3.5.0,M10.5.0/3"

Europe/Zaporozhye,"EET-2EEST,M3.5.0/3,M10.5.0/4"

Europe/Zurich,"CET-1CEST,M3.5.0,M10.5.0/3"

Indian /Antananarivo, "EAT-3"

Indian /Chagos,"<+06>-6"

Indian /Christmas,"<+07>-7"

Indian /Cocos,"<+0630>-6:30"

Indian / Comoro , "EAT-3"

Indian /Kerguelen,"<+05>-5"

Indian /Mahe,"<+04>-4"

Indian /Maldives,"<+05>-5"

Indian /Mauritius,"<+04>-4"

Indian /Mayotte,"EAT-3"

Indian / Reunion ,"<+04>-4"

Pacific/Apia,"<+13>-13"

Pacific/Auckland,"NZST-12NZDT,M9.5.0,M4.1.0/3"

Pacific/Bougainvillea,"<+11>-11"

Pacific/Chatham,"<+1245>-12:45<+1345>,M9.5.0/2:45,M4.1.0/3:45"

Pacific/Chuuk,"<+10>-10"

Pacific/Easter,"<-06>6<-05>,M9.1.6/22,M4.1.6/22"

Pacific/Efate,"<+11>-11"

Pacific/ Enderbury ,"<+13>-13"

Pacific/Fakaofo,"<+13>-13"

Pacific/Fiji,"<+12>-12<+13>,M11.2.0,M1.2.3/99"

Pacific/Funafuti,"<+12>-12"

Pacific/Galapagos,"<-06>6"

Pacific/Gambier,"<-09>9"

Pacific /Guadalcanal,"<+11>-11"

Pacific /Guam,"ChST-10"

Pacific /Honolulu, "HST10"

Pacific / Kiritimati ,"<+14>-14"

Pacific / Kosrae ,"<+11>-11"

Pacific / Kwajalein ,"<+12>-12"

Pacific / Majuro ,"<+12>-12"

Pacific /Marquesas,"<-0930>9:30"

Pacific / Midway , "SST11"

Pacific /Nauru,"<+12>-12"

Pacific /Niue,"<-11>11"

Pacific/Norfolk,"<+11>-11<+12>,M10.1.0,M4.1.0/3"

Pacific/ Noumea ,"<+11>-11"

Pacific/Pago_Pago,"SST11"

Pacific/Palau,"<+09>-9"

Pacific/Pitcairn,"<-08>8"

Pacific/Pohnpei,"<+11>-11"

Pacific/ Port_Moresby ,"<+10>-10"

Pacific/Rarotonga,"<-10>10"

Pacific/Saipan,"ChST-10"

Pacific/Tahiti,"<-10>10"

Pacific/Tarawa,"<+12>-12"

Pacific/ Tongatapu ,"<+13>-13"

Pacific/Wake,"<+12>-12"

Pacific/Valais,"<+12>-12"

Etc /GMT,"GMT0"

Etc /GMT-0,"GMT0"

Etc /GMT-1,"<+01>-1"

Etc /GMT-2,"<+02>-2"

Etc /GMT-3,"<+03>-3"

Etc /GMT-4,"<+04>-4"

Etc /GMT-5,"<+05>-5"

Etc /GMT-6,"<+06>-6"

Etc /GMT-7,"<+07>-7"

Etc /GMT-8,"<+08>-8"

Etc /GMT-9,"<+09>-9"

Etc /GMT-10,"<+10>-10"

Etc /GMT-11,"<+11>-11"

Etc /GMT-12,"<+12>-12"

Etc /GMT-13,"<+13>-13"

Etc /GMT-14,"<+14>-14"

Etc /GMT0,"GMT0"

Etc /GMT+0,"GMT0"

Etc /GMT+1,"<-01>1"

Etc /GMT+2,"<-02>2"

Etc /GMT+3,"<-03>3"

Etc /GMT+4,"<-04>4"

Etc /GMT+5,"<-05>5"

Etc /GMT+6,"<-06>6"

Etc /GMT+7,"<-07>7"

Etc /GMT+8,"<-08>8"

Etc /GMT+9,"<-09>9"

Etc /GMT+10,"<-10>10"

Etc /GMT+11,"<-11>11"

Etc /GMT+12,"<-12>12"

Etc /UCT,"UTC0"

Etc /UTC,"UTC0"

Etc /Greenwich,'GMT0'

Etc /Universal,"UTC0"

Etc /Zulu,"UTC0"

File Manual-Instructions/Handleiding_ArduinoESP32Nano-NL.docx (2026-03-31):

# Arduino ESP32-Nano woordklok

Een klok die de tijd in woorden weergeeft in de talen Nederlands, Engels, Frans en Duits in een grote 4-talenklok of als een ééntalige klok.

Een Arduino ESP32 Nano computer in de klok wordt gebruikt om de tijd in de klok aan te sturen en verbinding met WIFI en Bluetooth op te zetten.
De tijd wordt gesynchroniseerd met het Network Time Protocol (NTP) van het internet via een WIFI-verbinding. Daarnaast bestaat de optie om de tijd zonder WIFI of Bluetooth met draai/drukknop gelijk te zetten.
Instellingen kunnen worden beheerd met een webpagina, een PC of een Bluetooth Low Energy (BLE) seriële terminal-app die is geïnstalleerd op een telefoon, pc of tablet.

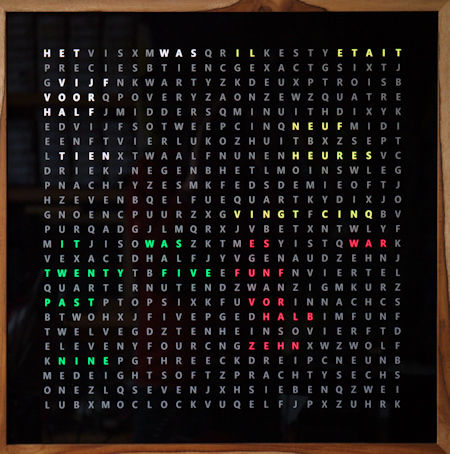
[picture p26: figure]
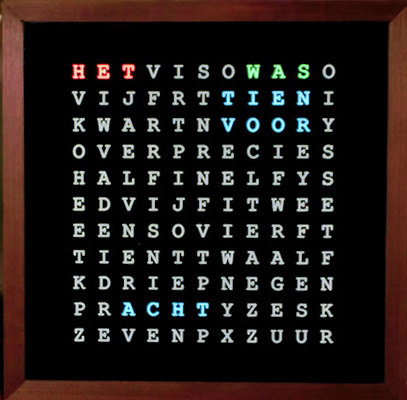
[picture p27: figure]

4-talenklok | Nederlandse taalklok

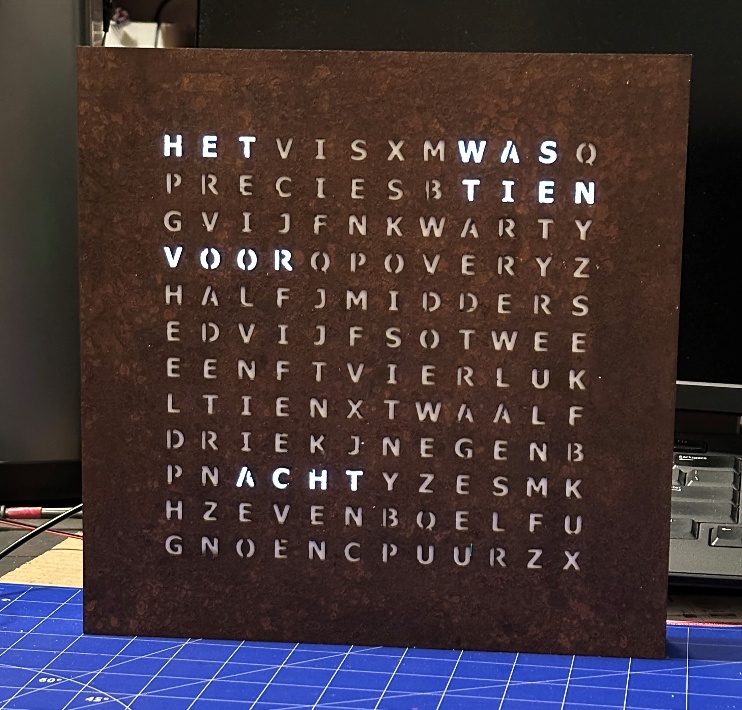
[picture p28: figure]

Cortenstaalklok

Snelle start Zoek één van de volgende apps in de app store. De app wordt gebruikt om commando’s naar de klok te sturen. Of klik open deze link om een alternatief op een W11 /MacOS PC te starten : BLE UART Terminal (https://ednieuw.home.xs4all.nl/BLESerial/BLE_UART_Terminal.html) (https://ednieuw.home.xs4all.nl/BLESerial/BLE_UART_Terminal.html) Mocht de app of BLE UART terminal niet te downloaden zijn lees dan verder hoe de WIFI aan te sluiten. IOS iPhone/iPad/Mac IOS iPhone/iPad/Mac Android BLE Serial Pro (https://apps.apple.com/nl/app/ble-serial-pro/id1632245655) BLESerial nRF (https://apps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

De klok is ingesteld om met WIFI de tijd te ontvangen. Als de naam van de WIFI-router en wachtwoord niet zijn ingevoerd wordt een webpagina gestart om de routergegevens in te voeren.

- Open in een telefoon of tablet bij de WIFI-instellingen het station “StartWordclock”.
- Tik als wachtwoord in: wordclock
- Open daarna de browser op het mobiel en tik in de URL: 162.168.4.1 en druk enter.
- Voer de naam en het wachtwoord van de WIFI-router die in huis gebruikt wordt. Tip: Je kan ook de hotspot van je mobiel voor een WIFI-verbinding gebruiken.

Bluetooth app

Instellen is makkelijker met de Bluetooth app op de telefoon of tablet.

- Open de Bluetooth app.

De IOS app toont een lijst met Bluetooth stations.
Als het te lang duurt. Druk wieltje linksboven (nRF52 is geselecteerd) en druk Done.
Bij Android druk Scan en Connect met de woordklok.

- Stuur het commando: i om het menu te zien

Tik in de letter a gevolgd door de naam van de router en druk Send. (bijv: aNAAMrouter Stuur geen extra punten of spaties.)

- Tik in de letter b gevolgd door het wachtwoord van de router en druk Send. (bijv: bGeHeim1234)
- Stuur @ om de klok te herstarten.

Of start WPS (Een knop op de router met WPS. Lees dit na in de handleiding)

- Druk de WPS-knop en stuur daarna het commando: z in de Bluetooth serial app.
- Als geen WIFI mogelijk is Stuur de letter J in het menu met de Bluetooth app.
- Er verschijnt dan: Use DS3231 is ON. WIFI ON, NTP OFF.
- Stuur een Letter W om WIFI uit te zetten. Stuur @ om de klok te herstarten.
- Stuur de juiste tijd en datum via het menu. (bijv stuur: T143000 voor ‘half drie’ en bijv als datum: D090625)

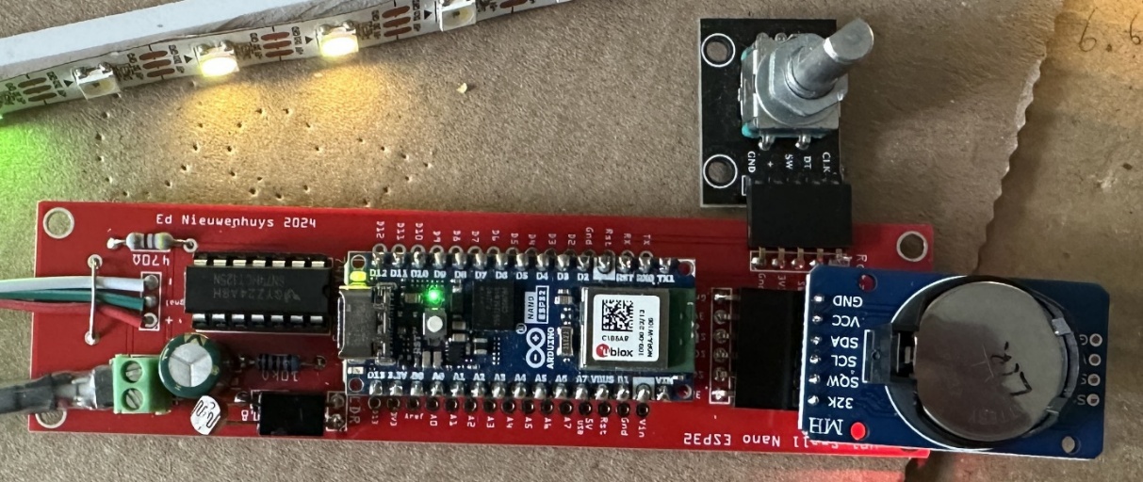
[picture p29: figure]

Klein PCB-ontwerp met Rotary en DS3231 RTC bevestigd

Voor het starten
De klok ontvangt de tijd van het internet als er een WIFI-verbinding is.

Wanneer een DS3231-tijdmodule op de printplaat is bevestigd, is een internetverbinding niet vereist.

Als een draai- of drukknopknop geïnstalleerd is kan deze worden gebruikt om de tijd in te stellen.

Ook kan een infrarood afstandsbediening geïnstalleerd zijn om de tijd in te stellen.

Om verbinding te maken met het internet moet de naam van het WIFI-station en het wachtwoord in de klok-software worden ingevoerd om verbinding te kunnen maken met een WIFI-router.
De naam van het WIFI-station en het wachtwoord moeten eenmalig worden ingevoerd.
De inloggegevens worden opgeslagen in het geheugen van de microprocessor.

Een seriële terminal app op een telefoon, tablet of PC maakt bediening mogelijk zonder de klok met een USB kabel aan een PC te verbinden om de WIFI inlog-gegevens in te voeren.

De klok kan ook via een browser worden aangestuurd als er verbinding is gemaakt met WIFI.

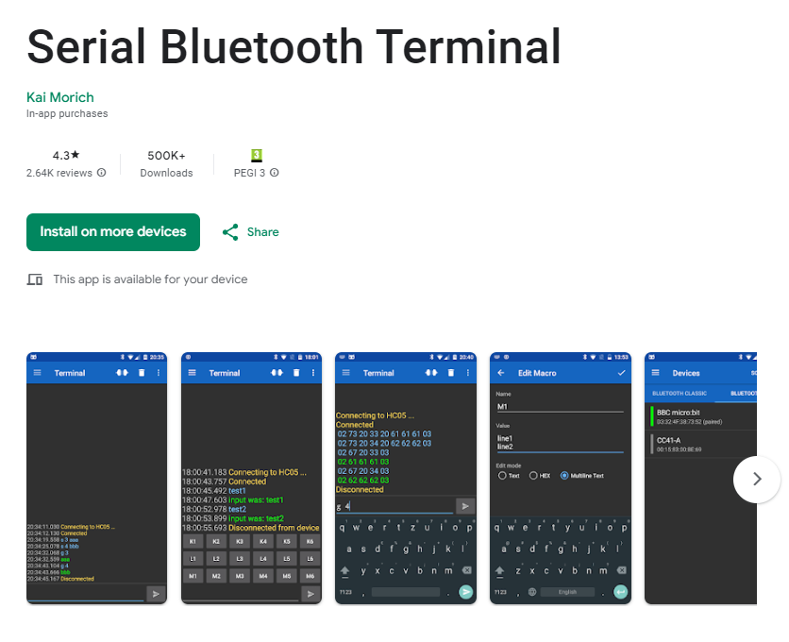
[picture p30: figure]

BLESerial nRF | BLE Serial Pro | Serial Bluetooth-terminal

- Download een Bluetooth UART seriële terminal app op een telefoon, PC of tablet.
Voor IOS: BLE Serial Pro of BLESerial nRF.
Voor Android: Serial Bluetooth-terminal.
Voor een PC: installeer de Arduino IDE op een PC en verbind de klok via een USB-C kabel met de PC.

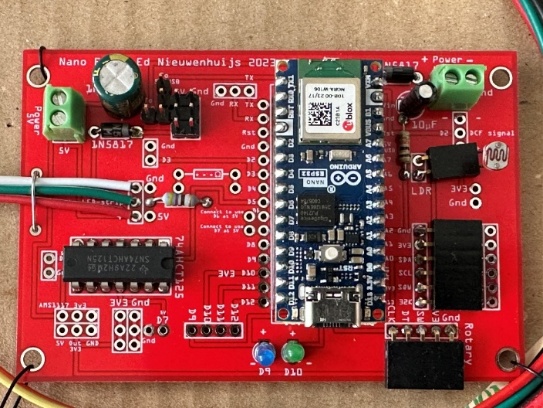
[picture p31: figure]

Arduino ESP32 Nano op de printplaat in de klok.

Eerste bediening

- Sluit de voeding van de klok aan.

Als er geen internetverbinding of Bluetooth-verbinding is, kan de klok worden bediend met de draaiknop, met drie drukknoppen, of een afstandsbediening, of met een tijdzender app op de telefoon, mits deze geïnstalleerd en geactiveerd is. Activeren gebeurd in het menu met optie H01 (draaiknop, H02 drukknoppen, H03 en H04 een IR-afstandsbediening of H05 start tijdonvanger).

Soms zit de knop in de kast gemonteerd.

- Druk op de draaiknop of de middelste knop van de drie drukknoppen.
UUR licht 3 keer op en de uren kunnen worden ingesteld door de knop te draaien of op de omhoog- of omlaag-knop te drukken op de drieknopmembraan.

- Een tweede keer drukken op de knop of de middelste knop laat
HETISWAS knipperen en de minuten kunnen worden gewijzigd.
Seconden worden ingesteld op 0. Dus om precies te zijn, zet de laatste minuut precies op 0 seconden.

- Met een derde keer drukken knippert TWAALF drie keer en kan de lichtintensiteit van de LED's worden ingesteld.

- Met een vierde keer drukken knipperen de tekens NTP en RTC drie keer. Men kan overschakelen van RTC- naar NTP-tijd.

- Negen keer drukken reset de klok naar de fabrieksinstellingen.

Met de IR-afstandsbediening kan de klok bedient worden als deze geleerd is met de klok. Met de { optie in het menu vraagt de klok om knoppen te druken die overeenkomen met de getallen 0-9 en een paar bedieningsknopen zoals POWER.

De tijdontvanger zet de klok binnen twee minuten op tijd als de iPhone app op een telefoon of iPad wordt gestart.

Via WIFI-verbinding

Als de klok voor de eerste keer gestart wordt zal een WIFI-verbinding moeten worden gemaakt.

Als er nog oude verbindingsgegevens in de klok staan voer dan 5 maal hoofdletter R in het menu (RRRRR) in om deze te wissen.

De klokinstellingen staan dan op:

SSID en password zijn leeg

Timezone:CET-1CEST,M3.5.0,M10.5.0/3

WIFI=On NTP=On BLE=On

WPS

WPS is een methode om het wachtwoord en de naam van het WIFI-station, de SSID, uit de router te krijgen..

Start WPS in de klok door Z in het menu in te voeren en start WPS op de WIFI-router. Als alles goed gaat herstart de klok en zal de tijd gelijk staan.

Accespunt in de telefoon

Bij de WIFI-verbindingen in de telefoon (tablet op PC) zal bij de router waarmee je verbonden bent een “StartWordclock” station staan.

- Verbind met het “StartWordclock” station. Gebruik als wachtwoord: wordclock
- Open een browser en tik in: 192.168.4.1 en druk enter.
- Tik in dit scherm de SSID en het password van de WIFI router in en druk Submit

Deze gegevens staan vaak onderop de router.

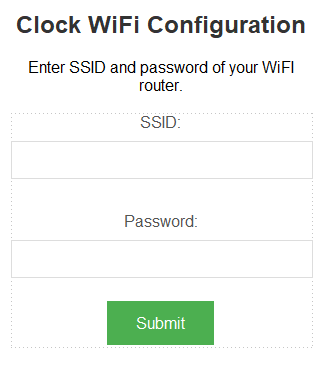
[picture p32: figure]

De klok zal herstarten en de juiste tijd weergeven.

Wanneer de Bluetooth-app op de telefoon of tablet is geïnstalleerd

Met de ‘Bluetooth serial terminal’ app kan de klok via bluetooth worden bedient met je telefoon, tablet of MacOS PC.

- Start de Bluetooth-terminal-app op de telefoon of tablet

- Klik op de verbinding met de naam 'wordclock' in de seriële terminal-app.

- Zoek de inloggegevens van uw WIFI-router.
Zoek de SSID van de router WIFI en het wachtwoord. Deze staan normaal gesproken aan de onderkant van de WIFI-router

Typ in:

- aSSID en druk op Verzenden.
SSID is de naam van de SSID die u bijvoorbeeld op uw telefoon kunt vinden. Het is de naam waarmee WIFI is verbonden.

- bPASSWORD en druk op verzenden.
PASSWORD is het wachtwoord dat u onderop de WIFI-router kunt vinden.

- cBLENAME (optioneel, anders heeft de klok de naam ‘Wordclock’)
De BLENAME is de naam van de klok in de BLE seriële terminal-app en in de verbonden WIFI-router.

Als de Routernaam (SSID) of het wachtwoord niet juist is zal de klok na enkele herstarts weer de Accesspunt pagina (192.168.4.1 ) in de telefoon starten.

Via deze accespuntpagina, Bluetooth of met de USB kabel kan de juiste gegevens worden ingevoerd.

Zie voor uitgebreide uitleg hoofdstuk: Bediening en instellingen van de klok.

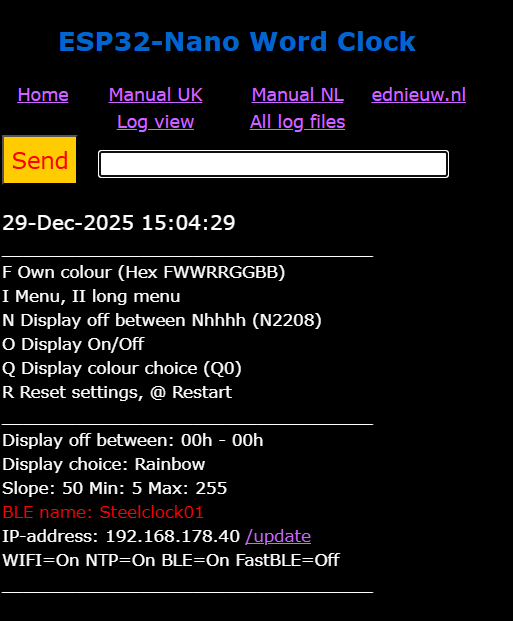
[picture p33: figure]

In de FRITZBox WIFI router is als voorbeeld de klok met de naam “SteelClock-01” met WIFI verbonden. Je kan de webpagina van de klok in een browser starten door te tikken: http://SteelClock-01 or SteelClock-01.local. De standaardnaam is: wordclock en dan wordt de url om de menupagina te starten: wordclock.local.

Met de optie I in het menu wordt gekozen voor een kort menu voor alledaags gebruik of voor een lang menu met optie ii (2x i) voor een uitgebreid menu met alle opties.

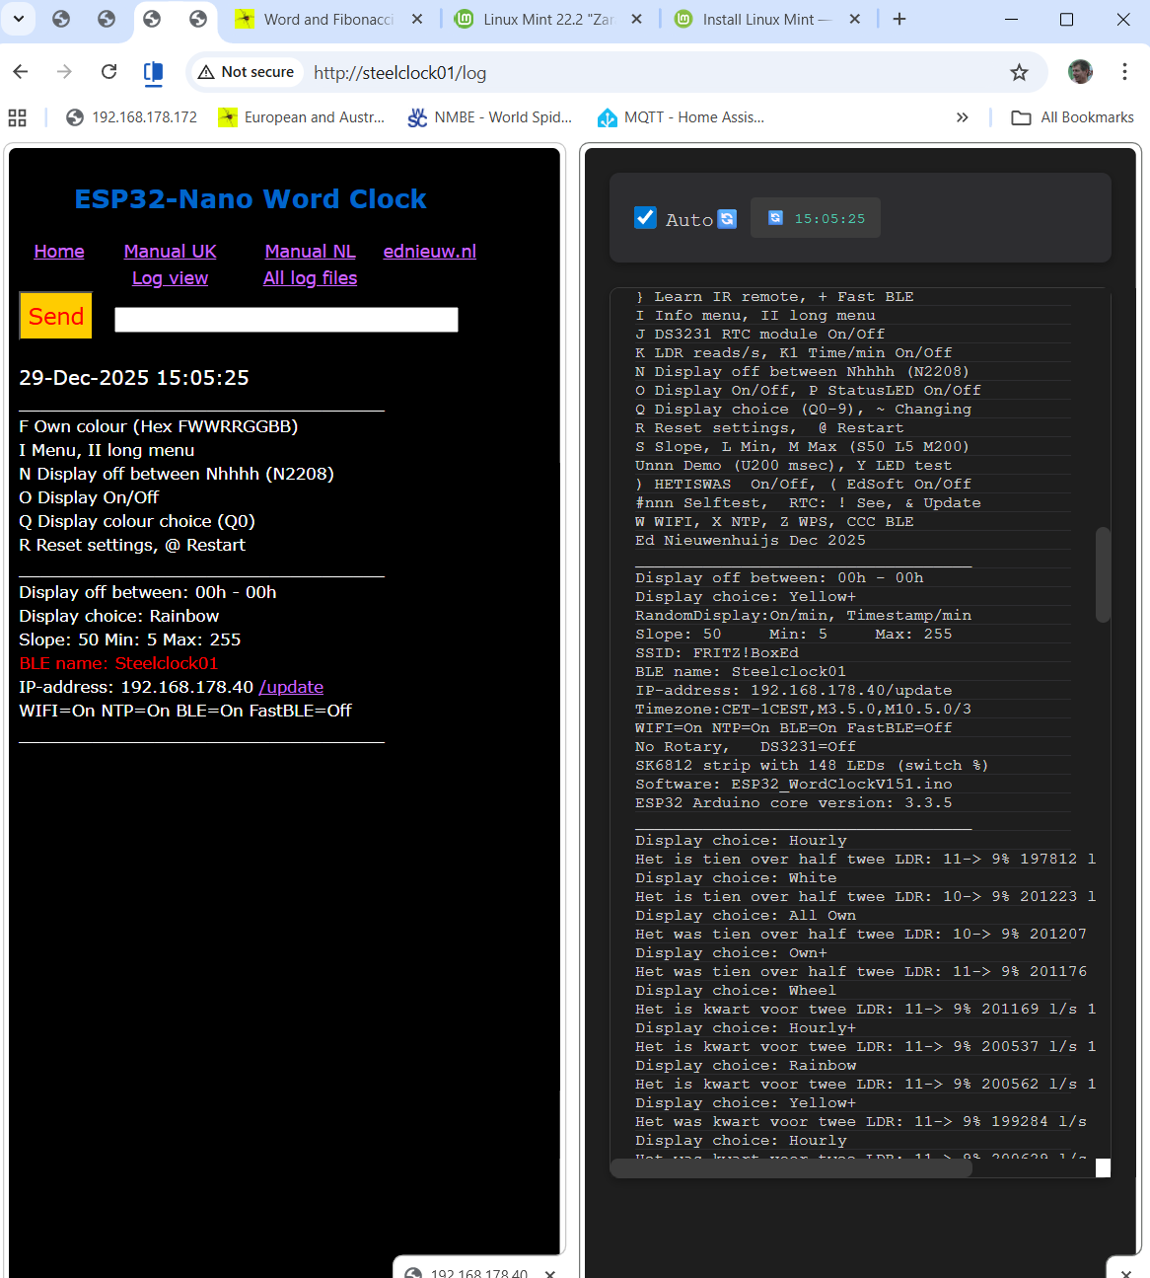
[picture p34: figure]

Door ‘Log view’ boven in de web pagina te klikken wordt de Logviewer gestart. Deze toon de laatste 500 regels die naar de seriële poort of de bluetooth app zijn geprint.
In Chrome kan (december 2025) de TAB gesplitst worden (klik met rechtermuisknop op de TAB en kies ‘split TAB’ o.i.d.) en kan zowel de webpagina als de logviewer getoond worden.
‘All log files’ toont de laatste vele duizenden regels.

Wanneer de draaiknop/rotary encoder of een drieknop membraanknop of een IR-afstandsbediening is geïnstalleerd

Een draai- , drukknoppen of afstandsbediening en de zeer nauwkeurig lopende klok DS3231 RTC zijn optioneel en niet persé nodig. De tijd wordt dan namelijk met het internet gesynchroniseerd.
Deze componenten zijn wel nodig als een klok geen WIFI kan ontvangen.

In het klokmenu kan de rotary encoder (of drie drukknoppen) aan of uit worden gezet.
Zet de rotary met de optie H00 in het menu uit als er geen draai- , drukknoppen of afstandsbediening is geïnstalleerd. (Open het langere instelmenu door ii te sturen).
Zet het gebruik van de DS3231 RTC (menuoptie J) ook uit zodat de tijd van internet wordt gebruikt.

Wanneer draaiknop/rotary encoder is geïnstalleerd

De draaiknop is 60 seconden actief na het drukken op de knop.

- Druk op de draaiknop of de middelste knop van de drie drukknoppen.
UUR licht 3 keer op en de uren kunnen worden ingesteld door de knop te draaien of op de omhoog- of omlaag-knop te drukken op de drieknopmembraan.

- Een tweede keer drukken op de knop of de middelste knop laat
HETISWAS knipperen en de minuten kunnen worden gewijzigd.
Seconden worden ingesteld op 0. Dus om precies te zijn, zet de laatste minuut precies op 0 seconden.

- Met een derde keer drukken knippert TWAALF drie keer en kan de lichtintensiteit van de LED's worden ingesteld.

- Met een vierde keer drukken knipperen de tekens NTP en RTC drie keer.
Men kan overschakelen van RTC- naar NTP-tijd.

- Negen keer drukken reset de klok naar de fabrieksinstellingen.

Wanneer drukknoppen zijn geïnstalleerd

De drukknopen zijn 60 seconden geactiveerd na het drukken van een *

Tik daarna de tijd in met 6 getallen als uummss.

Bijvoorbeeld 134500 voor kwart voor twee.

Na invoer van het 6de getal wordt de tijd vanzelf ingevoerd.

Wanneer een IR-afstandsbediening is geïnstalleerd

Zet de ontvangst met de klok aan met POWER.
Verzend met de grote afstandsbediening (H03 geactiveerd in het menu) de juiste tijd met cijfers als uummss. Dus kwart voor drie als 144500 in de middag of als 024500 in de ochtend.
Of gebruik met een kleine afstandsbediening (H04 geactiveerd in het menu) de knoppen Up en Down en CH+ en CH- om de minuten en of uren te veranderen.

Met ONOFF kan de verlichting van de klok worden uit- of aangezet.

De klokkast maken

De bouw van de klokkast met verlichting is hier te vinden:

https://ednieuw.home.xs4all.nl/Woordklok/Bouwpakket/WoordklokSK6812.htm

of hier: https://github.com/ednieuw/Arduino-ESP32-Nano-Wordclock

Bouwinstructie van een 4-talige woordklok met SK6812 LEDs in het UK, NL, DE, FR met Nano. https://github.com/ednieuw/FourLanguageClock

Compilatie en uploaden

De software draait op een Arduino Nano ESP32.

Deze software wordt met de Arduino IDE gecompileerd en naar de Nano ESP32 geüpload.

Voor elk board dat met de Arduino IDE geprogrammeerd kan worden is een compiler beschikbaar. Deze kan geselecteerd worden in het boards manager menu

Er zijn twee versies beschikbaar voor de Arduino Nano ESP32.

Eén versie, van Arduino zelf, die gebruik maakt van core versie 2. Deze versie is probleemloos in gebruik.

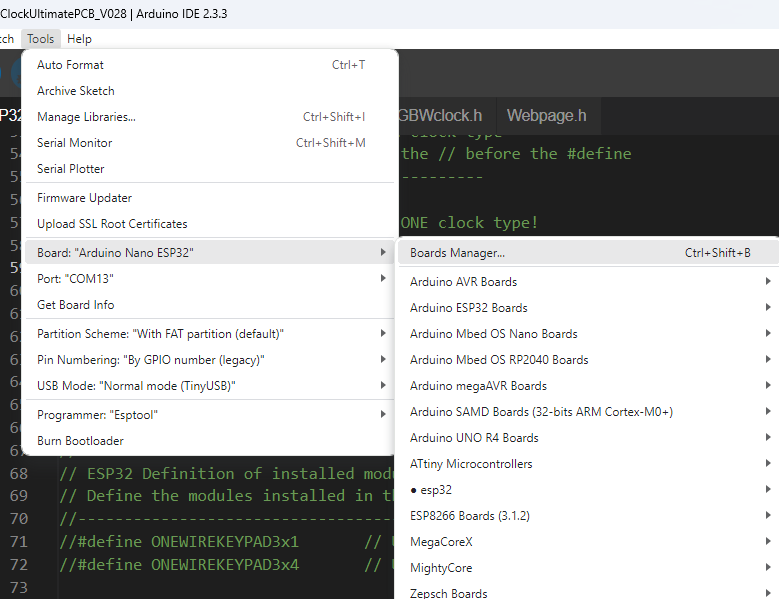
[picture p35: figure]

- Laad het bestand ESP32Arduino_WordClockV0xx.INO in de IDE

Selecteer in de sketch , ergens rond regel 50, een van de drie woordklokken door de twee schuine strepen // weg te halen.

//#define FOURLANGUAGECLOCK

#define NL144CLOCK

//#define NLM1M2M3M4L114 // NL clock with four extra LEDs for the minutes to light up

#define NL144CLOCK -> een 144 LED enkeltalige klok. Standaardtaal is Nederlands. Voor Frans, Duits en Engels kopieer de codering van de viertalige klok tussen de NL144CLOCK-definities.

#define NLM1M2M3M4L114 -> een 110 LED enkeltalige klok met 4 extra LEDs voor de minuten en een iets ander ontwerp

#define FOURLANGUAGECLOCK-> een 4-talenklok met 625 LEDs in een raster van 25 x 25 LEDs.

In de libraries.zip staan de bibliotheken om de software te compileren.
Unzip ze in de libraries-map. Deze folder staat meestal tussen folder met de sketches.

Board: Arduino Nano ESP32

Partitieschema: met FAT

Pinnummering: By GPIO-nummer (legacy)

Problemen

Als de LEDs niet gaan branden, is de kans groot dat de pinnummeringinstelling
(By GPIO-number (legacy) op By Arduino pin (default) staat.

Er is meer dan één klok geselecteerd bij de defines rond regel 50

Bluetooth werkt niet

Na versie ESP32Arduino_WordClockV060 moet NimBLE versie 2.0 worden gebruikt.

Voor versie ESP32Arduino_WordClockV060 werkt alleen NimBLE versie 1.4.3

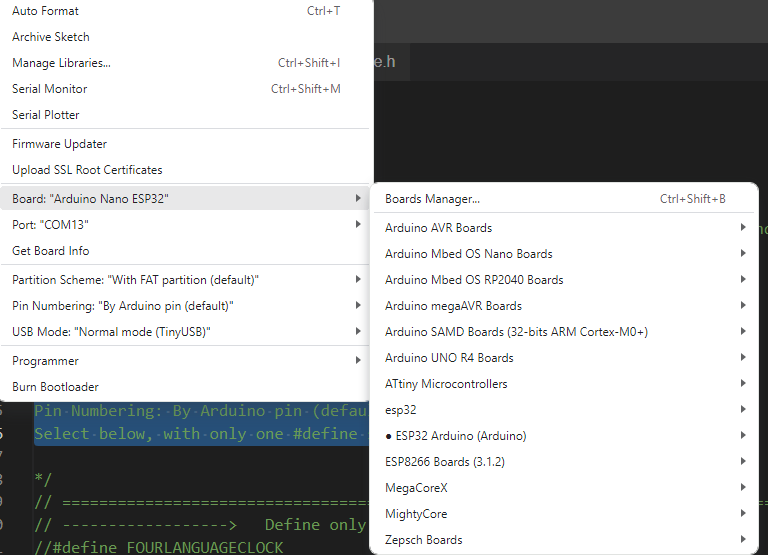
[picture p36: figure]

Lukt het niet probeer dan de methode ‘Alternatieve softwareinstallatie’.

Alternatieve softwareinstallatie

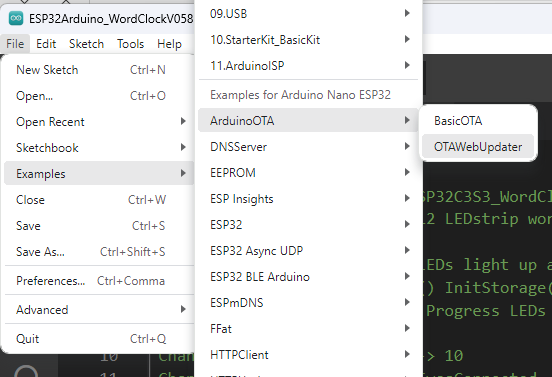
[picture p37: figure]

Zoals verderop is beschreven kan software ook ‘Over the Air’ op de Nano ESP32 worden gezet.

Voordeel is dat je niet de libraries hoeft te installeren en over een paar jaar problemen hebt met niet meer compatibele libraries.

Het compileren is dan al gedaan en het bestand dat naar de Nano ESP32 geüpload wordt is dan als .bin bestand opgeslagen. Op GitHub kunnen diverse .bin-file versies worden gevonden.

https://github.com/ednieuw/Arduino-ESP32-Nano-Wordclock

- Selecteer als board de Nano ESP32 (Tools->Board-ArduinoESPboards->Arduino Nano ESP32)
- Zoek in Examples naar ArduinoOTA -> en open het programma OTAWebUpdater
- Kies Sketch->Upload of druk de upload knop links boven
- Open de seriële monitor en kijk welk IP-adres geprint wordt. (Druk op de witte resetknop op de Nano ESP32 als er niets geprint wordt)
- Tik dit IP-adres in de URL van een browser (bijv: 192.168.0.123)
- Login met admin en met password admin
- Zoek het .bin bestand en druk update (Bijvoorbeeld ‘ESP32Arduino_WordClockV057.inoNL114.bin’ Dit is versie V057 met instellingen voor de NL114 klok)

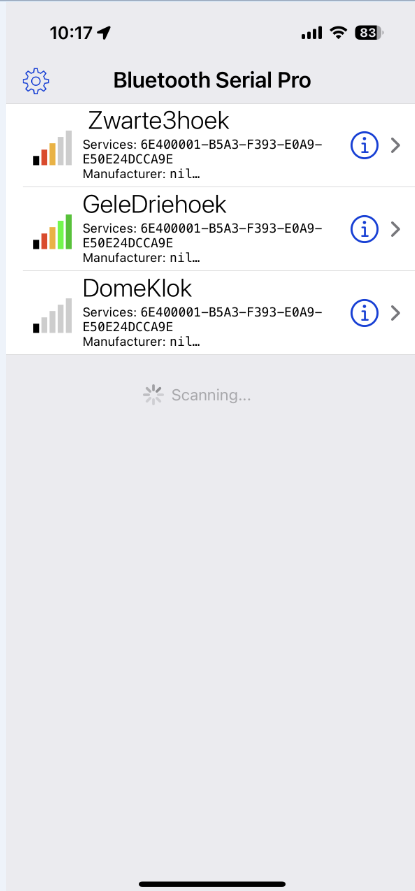
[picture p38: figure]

Bediening van de klok

Om verbinding te maken met een WIFI-netwerk moet een SSID (WIFI-naam) en wachtwoord worden ingevoerd.
Er zijn een paar methoden:
Sluit de MCU in de klok met een micro-USB- seriële kabel aan op een pc en gebruik een seriële terminal.
Gebruik een BLE- seriële terminal-app op een telefoon of tablet voor verbinding.

Voor een PC is de Serial monitor in de Arduino IDE aan te raden.
Voor IOS gebruik : BLE Serial Pro of BLESerial nRF.
Voor Android gebruik: Serial Bluetooth terminal.

Bluetooth Low Energy (BLE) kan twee soorten protocol gebruiken CC25nn of nRF52nn waarbij nn een specifiek nummer is. Deze klok gebruikt nRF52.
- Start de app en start een verbinding met de klok.

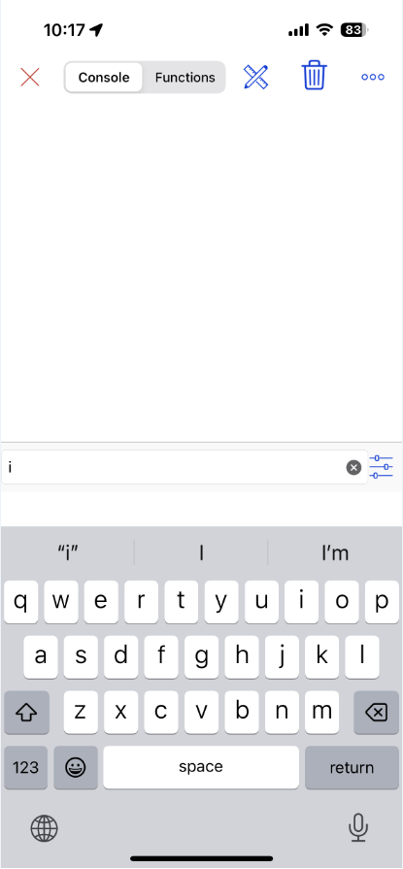
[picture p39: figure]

Sommige apps starten automatisch met een verbindingsvenster, maar voor sommige moet een verbindingssymbool worden ingedrukt. Er is waarschijnlijk één station, de woordklok, om uit te selecteren.
- Selecteer de klok in de lijst.
De app toont een venster en een regel waar opdrachten kunnen worden ingevoerd en naar de klok kunnen worden verzonden.
- Door de letter I of i voor informatie te verzenden, wordt het menu weergegeven, gevolgd door de werkelijke instellingen van verschillende voorkeuren.
Met één i wordt het korte menu getoond. Met dubbel i (ii) verschijnt een langer menu met vele instelmogelijkheden van de klok.

In de klok zit een LED die een rode stip heeft die oplicht als het programma draait.
Een groene stip gaat branden als er een WIFI-verbinding is. Als er een Bluetooth-verbinding is, gaat er een blauwe stip in de LED branden.

In beide gevallen stuur de letter i van Informatie en het korte menu verschijnt .
Het lange menu verschijnt met ii

Voer de eerste letter in van de instelling die je wilt wijzigen, gevolgd door een code.
Sommige items schakelen alleen Aan en Uit. Zoals de W om WIFI Uit of Aan te zetten.


Om de SSID en het wachtwoord te wijzigen:
Verstuur de letter A of a gevolgd door de naam van het wifi -station en B of b gevolgd door het wachtwoord.

Amy-SSID en verstuur deze opdracht. Bijvoorbeeld AFRITZ!Box01 of aFRITZ!Box01. Hoofdletter of kleine letter maakt niet uit.

Daarna volgt de letter B met het wachtwoord.
Bmypassword en verstuur het wachtwoord.

Cbroadcastname verandert in de naam die wordt weergegeven in de Bluetooth-verbindingslijst.
Bijvoorbeeld iets als: cWoordklok

Als de lengte van de SSID en/of het wachtwoord minder dan 5 tekens is, wordt de WIFI automatisch uitgeschakeld.

Gebruik een lengte van minimaal 8 tekens voor de SSID en het wachtwoord.
Controleer in het menu (derde regel van onderen) of WIFI en NTP aan staan.

Voer @ in om de Nano ESP32 opnieuw te starten.

Deze wordt opnieuw opgestart en er wordt verbindingen gemaakt.
Soms moet de klok een tweede of derde keer worden gereset voordat hij verbinding kan maken met WIFI.
Als verbinding nog steeds niet tot stand komt controleer het ingevoerde wachtwoord.

Als WIFI is verbonden, zal de LED op de Nano ESP32 groen knipperen.

____________________________________

F Own colour (Hex FWWRRGGBB)

I Menu, II long menu

N Display off between Nhhhh (N2208)

O Display On/Off

Q Display colour choice (Q0)

R Reset settings, @ Restart

___________________________________

Display off between: 22h - 08h

Display choice: Rainbow

RandomDisplay is OFF

Slope: 30 Min: 20 Max: 255

BLE name: ESP32Test

IP-address: 192.168.178.172/update

WIFI=On NTP=On BLE=On FastBLE=Off

15/10/2025 09:08:18

___________________________________

__________________________________

A SSID B Password C BLE beacon name

D Date (D15012021) T Time (T132145)

E Timezone (E<-02>2 or E<+01>-1)

F Own colour (Hex FWWRRGGBB)

G Scan WIFI networks

H H001 rotary, H002 membrane (H000)

I Info menu, II long menu

J DS3231 RTC module On/Off

K LDR reads/sec On/Off

N Display off between Nhhhh (N2208)

O Display On/Off

P Status LED On/Off

Q Display choice (Q0) ~ Changing

R Reset settings, @ Restart

U Demo (msec) (U200) Y LED test

S Slope, L Min, M Max (S50 L5 M200)

W WIFI X NTP& Z WPS CCC BLE + Fast BLE

#nnn Selftest, RTC: ! See, & Update

) HETISWAS On/Off, ( EdSoft On/Off

Ed Nieuwenhuys Oct 2025

___________________________________

Display off between: 22h - 08h

Display choice: Rainbow

RandomDisplay is OFF

Slope: 30 Min: 20 Max: 255

SSID: FRITZ!BoxEd

BLE name: ESP32Test

IP-address: 192.168.178.172/update

Timezone:CET-1CEST,M3.5.0,M10.5.0/3

WIFI=On NTP=On BLE=On FastBLE=Off

Rotary=Off Membrane=Off DS3231=Off

WS2812 strip with 148 LEDs (switch %)
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

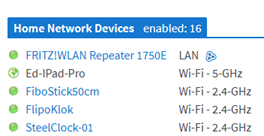
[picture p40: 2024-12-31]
Manual-Instructions/Manual_ArduinoESP32Nano_files/image008.png

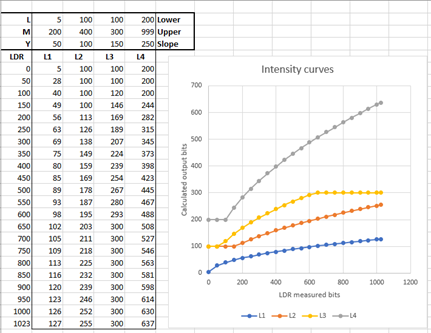
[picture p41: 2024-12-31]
Manual-Instructions/Manual_ArduinoESP32Nano_files/image025.png

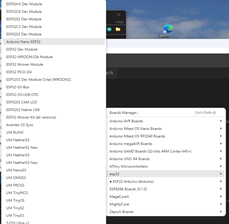
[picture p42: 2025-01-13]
Manual-Instructions/Manual_ArduinoESP32Nano_files/image014.png

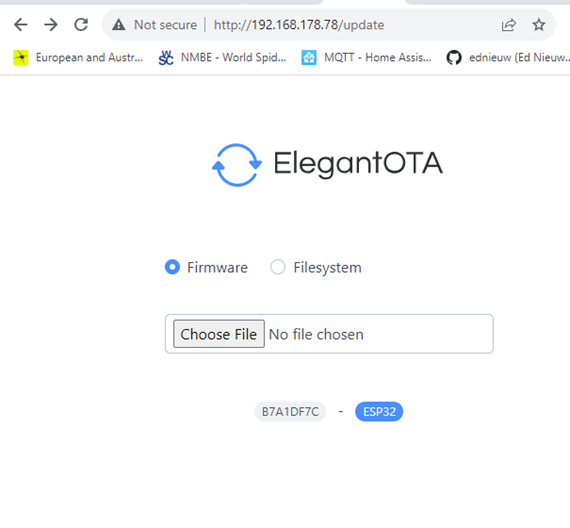
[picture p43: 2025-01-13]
Manual-Instructions/Manual_ArduinoESP32Nano_files/image030.png

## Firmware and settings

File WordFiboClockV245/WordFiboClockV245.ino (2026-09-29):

/* 
 Author      : Ed Nieuwenhuys ednieuw.nl
 Changes V001: Derived from ESP32C3S3_WordClockV026.ino. ...
 Changes V094: Replaced NIMBLE with ESP32 BLE.  ...
 Changes V130: Removed old coding and use NEOPIXEL and use ESPAsyncWebServer. 203222 l/s again instead of 140000. ...
 Changes V199: All Rework in Webpage to CheckWIFIcommand(). 199a Clock logic in ClockLogic.h. Corrected double Menu i and ii on webpage when BLE open.   ...
 Changes V228: Check all clock definitions and corrected error. Added ClearTestStrip().    
 Changes V229: New Name WordFiboClock. Combined WordclockV228 and FibonacciV011. The HC-12 / BLE TimeSender is a new feature (H06). 
 Changes V230: Added Fibo colourpicker. Combined headers. Error with Neopixel wrong pinnumbering.
 Changes V231: Updated comments.      
 Changes V232: Added NOCLOCK. Clockfaces.h,WordClock.h and Fibonacci.h  can be deleted with this option
 Changes V233: Corrected digital clock 
 Changes V234: Added the new RotPressOne/Two/Three entries in all three variant sections.
 Changes V235: Live colour in web menu. log screen wider in main menu
 Changes V236: Added: MQTT CheckMQTT() non-blocking — only runs when Mem.WIFIcredentials == SET_AND_OK and WiFi is actually connected;
 Changes V237: Added: MQTT - HA buttons Y, ~, O, P, @ and Q1-9, Two test sensors: CPU Temperature and LDR Reading, published once/minute. 
               Added: analogWriteResolution(LED_RED, 9); analogWriteFrequency(LED_RED, 5000);  // (same for LED_GREEN, LED_BLUE)
               Added: X in colour when Display is off in HTML menu              
               Added: void InitStatusLEDs(void)
 Changes V238: Make MQTT selectable with Mem.MQTT. Fixed rotary debouncing when no rotary connected
 Changes V239: Default HTML menu page does not zoom in anymore on inputfiled. Removed the auto-focus call — page now opens at the top   
 Changes V240: Cleanup code. MQTT controls added
 Changes V241: Testing
 Changes V242: Added MQTT minbrightness and slopebrightness
 Changes V243: Added Low Power MODEMSLEEP. cut power from 0.25A to 0.20A. Will not use it and V244 will be continued from V242
 Changes V244: Added MQTT sensor for OutPhotocell (LED brightness 0-255 derived from the LDR). Combined all periodic MQTT publishes (CPU temp, LDR, OutPhotocell, display choice, states) into one PublishMQTTStates(), 
               removing duplicate PublishDisplayChoiceState() call on reconnect.
               Fixed OTA upload: a double-click/double-submit on the /update page could fire two concurrent uploads that interleaved writes into Update and corrupted the image (clock never restarted). Client-side now blocks a second submit while one is in flight; server-side now refuses a second concurrent OTA stream (409 BUSY), with a 30s staleness timeout in case a connection drops mid-upload.
 Changes V245: Cleanup code 

*********************
How to compile: 
Install ESP32 boards
Board: ESP32 core version >3.3.10 
Partition Scheme: With FAT
Pin Numbering: By Arduino pin (default)     -- > with EdsoftLED both Pin Numberings can be used
               By GPIO number (legacy)      -- > When using NEOpixel   Adafruit_NeoPixel/esp.c:78:(.text.espShow+0x55): undefined reference to `digitalPinToGPIONumber' when using By Arduino pin
USB mode: Normal (Tiny USB)
**********************
*/
// =============================================================================================================================
// *******  Select below, with only one #define selected, the clock variant *******

// ------------------>   Define only ONE display type below.

#define NL144CLOCK              // Dutch display for 12 x 12 Front
//#define UK144CLOCK              // English display for 12 x 12 Front.
//#define FR144CLOCK              // French display for 12 x 12 Front.
//#define DE144CLOCK              // German display for 12 x 12 Front.
//#define NL92CLOCK               // Dutch display for one LED-strip behind every word
//#define FOURLANGUAGECLOCK       // Four-language clock with 625 LEDs
//#define NLM1M2M3M4L94           // NL clock with four extra LEDs for the minutes to light up
//#define NLM1M2M3M4L114          // NL clock with four extra LEDs for the minutes to light up **
//#define NLM1M2M3M4L144          // NL clock with four extra LEDs for the minutes to light up
//#define NLM1M2M3M4L161          // NL EdSoft Qclock design
//#define NLM1M2M3M4L256          // NL clock with four extra LEDs for the minutes to light up
//#define NLM1M2M3M4L294          // NL clock with four extra LEDs for the minutes to light up
//#define VIERTALENKLOK           // Viertalenklok Ulrich

//   FIBONACCI selects the Fibonacci clock; 
//#define FIBONACCI               // Fibonacci / chrono clock

//   NOCLOCK you can delete Clockfaces.h,WordClock.h and Fibonacci.h 
// #define NOCLOCK
// ------------------>   Derive the build variant from the selection above

//------------------------------------------------------------------------------              //
// ESP32 Definition of installed modules
// The ONEWIRE's are a nice to have options. I leave them as a define for sometime use
// Define the modules installed in the clock by removing the // before the #define
//--------------------------------------------
//#define ONEWIREKEYPAD3x1       // Use a 3x1 keypad with one wire
//#define ONEWIREKEYPAD3x4       // Use a 3x4 keypad with one wire

//------------------------------------------------------------------------------              //
// ESP32 Includes defines and initialisations
//-------------------------------------------
             #if !defined(FIBONACCI) && !defined(NOCLOCK)
#define WORDCLOCK                                                                             // Any non-Fibonacci, non-NOCLOCK selection is a word clock (uses WordClock.h / ClockFaces.h)
             #endif
             #if ESP_ARDUINO_VERSION >= ESP_ARDUINO_VERSION_VAL (3, 3, 0)                     // Use EdSoftLED with ESP32 compiler.
#define USEEDSOFTLED  // Use EdsoftLED >= V1.10.0 for SK6812. Saves 200-500 bytes compared with NeoPixel. To use NeoPixel is also OK but compile: By GPIO number (legacy)
             #endif
             #ifdef USEEDSOFTLED
#include <EdSoftLED.h>         // For LED strip WS2812 or SK6812. https://github.com/ednieuw/EdSoftLED 
             #else
#include <Adafruit_NeoPixel.h> // Compile By GPIO number (legacy) https://github.com/adafruit/Adafruit_NeoPixel
             #endif
//------------------------------------------------------------------------------              //
// Build-environment sanity check - stop the build on an easy-to-miss IDE setting
//--------------------------------------------
             #if !defined(USEEDSOFTLED) && defined(BOARD_HAS_PIN_REMAP)                       // NeoPixel + Tools > Pin Numbering = 'By Arduino pin'
  #error "NeoPixel build with 'Pin Numbering = By Arduino pin'. Set Tools > Pin Numbering to 'By GPIO number (legacy)' (and use GPIO numbers, e.g. LED_PIN = 8) to avoid the 'undefined reference to digitalPinToGPIONumber' link error."
             #endif

#include <Preferences.h>       // For storage
#include <NimBLEDevice.h>      // For BLE communication. !!!Use NimBLE version 2.x.x  https://github.com/h2zero/NimBLE-Arduino
#include <WiFi.h>              // Used for web page 
#include <esp_sntp.h>          // for NTP
#include <esp_wps.h>           // For WPS
#include <ESPAsyncWebServer.h> // Used for webpage  https://github.com/ESP32Async 
#include <Update.h>            // For Over-the-Air (OTA)
#include <ESPmDNS.h>           // To show BLEname in router
#include <DNSServer.h>         // For the web page to enter SSID and password of the WIFI router 
#include <Wire.h>              // Ter zijner tijd Wire functies gaan gebruiken. Staan al klaar in de code 
#include <RTClib.h>            // Used for connected DS3231 RTC. https://github.com/adafruit/RTClib
#include <Encoder.h>           // For rotary encoder. https://github.com/PaulStoffregen/Encoder
#include <Keypad.h>            // For 3x1 membrane keypad by Mark Stanley & Alexander Brevig 
#include <IRremote.hpp>        // IR remote control. https://github.com/Arduino-IRremote/Arduino-IRremote
#include <PubSubClient.h>      // MQTT client, used for Home Assistant discovery. https://github.com/knolleary/pubsubclient PubSubClient3 by Nick O'Leary in library manager

// CLOCK_VARIANT (build name string) is defined per-variant in WordClock.h / Fibonacci.h

//------------------------------------------------------------------------------              //
// PIN Assigments for Arduino Nano ESP32
// Use GPIO numbering when compiling with:  By GPIO number (legacy).
//------------------------------------------------------------------------------ 
 
enum DigitalPinAssignments {      // Digital hardware constants
 SERRX        = D0,               // D0 
 SERTX        = D1,               // D1
 encoderPinB  = D2, //5,          // D2 left (labeled CLK on decoder) *** D8 on large PCB !!! no interrupt pin (Use GPIO pin numbering for rotary encoder lib)  
 encoderPinA  = D3, //6,          // D3 right (labeled DT on decoder) on interrupt pin
 clearButton  = D4, //7,          // D4 switch (labeled SW on decoder)
 IRReceiverPin= D4,               // D4 Infrared receiver pin instead of rotary encoder
 HC12_TX      = D4,               // D4 HC-12 433MHz time sender (TX only). Shares D4 with the IR receiver - cannot use both at once
 HC12_RX      = D6,               // D6 HC-12 Feel free to connect the HC-12 to other unused pins D9, D10 for instance
 LED_PIN      = D5, //8,          // D5 / GPIO 8 Pin to control colour SK6812/WS2812 LEDs (replace D5 with 8 for NeoPixel lib)
 RST_PIN      = 0,                // if 0 then not used D2 / GPIO 5 or D6 Reset pin. Stored in Mem.ResetPin. After reset Mem.ResetPin = RST_PIN
 EmptyD6      = D6,               // D6 / GPIO 9 Empty
 EmptyD7      = D7,               // D7 / GPIO 10 Empty
 encoderPinBL = D8,               // D8 *** If large PCB is used change pin D2 to D8 !!
 PCB_LED_D09  = D9,               // D9
 PCB_LED_D10  = D10,              // D10
 EmptyD11     = D11,              // D11 
 COLPIND12    = D12,              // D12 Used as dummy with KEYPAD
 secondsPin   = D13 //48,         // D13  GPIO48 (#ifdef LED_BUILTIN  #undef LED_BUILTIN #define LED_BUILTIN 48 #endif)
 };

enum AnaloguePinAssignments {     // Analogue hardware constants ----
 EmptyA0      = A0,               // Empty
 EmptyA1      = A1,               // Empty
 PhotoCellPin = A2,               // LDR pin
 OneWirePin   = A3,               // OneWirePin
 SDA_pin      = A4,               // SDA pin
 SCL_pin      = A5,               // SCL pin
 EmptyA6      = A6,               // Empty
 EmptyA7      = A7};              // Empty

//------------------------------------------------------------------------------              //
// Common
//----------------------------------------
char      sptext[255];                                                                        // For common print use 
bool      LEDsAreOff        = false;                                                          // If true LEDs are off except time display
bool      NoTextInLeds      = false;                                                          // Flag to control printing of the text in function ColorLeds()
int       Previous_LDR_read = 512;                                                            // The actual reading from the LDR + 4x this value /5
uint16_t  MilliSecondValue  = 10;                                                             // The duration of a second  minus 1 ms. Used in Demo mode
uint32_t  Loopcounter       = 100;                                                            // ESP will restart if <10. so start with a larger start value
static const uint32_t MCURESTART_RESET_AFTER_MS = 120000;                                     // 2 minutes
static bool mcuRestartCounterCleared = false;
static const uint32_t CLEARBUTTON_DEBOUNCE_MS = 100;                                          // Minimum continuous LOW time on clearButton before a press is accepted 

//------------------------------------------------------------------------------              //
// SPIFFS storage
//--------------------------------------------
Preferences FLASHSTOR;
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
void loop() 
{
 Loopcounter++;
 if (Demo)            Demomode();                                                             // 
 else if(FireDisplay) FireMode();                                                             //
 else                 EverySecondCheck();                                                     // Let the second led tick and run the clock program
 CheckDevices();
}

//--------------------------------------------                                                //
// COMMON Check connected input devices
//--------------------------------------------
void CheckDevices(void)
{
 CheckBLE();                                                                                  // Something with BLE to do?
 SerialCheck();                                                                               // Check serial port every second
 CheckWIFIcommand();                                                                          // Check if there is a command given from the web page
 if(Mem.MQTT) CheckMQTT();                                                                                 // Maintain MQTT connection and publish HA discovery once connected

 if (Mem.TimeInput==1) RotaryEncoderCheck();
 if (Mem.TimeInput==2) Keypad3x1Check();                                                      // 
 if (Mem.TimeInput==3 || Mem.TimeInput==4) IrReceiverDecode();
 if (ntpJustSynced) CheckandPrintNTPsynced();
                                  #ifdef ONEWIREKEYPAD3x4   
 OnewireKeypad3x4Check(); 
                                  #endif  //ONEWIREKEYPAD3x4
                                  #ifdef ONEWIREKEYPAD3x1   
 OnewireKeypad3x1Check(); 
                                  #endif  //ONEWIREKEYPAD3x1
}
//--------------------------------------------                                                //
// COMMON Update routine 
// Performs tasks every second
//--------------------------------------------
void EverySecondCheck(void)
{
 static bool Toggle = 0;
 uint32_t msLeap = millis() - msTick;
 if (msLeap > 999)                                                                            // Every second enter the loop
  {
   msTick = millis();
   GetTijd(false);                                                                            // Get the time for the seconds
   Toggle = !Toggle;                                                                          // Used to turn On or Off Leds
   UpdateStatusLEDs(Toggle);
   SetSecondColour();                                                                         // Set the colour per second of 'IS' and 'WAS' 
   if(Mem.ResetPin) CheckResetPin();                                                          // Check  reset button
  if (Mem.TimeReceiver) CheckTimeReceiverClient();                                            // Check if a TimeSender is in the air
  if (Mem.TimeSender)   CheckTimeSender();                                                    // H06: push time/date over BLE TimeSender (self-throttled to 10s)
   DimLeds(TestLDR);                                                                          // Every second an intensity check and update from LDR reading
   if (shouldReboot)                                                                          // After finish OTA update restarts after 3 seconds. 1 second is too fastú
     {
      if (MQTTclient.connected()) MQTTclient.publish((MQTTDeviceId() + "/status").c_str(), "offline", true); // Tell HA we are going down instead of waiting for the MQTT timeout
      delay(2000);   ESP.restart();
     }
   if (timeinfo.tm_min != lastminute) EveryMinuteUpdate();                                    // Enter the every minute routine after one minute; 
   Loopcounter=0;
  }  
}

//--------------------------------------------                                                //
// COMMON Update routine done every minute
//-------------------------------------------- 
void EveryMinuteUpdate(void)
{
 lastminute = timeinfo.tm_min;
 if(Mem.HC12Time && Mem.TimeLogPrint == 1) SendHC12TimeString();                              // HC-12 broadcast per minute (K1). K2 = per hour, K0 = off
 if (Mem.RandomDisplay == 1) { ChangeRandomDisplay(); SetSecondColour();} 
 if (IR_PowerOnstate && ((millis() - IR_StartTime) > 290000) ) ToggleIRpower();               // Turn off IR Power after 300 seconds 
 CheckMCURestartCounter();                                                                    // MCUrestarted reset-window. Checks if startup went well
 //GetTijd(false);
 bool ff = NoTextInLeds;
 if (Mem.TimeLogPrint == 0 || Mem.TimeLogPrint == 2)                                          // Do not print time but do update the display                                                              // do not Print the time string every minute
    { NoTextInLeds = true; DimLeds(false);  Displaytime();   }
 if (Mem.TimeLogPrint == 1)                                                                   // Print the time string every minute
    { NoTextInLeds = false; DimLeds(true); Displaytime();  Tekstprintln(""); }
 NoTextInLeds = ff;   
 PublishMQTTStates();                                                                       // Publish all HA entities (switch, selects, sensors, diagnostics) once per minute
 
 if(timeinfo.tm_hour != lasthour) EveryHourUpdate();
}
//--------------------------------------------                                                //
// COMMON Update routine done every hour
//--------------------------------------------
void EveryHourUpdate(void)
{
 lasthour = timeinfo.tm_hour;
 if(Mem.HC12Time && Mem.TimeLogPrint == 2) SendHC12TimeString();                              // HC-12 broadcast per hour (K2). K1 = per minute, K0 = off
 if (!Mem.StatusLEDOn) SetStatusLED(0,0,0);                                                   // If for some reason the LEDs are ON and after a MCU restart turn them off.
 bool ff = NoTextInLeds; 
if (Mem.TimeLogPrint == 0 )                                                                   // Do not print time but do update the display                                                              // do not Print the time string every minute
    { NoTextInLeds = true; DimLeds(false);  Displaytime();   }
 if (Mem.TimeLogPrint == 2)                                                                   // Print the time string every hour
    { NoTextInLeds = false; DimLeds(true);  Displaytime();    Tekstprintln(""); }           
 if ((timeinfo.tm_hour == Mem.TurnOffLEDsAtHH) && (Mem.TurnOffLEDsAtHH != Mem.TurnOnLEDsAtHH))
    { LEDsAreOff = true;  ClearScreen(); }                                                    // Is it time to turn off the LEDs?
 if (timeinfo.tm_hour == Mem.TurnOnLEDsAtHH)
    { LEDsAreOff = false;   lastminute = 99;     Displaytime(); Tekstprintln("");}            // Force a minute update
 CheckRestoreWIFIconnectivity();                                                              // Check if WIFI is still connected and if not restore it
 Mem.NVRAMmem[lasthour] = NoofLDRreadshour ? (byte)(SumLDRreadshour / NoofLDRreadshour) : 0;  // Update the average LDR readings per hour. Avoids dividing by zero
 SumLDRreadshour  = 0;
 NoofLDRreadshour = 0;
 if (Mem.RandomDisplay == 2) { ChangeRandomDisplay(); SetSecondColour();}                     // If RandomDisplay is ON change the display choice
 NoTextInLeds = ff;  
 if (timeinfo.tm_mday != lastday) EveryDayUpdate();  
}
//--------------------------------------------                                                //
// COMMON Update routine done every day
//--------------------------------------------
void EveryDayUpdate(void)
{
 lastday           = timeinfo.tm_mday; 
 Previous_LDR_read = ReadLDR();                                                               // To have a start value and reset the Min Max measurements 
 MinPhotocell      = Previous_LDR_read;                                                       // Stores minimum reading of photocell;
 MaxPhotocell      = Previous_LDR_read;                                                       // Stores maximum reading of photocell;                                 
 Tekstprintln(PrintRTCTime());                                                                // Print time as dd-mmm-yy hh:mm:ss
 StoreStructInFlashMemory();                                                                  // Update Mem struct once a day to store Mem.NVRAM measurements
}
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

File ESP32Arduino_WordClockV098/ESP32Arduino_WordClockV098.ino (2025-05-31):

/* 
 Author      : Ed Nieuwenhuys ednieuw.nl
 Changes V001: Derived from ESP32C3S3_WordClockV026.ino
 Changes V003: Clock and SK6812 LEDstrip working
...
 Changes V050: Only first 10 LEDs light up at startup instead of whole LED-string
 Changes V051: Moved In Setup() InitStorage() just after serial started. Setting were read too late  
 Changes V052: Violet startup Progress LEDs added
 Changes V053: Minors
 Changes V053: BLE delay(40) -> 10
 Changes V055: Fine tuned WIFIwasConnected. Minor changes 
               Identical common routines ESP32ArduinoFibonacci_V003 / ESP32WordClockUltimatePCB_V028 / ESP32WordClockV055
 Changes V056: MDNS.begin(BLEbroadcastName). Added  </style> in line 22 of webpage.h. Option Q3 and Q4 were reversed and corrected
 Changes V057: New design NLM1M2M3M4L94 --> NLM1M2M3M4L114
 Changes V058: Removed WhiteColour and --> white. void Laatzien(int Delaymsec). Last used Color in digital display. WIFI custom name in router
 Changes V059: Added KEYPAD3x1
 Changes V060: NimBLE version 1.4.3 -> 2.1.2 upgrade:
                void onConnect(BLEServer* pServer) {deviceConnected = true; };
                void onDisconnect(BLEServer* pServer) {deviceConnected = false;}
                void onWrite(BLECharacteristic *pCharacteristic) 
                To:
                void onConnect(NimBLEServer* pServer, NimBLEConnInfo& connInfo) override {deviceConnected = true;Serial.println("Connected" ); };
                void onDisconnect(NimBLEServer* pServer, NimBLEConnInfo& connInfo, int reason) override {deviceConnected = false;Serial.println("NOT Connected" );}
                void onWrite(NimBLECharacteristic *pCharacteristic, NimBLEConnInfo& connInfo) override  
                added: pAdvertising->setName(BLEbroadcastName);   after pAdvertising->addServiceUUID(SERVICE_UUID); 
 Changes V061: Added  NLM1M2M3M4L256. Added DS3231 OnOff in menu.
 Changes V062: Selftest(msec). NTP library https://github.com/gmag11/ESPNtpClient crashes with core 3.1.0
               R reset does not erase SSID, PWD and BLEstation but command RRR does erase SSID, PWD and BLEstation
               Removed extra CR, LF etc in ReworkInputString
 Changes V063: Removed WiFiGotIP() and to_upper()
 Changes V064: Added WIFI router credentials login page  
 Changes V065: Added Dynamic menu web page. Removed //sptext[0]=0 from tekstprint() . 
 Changes V066: Cleaning code  
 Changes V067: Stable
 Changes V068: Fancier web page. Documentation updated. RRR en RRRRR option for reset 
 Changes V069: Added Mem.WIFIcredentials to test if the SSID/PWD were set in AP-mode but were wrong. 
               After ESP32 restart the StartWordclock WIFI station will be restarted.
               Wire.begin(); // Keep Wire.begin close to the first I2C start to avoid WireTimeout()
 Changes V070: Added M1M2M3M4 in NL144. Added Option Q9 HET IS WAS on or Off
 Changes V071: Removed #include <ESPNtpClient.h>      // https://github.com/gmag11/ESPNtpClient
 Changes V072: German lay-out for single language clock
 Changes V073: Turned off WIFIevents
 Changes V074: ESP32 V3.2.0 and ADAfruit Neopixel 1.12.5 works.
 Changes V075: Added WPS (Option Z in menu) and added "remove WIFI Eventhandler" to stop the WIFI events WiFi.removeEvent(wifiEventHandler);
 Changes V076: Added Fire
 Changes V077: Own OTA added. Removed <ElegantOTA.h>
 Changes V078: WprintTekstln optimized
 Changes V079: OTA restart after update and back to Menu-html page
 Changes V080: cleanup
 Changes V081: Added 92 LEDs NL design. Minor changes in the menu. 
 Changes V082: Date-time in header HTML-page 
 Changes V083: Mem.PreExtraLEDs
 Changes V084: Removed Mem.PreExtraLEDs. Repaired RotaryEncoder. Must use GPIO ports for encoder library and rewrote rotary coding.
 Changes V085: Minor changes
 Changes V086: Semaphore test - failed
 Changes V087: Semaphore test - failed 
 Changes V088: Use of rotary and DS3231 usage optimized in menu. NTP off when DS3231 and rotary on. 
 Changes V089: In webpage last input removed from url
 Changes V090: Added LEDstrip update semaphore mutex
 Changes V091: Replaced AsyncWebserver en AsyncTCP with standard ESP32 Webserver library. This app does not need Async. (NB loop counts drops from 210000 to 1000 loops/sec)
 Changes V092: Compiles with ESP32 core 3.2.0 and Adafruit NeoPixel at version 1.13.0. Removed EdSoftLED.h
 Changes V093: Added Small menu
 Changes V094: Replaced NIMBLE with ESP32 BLE
 Changes V095: Cleanup code. New function LEDstartup. Webserver to core 1. Loop is again 210,000L/s -> xTaskCreatePinnedToCore(WebServerTask,"WebServerTask", 4096, NULL, 1, NULL, 1 ); 
 Changes V096: Removed ESP32 BLE. Caused restarts in ESP32 3.2.0. NimBLE works fine and probably better.
 Changes V097: Webpage remembers and also shows last small or long menu display
 Changes V098: Cleanup code in ReworkInputString(). Changed if(Mem.WIFIcredentials == SET_AND_OK)  WiFi.reconnect(); in every minute. After power faillure the clock starts faster than a WIFI-router
               .bin upload repaired. Did not upload since V091
 Changes V099:                
How to compile: 
Install ESP32 boards
Board: Arduino Nano ESP32
Partition Scheme: With FAT
Pin Numbering: By GPIO number (legacy). Not 'By Arduino pin (default)'

Select below, with only one #define selected, the clock type

*/
// =============================================================================================================================
// ------------------>   Define only one clock type
//#define FOURLANGUAGECLOCK
#define NL144CLOCK              // Dutch display for 12 x 12 Front
//#define NL92CLOCK               // Dutch display for one LED behind every character
//#define DE144CLOCK              // German display for 12 x 12 Front
//#define NLM1M2M3M4L114          // NL clock with four extra LEDs for the minutes to light up
//#define NLM1M2M3M4L256          // NL clock with four extra LEDs for the minutes to light up
//#define NLM1M2M3M4L144          // NL clock with four extra LEDs for the minutes to light up 
//--------------------------------------------
// ESP32 Definition of installed modules
// Define the modules installed in the clock by removing the // before the #define
//--------------------------------------------
//#define ONEWIREKEYPAD3x1       // Use a 3x1 keypad with one wire
//#define ONEWIREKEYPAD3x4       // Use a 3x4 keypad with one wire
//--------------------------------------------
// ESP32 Includes defines and initialisations
//--------------------------------------------
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

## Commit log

2024-01-15 PCB V002
    [Nano_ESP32-PCB_V02.fzz]
2024-03-29 V008
    Changes V001: Derived from ESP32C3S3_WordClockV026.ino
    Changes V002:
    Changes V003: Clock and SK6812 LEDstrip working
    Changes V004: Changed the coding pin numbering to Arduino default macro numbering D0, D1, A4 et cetera
    Changes V005: Language #define settings are working. Code cleanup
    Changes V006: Replaced AsyncElegantOTA with newer ElegantOTA
    Changes V007: WPS functionality added (not working yet (see line 2339)
    void SetStatusLED from int to bool. Removed Colors.h
    Changes V008: Code clean up. Minute and second colour of HET IS WAS repaired in NL144CLOCK. Defines of NL144CLOCK reordered
2024-04-03 V009
    Changes V009: Rewritten IS WAS changing every second in single lan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
2024-04-05 V010 Minutes display in the last 4 LEDs
    Changes V009: Rewritten IS WAS changing every second in single language clock
    Corrected SetRTCtime() struct timeval now = { .tv_sec = t , .tv_usec = t}; --> struct timeval now = { .tv_sec = t , .tv_usec = 0};
    Changes V010: Added four LEDs to strip for minute 1, 2, 3 and 4
    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
2024-05-04 V014
    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
2024-05-30 V025 Compiles with board ESP32 V3.0.0
    Changes V016: Added RTC <-- stopped. some changed added to V017
    Changes V017: Added DS3231 source. Added again the defines for NL144 word clock Source Derived from Klok Ulirich Vertessen ESP32Arduino_WordClockV014U002.ino
    Changes V018: Added DS3231 code from Character_Colour_Clock_V089.ino. DS3231 Get proper time
    Changes V019: Added DS3231 functionality. ie that the clock get its time from the Ds3231 Module if no NTP or WIFI
    Changes V020: Removed CR LF from the Inputstring
    Changes V021: Clean up code
    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
2024-06-20 V032
    Changes V026: Removed #ifdef MOD_DS3231. Updated detection and software around DS3231. RTClib.h still in use
    All three clock types work.
    Changes V027: Is V026 with WS2812 and SK6812 as defines. Was used for test
    Changes V028: Bug StatusLEDs On Off corrected. StartLEDs optimized
    Changes V029: Removed SetSecondColour() from DisplayTime() bij NL144 clock). Ulrich's word plate face corrected
    Changes V030: Ulrichs clock
    Changes V031: Added length control in menu options S, U and V
    Changes V032: Added void Demomode(void) with optien M in the menu. moved Selftest to #-entryin the menu. Updated web page
2024-07-03 V034
    Changes V032: Added void Demomode(void) with option M in the menu. moved Selftest to #-entry in the menu. Updated web page
    Changes V033: Using all available LEDs on board and PCB.
    Changes V034: Working version
    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
2024-08-20 V038
    Changes V035: Correct clock went off at 00:00 for one minute if( (timeinfo.tm_hour == Mem.TurnOffLEDsAtHH) && (Mem.TurnOffLEDsAtHH != Mem.TurnOnLEDsAtHH))
    Changes V036: Send_P() -> Send(). Leds on? --> Update display in menu óption 'O en EveryHourUpdate(). Ulrich's clocks >18 --> >19 in SayHour().
    Added two clock faces #define NLM1M2M3M4L94 // NL clock with four extra LEDs for the minutes to light up for Ulrich
    and #define NLM1M2M3M4L256 // NL clock with four extra LEDs for the minutes to light up for Ulrich
    Changes V037: Selftest runs once. Added <meta name="google" con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
2024-10-04 V044
    Changes V037: Selftest runs once. Added <meta name="google" content="notranslate" /> in Wedpage.h. Added menu items Selftest RTC
    Changes V038: Added Rotary and One-wire support. Copied from ESP32WordClockUltimatePCB_V015
    Changes V039: Removed unneccesary command WiFi.mode(WIFI_STA); Changed PCB and ESP32 LEDs to analog control of the intensity
    Changes V040: Menu changed!!
    Changes V041:
    Changes V042: WIFI not working. EdSoft_SK6812 compiles with ESP32 V3.0.4, EdSoftLED compiles with ESP32 V3.0.4 .
    Changes V043: WIFI working EdSoftLED compiles with ESP32 V3.0.5. All working.
    Changes V044: Added ESP32 core 2.0.17 and 3.0.5 functionality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
2024-10-09 V045
    Changes V044: Added ESP32 core 2.0.17 and 3.0.5 functionality to compile both versions
    Changes V045: CCC in menu to turn on/off BLE. Rotary working again. Added void InitRotaryMod(void)
    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
2024-10-21 V047
    Changes V046: Cleanup code. Code synced with ESP32WordClockUltimatePCB_V025
    Changes V047: Updated menu and webpage
    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
2024-10-26 V050
    Changes V048: Removed define NLM1M2M3M4L256 Ulrich's clock design. Scan network added.
    Changes V049: Rotary usage can be turned on and off in software with menu
    Changes V050: Only first 10 LEDs light up at startup instead of whole LED-string
    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
2024-10-27 V052
    Changes V050: Only f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
2024-11-16 V055
    ...
    Changes V051: Moved In Setup() InitStorage() just after serial started. Setting were read too late
    Changes V052: Violet startup Progress LEDs added
    Changes V053: Minors
    Changes V053: BLE delay(40) -> 10
    Changes V055: Fine tuned WIFIwasConnected. Minor changes
    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
2024-11-18 V056
    Identical common routines ESP32ArduinoFibonacci_V003 / ESP32WordClockUltimatePCB_V028 / ESP32WordClockV055
    Changes V056: MDNS.begin(BLEbroadcastName). Added </style> in line 22 of webpage.h. Option Q3 and Q4 were reversed and corrected
    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
2024-11-22 V056
    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
2024-12-18 V058
    Changes V057: New design NLM1M2M3M4L94 --> NLM1M2M3M4L114
    Changes V058: Removed WhiteColour and --> white. void Laatzien(int Delaymsec). Last used Color in digital display. WIFI custom name in router
    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
2024-12-23 V060: NimBLE version 1.4.3 -> 2.1.2
    Changes V060: NimBLE version 1.4.3 -> 2.1.2 upgrade:
    void onConnect(BLEServer* pServer) {deviceConnected = true; };
    void onDisconnect(BLEServer* pServer) {deviceConnected = false;}
    void onWrite(BLECharacteristic *pCharacteristic)
    To:
    void onConnect(NimBLEServer* pServer, NimBLEConnInfo& connInfo) override {deviceConnected = true;Serial.println("Connected" ); };
    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
2024-12-30 V061
    Changes V059: Added KEYPAD3x1
    Changes V061: Added NLM1M2M3M4L256. Added DS3231 OnOff in menu.
    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
    [ESP32Arduino_WordClockV061.ino]
2025-01-07 V062
    Changes V062: Selftest(msec). NTP library https://github.com/gmag11/ESPNtpClient crashes with core 3.1.0
    R reset does not erase SSID and PWD but command RRR does erase SSID and PWD
    Removes extra CR, LF etc in ReworkInputString
    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
    [ESP32Arduino_WordClockV062.ino]
2025-01-11 V066
    R reset does not erase SSID, PWD and BLEstation but command RRR does erase SSID, PWD and BLEstation
    Changes V063: Removed WiFiGotIP() and to_upper()
    Changes V064: Added WIFI router credentials login page
    Changes V065: Added Dynamic menu web page. Removed //sptext[0]=0 from tekstprint() .
    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
    [ESP32Arduino_WordClockV066.ino]
2025-01-12 V067
    Changes V066: Cleaning code
    Changes V067:
    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
    [ESP32Arduino_WordClockV066.ino, ESP32Arduino_WordClockV067.ino]
2025-01-13 V068
    Changes V067: Stable
    Changes V068: Fancier web page. Documentation updated. RRR en RRRRR option for reset
    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
    [ESP32Arduino_WordClockV062.ino, ESP32Arduino_WordClockV067.ino, ESP32Arduino_WordClockV068.ino]
2025-01-25 V070
    Changes V069: Added Mem.WIFIcredentials to test if the SSID/PWD were set in AP-mode but were wrong.
    After ESP32 restart the StartWordclock WIFI station will be restarted.
    Wire.begin(); // Keep Wire.begin close to the first I2C start to avoid WireTimeout()
    Changes V070: Added M1M2M3M4 in NL144. Added Option Q9 HET IS WAS on or Off
    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
    [ESP32Arduino_WordClockV068.ino, ESP32Arduino_WordClockV069.ino, ESP32Arduino_WordClockV070.ino]
2025-01-29 Smaal PCB
    [Nano_ESP32-PCB_Smal-V02.fzz, Nano_ESP32-PCB_Smal-V03.fzz]
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2025-04-25 V083
    Changes V072: German lay-out for single language clock
    Changes V073: Turned off WIFIevents
    Changes V074: ESP32 V3.2.0 and ADAfruit Neopixel 1.12.5 works.
    Changes V075: Added WPS (Option Z in menu) and added "remove WIFI Eventhandler" to stop the WIFI events WiFi.removeEvent(wifiEventHandler);
    Changes V076: Added Fire
    Changes V077: Own OTA added. Removed <ElegantOTA.h>
    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
2025-05-02 V089
    Changes V081: Added 92 LEDs NL design. Minor changes in the menu.
    Changes V082: Date-time in header HTML-page
    Changes V083: Mem.PreExtraLEDs
    Changes V084: Removed Mem.PreExtraLEDs. Repaired RotaryEncoder. Must use GPIO ports and rewrote rotary coding.
    Changes V085: Minor changes
    Changes V086: Semaphore test - failed
    Changes V087: Semaphore test - failed
    Changes V088: Use of rotary and DS3231 usage optimized in menu. NTP off when DS3231 and rotary on.
    Changes V089: In webpage last input removed from url
    [ESP32Arduino_WordClockV089.ino]
2025-05-18 V096
    Changes V080: cleanup
    Changes V084: Removed Mem.PreExtraLEDs. Repaired RotaryEncoder. Must use GPIO ports for encoder library and rewrote rotary coding.
    Changes V090: Added LEDstrip update semaphore mutex
    Changes V091: Replaced AsyncWebserver en AsyncTCP with standard ESP32 Webserver l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
    [ESP32Arduino_WordClockV075.ino, ESP32Arduino_WordClockV083.ino, ESP32Arduino_WordClockV089.ino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]
2025-05-19 V097
    Changes V091: Replaced AsyncWebserver en AsyncTCP with standard ESP32 Webserver library. This app does not need Async.
    (NB loop counts drops from 210000 to 1000 loops/sec)
    Changes V092: Compiles with ESP32 core 3.2.0 and Adafruit NeoPixel at version 1.13.0. Removed EdSoftLED.h
    Changes V093: Added Small menu
    Changes V094: Replaced NIMBLE with ESP32 BLE
    Changes V095: Cleanup code. New function LEDstartup
    Changes V096: Removed ESP32 BLE. Caused restarts in ESP32 3.2.0. NimBLE works fine and probably better.
    Changes V097: Webpage remembers and also shows last small or long menu display
    [ESP32Arduino_WordClockV097.ino]
2025-06-21 V100
    Changes V099: // sntp_set_time_sync_notification_cb(NTPnotify); Seems unnecessary. EDSOFT bij 256 LED-klok
    Changes V100: Disconnect for a day and try again to connect WIFI. Filename without Arduino in it
2025-07-25 V108
    Changes V099: EDSOFT bij 256 LED-klok. Removed: sntp_set_time_sync_notification_cb(NTPnotify); Seems unnecessary.
    Changes V100: Disconnect for a day and try again to connect WIFI. Added NLM1M2M3M4L161 design. Filename changed: without Arduino in it
    Changes V101: IS did not recolour per second -> repaired. HTML-Menu appears on time after upload. Added HOURLYHETISWAS with Q7.
    Changes V102: Corrected that every second the time was printed
    Changes V103: M1M2M3M4 clock did not respond to HET IS WAS colouring. Time printing every minute had no linefeed
    Changes V104: If length BLEbroadcastName < 4 fill in the name WordClock. If BLE connection inactive for 15 minutes -> disconnect. Focus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
    [ESP32Arduino_WordClockV098.ino, ESP32_WordClockV100.ino, ESP32_WordClockV108.ino]
2025-07-25 Small PCB
    [Nano_ESP32-PCB_Smal-V03.fzz]
2025-10-12 V115
    Changes V113: In Ulrich design Klok No47 --> Shirley Janssen
    Changes V114:
    Changes V115: Time functions updated. You can compile now By Arduino pin (default)
2025-10-15 V116
    Changes V114: is V113
    Changes V116: Removed redundant code
    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
2025-10-31 V120
    Changes V117: Added remote control.
    Changes V118: OTA more stable. void SetStatusLED() changed to turn of LED completely also in ESP32 core 3
    Changes V119: IR-Remote works. Default Time-zone is entered when ResetCredentials(). IR-remote Power ON/OFF turns ON/OFF clock display
    Changes V120: Mem.IRremote -> Mem.UseRotary H03. H001 and H002 -> H01 and H02. in wtekstAppend() if(Mem.MCUrestarted == 0) Tekstprint(sptext);
    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
    [ESP32_WordClockV120.ino]
2025-11-01 V122
    Changes V121: Optimized IR-remote. Use Power button to use IR-remote input for 2 minutes
    Changes V122: Optimized SetDS3231T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
    [ESP32_WordClockV120.ino]
2025-11-19 V131
    Changes V122: Optimized SetDS3231Time() if(DS3231Installed) SetDS3231Time(); Removed stray input from IRremote and added ONOFF
    Changes V123: For colour input, option F in menu, decimal input 0-9 is possible. F0900 = 0x00FF0000 = red
    Changes V124: Failed to Improved WIFI reconnection after power failure
    Changes V125: Improved WIFI reconnection after power failure. Removed in EveryMinuteUpdate(void) CheckRestoreWIFIconnectivity(); Not neccesarry. Usin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
2025-11-22 V132
    Changes V129: Using Neopixel. Optimized code so option Y LEDtest runs again from the web page if (inputMessage.equalsIgnoreCase("Y") ) OptionYRainbow = true; etc.
    Changes V130: Removed old coding and use NEOPIXEL and use ESPAsyncWebServer. 203222 l/s again instead of 140000
    Changes V131: Added H04 tiny IR-remote
    Changes V132: Cleanup code
2025-11-24 Added user manual V132
    An user manual in Dutch and English can be found in this repository [here](https://github.com/ednieuw/Arduino-ESP32-Nano-Wordclock/tree/main/Manual-Instructions)
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2025-12-09 V146 ringbuffer log file
    Changes V138: Solve restart ESP32 sprintf --> snprintf
    Changes V139: Logviewer -> 500 lines
    Changes V140: Changed wifi case WL_CONNECTED:
    Changes V141: Ringbuffer with String and Free heap is working OK
    Changes V142: Ringbuffer to char**
    Changes V143: Ringbuffer to char** optimized
    Changes V144: Keeps all logs in PSRAM Limits /tekstprint to 500 lines for safe browser display Allows /tekstdownload for full log retrieval
    Changes V145: no log file anymore --> solved while (!Serial && ( (millis()-Tick) < 500)) { delay(50); }
    Changes V146: Works OK
    [ClockFaces.h]
2025-12-11 V146 added Updated readme
    Changes V133: Added in CheckRestoreWIFIconnectivity() Failsafe NoConnectionCounter that restart after 30 minutes no IP when WIFI is On
    Changes V134: Added in CheckRestoreWIFIconnectivity() Loopcounter<10 and network available. --> Will reboot. Minor typos and cleanups
    Changes V135: Optimized used of CheckRestoreWIFIconnectivity() and check every hour instead of every mniute
    Changes V136: Added Log viewer webpage url/log
    Changes V137: No use
    Changes V138: Solve restart ESP32 sprintf -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
2025-12-23 V150
    Changes V147: Line numbers removed and code cleaning in Logviewer.h
    Changes V148: Replace snprintf(sptext, sizeof(sptext) with Tekstprintf. Added Option Y { and G from web page menu not possible
    Changes V149: Flashing warning text in web page menu. Optimized bool GetNTPtime(bool printit) . Mem.TimeMinute used to turn off time printing e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
    [ClockFaces.h]
2025-12-24 V150
    Changes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
    [ClockFaces.h]
2025-12-29 V151
    Changes V149: Flashing warning text Option Y or G not possible in web page menu. Optimized bool GetNTPtime(bool printit) . Mem.TimeMinute used to turn off time printing every minute
    Major cleanup and bugfixes
    Changes V150: Stable version
    Changes V151: functie FILENAAM \ ook voor MacOS/Linux /. Mem.TimeMinute = 1; // Print time per minute (1) or hour (2)
    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
    [ClockFaces.h]
2026-01-02 V160 Stable
    Changes V152: error in 4-L clock solved. Optimized print time /min /hr
    Changes V153: Larger ringbuffer
    Changes V154: Optimizing K0 K1 K2
    Changes V155: No menu print to logging when SWversion is printed to Webpage. Added DoNotLog flag
    Changes V156: Optimize use of DoNotLog flag. const char* PrintRTCTime() --> Tekstprintln(PrintRTCTime()); WTekstprint(PrintRTCTime(), "<!--", " -->");
    Changes V157: testing
    Changes V158: K0 not updating LEDs.-->fixed. added in Everyminute()
    Changes V159: Double printing of menu in Loggi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
    [partitions.csv]
2026-01-03 cosmetic V160
    Changes V159: Double printing of menu in Logging solved.Option K2 debugged
    Changes V160: Stable
    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
2026-02-11 V180
    Changes V174: Time sender working
    Changes V175: ToDo: Make time sender optional with Mem.TimeSender. SendMessageBLE(string -> const char* msg)
    Changes V176: deviceConnected -> BLEConnected TSConnected
    Changes V178: Ringbuffer
    Changes V179: Ringbuffer
    Changes V180: Ringbuffer repaired. BLE time Sender optimized.
2026-02-22 V184
    Changes V181: Testing. Cleanup code
    Changes V182: Make use of timesender selectable
    Changes V183: Stable version
    Changes V184: Print of long logbuffer in chunks to avoid crash as txt download file
    [partitions.csv]
2026-02-25 V185
    Changes V185: Changed name of TimeSender -> TimeReceiver.
    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
    [partitions.csv]
2026-03-04 V188
    Changes V186: Simplified: "attachment; filename=\"%s-log.txt\"", Mem.BLEbroadcastName);
    Changes V187: Added CheckWIFIcommand() to avoid WIFI crashes when a command take several seconds to end, like LEDtest()
    Changes V188: Stable
    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
    [partitions.csv]
2026-03-24 V195
    Changes V189: Added DisconnectBLE() as function. When @ in webpage inputfield cleared from sticking @.
    Changes V190: Variables etc. renamed from Timesender -> Timereceiver in Timereceiver functions
    Changes V191: In timereceiver Connected to: Mem.BLEbroadcastName and yellow status LED when connected
    Changes V192: Repair 4-language clock display. Renamed Playlights() --> LEDtest().
    Q8=RAINBOW resetting ESP32 solved to -> update per minute. After 5 MCU restart in an hout Reset all settings to factory default
    Changes V193: Refined Mem.MCUrestarted. No ResetCredential. Set counter to 0 between 1 and 2 hours
    Changes V194: Refined logging (NTP update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
    [partitions.csv]
2026-03-25 V195
    Comparable with ESP32Arduino_CommV022.ino. Corrected nasty bug -> Mem.NVRAMmem[lasthour] = NoofLDRreadshour ? (byte)(SumLDRreadshour / NoofLDRreadshour) : 0;
    [partitions.csv]
2026-03-31 V196
    Changes V195: Cleanup code. Comparable with ESP32Arduino_CommV022.ino. Corrected bug -> Mem.NVRAMmem[lasthour] = NoofLDRreadshour ? (byte)(SumLDRreadshour / NoofLDRreadshour) : 0;
    Changes V196: To avoid translation lang="en" added -> <html lang="en"><head>. Changes in void PrintMem(void) .
    [ClockFaces.h, ESP32_WordClockV196.ino]
2026-04-08 DXF wordplates V197
    [KLok25cm.tekst.dxf, KLok50cm.gaten+tekst.dxf, Klok.25cm.12x12.gat.patroon.dxf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]
2026-04-18 V199Q
    Changes V199: All Rework in Webpage to CheckWIFIcommand(). 199a Clock logic in ClockLogic.h. Corrected double Menu i and ii on webpage when BLE open.
    Updated HTML and logging behaviour. Added option V background, Changed LDR reading when background is on, input decimal or hexadecimal, KURZ, EXACT etc bij Ulrich 4-talen weg
    Changes V199j: Removed short LDR reading under X LDR_LED. NoTextInLeds in EveryHourUpdate -> end of function
    Changes V199L: lastminute = 99; -> end ReworkInputString
    Changes V199P: Cleanup code
    [ClockFaces.h, ESP32_WordClockV199Q.ino]
2026-05-13 V204
    Changes V200: OTA logic improved
    Changes V201: LED near LDR on/off
    Changes V202: HET IS WAS can also OFF in FOURLANGUAGECLOCK and VIERTALENKLOK
    Changes V203: Added CLOCK_VARIANT. renamed Mem.UseRotary -> Mem.TimeInput
    Changes V204: Resetbutton added
    [ClockFaces.h, ESP32_WordClockV202.ino, ESP32_WordClockV203.ino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]
2026-05-16 V206
    Changes V205: BLE bugs solved. Android did not see the broadcastname, uses now pServer->disconnect(). Delay 30ms when not in fast mode.
    Changes V206: When time is entered WIFI/NTP is Off. When DS3231 is turned Off with J and no valid WIFI credentials DS3231 stays On
    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
    [ClockFaces.h, ESP32_WordClockV204.ino, ESP32_WordClockV206.ino]
2026-05-26 V210
    Removed EdsoftLED. Has problems with core 3.3.8??
    [partitions.csv]
2026-05-27 V211
    Changes V209: Removed Reset button. --> Press 9 times on rotary. Added NLM1M2M3M4L294
    Changes V210: Stable version
    Changes V211: Optimised BuildHTML and Tekstprintlnf & Tekstprintf. CheckMCURestartCounter ->10 min
    [partitions.csv]
2026-06-07 V222 use EDSoftLEd V1.10.0
    Changes V212: RST_PIN in Mem.ResetPin
    Changes V213: Optimised resetpin. RST_PIN in Mem.ResetPin. Comparable with ESP#@Arduino_CommV033
    Changes V214: Added Mem2 and Colourpicket HTML --> not working yet
    Changes V215: Optimised Colourpicket HTML
    Changes V216: Optimised Colourpicket HTML. Viertalenklok is working OK
    Changes V217: Made print in ReworkInputString consistant. added background in Colourpicket HTML
    Changes V218: Optimised Colourpicket HTML for VIERTALENKLOK
    Changes V219: Optimised Colourpicket HTML for Single language cl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
    [partitions.csv]
2026-06-08 V223
    Changes V219: Optimised Colourpicket HTML for Single language clock
    Changes V220: Cla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
    [partitions.csv]
2026-06-20 V223
    Changes V223: Added const uint32_t LEDNEARLDR in clockfaces.h to control LDR reading
    Changes V224: Added colourpicker.h to choose colours
    Changes V225: Corrected bugs, black after reset, DimmedLeds with SK6812 white LED.
    Added French, English single language designes and corrected LED position in German design
    [ClockFaces.h, ESP32_WordClockV224.ino]
2026-06-20 V225
    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
    [ClockFaces.h, ESP32_WordClockV225.ino]
2026-06-24 v226
    Changes V226: Renamed Laatzien to SelftestFlash with instant-abort behaviour,
    added web settings menu (MenuPage.h) with sliders, 24h clock picker, and colour picker link.
    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
    [ClockFaces.h]
2026-06-26 V227
    Changes V227: Added auto-scrolling log windows to main/menu pages, made the LED test interruptible,
    added rocket/menu icons, and shrank the menu buttons and brightness section.
    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
    [ClockFaces.h]
2026-06-27 V228
    Changes V228: check all clock definitions and corrected error. Added ClearTestStrip()
    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
    [ClockFaces.h]
2026-06-30 V230
    Changes V229: New Name WordFiboClock. Combined WordclockV228 and FibonacciV011. The HC-12 / BLE TimeSender is a new feature (H06).
    Changes V230: Added Fibo colourpicker. Combined headers. Error allert when Neopixel wrong pin numbering .
    [ClockFaces.h, Fibonacci.h, WordClock.h]
2026-07-14 V233
    Changes V230: Added Fibo colourpicker. Combined headers. Error with Neopixel wrong pinnumbering.
    Changes V231: Updated comments.
    Changes V232: Added NOCLOCK. Clockfaces.h,WordClock.h and Fibonacci.h can be deleted with this option
    Changes V233: Corrected digital clock
    [ClockFaces.h, Fibonacci.h]
2026-08-01 V237
    Changes V235: Live colour in web menu. log screen wider in main menu
    Changes V236: Added: MQTT CheckMQTT() non-blocking — only runs when Mem.WIFIcredentials == SET_AND_OK and WiFi is actually connected;
    Changes V237: Added: MQTT - HA buttons Y, ~, O, P, @ and Q1-9, Two test sensors: CPU Temperature and LDR Reading, published once/minute.
    Added: analogWriteResolution(LED_RED, 9); analogWriteFrequency(LED_RED, 5000); // (same for LED_GREEN, LED_BLUE)
    Added: X in colour when Display is off in HTML menu
    Added: void InitStatusLEDs(void)
2026-08-01 V238
    Changes V238: Make MQTT selectable with Mem.MQTT. Fixed rotary debouncing when no rotary connected
    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
    [ClockFaces.h, Fibonacci.h, WordClock.h]
2026-08-02 V239
    Changes V239: Default HTML menu page does not zoom in anymore on inputfiled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
    [ClockFaces.h, Fibonacci.h, WordClock.h]
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2026-09-17 V244 Upload bug repaired
    [ClockFaces.h, Fibonacci.h, WordClock.h]
2026-09-29 V245
    Changes V242: Added MQTT minbrightness and slopebrightness
    Changes V243: Added Low Power MODEMSLEEP. cut power from 0.25A to 0.20A. Will not use it and V244 will be continued from V242
    Changes V244: Added MQTT sensor for OutPhotocell (LED brightness 0-255 derived from the LDR). Combined all periodic MQTT publishes (CPU temp, LDR, OutPhotocell, display choice, states) into one PublishMQTTStates(),
    removing duplicate PublishDisplayChoiceState() call on reconnect.
    Fixed OTA upload: a double-click/double-submit on the /update page could fire two concurrent uploads that interleaved writes into Update and corrupted the image (clock never restarted). Client-sid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
    [ClockFaces.h, Fibonacci.h, WordClock.h]
2026-09-29 V235
    Changes V234: Added the new RotPressOne/Two/Three entries in all three variant sections.
    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
    [ClockFaces.h, Fibonacci.h, WordClock.h]
